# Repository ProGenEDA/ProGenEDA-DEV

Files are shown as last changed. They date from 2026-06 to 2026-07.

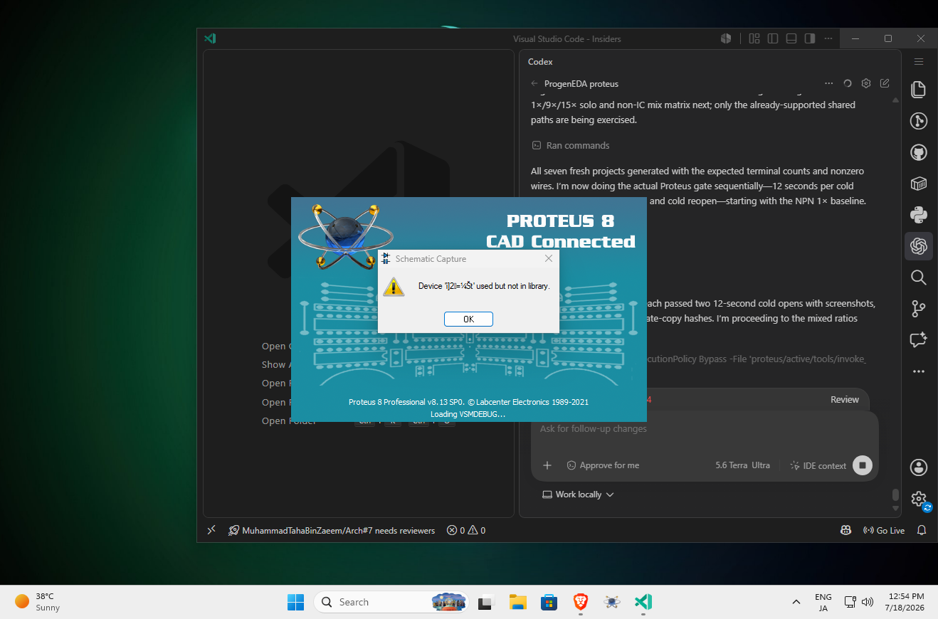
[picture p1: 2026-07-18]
proteus/experiments/runs/2026-07-18_npn_terminal_promotion_matrix/M02_NPN_NATIVE_ASYMMETRIC/screenshots/M02_NPN_NATIVE_ASYMMETRIC_GATE_cold_open_1.png

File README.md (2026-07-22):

# ProGenEDA

ProGenEDA is a development repository for deterministic, donor-aware EDA
generation. A backend receives one canonical circuit JSON document, resolves
only supported native records, produces an editable project, and retains
machine-readable validation evidence beside the result.

This repository contains independent backends for Proteus, KiCad, EasyEDA Pro,
and LTspice. They share the canonical circuit intent but do not depend on one
another at runtime.

## Backends

| Backend | Native output | Current entry point | Scope summary |
| --- | --- | --- | --- |
| Proteus | `.pdsprj` | [`proteus/active/`](proteus/active/) | Donor-backed placement, bounded terminal attachment, value editing, and local loader evidence. |
| KiCad | `.kicad_pro`, `.kicad_sch`, optional `.kicad_pcb` | [`kicad/`](kicad/) | Canonical JSON repair, source-backed schematic generation, combination routing, validation, and bounded two-layer PCB output. |
| EasyEDA Pro | `.eprj` | [`Easyeda/`](Easyeda/) | Native SQLite project generation using audited source records, compact schematic routing, and bounded PCB generation. |
| Altium | `.PrjPcb` + source-backed `.SchDoc`, packaged as ZIP | [`Altium/`](Altium/) | Full direct native schematic pipeline: repair, values, source selection, placement, arrangement, wiring/terminals, native emission, and saved-file validation. Direct PCB output is not qualified yet. |
| LTspice | `.asc` | [`ltspice/`](ltspice/) | Donor-native stock-symbol placement, physical-wire routing, and validated ASC emission. |

Each backend documents its supported catalogue, input restrictions, validation
contract, and release evidence in its own README. A backend must reject or
withhold unsupported work rather than substitute an approximate native record.

## Shared Generation Model

```text
Canonical circuit JSON
  -> normalize and validate input
  -> resolve supported components and pins
  -> place and arrange components
  -> route wires, terminals, or both according to backend policy
  -> edit approved values and references
  -> validate structure, pins, nets, geometry, and backend-specific rules
  -> emit native project plus internal audit artifacts
```

The canonical input remains the source of truth. Generation stages retain their
own reports and accepted or rejected layout/routing variants so a released
project can be traced back to the exact request and decisions that produced it.

## Getting Started

Run backend commands from the repository root. The portable executables are
the normal distribution form; direct source commands use the same pipeline.

### KiCad

```bash
unzip kicad/release/progen-kicad-portable-2026_07_17_kq26_clearance_v1.zip
./progen-kicad-portable/progen-kicad run INPUT.json \
  --output-root /tmp/progen-kicad-runs \
  --routing-mode combination
```

For PCB-only output from the same canonical input:

```bash
./progen-kicad-portable/progen-kicad run-pcb INPUT.json \
  --output-root /tmp/progen-kicad-pcb-runs \
  --routing-mode combination
```

Direct source entry point:

```bash
PYTHONPATH=. python -m kicad.pipeline.progen_kicad_executable run INPUT.json \
  --output-root /tmp/progen-kicad-runs \
  --routing-mode combination
```

See [`kicad/README.md`](kicad/README.md) for the supported input and
[`kicad/pcb/README.md`](kicad/pcb/README.md) for the physical-board boundary.

### EasyEDA Pro

```bash
Easyeda/dist/progen-easyeda run INPUT.json \
  --output-root /tmp/progen-easyeda-runs \
  --routing-mode combination \
  --events ndjson
```

Direct source entry point:

```bash
PYTHONPATH=. python -m Easyeda.executable run INPUT.json \
  --output-root /tmp/progen-easyeda-runs \
  --routing-mode combination \
  --events ndjson
```

See [`Easyeda/README.md`](Easyeda/README.md) and
[`Easyeda/SUPPORTED_COMPONENTS.md`](Easyeda/SUPPORTED_COMPONENTS.md).

### LTspice

```bash
PYTHONPATH=. python -m ltspice INPUT.json \
  --outdir /tmp/progen-ltspice-output \
  --label generated-circuit \
  --engine donor_native
```

The result is a native `.asc` file. The generator and deterministic validators
do not require LTspice to be installed; opening or simulating the output does.
See [`ltspice/README.md`](ltspice/README.md) for the donor-observed support
boundary and packaging instructions.

### Proteus

```powershell
.\proteus\active\release\ProgenProteus.exe generate `
  .\proteus\active\examples\progen_proteus_r_c_value_edit.json `
  --output .\out\r_c_terminalized.pdsprj
```

Direct source entry point:

```powershell
$env:PYTHONPATH = "proteus/active/src"
python -m proteusgen.proteus_cli generate `
  proteus/active/examples/progen_proteus_r_c_value_edit.json `
  --output out/r_c_terminalized.pdsprj
```

See [`proteus/active/README.md`](proteus/active/README.md) for the donor
policy, current terminal boundary, and native loader gate.

## Validation Principles

Every backend owns a deterministic validation path. Depending on the backend,
that includes component/reference checks, pin existence, expected-net
comparison, geometry and clearance checks, source-record provenance, native
file parsing, and optional application/CLI acceptance evidence.

Native application checks are additional evidence, not a substitute for the
backend's own structural validation. Conversely, static validation does not
promote a project that has not satisfied the backend's documented release
contract.

## Qualification Evidence

- KiCad: [`kicad/qualification/README.md`](kicad/qualification/README.md)
  documents the 400-circuit corpus and the bounded PCB results.
- EasyEDA Pro: [`Easyeda/qualification/README.md`](Easyeda/qualification/README.md)
  documents the 300-circuit full-pin corpus.
- LTspice: [`ltspice/docs/COMMON_CIRCUIT_CORPUS.md`](ltspice/docs/COMMON_CIRCUIT_CORPUS.md)
  describes the named native-circuit corpus.
- Proteus: [`proteus/active/examples/proteus_200_circuits/README.md`](proteus/active/examples/proteus_200_circuits/README.md)
  documents the executable-oriented corpus and evidence boundary.

## Repository Map

```text
proteus/    native Proteus backend, active package, donor evidence, experiments
kicad/      KiCad schematic and PCB generator, source pack, qualification, release
Easyeda/    independent EasyEDA Pro backend, audited donor bundle, qualification
Altium/     direct native Altium schematic generator, source pack, validators, research bridge
ltspice/    donor-native LTspice backend, catalogues, pipeline, packaging, tests
pspice/     PSpice/OrCAD research and early generator material
showcase/   curated generated projects for review
tests/      repository-level regression checks
```

Historical experiment folders are preserved as evidence. New generation runs
should create a new run directory and never overwrite prior outputs.

## Documentation Index

- [`kicad/FINALIZATION_STATUS.md`](kicad/FINALIZATION_STATUS.md) - KiCad
  status and release boundary.
- [`kicad/pipeline/MAIN_INPUT_JSON_CONTRACT.md`](kicad/pipeline/MAIN_INPUT_JSON_CONTRACT.md)
  - canonical KiCad input contract.
- [`Easyeda/INPUT_JSON.md`](Easyeda/INPUT_JSON.md) - EasyEDA input contract.
- [`Easyeda/ARCHITECTURE.md`](Easyeda/ARCHITECTURE.md) - EasyEDA stage design.
- [`Altium/README.md`](Altium/README.md) - Altium target status and commands.
- [`Altium/PIPELINE.md`](Altium/PIPELINE.md) - Altium stage contracts and immutable run artifacts.
- [`Altium/ARCHITECTURE.md`](Altium/ARCHITECTURE.md) - Altium stage contracts.
- [`Altium/INPUT_JSON.md`](Altium/INPUT_JSON.md) - Altium direct input contract.
- [`ltspice/ARCHITECTURE.md`](ltspice/ARCHITECTURE.md) - LTspice donor-native
  architecture and support evidence.
- [`proteus/active/docs/README.md`](proteus/active/docs/README.md) - Proteus
  operational documentation index.

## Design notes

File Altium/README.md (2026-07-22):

# ProGenEDA Altium Backend

`Altium/` is an independent, direct Altium schematic backend. Its production
path starts with canonical circuit JSON and writes a fresh native ASCII
`.SchDoc`, a `.PrjPcb` descriptor, and a ZIP containing those files. It does
not generate an EasyEDA project and does not invoke a converter during normal
generation.

```text
canonical JSON
  -> input fixer and value editor
  -> audited source selection and component placement
  -> four-candidate route-informed arrangement and coordinate-only beautifier
  -> wire planner and terminal placer
  -> routing validator and independent native wire maker
  -> direct .SchDoc writer and donor-backed .PrjPcb writer
  -> saved-file/package final validation
  -> ZIP project artifact plus private stage archive
```

## Direct Generation

Run from the repository root:

```bash
# Inspect the exact source-backed component catalogue.
PYTHONPATH=. python -m Altium.executable supported-components

# Repair, normalize, and source-validate a canonical circuit JSON file.
PYTHONPATH=. python -m Altium.executable validate-input INPUT.json

# Inspect every explicit pipeline stage and its ownership boundary.
PYTHONPATH=. python -m Altium.executable pipeline-contracts

# Directly generate an Altium project. This never creates an .eprj.
PYTHONPATH=. python -m Altium.executable generate INPUT.json \
  --output-root /tmp/progen-altium-runs --progress-json

# Re-check an emitted schematic and its project ZIP without Altium Designer.
PYTHONPATH=. python -m Altium.executable validate-schematic \
  RUN/project/Schematic/project.SchDoc \
  --expected RUN/internal/expected_physical_contract.json
PYTHONPATH=. python -m Altium.executable validate-package RUN/project.zip
```

Every generation creates a new run directory. It contains the user-facing
project folder and ZIP, plus `internal/` records for the normalized input,
source hashes, value edits, source selection, placement, all arrangement trials,
beautifier output, wire plan, terminal plan, routing validation, PCB decision,
expected physical contract, and saved-file validation report. A separate
private internal ZIP preserves the whole stage history.

The same code is also available as a Python API:

```python
from Altium.direct_generator import generate_direct_project

result = generate_direct_project("circuit.json", output_root="/tmp/progen-altium-runs")
assert result.validation.passed
print(result.project_file)
```

## Current Direct Schematic Scope

The initial catalogue is real-source backed, not hand-drawn. It clones complete
component records and derives pin locations, pin directions, source pin names,
wire records, and net-label records from the locked native seed. Current
families are:

- resistor, capacitor, LED, switch;
- two-pin header and 2x5 header;
- 74HC00, 74HC04, 74HC08, 74HC32, 74HC74; and
- NE555.

See [SUPPORTED_COMPONENTS.md](SUPPORTED_COMPONENTS.md) for the exact aliases,
native library references, and pin boundary. See [INPUT_JSON.md](INPUT_JSON.md)
for the required JSON contract.

The router has three explicit modes:

- `wire`: all requested nets must be physically routed; an unresolved net is a
  hard error.
- `terminal`: every non-`NC_*` net uses source-backed Altium net labels with a
  short physical pin stem.
- `combination`: route physically where clear; only whole unresolved nets fall
  back to source-backed labels. This is the default.

The current direct examples are intentionally small and auditable:

```bash
PYTHONPATH=. python -m Altium.executable generate Altium/examples/direct_rc_filter.json \
  --output-root /tmp/progen-altium-runs
PYTHONPATH=. python -m Altium.executable generate Altium/examples/direct_led_indicator.json \
  --output-root /tmp/progen-altium-runs
PYTHONPATH=. python -m Altium.executable generate Altium/examples/direct_74hc04_breakout.json \
  --output-root /tmp/progen-altium-runs
```

## Validation

The direct validator re-parses the saved `.SchDoc`; it does not accept the
generator's in-memory route plan as proof. It checks:

1. native ASCII header and record count;
2. expected references, values, source library identities, root coordinates,
   complete symbol bounds, and native pin names/directions/positions;
3. dynamic sheet dimensions containing every body, pin, route, and label;
4. component overlap and wire-to-component-body clearance;
5. globally unique wire/label record indexes and orthogonal segments;
6. exact wire-maker/terminal geometry with no duplicate native component or
   pin/property records;
7. physical wire graph connectivity for fully wired nets;
8. native label attachment and logical connectivity for terminalized nets;
9. expected-net separation so a route or label cannot silently short nets; and
10. donor-native `.PrjPcb` sections, document declarations, ZIP inventory, safe
   paths, and exact hash equality with the files that were validated.

`Altium/tests/` contains focused pytest regressions, including deliberate
mutations of values, library references, pin identity, sheet size, routing
indexes, and archive payloads. A repository-local `.venv` may be used when the
host Python does not already provide pytest.

With `--progress-json`, the executable emits one ordered event for every one
of the 22 retained stages, followed by a `complete` event at 100 percent.

## Encoder/Decoder Research Boundary

The installed EasyEDA Chameleon bundle advertises `altium` decoder and encoder
types. `probe-engine` and `research-bridge` retain that capability for format
research only. They are not called by `generate`.

An actual raw-ASCII `.SchDoc` round-trip through that bundle was lossy: the
re-encoded archive preserved wire records but dropped the direct component
records and did not emit a `.PrjPcb`. It is therefore explicitly not an
acceptance gate for this writer. The acceptance hierarchy is the independent
saved-file validator now, followed by an Altium Designer open/render test when
the desktop installation is complete.

## Current Boundary and Next Work

This is direct **schematic** generation. It does not yet emit a direct
`.PcbDoc`, Gerbers, or manufacturing files. The source seed includes component
footprint associations, but direct board construction needs separate
Altium-native board, pad, stackup, rule, and routing donor evidence before it
can be qualified.

Likewise, a static parser is not a desktop-open result. The Altium Designer
download in this environment is incomplete at the time of writing, so desktop
open/render/compile evidence remains a required next gate. Unsupported
families, unqualified PCB output, and unresolved strict-wire routes fail
clearly rather than being approximated.

See [PIPELINE.md](PIPELINE.md), [ARCHITECTURE.md](ARCHITECTURE.md),
[SUPPORTED_COMPONENTS.md](SUPPORTED_COMPONENTS.md), and
[source_pack/README.md](source_pack/README.md) for the implementation and
evidence details.

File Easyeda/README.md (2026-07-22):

# ProGenEDA EasyEDA Pro Backend

This independent backend compiles canonical circuit JSON into one native
EasyEDA Pro `.eprj` SQLite project. It does not import from `kicad/` at
runtime.

The backend is donor-native: symbols, devices, footprints, pads, power
terminals, and net-port payloads are resolved from audited EasyEDA source
records. The portable generator contains only the compact locked record bundle
needed by the supported catalogue. It does not package the EasyEDA desktop
application or its complete library.

## What It Produces

For a supported request, the pipeline emits:

- one editable native `<project-name>.eprj` project;
- a schematic using source-resolved components, wires, terminals, and net
  ports according to the chosen routing mode;
- a bounded two-layer PCB in the same project when all used devices have exact
  footprint/pad mappings and physical validation passes; and
- an internal ZIP containing normalized input, fixer report, placement,
  routing, donor provenance, PCB decisions and variants, and validation
  reports.

The primary user artifact is the `.eprj` project. Internal records are kept for
audit and regeneration rather than mixed into the user-facing project folder.

## Run The Portable Executable

```bash
Easyeda/dist/progen-easyeda run INPUT.json \
  --output-root /tmp/progen-easyeda-runs \
  --routing-mode combination \
  --events ndjson
```

The portable executable is the normal distribution artifact. It can generate
and run deterministic validation without an installed EasyEDA application.

## Run From Source

```bash
PYTHONPATH=. python -m Easyeda.executable run \
  Easyeda/examples/regulated_5v_supply.json \
  --output-root /tmp/progen-easyeda-runs \
  --routing-mode combination
```

An authorized source installation can be supplied with `--source-pack` as a
development-time override.

Useful deterministic commands:

```bash
# Report and repair common input problems without generating a project.
Easyeda/dist/progen-easyeda validate-input circuit.json
Easyeda/dist/progen-easyeda fix-input circuit.json --output fixed.json

# Discover fields exposed by the normal reference/value editor.
Easyeda/dist/progen-easyeda editable circuit.json

# Apply validated JSON edits and emit normalized JSON.
Easyeda/dist/progen-easyeda edit circuit.json edits.json --output edited.json

# Stream completed pipeline stages for a worker or website adapter.
Easyeda/dist/progen-easyeda run circuit.json --output-root runs --events ndjson
```

## Routing And PCB Contract

- The locked catalogue contains 59 logical entries backed by 57 physical donor
  families, plus native `GND` and `VCC` terminal families.
- A schematic request may contain at most 80 component instances.
- `wire`, `terminal`, and `combination` modes are supported; `combination` is
  the default.
- Combination mode uses explicit native terminals for power/ground, selected
  high-fanout nets, and failed wire routes. Strict wire mode fails rather than
  silently terminalizing a net.
- Distinct nets may cross at a point but may not share a positive-length wire
  span. The planner and native validator enforce this readability constraint.
- PCB output is bounded to 32 physical components. `GND` and `VCC` schematic
  terminals do not count as physical PCB components.
- A PCB failure never invalidates an otherwise valid schematic. The project is
  emitted without a board document and the PCB report records the reason.

## Validation And Acceptance

The native validator checks source-record hashes, components, pins, expected
nets, geometry, wire-span overlap, footprint/pad mapping, and board-level
connectivity. Input repair is deterministic: a guessed or completed net is
named `GUESS_*`, terminalized, and reported. A clean canonical input produces
zero guesses and zero repairs.

Static validation is necessary but not desktop acceptance. Release evidence
also opens a disposable copy of each selected project through the installed
EasyEDA Pro file association and confirms that the audited original was not
rewritten. Generated projects carry a native EasyEDA 3.x identity and omit
legacy history/cache rows that trigger conversion failures.

## Evidence And Documentation

- [Input JSON contract](INPUT_JSON.md)
- [Supported components](SUPPORTED_COMPONENTS.md)
- [Architecture](ARCHITECTURE.md)
- [300-circuit qualification](qualification/README.md)
- [Qualification results](qualification/RESULTS_2026_07_17.md)
- [Website handoff](release/newwebsite_easyeda_handoff_2026_07_17/README.md)

The release handoff contains the portable executable, named qualification
inputs, website integration material, installer guidance, and release
evidence. Historical experiments remain in `experiments/` and are not runtime
dependencies.

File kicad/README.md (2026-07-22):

# ProGenEDA KiCad Backend

This is the active source-backed KiCad backend. It compiles canonical circuit
JSON into an editable `.kicad_pro` project with a native `.kicad_sch` and, when
the physical contract is satisfied, a native two-layer `.kicad_pcb`.

The generator is independent from the Proteus binary backend. It resolves
symbols, pins, bodies, footprints, and pads from the bundled KiCad source pack
and retains the evidence needed to validate output without requiring KiCad at
generation time.

## Run The Portable Executable

```bash
unzip release/progen-kicad-portable-2026_07_17_kq26_clearance_v1.zip
./progen-kicad-portable/progen-kicad run INPUT.json \
  --output-root /tmp/progen-kicad-runs \
  --routing-mode combination
```

Create a PCB-only artifact from the same canonical input:

```bash
./progen-kicad-portable/progen-kicad run-pcb INPUT.json \
  --output-root /tmp/progen-kicad-pcb-runs \
  --routing-mode combination
```

Generate retained layout/routing variants:

```bash
./progen-kicad-portable/progen-kicad run-variations INPUT.json \
  --output-root /tmp/progen-kicad-variations \
  --routing-mode combination \
  --variations 3
```

## Run From Source

```bash
PYTHONPATH=. python -m kicad.pipeline.progen_kicad_executable run INPUT.json \
  --output-root /tmp/progen-kicad-runs \
  --routing-mode combination
```

The portable executable wraps this committed source entry point. Direct source
generation and deterministic validation do not require a local KiCad install.

## Generation Contract

```text
Canonical circuit JSON
  -> deterministic input fixer and validator
  -> source-backed component and pin resolution
  -> component placement, arrangement selection, and coordinate beautification
  -> wire planner, terminal placer, or combination policy
  -> native schematic writer and value editor
  -> expected-net, geometry, clearance, and final validation
  -> optional physical-board compiler, router, and validator
  -> native project plus internal audit bundle
```

`combination` is the production default. Local nets are physically wired;
power, high-fanout, and bounded-route fallback nets use explicit KiCad terminal
objects. Strict `wire` mode never hides a routing failure behind labels or
terminals.

The formal input contract is
[`pipeline/MAIN_INPUT_JSON_CONTRACT.md`](pipeline/MAIN_INPUT_JSON_CONTRACT.md).
The deterministic fixer accepts common shape and naming mistakes, reports each
repair, and marks invented connectivity as `GUESS_TERMINAL_*` so it is explicit
and terminalized rather than presented as a verified physical wire.

## Schematic Validation

The generated schematic is checked without the KiCad CLI through the bundled
source-backed parser and catalogue. Validation covers file structure,
components, references, values, pins, expected nets, actual wire/junction/pin
connectivity, component-body clearance, label/terminal placement, and output
artifacts.

When KiCad is installed, `kicad-cli` netlist export and ERC are supplemental
acceptance checks. They do not replace exact expected-net comparison, because
ERC cannot know whether a logical signal reached the intended pin.

## Bounded PCB Output

PCB generation consumes the same fixed canonical JSON and resolved schematic
pin contract; it does not accept a separate PCB input. A board is emitted only
when every used logical pin maps to a real source footprint pad and the bounded
two-layer placement/routing/physical validator succeeds.

The common-400 qualification accepted 311 boards and explicitly withheld 89
schematic projects whose footprint, complexity, or routing contract was not
satisfied. Withholding is intentional: a valid schematic is still delivered,
but an unaudited PCB is never claimed as usable.

See [`pcb/README.md`](pcb/README.md) for footprint provenance, pad mapping,
route variants, DRC evidence, and the exact physical acceptance rules.

## Qualification And Variants

The qualification corpus contains 400 ordinary canonical inputs across 40
electrical archetypes and 10 named profiles. It exercises the real fixer,
placer, arrangement logic, router, terminal policy, value editor, validators,
packager, and bounded PCB stage without guided coordinates.

- [Qualification corpus and runner](qualification/README.md)
- [Qualification results](qualification/RESULTS_2026_07_17.md)
- [Finalization status](FINALIZATION_STATUS.md)
- [Supported component catalogue](pipeline/SUPPORTED_COMPONENTS.md)

Each run keeps normalized input, generated stage JSON, accepted and rejected
variants, reports, and output manifests in a new run directory. Prior evidence
is immutable and must not be overwritten.

## Local KiCad Tools

The optional local KiCad 10.0.4 helper and CLI wrapper are documented in
[`tools/README.md`](tools/README.md). They are for opening projects, rendering
review copies, and running external KiCad acceptance checks; they are not a
runtime dependency of the generator.

## Repository Map

```text
pipeline/        canonical JSON, placement, routing, validation, packaging
pcb/             physical compiler, footprint placement, router, PCB parser
qualification/   locked corpus, runner, and release results
source_pack/     source records used by no-installation validation
release/         portable executable and website handoff artifacts
examples/        immutable generated evidence runs
experiment_records/ historical placement and routing research
```

Historical files remain available for audit, but current work should begin
with the executable, input contract, support catalogue, and qualification
records linked above.

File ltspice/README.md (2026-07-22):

# ProGenEDA LTspice Backend

This directory is being rebuilt to generate real LTspice ASC schematics: files
that use the installed LTspice stock symbols and open as though they had been
drawn in LTspice itself. The design authority is the donor corpus in
`/home/zaruka/Documents/Ltspice/Donor`, not a generic SPICE abstraction.

The user-facing input remains the shared canonical `progen-kicad-circuit-ir/v1`
circuit JSON used by KiCad. LTspice does not get a second user-authored input
format. The native backend resolves that JSON to the donor-backed catalogue,
places native symbols, edits only approved native attributes, routes every
electrical net with physical wires, then emits the ASC file.

## Current executable scope — 2026-07-16

The canonical repository folder is **`ltspice/`** (lowercase by design). It is
already present on `main`; a second `Ltspice/` case-variant directory would be
an error-prone duplicate on Linux and is intentionally not created.

The current donor-native executable accepts this deliberately bounded,
evidence-backed scope:

- Native stock families: ground, resistor, capacitor, inductor, voltage
  source, current source, and `Misc\\signal` source.
- Total logical-component limit: **43**, including logical grounds.
- Connectivity: direct physical `WIRE` records only. Named-terminal,
  custom-symbol, and project-local-model fallbacks are rejected by the active
  path.
- Guided JSON editing: references, passive values, catalogue-approved
  parameters, and bounded V/I source modes. Demo/admin advanced editing
  changes canonical JSON, never raw ASC, then follows deterministic validation
  and regeneration.
- Timing: stage events come from the executable; an opted-in client gets an
  overdue notice at 1× its animation budget and a no-download failure at 2×.
- Website handoff: the Linux x86_64/NixOS executable, integration sources,
  deployment notes, and 100 named canonical JSON circuits are packaged in
  `/home/zaruka/Documents/Ltspice/PROGENEDA_LTSPICE_WEBSITE_HANDOFF_2026_07_16.zip`.

The 100 named common circuits were generated through the ordinary generator,
and the website replay accepted **100/100** inputs. The Python native suite
has **106 passing tests** with one optional installed-oracle test skipped by
default. The separate installed LTspice desktop application remains necessary
to open or simulate `.asc` files; it is not bundled here. Catalogue evidence
states and the remaining per-family GUI promotion gaps below remain the final
authority for release claims.

## Important status boundary

The older code in `pipeline/` was a useful prototype, but it is **not** the
donor-native generation path. In particular, it can write progeneda_*.asy,
progeneda_v1_models.lib, project-local approximations, and named
FLAG/terminal fallbacks. Those are not hand-made LTspice replica files and
must not be presented as such or used as the basis for new native features.

Until a fixture is emitted by the donor-native writer, opened in the installed
LTspice GUI, screenshot-checked, and recorded in the catalogue, it is not a
release-ready native result. The default python -m ltspice command now selects
the donor-native engine. Use --engine legacy_prototype only for historical
regression investigation; it must not be used to claim donor-native output.

`donor_observed` is deliberately not the same thing as `supported`: it means
that the donor parser has evidence for the native record, stock symbol, and
pin geometry. A family becomes supported only after its generated count,
property, mixed-wire, GUI, and (where applicable) netlist checks have been
recorded. The present generator can emit bounded **candidate** ASC files for
the donor-observed families; the required per-family acceptance matrix is
tracked in [the support-gap register](docs/SUPPORT_GAPS.md).

## Non-negotiable output rules

- Use only donor-proven installed stock symbols such as `res`, `cap`, `ind`,
  `voltage`, `current`, and `Misc\\signal`; add another symbol only after it has
  donor and installed-library evidence.
- Every non-ground electrical connection is a direct physical WIRE path.
  No named-net labels, virtual anchors, synthetic terminals, or hidden
  connectivity substitutes are permitted.
- FLAG x y 0 is allowed only for a real ground anchor. It never replaces a
  normal wire or an arbitrary terminal label.
- A wire may intentionally join another wire on its own net, but it must not
  touch a component body or a pin belonging to another net. LTspice 26
  netlisting has verified that a horizontal and vertical WIRE may cross at
  the strict interior of both segments without becoming a junction. A T,
  endpoint touch, or collinear overlap across different nets remains a hard
  error. Native LTspice permits straight diagonal WIRE records too; the
  initial beautifier prefers orthogonal runs without rejecting donor-proven
  diagonals.
- Do not package custom .asy symbols or a generated model library merely to
  make a file render. Do not turn an unproven property into a made-up
  SpiceLine field.
- Native ASC coordinates use the observed 16-unit grid and may be negative.
  Native values requiring the micro symbol retain donor-compatible CP1252
  output rather than being silently changed into a custom attribute.

## The donor-first build order

1. **Learn placement one family at a time.** Parse the donors, record stock
   symbol syntax, exact pin offsets, body geometry, orientations, and observed
   count patterns. Generate and GUI-check count fixtures for 1, 2, 3, 5, 10,
   and 20 instances of each family.
2. **Learn combinations progressively.** Once two families pass on their
   own, generate physically wired mixes. Keep increasing supported families
   while holding the complete canonical circuit to a maximum of **43 logical
   components**. A logical `GND` counts toward that cap even though native ASC
   writes it as `FLAG x y 0`, not a `SYMBOL`; the test matrix naturally gives
   each family fewer instances as more families are included.
3. **Learn native property editing.** For each placed family, vary only
   donor-proven SYMATTR/WINDOW records and whitelisted SpiceLine keys, plus a
   separately labelled installed-help/executable source field where the
   catalogue records that stronger-but-not-donor evidence. Record syntax,
   accepted value grammar, effect, evidence, and GUI result in the catalogue.
   Unknown properties are rejected, not guessed.
4. **Route wires only.** Adapt the KiCad Python planner, geometry validator,
   live-routing-state, arrangement, and beautifier logic to LTspice stock pin
   anchors. Every canonical net must become one physically connected wire
   tree. A collision, unconnected pin, foreign-pin touch, or partial route is
   a hard failure.
5. **Beautify without changing topology.** Move/rotate components only to
   improve readability, spacing, and wire length; then revalidate the exact
   physical connectivity and all body clearances.
6. **Verify in the actual application.** Open the generated ASC through the
   installed LTspice desktop association, capture the LTspice schematic
   window, inspect the screenshot for native symbols/wires/errors, and run
   netlisting or batch analysis when the fixture has an analysis directive.

The 43-component ceiling is a development and verification limit, not a claim
that every arbitrary LTspice component is already supported.

## Run the active generator

From the repository root:

    PYTHONPATH=. python -m ltspice kicad/examples/rc_lowpass.json --outdir ltspice/examples --label native_rc

The default engine writes one stock-library ASC, an internal live-catalogue
snapshot, and a user ZIP containing only the ASC and open-in-LTspice note.
It rejects terminal/label routing modes, custom symbols, generated model
libraries, unregistered components, unproved properties, foreign-pin contact,
and incomplete physical nets.

This command performs deterministic generation and static physical-wire
validation. Opening the result in the LTspice desktop application and
capturing/assessing its screenshot is the separate acceptance workflow below;
it is not yet an automatic per-invocation release gate.

## Generation progress and timing policy

The native engine emits real started/completed/failed events for its eight
deterministic stages: canonicalize input, resolve donor catalogue, place stock
symbols, beautify layout, route physical wires, write ASC, validate ASC, and
package artifacts. A client may opt into the animation watchdog by providing
its own duration:

    PYTHONPATH=. python -m ltspice INPUT.json --animation-budget-seconds 20 --events ndjson

There is no inferred default duration. With an explicit budget, the watchdog
emits a `timing` event at **1×** with “Taking longer than expected—please hold
on.” The download stays hidden while the generator continues. At **2×**, it
emits the deterministic failure “Generation took longer than allowed time.
Please try a simpler circuit.”, records timing evidence, and suppresses or
retracts the user ZIP/output manifest. Artifact release is approved only after
the package stage completes within the hard deadline, so the UI must never show
an empty or premature download box.

Use the historical prototype only when deliberately investigating its old
artifacts:

    PYTHONPATH=. python -m ltspice INPUT.json --engine legacy_prototype

## Authoritative records

- [Donor-native architecture](ARCHITECTURE.md) defines evidence levels,
  pipeline boundaries, routing invariants, and GUI acceptance criteria.
- [Permanent native main catalogue](catalogues/ltspice_main_catalogue.json)
  is the machine-readable authority for every observed component, exact stock
  pin anchor, legal orientation, and editable native property.
- [Catalogue schema](catalogues/ltspice_main_catalogue.schema.json) and its
  [strict loader](catalogues/ltspice_main_catalogue_loader.py) prevent a
  generic fallback from inventing a symbol or property.
- [Support gaps and donor requests](docs/SUPPORT_GAPS.md) records what has
  been observed, what still needs generated/GUI proof, and which donor files
  would unblock each gap.
- [Independent source-property research](docs/SOURCE_PROPERTY_RESEARCH.md)
  records the bounded V/I source modes learned from the installed LTspice 26
  help and checked by LTspice itself.  They are explicitly distinguished from
  donor-proven fields.
- [The 100-circuit corpus](docs/COMMON_CIRCUIT_CORPUS.md) and its
  [ordinary-generator bundle workflow](docs/COMMON_CIRCUIT_BUNDLE.md) provide
  named, canonical R/C/L/source examples without a second input format or
  manually supplied LTspice coordinates.
- [The bounded top-10 GUI review](docs/COMMON_CIRCUIT_GUI_REVIEW.md) records
  the exact-window screenshots, the rail/ground repairs they drove, and the
  remaining dense-topology styling boundary.
- [Native GUI verification evidence](docs/NATIVE_GUI_VERIFICATION.md) records
  the local all-family mixed smoke test separately from full support promotion.
- [Historical donor coverage](docs/LTSPICE_DONOR_COVERAGE.md) and
  [old oracle record](docs/LTSPICE_26_ORACLE_VALIDATION.md) retain useful
  investigation evidence from the prototype. They do not upgrade a
  project-local-symbol or terminal-based result to donor-native status.

## Current native evidence baseline

The catalogue currently records donor observations for resistor, capacitor,
inductor, voltage source, current source, `Misc\\signal`, and ground. This means
their native records have evidence; it does **not** mean the new placer,
property editor, wire router, and GUI fixture matrix have all passed yet.

Observed donor maxima are 11 resistors, 6 capacitors, 6 inductors, 2 voltage
sources, 2 current sources, and 1 `Misc\\signal` in a single donor. The
generator must extend these carefully through deterministic fixtures rather
than treating the old project-local model catalogue as support evidence.

One all-observed-family mixed source/R/C/L/current/`Misc\\signal` GUI smoke
fixture has been opened and netlisted in LTspice 26.0.2. Its exact scope and
local evidence paths are in [NATIVE_GUI_VERIFICATION.md](docs/NATIVE_GUI_VERIFICATION.md);
it is deliberately not counted as the full per-family matrix.

To repeat the desktop evidence capture through the registered double-click
association rather than improvising a shell command:

    PYTHONPATH=. python -m ltspice.pipeline.native_gui_verifier GENERATED.asc \
      --screenshot /tmp/ltspice-check.png --evidence /tmp/ltspice-check.json

The verifier performs the static native boundary check, opens the ASC with
`xdg-open`, captures the active window, and writes a review checklist. It
does not auto-promote a component: the screenshot still needs visual review.

To reproduce the bounded placement progression itself:

    PYTHONPATH=. python -m ltspice.pipeline.donor_native_fixture_matrix /tmp/ltspice-native-matrix
    PYTHONPATH=. python -m ltspice /tmp/ltspice-native-matrix --outdir ltspice/examples --label progression

That writes and generates the six 1/2/3/5/10/20 family progressions; it is
an evidence generator, not a substitute for GUI review of each output.

To build the named 100-circuit user bundle through the same ordinary generator
(not a separate ASC writer), choose a new directory **outside** this
repository:

    PYTHONPATH=. python -m ltspice.pipeline.common_circuit_bundle \
      /tmp/ltspice-common-circuit-bundle \
      --archive /tmp/ltspice-common-circuit-bundle.zip

Each title-named folder contains the untouched canonical `circuit.json`, the
ordinary-generator `.asc`, and `accuracy_check.txt`. The package refuses
manual placement hints, produces all direct wires through the active router,
and records the native static-validation facts and ASC hash for every circuit.

## Working with the canonical JSON

The canonical JSON keeps project, components, nets, expected_netlist, routing,
and layout_intent. The shared canonicalizer and the active donor-native adapter
both verify that `expected_netlist` matches the explicit `nets` endpoint
partition; the adapter then uses those nets as physical routing authority and
forces wire-only mode. Generic `at` layout intent is not treated as an ASC
coordinate; native `ltspice_at` is the explicit coordinate override. A
component not present in the native main catalogue, a property absent from its
approved native property list, or a net that cannot be physically routed is
rejected with a deterministic diagnostic.

Normal editing exposes only catalogue-approved and adapter-implemented fields,
such as a native reference, value, donor-proven passive/source parameter,
donor-proven source display window, or an explicitly labelled
installed-help/executable-verified V/I source mode. The root
`normal_editor.adapter_implemented_properties` map is the exact normal-mode
allow-list; any future donor-observed record remains unavailable until it is
added there with deterministic validation. Advanced raw ASC or JSON editing
belongs to the demo/admin surface and must pass the same catalogue, pin-anchor,
physical-wire, geometry, ASC parse, and LTspice GUI checks before it can be
released.

## Evidence workflow for contributors

1. Add or identify a donor that was created/opened in LTspice.
2. Parse it without normalizing away its native record ordering, CP1252 text,
   negative coordinates, or diagonal wires.
3. Update the main catalogue only with facts the donor and installed stock ASY
   support.
4. Add placement/property/mixed-wire fixtures within the 43-part cap.
5. Open each generated ASC in LTspice, save a screenshot and structured
   assessment, then mark the catalogue evidence as GUI-verified.
6. If a fact cannot be proven, add it to docs/SUPPORT_GAPS.md instead of
   encoding an approximation.

This makes the catalogue, tests, generated ASC files, and screenshots agree on
what the backend can genuinely produce.

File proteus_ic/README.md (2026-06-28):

# Proteus IC Generation Workspace

> Current project status is summarized in
> [`../docs/current_status_2026_06_29.md`](../docs/current_status_2026_06_29.md).
> This file also preserves the chronological IC experiment record below.

This folder is the IC learning and donor evidence area. Production
combinational IC generation is now enabled through the locked main CLI route
after the user accepted the HC04/all-seven pack in Proteus 8.13.

The newer unified component placer can also place the 22 IC package families
listed in `registry/mega_component_support_20260618.json` as bare donor-native
packets. That placement path is distinct from the locked directional
combinational generator. Its current terminal experiment uses bidirectional
side anchors for all families but does not yet emit the short wires required to
claim electrical pin attachment.

Current rules:

- IC circuits do not use DC voltage, DC current, AC voltage, or AC current
  sources.
- IC supply is hidden unless a donor proves otherwise.
- IC pins use ordinary `$TERINPUT` and `$TEROUTPUT` terminal records.
- Non-IC endpoints in mixed IC circuits follow the main generator policy:
  passive endpoints use donor-derived `$TERBIDIR`, but passive `G0` must keep
  the previously accepted donor `$TERGROUND` method after the V2
  bidirectional-G0 experiment failed for T29.
- Power and ground terminals are used only as logic HIGH/LOW node ties or
  passive supply/reference nodes, not package supply pins.

First targets:

- `74HC08` as the primary quad two-input gate family.
- `74HC32` as the first cross-family pattern check.
- `74HC00`, `74HC02`, `74HC86`, and `74HC266` as the next quad two-input
  combinational families.
- `74HC04` as the first hex unary inverter family. It uses six subparts
  `U1:A` through `U1:F` backed by the observed `74INV.MDF` model.

The first donor-learning pack is created by:

```text
python tools/proteus_generation/2026-06-07/generate_ic_hc08_hc32_v1_temp.py
```

The current expression packs are created by:

```text
python tools/proteus_generation/2026-06-08/generate_ic_hc08_logic_v1_temp.py
python tools/proteus_generation/2026-06-08/generate_ic_hc32_logic_v1_temp.py
python tools/proteus_generation/2026-06-08/generate_ic_and_or_rcl_v1_temp.py
python tools/proteus_generation/2026-06-08/generate_ic_and_or_rcl_v2_manual_donor_temp.py
python tools/proteus_generation/2026-06-08/generate_ic_and_or_rcl_v3_directional_ic_temp.py
python tools/proteus_generation/2026-06-08/generate_ic_remaining_combinational_v1_temp.py
python tools/proteus_generation/2026-06-08/generate_ic_remaining_generated_logic_v1_temp.py
python tools/proteus_generation/2026-06-08/generate_ic_final_30_combinational_v1_temp.py
python tools/proteus_generation/2026-06-08/generate_ic_final_last2_layout_ground_v2_temp.py
python tools/proteus_generation/2026-06-08/generate_ic_final_t29_legacy_ground_v3_temp.py
python tools/proteus_generation/2026-06-08/generate_ic_hc04_all7_v1_temp.py
python tools/proteus_generation/2026-06-09/generate_ic_sequential_counters_v1_temp.py
python tools/proteus_generation/2026-06-09/generate_ic_sequential_counters_v2_temp.py
python tools/proteus_generation/2026-06-10/generate_mixed_ic_cross_donor_accepted_v1_temp.py
python tools/proteus_generation/2026-06-10/generate_mixed_ic_cross_donor_accepted_v2_layout_temp.py
python tools/proteus_generation/2026-06-10/generate_mixed_ic_focused_v3_temp.py
python tools/proteus_generation/2026-06-10/generate_mixed_ic_focused_v4_temp.py
python tools/proteus_generation/2026-06-10/generate_mixed_ic_focused_v5_donor_native_temp.py
python tools/proteus_generation/2026-06-10/generate_mixed_ic_focused_v6_no4060_temp.py
python tools/proteus_generation/2026-06-10/generate_ic_exact_rezip_all_families_temp.py
python tools/proteus_generation/2026-06-10/generate_ic_pairwise_34_v1_temp.py
python tools/proteus_generation/2026-06-10/generate_ic_pairwise_34_v2_temp.py
python tools/proteus_generation/2026-06-10/generate_ic_pairwise_error_focused_v1_temp.py
python tools/proteus_generation/2026-06-11/generate_ic_pairwise_noncomb_master_metadata_v1_temp.py
```

Status:

- `IC_HC08_HC32_V1_TEMP_2026_06_07` passed user Proteus testing.
- `IC_HC08_REAL_V1_TEMP_2026_06_07` passed user Proteus testing for the five
  production-style HC08 user circuits.
- `IC_HC08_LOGIC_V1_TEMP_2026_06_08` passed user Proteus testing for the
  15-input AND expression mapped across four `74HC08` packages.
- `IC_HC32_LOGIC_V1_TEMP_2026_06_08` passed user Proteus testing for the
  15-input OR expression mapped across four `74HC32` packages.
- `IC_AND_OR_RCL_V1_TEMP_2026_06_08` was static-clean but failed user Proteus
  testing with an ISIS.dll violation. Do not promote its mixed ordinary-IC /
  bidirectional-passive terminal method.
- `IC_AND_OR_RCL_V2_MANUAL_DONOR_TEMP_2026_06_08` is static-clean and pending
  user Proteus testing. It first repacks the supplied manual donor, then tests
  a generated 15-gate mixed circuit using the donor-style all-bidirectional
  visible terminal family. User testing showed this works, but it is diagnostic
  only because IC pins must not be bidirectional.
- `IC_AND_OR_RCL_V3_DIRECTIONAL_IC_TEMP_2026_06_08` passed user Proteus
  testing and is the accepted mixed
  IC/passive test: IC signal pins are `$TERINPUT` / `$TEROUTPUT`; passive
  endpoints remain `$TERBIDIR`; same-name terminal labels connect across those
  terminal families.
- `IC_REMAINING_COMBINATIONAL_V1_TEMP_2026_06_08` passed user Proteus testing.
  It covers `74HC00`, `74HC02`, `74HC86`, and `74HC266` with all-four,
  label-only, two-package, logic-constant, RCL-load, and combined all-family
  diagnostics.
- `IC_REMAINING_GENERATED_LOGIC_V1_TEMP_2026_06_08` is static-clean and pending
  user Proteus testing. It is the first generated-object logic pack after the
  remaining combinational donor acceptance: compact NAND, NOR, XOR, and
  74HC266 XNOR-candidate chains generated from accepted all-four donor slices.
- `IC_FINAL_30_COMBINATIONAL_V1_TEMP_2026_06_08` passed user Proteus testing.
  It covers the 30 final combinational circuits supplied by the user across
  `74HC08`, `74HC32`, `74HC00`, `74HC02`, `74HC86`, and `74HC266`, including
  mixed-gate logic and R/C/L integration cases.
- `IC_FINAL_LAST2_LAYOUT_GROUND_V2_TEMP_2026_06_08` partially failed user
  Proteus testing. T30 worked, but T29 failed after passive `G0` was converted
  to `$TERBIDIR`; do not promote bidirectional passive `G0`.
- `IC_FINAL_T29_LEGACY_GROUND_V3_TEMP_2026_06_08` passed user Proteus testing.
  It locks compact small-circuit placement only when passive `G0` stays on the
  previous donor `$TERGROUND` method.
- `IC_PAIRWISE_34_V1_TEMP_2026_06_10` is rejected as a promotion candidate
  after user testing. It exposed repeatable duplicate part reference failures,
  `7447`/`74HC47` no-model failures in pairings, and refreshed 4060 long-wire
  coordinate artifacts.
- `IC_PAIRWISE_34_V2_TEMP_2026_06_10` is rejected by user Proteus testing; do
  not continue from it. Pairs that opened still had the same simulation errors,
  cases that previously only had simulation errors started crashing, and
  refreshed 4060 coordinate-only pairs also crashed.
- `IC_PAIRWISE_ERROR_FOCUSED_V1_TEMP_2026_06_10` passed user Proteus testing
  for the focused `S01+S02` repair. It does not touch V1 working pairs. Its
  first case regenerates failed `S01+S02` through the accepted combinational
  gate-slice generator instead of whole-donor `U2` copy/paste.
- `IC_PAIRWISE_ERROR_FIXED_V2_TEMP_2026_06_10` expands the accepted `S01+S02`
  repair to the V1-reported rejected pairs that include at least one accepted
  combinational source. It emits 65 repaired cases and defers 44
  non-combinational-only or coordinate-only cases. User Proteus testing on
  2026-06-11 confirmed all 65 generated projects worked.
- `IC_PAIRWISE_COMBINATIONAL_METHOD_V1_TEMP_2026_06_11` applies that accepted
  method to all 210 unordered pairs that include at least one accepted
  combinational source. It also includes 21 non-combinational-only probe cases
  using collision-only CDB ID patching. Static validation is clean; Proteus
  testing is pending.
- `IC_PAIRWISE_NONCOMB_MASTER_METADATA_V1_TEMP_2026_06_11` is a focused retry
  for failed sequential/non-combinational pair probes. It uses selected
  component records from the Proteus-created `alot_of_ics` master donor while
  copying the complete master `ROOT.CDB` and device section unchanged. This is
  a metadata/opening diagnostic only because the master donor records are bare
  and do not include bider terminal regions. Static validation is clean;
  Proteus testing is pending.
- `IC_HC04_ALL7_V1_TEMP_2026_06_08` passed user Proteus testing. It imports
  `74HC04`, generates one NOT gate, all six inverter subparts, logic-constant
  NOT gates, a NOT/RCL load, and the final all-seven combinational family
  circuit.
- `IC_SEQUENTIAL_COUNTERS_V1_TEMP_2026_06_09` is static-clean and pending user
  Proteus testing. It is a separate sequential/counter-only experiment for
  `7490`/user-facing `74HC90`, `74HC160`, `74HC161`, and `74HC163`. Unlike the
  locked combinational route, every visible sequential counter pin uses
  donor-native `$TERBIDIR` terminals. Pin 14 is a real counter signal in this
  donor set, not hidden supply.
- `IC_SEQUENTIAL_COUNTERS_V2_TEMP_2026_06_09` is static-clean and pending user
  Proteus testing. It extends the same sequential-only method to `74HC192`,
  `74HC193`, `4017`, `4020`, and `74HC4024`, then adds three mixed-family
  cascade experiments. The `74HC192` donor has an ambiguous duplicate `PIN9`
  label, so V2 treats signal names as authoritative for that family until a
  corrected donor confirms the pin map.
- `IC_SEQUENTIAL_COUNTERS_V3_MIXED_RETRY_TEMP_2026_06_09` failed user testing;
  even the same-family unit-slice control failed. Do not use unit slicing for
  sequential-counter ICs.
- `IC_SEQUENTIAL_COUNTERS_V4_WHOLE_DONOR_RETRY_TEMP_2026_06_09` partially
  failed user testing. Mixed identity-mutation cases T01, T02, and T03 gave
  ISIS errors. Wait for a real manual mixed sequential donor before trying
  cross-family sequential projects again.
- `IC_SEQUENTIAL_BATCH3_SOLO_TEMP_2026_06_09` passed user Proteus testing for
  every generated solo/control project. It imports solo donors for `74HC4040`, `74HC4060`, `4518`,
  `74HC4520`, `74HC74`, `74HC76`, `74HC174`, `74HC273`, and `4027`. This pack
  contains only per-family exact repack, E001 transplant, label mutation, 2x/4x
  controls where supplied, and RLC donor transplants.
- `IC_SEQUENTIAL_BATCH4_SOLO_TEMP_2026_06_09` passed user Proteus testing for
  every generated solo/control project. It imports the final supplied donor pack for `74HC85`,
  `74HC283`, `74HC157`, `74HC47`, `74HC165`, and `74HC595`. The user-facing
  `74HC47` donor uses Proteus marker `7447`.
- `ANALOG_MISC_BATCH1_SOLO_TEMP_2026_06_09` passed user Proteus testing for
  every generated solo/control project. It imports whole-donor controls for `NE555`, `NPN`, `PNP`,
  `LM741`, and `ELEC-CAP`; the electrolytic capacitor donor uses Proteus marker
  `CAP-ELEC` and blank donor terminal labels.
- `MIXED_IC_ANALOG_BATCH1_TEMP_2026_06_09` passed user Proteus testing. It
  imports real mixed donors that combine sequential ICs, R/C/L, `NPN`, `PNP`,
  `LM741`, and `CAP-ELEC`. The pack only proves complete donor
  repack/transplant/topology-preserving label mutation; it does not re-enable
  failed unit slicing or mixed identity mutation.
- `MIXED_IC_ANALOG_SUBSET_V1_TEMP_2026_06_09` passed user Proteus testing. It
  removes only complete balanced object regions while preserving the full donor
  `ROOT.CDB` and device section. The analog/RCL prefix and the
  `74HC193`/`74HC192` pair are treated as indivisible balanced bundles.
- `MIXED_IC_CROSS_DONOR_V1_TEMP_2026_06_09` failed user Proteus testing: T01
  and T06 gave LXLCORE.dll errors, and T02-T05 crashed on open. Do not reuse its
  unpatched device-section concatenation method.
- `MIXED_IC_CROSS_DONOR_V2_METADATA_TEMP_2026_06_09` is static-clean and
  failed user Proteus testing with the same pattern as V1: T01/T06 gave
  LXLCORE.dll errors and T02-T05 crashed on open. Do not use whole donor
  device-section concatenation for cross-donor IC mixtures, even with patched
  section footers and sorted CDB rows.
- `MIXED_IC_CROSS_DONOR_V3_FILTERED_DEVICE_TEMP_2026_06_09` is static-clean
  but failed user Proteus testing with the same pattern as V1/V2. This showed
  that the previous fixes did not touch the real failing surface.
- `MIXED_IC_CROSS_DONOR_ISOLATION_V1_TEMP_2026_06_09` is static-clean except
  for one intentionally unsafe metadata case. User testing reported T00, T01,
  and T02 worked correctly, while T03 onward crashed before opening. This
  proves same-donor region extraction is safe, and that the first cross-donor
  working case requires full donor device sections.
- `MIXED_IC_CROSS_DONOR_ISOLATION_V2_FULL_DEVICE_CDB_TEMP_2026_06_09` is
  accepted as a boundary test. User testing reported T00, T03, T05, T06, T07,
  and T10 worked, while all old generated/stitched CDB cases crashed before
  open. The failed generated cases used invalid CDB row slicing, so do not
  treat that result as proof that CDB synthesis is impossible.
- `MIXED_IC_CROSS_DONOR_CDB_V1_CORRECT_ROWS_TEMP_2026_06_09` is accepted as a
  boundary test. User testing reported only T00 and T06 worked;
  all reduced generated-CDB cases crashed before opening. This shows the CDB
  parser/builder row boundaries are not sufficient if the full donor CDB
  skeleton/count is reduced.
- `MIXED_IC_CROSS_DONOR_CDB_V2_FULL_SKELETON_TEMP_2026_06_10` is accepted with
  one resolved follow-up: user testing reported every case worked except T05,
  which gave a DLL error without crashing.
- `MIXED_IC_CROSS_DONOR_CDB_V3_T05_ISOLATION_TEMP_2026_06_10` is accepted.
  User testing reported every T05 isolation case worked. The active CDB mixing
  policy is now full donor device sections plus a complete donor `ROOT.CDB`
  skeleton with parser-built row replacement inside that skeleton.
- `MIXED_IC_CROSS_DONOR_ACCEPTED_V1_TEMP_2026_06_10` is partially accepted:
  T01, T02, T04, T05, and T07 opened and simulated, but T03/T06 had
  simulation-time CDB/pin errors and T03/T08 exposed a visible `74HC4060`/`U9`
  no-model problem. Large mixed sequential/misc IC packs must not concatenate
  raw donor coordinates without a layout separation pass.
- `MIXED_IC_CROSS_DONOR_ACCEPTED_V2_LAYOUT_TEMP_2026_06_10` is rejected as a
  layout method. User testing showed every case had floating text artifacts
  because V2 moved terminal symbols and IC bodies without moving terminal-label
  coordinates and component text coordinates. T03 and T05 also failed
  simulation. Do not use V2 broad layout output as a generator baseline.
- `MIXED_IC_FOCUSED_V3_TEMP_2026_06_10` is rejected as a mixed sequential IC
  layout route. User testing showed T01/T02 did not work, while the remaining
  cases opened; T05/T06 failed simulation with `74HC4060` no-model errors. The
  broad coordinate scan can corrupt non-coordinate fields and must not be used.
- `MIXED_IC_FOCUSED_V4_TEMP_2026_06_10` is partially accepted but its
  `74HC4060` model patch is rejected. User testing reported T05/T06/T07 failed
  with `VALUE+VOLTAGE` netlist linker errors after the patch added
  `VOLTAGE=4.5V`. Do not add `VOLTAGE=4.5V` to `74HC4060` instance metadata.
  The non-4060 V4 cases worked/opened.
- `MIXED_IC_FOCUSED_V5_DONOR_NATIVE_TEMP_2026_06_10` is accepted only for its
  non-4060 paths. User testing reported T05 analog/basic RLC/BJT/LM741/CAP-ELEC
  and T06 NE555-to-RLC worked properly. T01-T03 failed with no model specified
  for exact donor-native `74HC4060` refs, and T04 failed with no model
  specified for `U7:A` and `U9`. Because the exact donor-native 4060 repack
  failed, do not include `74HC4060` in simulation-oriented packs for this
  Proteus install; keep it open/render-only until a model-backed donor is
  supplied.
- `MIXED_IC_FOCUSED_V6_NO4060_TEMP_2026_06_10` is static-clean and pending
  user Proteus testing. It intentionally excludes `74HC4060`, repeats the two
  accepted V5 routes as baselines, then tests one LM741-output-to-RLC-node edit
  and one second-NE555-Q-to-RLC edit.
- `IC_EXACT_REZIP_ALL_FAMILIES_TEMP_2026_06_10` is static-clean. It now
  contains 41 exact donor-content rezips across all currently supplied IC
  families plus refreshed 4060 and 4520 probes. It performs no
  label/topology/coordinate/CDB mutation. User testing reported old T018
  74HC4060 failed, refreshed T034 onward worked, and old T020 74HC4520 failed.
  The canonical 4060 donors were replaced with the refreshed user-supplied
  donors; the old 4060 files are kept only under
  `sequential_ics_4060_legacy_bad_20260610`. The refreshed 4520 exact rezips
  T038-T041 are pending user testing.
- `IC_PAIRWISE_34_V1_TEMP_2026_06_10` is static-clean and pending user Proteus
  testing. It creates 561 unordered pairwise IC-mixing diagnostics from 34
  IC-only source cases. The source set excludes old rejected T018/T020, excludes
  RLC-containing T037, and excludes refreshed 4520 T038-T041 until those exact
  rezips pass. It uses same-length package-ref remaps, a generic CDB splitter
  for subpart pin rows, full donor device sections, and a right-side coordinate
  translation. Treat it as diagnostic, not main generator support.
- `IC_PAIRWISE_ERROR_FIXED_V2_TEMP_2026_06_10` is the accepted pairwise repair
  path for V1-rejected pairs involving accepted combinational ICs. It is
  intentionally partial: it does not regenerate V1-passed pairs and does not
  attempt non-combinational-only failures.
- `IC_PAIRWISE_COMBINATIONAL_METHOD_V1_TEMP_2026_06_11` is the next temporary
  test pack. Use it to verify whether the accepted combinational-side method is
  safe for every pair containing `S01..S07`, and whether the non-combinational
  collision-only CDB-ID probe deserves further expansion.
- The production route is now:

```text
python -m proteusgen generate-ic-combinational circuit.json --outdir out --layout-strategy beautify
```

  The locked JSON route accepts `gates` plus optional R/C/L `passives`, supports
  repeated packages for 15-input AND/OR reduction trees, keeps IC pins
  directional, and keeps passive `G0` on the accepted donor `$TERGROUND`
  method.
- The accepted baseline covers exact donor repack, E001 transplant, label-only
  mutation, two-package HC08 control, power/ground logic constants, diagnostic
  RCL-load transplant, and HC32 all-four cross-family controls.
- Current next step: improve the IC layout/compaction heuristics as needed,
  then continue to the next IC family group.
- User DIP14 input normalization is documented in
  `docs/74hc08_user_input_rules.md` and machine-readable examples live in
  `docs/74hc08_user_input_examples.json`.

## Native IC/display route implementation (2026-06-11)

The first conservative production entry point for sequential/native ICs,
analog ICs, transistors, electrolytic capacitors, and 7-segment displays now
exists:

```text
python -m proteusgen generate-ic-native circuit.json --outdir out
```

Schema:

```text
schemas/ic_native_circuit_ir_v0_1.schema.json
```

Registry:

```text
proteus_ic/registry/native_components.json
```

Implemented behavior:

- exact donor rezip controls;
- complete single/two/four same-family donor insertion into E001;
- known manual pair donor insertion into E001;
- donor-native `$TERBIDIR` label mutation when a donor has terminal anchors;
- explicit connection requests are blocked when the selected donor has no
  terminal anchors;
- complete donor `ROOT.CDB` and device sections are preserved.

Current native registry coverage includes:

```text
7490/74HC90, 74HC160, 74HC161, 74HC163, 74HC192, 74HC193,
4017, 4020, 74HC4024, 74HC4040, refreshed 74HC4060,
4518, refreshed 74HC4520,
74HC74, 74HC76, 74HC174, 74HC273, 4027,
74HC85, 74HC283, 74HC157, 74HC47/7447, 74HC165, 74HC595,
NE555, LM741, NPN, PNP, CAP-ELEC,
7SEG_COM_ANODE / 7SEG-COM-AN-BLUE
```

Deferred/limited families remain listed in the registry: `74HC151`, `74HC153`,
`4051`, `74HC48`, `4008`, `4013`, `74HC175`, `4063`, and `4511`. These need
clean solo or pair donors before exact support is enabled.

Static tests:

```text
python -m pytest tests/test_ic_native.py -q
```

This passed locally on 2026-06-11. The route is still pending Proteus
open/simulation testing before promotion to main user-facing support.

First generated pack:

```text
experiments/IC_NATIVE_V1_TEMP_2026_06_11.zip
```

It contains 11 static-clean cases:

```text
T00 7447 + 7SEG exact control
T01 74HC160 single bider-label generation
T02 4017 single bider-label generation
T03 refreshed 74HC4060 single render control
T04 refreshed 74HC4520 single render control
T05 7SEG common-anode single bider generation
T06 NE555 single bider generation
T07 LM741 single bider generation
T08 manual 7490 + 4017 pair control
T09 analog misc mixed exact donor control
T10 CAP-ELEC single bider generation
```

Second generated validation pack:

```text
experiments/IC_NATIVE_VALIDATION_V2_TEMP_2026_06_12.zip
```

It is registry-driven and static-clean:

```text
119 exact donor controls
39 exact manual pair donor controls
30 generated single-native E001 transplants
39 generated manual pair E001 transplants
3 negative controls blocked as expected
```

One donor-evidence warning is preserved in the summary:

```text
P010_7490_74HC160_PAIR_NATIVE:
  Registry marker 74HC160 is absent from the selected pair donor object/CDB records.
```

That warning does not mean the project file is structurally dirty; it means the
manual pair donor should be visually checked before relying on that exact pair
as proof of 74HC160 coexistence.

User partial testing on 2026-06-12 reported that `P010` works. The same report
flagged 74HC4060/74HC4520-like pairs as possible `U2 model not specified`
failures, so those remain model-metadata follow-up items until the full per-case
Proteus pass is available.

Four-plus component probe:

```text
experiments/IC_NATIVE_QUAD_MIX_V1_TEMP_2026_06_12.zip
```

This pack has 18 static-clean cases:

```text
6 timing/counter/sync/flip-flop complete donor-native mix cases
2 analog/RLC/native mix cases
2 display-driver 7447 + 7SEG common-anode cases
8 4060/4520-adjacent pair-isolation cases
```

Each donor is emitted twice: exact rezip and complete donor packet inserted into
E001. The pack preserves donor labels and does not mutate terminals because the
large mixed donors mostly have no `$TERBIDIR` terminal anchors.

User testing on 2026-06-12 reported:

```text
Q000-Q009 worked and simulated.
Q010 onward did not work and is left aside for now.
```

Because the first accepted mixed cases still lacked bider terminals in several
large donors, the next temporary pack is terminal-bearing and connection-aware:

```text
experiments/IC_NATIVE_BIDER_PAIRS_V1_TEMP_2026_06_12.zip
```

It is static-clean and contains:

```text
241 generated missing native IC pairs
35 manual pair combinations rebuilt from single bider donors
4 four-component bider mix cases
```

This pack excludes `74HC4060` and `74HC4520` after the Q010-onward rejection.
Every generated pair uses complete single-donor packets with `$TERBIDIR` pin
anchors and at least one shared same-name bider net between the two components.
Generated terminal labels avoid `U` followed by digits so byte-level package-ref
checks do not misread terminal labels as component references.

User simulation testing then exposed a V1 CDB identity issue in:

```text
M000_TIMING_CHAIN_NE555_7490_4017_4020
```

Proteus reported duplicate part references such as `U2 [U1]`,
`U3 [U1]`, and duplicate `X000000...` rows. Byte inspection showed the visible
refs were already unique, but the hidden `ROOT.CDB` row IDs were not:

```text
pin primary IDs:   [1, 1, 1, 13]
pin secondary IDs: [1, 1, 1, 13]
property IDs:      [1, 1, 1, 13]
```

The replacement temporary pack is:

```text
experiments/IC_NATIVE_BIDER_PAIRS_V2_CDB_IDFIX_TEMP_2026_06_12.zip
```

It keeps the same 280-case scope as V1 but adds a strict binary CDB identity
repair pass. It only patches known little-endian row ID fields when duplicates
are detected. For the failing `M000` case, IDs now become:

```text
pin primary IDs:   [1, 2, 3, 4]
pin secondary IDs: [1, 2, 3, 4]
property IDs:      [1, 2, 3, 4]
```

Static generation result:

```text
280 generated cases
0 blocked cases
0 static validation issue cases
archive sha256 bddaf74e92747eccbc83d0f0974b9d16867d99ac44ae89191a1bc04c5bd73447
```

Focused local regression:

```text
python -m pytest tests/test_ic_native.py tests/test_ic_pairwise_error_focused.py tests/test_mixed_ic_analog_donors.py -q
34 passed
```

This pack is still pending user Proteus open/simulation testing. If Proteus
still reports `No power supply specified for net Q...`, that is a separate
digital power-rail policy issue, not the duplicate CDB ID bug.

User testing then reported that the entire V2 CDB-ID-fix pack crashed before
opening. That rejects the broad native bider-pair/mix route for now, even though
the files were static-clean. The active method is back to one IC at a time,
matching the earlier successful passive/component workflow.

First focused IC pack:

```text
experiments/IC_7490_FOCUSED_V1_TEMP_2026_06_12.zip
```

Scope:

```text
7490 / 74HC90 only
14 cases
0 blocked cases
0 static validation issue cases
archive sha256 8859be6776fe4be83d38f750b5c3321e42e1937f71ba4be2b72a5e6a846cadc2
```

This pack deliberately avoids all cross-donor synthesis. Test order:

```text
T00 exact single donor rezip
T01 single donor inserted into E001 with no label mutation
T02 single generated bider labels
T03 single explicit pin labels
T04 exact 2x donor rezip
T05 2x donor inserted into E001 with no label mutation
T06 2x generated bider labels
T07 2x Q0-to-CKA same-name bider chain
T08 exact 4x donor rezip
T09 4x donor inserted into E001 with no label mutation
T10 4x generated bider labels
T11 4x Q0-to-CKA same-name bider chain
T12 exact 4x + RLC donor rezip
T13 4x + RLC donor inserted into E001 with no label mutation
```

The result should tell us exactly which operation is safe before moving to the
next IC family.

User testing on 2026-06-12 reported all 14 focused 7490 cases worked. This
accepts the focused same-family path for `7490` / `74HC90`:

```text
exact same-family donors
E001 whole-donor transplant
$TERBIDIR label mutation
2x and 4x same-family donor chains
4x 7490 + RLC donor controls
```

The next pack uses that acceptance to test real counter circuits without broad
cross-donor synthesis:

```text
experiments/IC_7490_REAL_CIRCUITS_V1_TEMP_2026_06_12.zip
```

Scope:

```text
8 realistic 7490 circuits
base donor: SQU/4_7490withRLC.pdsprj
0 blocked cases
0 static validation issue cases
archive sha256 aab54c74e425da9450385f0ecdf7fd9a8eed74f501c36bd6e8579f4840626249
```

Cases:

```text
T01_MOD10_OUTPUT_RLC_FILTER
T02_DIVIDE_BY_100_CASCADE_WITH_RLC_LOAD
T03_FOUR_DECADE_RIPPLE_CHAIN
T04_RC_POWER_ON_RESET_BUS
T05_CLOCK_INPUT_CONDITIONER
T06_MOD6_COUNTER_WITH_FILTERED_RESET
T07_BCD_TAPS_WITH_SHARED_RESET_AND_LOAD
T08_DUAL_RATE_OUTPUT_MONITOR
```

IC beautifier policy in this pack:

```text
preserve complete Proteus donor coordinates
use compact ASCII net labels
prefer same-name labels for readable electrical connectivity
emit ic_layout_plan.json with bounds, max label length, and same-name net counts
avoid arbitrary standalone wires and cross-donor component placement
```

For example, the four-decade ripple chain has `max_label_length=4` and repeated
same-name nets such as `C1D`, `C2D`, `C3D`, `AOUT`, and `G0`, keeping the IC
view substantially cleaner than long generated pin names.

User testing on 2026-06-12 reported the 8-case pack worked, but the user
rejected it as an inadequate final acceptance test because it did not exercise
the 7490 with the full already-locked component set. Do not treat a one
resistor / one capacitor / one inductor adjacent load as sufficient new-IC
coverage.

The corrected stronger integration pack is:

```text
experiments/IC_7490_FULL_INTEGRATION_V1_TEMP_2026_06_12.zip
```

Scope:

```text
5 stronger 7490 integration circuits
four native 7490 counters per case
five accepted combinational gate slices per case
8 to 11 R/C/L passive components per case
all accepted combinational families covered across the pack:
74HC00, 74HC02, 74HC04, 74HC08, 74HC32, 74HC86, 74HC266
0 static validation issue cases
archive sha256 fd48eef80df1171c8fa836884043154f52d7799df23ac6d9bdceb39f764052ae
```

Cases:

```text
T01_7490_BCD_DECODE_RESET_FILTER_BANK
T02_7490_DIGITAL_WINDOW_WITH_XNOR_NOR_LOADS
T03_7490_MOD60_PULSE_STRETCHER
T04_7490_DEBOUNCED_CLOCK_AND_ALARM_DECODE
T05_7490_CASCADE_WITH_MULTI_FAMILY_STATUS_BUS
```

This pack uses native 4x7490 donor records plus fresh accepted combinational
gate slices and generated R/C/L records. It is a temporary experiment until the
user confirms Proteus open/render/simulation results.

User testing on 2026-06-12 rejected this stronger integration pack: all cases
crashed before opening. The failure is attributed to synthetic cross-donor
composition, not to the concept of testing 7490 with gates and passives. Do not
use `generate_ic_7490_full_integration_v1_temp.py` as the next base.

The replacement candidate uses the new user-created all-in-one donor corpus:

```text
proteus_ic/donors/manual_downloads_20260612/ICcombinationfinal
```

Inventory:

```text
143 .pdsprj donors
proteus_ic/donors/manual_downloads_20260612/ICcombinationfinal_inventory.json
```

Current 7490 golden-donor pack:

```text
experiments/IC_7490_GOLDEN_DONOR_V1_TEMP_2026_06_12.zip
```

Scope:

```text
5 mixed 7490 circuits
base donor: 7490/2_7490_withallcombunationaland21RLC.pdsprj
two native 7490 ICs
all six binary combinational families already present in the donor
donor 21RLC network already present in the donor
0 blocked cases
0 static validation issue cases
archive sha256 34f531a5e80af16b28520891590396f9c43525fced9252f22068382fcf76df0f
```

Cases:

```text
T01_7490_MOD6_DECODE_FULL_GATE_RLC
T02_DUAL_7490_BCD_COMPARE_RLC_LOADS
T03_RLC_CONDITIONED_CLOCK_AND_GATED_COUNTER
T04_WINDOWED_RESET_AND_PARALLEL_RLC_TAPS
T05_CASCADED_7490_LOGIC_STATE_DECODER
```

Generation rule:

```text
single Proteus-created all-in-one donor only
no IC/passive/CDB/device-section synthesis
no component deletion
mutate 7490 $TERBIDIR labels through the accepted native helper
mutate existing $TERINPUT/$TEROUTPUT labels in place, keeping two-character labels
preserve donor ROOT.CDB and device metadata
```

This is now the active 7490 integration candidate pending user Proteus testing.

User testing on 2026-06-12 reported the V1 golden-donor pack works, but the
user rejected it as too close to the donor because it only changed bider and
terminal labels.

The next structural candidate is:

```text
experiments/IC_7490_STRUCTURAL_V2_TEMP_2026_06_12.zip
```

Scope:

```text
10 structural 7490 mixed circuits
base donors:
  7490/2_7490_withallcombunationaland21RLC.pdsprj
  7490/6_7490_withallcombunationaland21RLC.pdsprj
0 blocked cases
0 static validation issue cases
archive sha256 2826512a04c43ab2e13393cd225044329b022345b702d6a09fa736b3f9386bb7
```

Cases:

```text
T01_SINGLE_7490_MOD6_AND_RLC_RESET
T02_SINGLE_7490_THREE_FAMILY_CLOCK_FILTER
T03_DUAL_7490_COMPARE_NO_NAND_NOR
T04_DUAL_7490_WINDOW_RESET_NO_XOR_XNOR
T05_DUAL_7490_AND_NAND_ONLY_RLC
T06_SIX_7490_LONG_RIPPLE_FULL_GATES
T07_SIX_7490_TRIMMED_LOGIC_BANK
T08_SIX_7490_TWO_BANK_DECODER
T09_TWO_7490_STATE_MACHINE_REDUCED_GATES
T10_SIX_7490_SPARSE_COUNTER_MIX
```

Generation rule:

```text
single Proteus-created all-in-one donor family only
no cross-donor CDB/device/object synthesis
remove only complete counter packages or complete four-gate family banks
compute removal spans before length-changing bider label rebuilds
patch remaining bider labels by post-removal order
preserve donor ROOT.CDB, device metadata, project members, and object terminator
```

This is pending user Proteus open/render/simulation testing. If it fails, debug
the first failing case before applying complete-packet removal to another IC.

## Component placer gate (2026-06-15)

The body-only component placer experiment from the 16x sequential/native mega
donor is rejected. User testing reported that all 140 generated projects failed,
so the next native IC phase must not generate more files from that method.

Use the planner/validator first:

```text
python -m proteusgen plan-component-placement request.json
```

The trusted donor manifest is:

```text
proteus_ic/registry/trusted_donor_manifest.json
```

Current policy:

```text
no cloning
no synthetic IC records
no synthetic terminal/wire generation
no body-only packet extraction
no copying full donor ROOT.CDB after deletion
```

The planner selects the closest removal-only donor using exact package counts.
Small requests should prefer IC-wise donors from `native_components.json`; large
requests may use the 2026-06-15 mega donor only when its verified true package
counts satisfy the request. The mega donor has 64 packages per listed target
family, not 16.

Before any future `.pdsprj` emission, the deletion plan must specify:

```text
kept package refs
deleted package refs
ROOT.CDB pin/property rows to keep/delete
device metadata pruning policy
duplicate-ref/model/orphan validators
beautifier move-linkage validation
```

Regression coverage:

```text
python -m pytest tests/test_component_placer.py -q
```

V2 generated pack:

```text
experiments/COMPONENT_PLACER_SEQ_16X_V2_PRUNED_CDB_TEMP_2026_06_15.zip
```

This pack contains the requested 140 no-terminal component-placer projects:
1/3/5/15/23 same-family packages for each target family, plus every unordered
three-package pair in both 2+1 directions. It keeps V1's body-only output
surface but fixes the rejected metadata rule by rebuilding `ROOT.CDB` from only
kept package pin/property rows. The 16x mega donor CDB property table is not
ordered by pin-table package order; parse it directly. Non-final property rows
overlap the next row by four bytes, so a pruned final row needs a four-byte zero
terminator.

User Proteus testing rejected V2: none of the cases worked. The follow-up V3
pack is:

```text
experiments/COMPONENT_PLACER_SEQ_16X_V3_FULL_PACKETS_TEMP_2026_06_15.zip
```

V3 preserves complete donor-native packet boundaries instead of stripping
terminal/wire records. For a native IC, the linked bider terminal block and wire
records are part of the valid component packet. The observed stream shape is
`00 + complete packet records + FF`; V2's body-only `00 00 FF...` shape is
rejected.

User Proteus testing also rejected V3. Complete packet boundaries are necessary
but are not enough when taken from the broad repeated mega donor. The current
7490-specific recovery pack is:

```text
experiments/IC_7490_REMOVAL_LADDER_V1_TEMP_2026_06_16.zip
```

Generator script:

```text
tools/proteus_generation/2026-06-16/generate_7490_removal_ladder_v1_temp.py
```

This pack uses only the 7490-specific mixed host donor:

```text
proteus_ic/donors/manual_downloads_20260612/ICcombinationfinal/7490/6_7490_withallcombunationaland21RLC.pdsprj
```

It includes exact donor controls and a deletion ladder:

```text
T00_7490_ONLY_6X
T01_7490_ONLY_5X
T02_7490_ONLY_4X
T03_7490_ONLY_3X
T04_7490_ONLY_2X
T05_7490_ONLY_1X
T06_7490_ONLY_0X
```

The method keeps the host donor DSN/device-section model, removes only complete
7490 packet spans, and rebuilds `ROOT.CDB` to the kept package refs. It does
not rename, move, clone, or synthesize IC bytes. Treat this as pending until
the ladder opens in Proteus.

User testing rejected the ladder: all exact `C` controls opened, while every
`T` deletion case crashed. The follow-up diagnostic pack is:

```text
experiments/IC_7490_DELETION_DIAGNOSTICS_V1_TEMP_2026_06_16.zip
```

It must be used before more 7490 deletion attempts. Test `D00-D02` first to
separate exact copy/repack/unchanged `build_dsn`, then continue through
`D03-D19` to isolate CDB pruning, object deletion, host-device mismatch, and
same-family tail deletion.

Diagnostic result: user reported `D03`, `D05`, `D08`, `D14`, `D16`, and `D18`
failed. These are the CDB-pruned/zero-CDB cases. The full-CDB variants were not
reported failed, so 7490 deletion must preserve the full donor `ROOT.CDB` for
now.

Current full-CDB follow-up pack:

```text
experiments/IC_7490_REMOVAL_LADDER_V2_FULL_CDB_TEMP_2026_06_16.zip
```

User testing confirmed that all V2 full-CDB 7490 ladder cases worked. For the
current native deletion/component-placer route, preserve full donor `ROOT.CDB`
and remove only complete `ROOT.DSN` packet spans.

The master-sheet follow-up pack is:

```text
experiments/COMPONENT_PLACER_SEQ_16X_V4_FULL_MASTER_CDB_TEMP_2026_06_16.zip
```

Generator:

```text
tools/proteus_generation/2026-06-16/generate_component_placer_seq_16x_v4_full_master_cdb_temp.py
```

This pack uses the 16x sequential IC master donor, keeps selected complete IC
packets in original byte order, and preserves full master `ROOT.CDB`. It contains
140 generated cases: 50 same-family count cases and 90 three-package pair cases.

User testing confirmed the V4 master pack opened, simulated, and worked, with
one exception: `74HC160` cases accidentally included intervening combinational
and RLC records. The cause was packet-end detection using the next sequential
package instead of the next object boundary.

Focused bare-placement follow-up:

```text
experiments/74HC160_BARE_MIXED_V1_TEMP_2026_06_16.zip
```

Generator:

```text
tools/proteus_generation/2026-06-16/generate_74hc160_bare_mixed_v1_temp.py
```

This pack emits generated cases with no terminal records and no wire records.
It keeps only component body records for `74HC160`, selected combinational IC
packages, and R/C/L passives while preserving full master `ROOT.CDB`.

User testing rejected that first bare pack because every generated sheet opened
empty. Do not use terminalized-master body records as no-terminal placement
records. Proteus-created no-terminal donors have a distinct object stream:

```text
00 00 + body records + FF
```

The current diagnostic pack is:

```text
experiments/BARE_VISIBILITY_DIAGNOSTIC_V1_TEMP_2026_06_16.zip
```

Generator:

```text
tools/proteus_generation/2026-06-16/generate_bare_visibility_diagnostic_v1_temp.py
```

Controls `D00-D08` compare exact no-terminal donors, rebuilt no-terminal donor
chunks, the rejected B00 output with one added prefix byte, and no-terminal
records inside the terminalized master container. Candidate cases `D09-D15` use
only Proteus-created no-terminal donor records and preserve full donor
`ROOT.CDB`. Test those before promoting any bare component-placer method.

Follow-up user feedback and V5 testing corrected the next rule: resistor records
are not required as an anchor. The failed no-resistor outputs were caused by
using a raw middle record as the last record in the object stream.

Accepted final-record diagnostic:

```text
experiments/BARE_VISIBILITY_FINAL_RECORD_V5_TEMP_2026_06_16.zip
```

Current mega-donor separation pack:

```text
experiments/MEGA_BARE_SEPARATION_V1_TEMP_2026_06_16.zip
```

Generator:

```text
tools/proteus_generation/2026-06-16/generate_mega_bare_separation_v1_temp.py
```

This pack uses the 20260616 all-supported-component semimega donors. It selects
complete no-terminal groups, preserves full donor `ROOT.CDB`, and if a selected
middle group becomes the final object, trims one trailing `00` before appending
the final `FF`. It includes no-resistor cases so that resistor removal is tested
directly instead of being treated as forbidden.

## Promoted Mega Donors

The current main mega donor copies are:

```text
proteus_ic/donors/main_mega_20260618
```

They are copied from the 20260616 manual corpus, not moved, so the raw evidence
folder remains intact. The removal-only component placer reads trusted counts
from:

```text
proteus_ic/registry/trusted_donor_manifest.json
```

Display-specific support notes are tracked separately because display rows are
not normal package records:

```text
proteus_ic/registry/mega_component_support_20260618.json
```

Confirmed current display/4027 rule: the V11 D20-bridged pack worked for all
tested cases. Keep the original 375-byte `D20` diode packet immediately before
mega display rows when generating accepted display or 4027+display output. Do
not remove D20 until the explicit D20-removal diagnostic passes.

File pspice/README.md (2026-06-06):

# OrCAD / PSpice Visual Project Generator

Reserved workspace for the OrCAD/PSpice visual project generation track.

This is separate from the Proteus generator work, but it follows the same product philosophy: a user types a circuit request on the website and receives native EDA project files that open as visual schematics, not just textual netlists.

## Correct product target

Target reference: EE-215 Electronic Devices and Circuits lab manual.

The generator should create native OrCAD Capture / PSpice project files that open with a visible schematic laid out as if it was manually built.

The primary deliverable is not a `.cir` or raw SPICE/PSpice netlist. Netlists may be emitted as secondary/debug artifacts, but they are not the product target.

## Generator direction

The intended pipeline is:

```text
natural-language prompt
  -> validated CircuitIR JSON
  -> OrCAD/PSpice visual schematic project backend
  -> native project files for download
```

The output should include an editable visual schematic project suitable for PSpice simulation setup. The user should be able to open the generated project and see placed components, wires/nets, sources, probes/markers where supported, values, references, and simulation-relevant setup.

## Naming rule

Use precise wording in docs and UI:

```text
OrCAD/PSpice visual project generator
AI OrCAD Capture schematic generator with PSpice support
Prompt to editable OrCAD/PSpice project
```

Avoid wording that implies the project is only a PSpice netlist generator.

## Platform finding

Current public product material positions OrCAD X as the OrCAD PCB design suite with integrated PSpice analysis. PSpice for TI is also described by TI as being based on the OrCAD Capture framework.

For this project, assume the working OrCAD/Capture environment is Windows-first unless a verified official Linux build is found in the installed Cadence download portal or official documentation.

Linux can still be used for:

- repository work
- Python analysis
- file comparison
- manifest generation
- documentation
- non-GUI validators

Do not assume that OrCAD Capture visual project creation can be run natively on Linux until verified on the exact installed version.

## Compliance guardrail

This is not legal advice, but the project should be conservative.

Route A is preferred for implementation and compliance because it uses the vendor tool itself, its supported automation/scripting/export behavior, or files saved by the tool. Route A should not bypass licensing, activation, cloud access, copy protection, or usage restrictions.

Route B is not automatically safer. Controlled mutation and native-file study may be useful for research, interoperability analysis, or validation, but it can become legally risky if it depends on reverse engineering prohibited by the applicable EULA, bypassing technical protections, redistributing proprietary files, or cloning protected internal formats beyond what is allowed by law and the license.

Before any public release based on Route B:

- read the actual OrCAD/PSpice EULA shown during installation
- read any academic/trial/commercial license restrictions
- avoid decompiling executables or bypassing protection systems
- do not redistribute vendor libraries, proprietary sample projects, or licensed assets unless permitted
- keep generated outputs based on the user's own licensed environment or clean project templates
- prefer official automation, documented interchange formats, or user-created clean-room templates
- get legal/mentor review before commercial deployment

Proteus and OrCAD/PSpice should both follow the same compliance rule: generate user projects without bypassing the vendor's protection mechanisms and without redistributing proprietary vendor assets.

## Why this exists

KiCad prompt-to-schematic generation is already an active public direction. This track is intentionally different: the goal is Proteus-style native visual project generation for the OrCAD/PSpice ecosystem.

Cadence positions OrCAD as a PCB design and analysis suite with schematic capture, PSpice simulation, PCB layout, and professional design workflows. PSpice is the simulator, while the visual schematic entry side is OrCAD Capture. Therefore this repo track must treat visual project generation as the first-class target.

## Compatibility with the Proteus generator

Reusable from the Proteus work:

- natural-language-to-CircuitIR concept
- circuit validation
- component map
- topology model
- layout model
- test-case discipline
- controlled-mutation experiments
- manifest/output verification philosophy

Not directly reusable from the Proteus work:

- Proteus ROOT.DSN / ROOT.CDB binary patching
- Proteus terminal donor objects
- Proteus-specific object ordering
- Proteus `.pdsprj` repacking logic

The correct abstraction is:

```text
CircuitIR core
  -> Proteus visual backend
  -> OrCAD/PSpice visual backend
  -> later KiCad visual backend
```

## Backend strategy

Two implementation routes are allowed, but they are not equal in release risk.

### Route A: OrCAD-authoritative generation

Use OrCAD/Capture-supported automation, scripting, import/export behavior, or other vendor-supported mechanisms where possible to place components, wire nets, set references/values, configure simulation assets, and save native project files.

This is the preferred first route because native files saved by OrCAD itself are more likely to open cleanly, look manually built, and stay closer to license-compliant usage.

### Route B: controlled-mutation native-file generation

Use the Proteus research method on OrCAD/PSpice project files only inside a controlled, licensed, non-public research lane unless legal review approves wider use:

1. Create small manual donor projects in a properly licensed OrCAD/PSpice environment.
2. Save controlled mutations.
3. Compare `.opj`, `.dsn`, library/model references, simulation-profile files, and related project artifacts.
4. Identify component placement records, wire/net records, references, values, model links, source configuration, probes/markers, page metadata, and project-level bindings.
5. Generate native files only after the record structure is validated by open/resave tests.
6. Do not bypass technical protections or redistribute vendor-owned data.

This route is more novel but must not be treated as automatically legally safer than Route A.

## Target output package

Each generated project package should eventually contain:

```text
<project_name>.opj
<project_name>.dsn
required local libraries or references, if needed
PSpice simulation profile/settings, if supported
README_OPEN_FIRST.txt
manifest.json
optional generated netlist/debug export
```

The manifest should include:

```text
input_prompt
input_json_sha256
backend_name
backend_version
OrCAD/PSpice version target
component count requested
component count emitted
net count
wire count
source/probe count
simulation setup included or omitted
libraries/models used
known limitations
validation status
open/resave test status when available
```

## First supported circuit class

Start with visual schematic generation for simple EE-215-style circuits:

- resistor
- capacitor
- inductor
- diode
- DC voltage source
- AC/sine voltage source
- pulse/square source
- ground node
- voltage markers/probes where supported
- current measurement mechanism where supported
- basic `.OP`, `.DC`, `.TRAN`, and `.AC` simulation setup as secondary project configuration

## EE-215 experiment target map

1. Basic lab equipment and signal concepts: sine, square, triangle sources; frequency, period, amplitude, RMS, DC offset, AC/DC coupling style outputs.
2. Diode characteristics: diode I-V curve using DC sweep; resistor voltage, diode voltage, diode current, threshold voltage, DC and AC resistance estimates.
3. Series and parallel diode circuits: DC bias networks, series diodes, parallel diode paths, diode logic, bridge diode networks, output voltage and branch current calculations.
4. Half-wave and full-wave rectification: sine source rectifiers, bridge rectifier, center-tapped rectifier, diode replacement tests, average DC level and waveform plots.
5. Clipping circuits: parallel and series clippers with square and sine inputs, biased clipping levels, output waveform plots.
6. Clamping circuits: diode-capacitor clamp networks, shifted waveform outputs, DC restoration behavior.
7. LED and Zener diode circuits: LED current/voltage, Zener regulation, load-line and regulation measurements.
8. BJT characteristics: input/output characteristic curves, base/collector currents, beta-related measurements.
9. Fixed and voltage-divider BJT bias: DC operating point, base/emitter/collector voltages and currents.
10. Emitter and collector feedback BJT bias: DC operating point and bias stability comparisons.
11. BJT bias design circuits: calculated design values and simulated Q-points.
12. Common-emitter amplifier: transient and AC small-signal gain, input/output waveforms, phase inversion.
13. Common-base and emitter-follower amplifiers: voltage gain, input/output waveforms, impedance-related observations.
14. Common-emitter amplifier design: target gain/bias constraints and simulation verification.
15. MOSFET characteristics: transfer/output curves and threshold behavior.
16. MOSFET DC biasing: Q-point and bias network verification.
17. MOSFET common-source amplifier: gain, waveform, and frequency-response style outputs.
18. Diode switching application: transient switching waveform generation and timing behavior.

## Phase 1 implementation priority

Phase 1 should support visual schematic project generation for:

- resistor
- capacitor
- inductor
- diode
- DC voltage source
- AC/sine voltage source
- pulse/square source
- ground node
- basic visible wiring/nets
- component references and values
- simulation markers/probes if supported in the chosen generation route

## Phase 2 implementation priority

Phase 2 should add visual schematic support for:

- Zener diode models
- LED diode models
- BJT models and bias/amplifier templates
- MOSFET models and bias/amplifier templates
- transformer approximations for rectifier labs
- richer simulation-profile generation

## Boundary

This folder is for OrCAD/PSpice visual project generation only.

Do not reduce this track to netlist-only output. Netlists are allowed as secondary artifacts, but the main user-facing deliverable is a native visual schematic project.

Proteus generator records remain outside this folder.

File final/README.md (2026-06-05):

# Final Locked Baseline

This folder is the locked baseline for the **general JSON-to-Proteus resistor + input/output terminal generator**.

The goal is not to generate only the 6R example. The goal is:

```text
Input:  any valid JSON circuit graph containing RESISTOR components and two-character node labels
Output: Proteus 8.13 .pdsprj generated from the blank E001 base
Method: V9 linked input-terminal/output-terminal/resistor/wire group method
Current component support: RESISTOR only
Current terminal support: generated input/output terminal objects per resistor endpoint
```

The corrected 6R circuit is only the locked reference test fixture proving the method.

## Empty E001 base rule

All generated projects must be built from the blank E001 base.

For the corrected 6R generated pack, this was verified from the generated artifact:

```text
CONTROL_E001_EMPTY_BASE.pdsprj is included in the output package.
generation_code_used.py sets E0 = CONTROL_E001_EMPTY_BASE.pdsprj.
PROJECT.XML is copied from E001.
SCRIPTS/PWRRAILS.DAT is copied from E001.
ROOT.CDB is generated.
ROOT.DSN is generated.
```

So the 6R result was already generated on empty E001.

## Files

```text
final/README.md
final/general_resistor_terminal_generator_spec.md
final/locked_v9_method.md
final/json_circuit_ir_spec.md
final/ai_json_authoring_guide.md
final/codex_generator_requirements.md
final/locked_handdrawn_6r_case.md
final/examples/handdrawn_6r_corrected.json
final/templates/generation_manifest_template.json
final/roadmap_components.md
```

## General circuit model

Any current-baseline circuit is represented as a graph:

```text
nodes = electrical nets / junctions
resistors = two-terminal edges between nodes
input terminal object = visual terminal created at resistor endpoint nodes[0]
output terminal object = visual terminal created at resistor endpoint nodes[1]
```

For every resistor component in JSON, the generator emits:

```text
input terminal for nodes[0]
output terminal for nodes[1]
resistor visual object
left wire object
right wire object
CDB resistor record
```

## Locked reference fixture

Corrected hand-drawn 6R topology:

```text
R1: N0 - N1
R2: N1 - N2
R3: N0 - N2
R4: N2 - N3
R5: N3 - N4
R6: N0 - N4
```

Generated file recorded as correct:

```text
HANDDRAWN_6R_CORRECTED_N0_N1_N2_N3_N4.pdsprj
```

Recorded hashes:

```text
project_sha256: 2f5eb8226c825736ca5ff15dd48177c3c5b9c52364f9eeea9f2bf9ba62018476
zip_sha256: e54b7c0be48798635a6942b08b4237096e96408b57de87c15682451ac9784f7a
```

## Mandatory recording rule

Every future generation must be recorded in this repository with:

```text
source request
source files and hashes when available
interpreted circuit graph
generator JSON input
script/generator version
manifest JSON
generated output hashes
static validation result
user feedback
known limitations
next action
```

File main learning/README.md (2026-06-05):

# Main Learning

This folder stores long-form human-readable learning documents for the Proteus generator project.

## Current learning PDFs generated locally

The following files were generated in the ChatGPT sandbox and should be copied into this folder manually if binary storage is required:

```text
resistor_E0_R1_R2_R3_R4_pattern_comparison.pdf
resistor_E0_R1_R2_R3_R4_full_byte_diff_no_green.pdf
resistor_E0_R1_R2_R3_R4_diff_no_green_artifacts.zip
resistor_E001_R1_R4_full_comparison.pdf
resistor_E001_R1_R4_diff_only_with_generated_attempt.pdf
resistor_diff_only_with_generated_attempt_artifacts.zip
```

## Why the PDFs are not stored directly here yet

The GitHub connector available in this chat is reliable for UTF-8 text files. Direct binary upload is not exposed through the simple contents API wrapper in this environment. Base64 text storage is possible, but large PDFs create very large text commits and are awkward to maintain.

For now, the PDF files are delivered as sandbox artifacts in the chat and this folder records the intended GitHub location and restore policy.

## Restore policy if base64 chunks are added later

If a file is stored as `.base64` or split into `part_001.b64`, `part_002.b64`, etc., restore it with:

```bash
cat part_*.b64 > file.pdf.base64
base64 -d file.pdf.base64 > file.pdf
```

PowerShell equivalent:

```powershell
$txt = (Get-Content part_*.b64 -Raw)
[IO.File]::WriteAllBytes("file.pdf", [Convert]::FromBase64String($txt))
```

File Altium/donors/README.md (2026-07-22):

# Altium Donors

The current compact schematic and project-descriptor seeds live in
[`../source_pack/donors/`](../source_pack/donors/) because they are runtime
catalogue evidence. This directory is reserved for future raw donor archives,
desktop-open evidence, and controlled source comparisons.

Future family or PCB donor work must capture the smallest native Altium project
that proves symbol, pin, value, footprint, pad, board, rule, or routing
behavior. Record source hashes and the exact desktop result. Do not store
generated output here; each generated candidate belongs in a unique experiment
run with its normalized input and validation report.

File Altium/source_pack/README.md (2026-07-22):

# Altium Source Pack

The direct schematic writer embeds two compact, audited native source seeds:

```text
donors/logic_trainer_ascii_seed.SchDoc
SHA-256 bfc862eff7dc73bcc787fde8d6fdfc37e283b6249a6e029ee946abf681c2dde8

donors/nodemcu_project_seed.PrjPcb
SHA-256 ab26512b221a97af8f2f39342ecf886d134b24b685a8cb1a196720e0cc9b9f96
```

It is a line-oriented `Protel for Windows - Schematic Capture Ascii File
Version 5.0` document captured from the authorized logic-trainer donor. The
catalogue reads it at generation time and refuses to run if its hash changes.

The project descriptor seed is an exact-section extraction from the real
MIT-licensed NodeMCU Altium project. Its provenance, source commit, original
hash, and retained license are recorded beside it. The writer changes only the
single `DocumentPath` field and preserves the donor-native `Design`,
`Preferences`, `Document1`, and `Configuration1` grammar.

The compact pack provides complete native record payloads for the locked
component families plus native examples of:

- sheet record `RECORD=31`;
- wire record `RECORD=27`; and
- net-label record `RECORD=25`.

It also provides source pin designators, native pin names, coordinates, and
escape directions derived from `PINCONGLOMERATE`. The generator copies the
actual source records and rebases their owner/index/coordinate data into a
fresh document. It does not draw a generic replacement symbol or manufacture a
record grammar from scratch.

Only records needed by the audited direct catalogue are used. Adding another
family requires source evidence, a hash update, catalogue parsing coverage,
and a focused direct-generation regression.

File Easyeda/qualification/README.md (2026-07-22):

# EasyEDA Qualification

## Current Qualification Delivery

The current implementation created this 300-circuit corpus to test the actual independent
EasyEDA pipeline, not guided special cases. It covers every locked donor family
and every source pin through named real-world application archetypes, then
drives the ordinary input fixer, native emitter, validator, PCB stage, and
portable executable exactly as a user request would. This is the concrete qualification
leap over earlier prototypes: broad, repeatable, full-pin, full-net, native-project evidence
instead of narrow file-creation experiments.

The locked corpus is:

`Easyeda/qualification/corpora/2026_07_17_full_pin_300_v1/`

It contains 300 canonical inputs: 30 electrically distinct named application
archetypes, each emitted in 10 deployment/value profiles. The profiles are
education, prototype, field, compact, diagnostic, industrial, instrument,
automation, development, and production validation.

## Coverage Contract

- All 59 logical catalogue entries are represented.
- All 57 physical donor families are used in at least one PCB.
- Every unique electrical source pin is explicitly assigned.
- Explicitly unused pins use distinct `NC_*` nets.
- Qualification inputs require zero fixer changes and zero `GUESS_*` nets.
- Every case stays within 80 schematic components and 32 physical PCB
  components.
- The executable result passes its independent structural, source-hash,
  geometry, full-pin, exact-netlist, and pad-level PCB connectivity checks.
- The 10 most complex distinct topologies are opened through the installed
  EasyEDA Pro file association from disposable copies and held for 20 seconds
  each for direct human inspection.

The corpus contains application structures informed by official ESP32 hardware
guidelines, TI CAN/RS485 reference-design material, and ST evaluation-board
documentation:

- https://docs.espressif.com/projects/esp-hardware-design-guidelines/en/latest/esp32/
- https://www.ti.com/tool/TIDA-00004
- https://www.st.com/en/evaluation-tools/stm32-eval-boards/documentation.html

These references guide ordinary power, reset, communications, and peripheral
structures. The corpus files are deterministic qualification fixtures, not
vendor reference schematics or substitutes for design review.

## Reproduce

Build the corpus:

```bash
python -m Easyeda.qualification_corpus \
  --output Easyeda/qualification/corpora/new_full_pin_300
```

Run all 300 through the portable executable:

```bash
python -m Easyeda.qualification_runner \
  Easyeda/qualification/corpora/2026_07_17_full_pin_300_v1 \
  --output-root /tmp/easyeda_qualification \
  --executable Easyeda/dist/progen-easyeda \
  --workers 4 \
  --timeout 180
```

Open one case per electrical topology in the installed application:

```bash
python -m Easyeda.native_acceptance_runner \
  /tmp/easyeda_qualification/<run>/qualification_report.json \
  --output-root /tmp/easyeda_native_acceptance \
  --variant 1 \
  --most-complex \
  --limit 10 \
  --wait-seconds 45 \
  --settle-seconds 20 \
  --retries 2
```

Every runner creates a new immutable output directory. Previous reports and
generated projects are never overwritten.

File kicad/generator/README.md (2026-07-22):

# KiCad Generator Workspace

This folder retains the persistent source-writing research and component
catalogue work that feeds the active KiCad backend.

## Current Active Generator Delivery

The current implementation took the early source-writing milestones recorded below and connected
them to the complete `kicad/pipeline/` generator: canonical JSON repair,
source-backed symbol/pin use, arrangement, routing, terminals, values,
validators, packaging, and optional PCB output. This is a substantial advance
over prior isolated writer experiments: the source writer is now
one proven stage in an executable pipeline with expected-net and geometry
acceptance rather than a stand-alone file emitter.

Run the active source generator from the repository root:

```bash
PYTHONPATH=. python -m kicad.pipeline.progen_kicad_executable run INPUT.json \
  --output-root /tmp/progen-kicad-runs --routing-mode combination
```

The final release/qualification details are in
[`../FINALIZATION_STATUS.md`](../FINALIZATION_STATUS.md). The V6/V7 notes below
are preserved because they document the donor/source discovery that the current implementation
expanded into the current backend.

## Historical Locked Milestone

V6 is the first source-driven KiCad generator milestone that the user opened successfully in KiCad:

```text
syntax opens
embedded symbols render
pin-endpoint autorouting connects wires correctly
```

The correct writer order is still:

```text
header -> uuid -> paper -> lib_symbols -> schematic items -> sheet_instances
```

## Historical V7 Component Catalog

V7 adds a broad component catalog in:

```text
kicad/generator/kicad_backend/component_catalog.py
```

The catalog currently contains 60 component kinds. It separates components into two tiers:

```text
verified_embedded
cataloged_needs_symbol_cache
```

### Verified embedded / portable now

These have verified embedded symbol-cache blocks from KiCad source fixtures and have already been used in working V5/V6 generated projects:

```text
GND
R
L
VDC
VSIN
```

### Cataloged but not yet fully portable

These have metadata now: KiCad lib id, aliases, pin list, approximate pin-local connection model, SPICE class where relevant, and default value.

```text
C, CP, C_POL, R_POT, FERRITE, FUSE, PTC, MOV, TVS,
D, DIODE, LED, ZENER, SCHOTTKY, BRIDGE,
VPULSE, VAC, IDC, ISIN, IPULSE,
NPN, PNP, NMOS, PMOS, JFET_N, JFET_P,
OPAMP, LM741, LM358, LM393, NE555, L7805, LM317,
74HC00, 74HC04, 74HC08, 74HC32, 74HC86, 74HC74,
74HC76, 74HC90, 74HC157, 74HC192, 4511, 4017,
CONN_2, CONN_3, CONN_4, CONN_6, CONN_8, TESTPOINT,
+5V, +3V3, VCC, GNDA
```

These must not be called fully verified until their symbol-cache blocks and pin endpoints are extracted from real KiCad donor files and tested.

## Run examples

```bash
python kicad/generator/kicad_visual_generator.py --example vdc_resistor_op --out out/vdc_resistor_op
python kicad/generator/kicad_visual_generator.py --example vsin_rl_tran --out out/vsin_rl_tran
```

Open the generated `OPEN_THIS_FIRST__...PROJECT_FILE.kicad_pro` file in KiCad.

## Output package

Each run writes:

```text
*.kicad_pro
*.kicad_sch
*.cir                 # debug-only cross-check netlist
manifest.json
static_checks.json
README_OPEN_FIRST.txt
```

The `.cir` file is not the product. The product is the editable visual KiCad project.

## Master plan

The all-component roadmap is tracked here:

```text
kicad/planning/COMPONENT_MASTER_PLAN.md
```

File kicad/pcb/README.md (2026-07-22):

# Integrated KiCad PCB Pipeline

Status date: 2026-07-18

This package is the bounded native KiCad PCB stage of the canonical ProGenEDA
pipeline. It consumes the same fixed main JSON and exact resolved schematic pin
geometry used by schematic generation. It does not accept a separate PCB input.

## Current PCB Delivery

The current implementation built this from a small proof target into the active bounded physical
stage: source-footprint provenance, symbol-pin-to-pad mapping, square-fill
placement, two-layer routing variants, no-installation parsing and validation,
artifact packaging, and external KiCad DRC evidence. The current delivery improvement over the
earlier prototype work is visible in the contract: the PCB uses the same canonical
JSON as the schematic, ships only after every physical check passes, and keeps
all accepted/rejected variations for audit instead of pretending that an
unrouted board is usable.

The current common-400 release qualification produced 311 accepted boards and
89 explicit withholds. The current implementation then used the discovered KQ26 multi-unit
pin/body-clearance case to strengthen the shared schematic settlement logic;
the ten repaired profiles all produced accepted boards, and the packaged KQ26
smoke board passed KiCad 10.0.4 DRC with zero violations and zero unconnected
items. The complete schematic/PCB release record is in
[`../qualification/RESULTS_2026_07_17.md`](../qualification/RESULTS_2026_07_17.md).

## Runtime Architecture

```text
canonical main JSON
-> validated KiCad schematic placement/pin contract
-> physical_design_compiler
-> footprint_placer
-> pcb_router (two copper layers, route variants/retries)
-> kicad_pcb_writer
-> independent kicad_pcb_parser
-> pcb_validator
-> output_packager
```

Modules:
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

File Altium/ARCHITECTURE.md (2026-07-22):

# Altium Architecture

## Product Path

The product path is direct and backend-independent:

```text
canonical JSON
  -> input fixer / AltiumCircuit IR / value editor
  -> source catalogue resolution / component selector
  -> placed-design contract
  -> route-informed arrangement trials / beautifier
  -> wire planner / terminal placer / routing validator
  -> source-backed wire maker / direct native ASCII SchDoc writer
  -> output packager / PCB decision
  -> saved-file graph, geometry, and ZIP package final validator
```
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

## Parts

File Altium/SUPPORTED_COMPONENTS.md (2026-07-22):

# Altium Supported Components

## Direct Schematic Catalogue

The following families are directly emitted today from complete native source
records in `source_pack/donors/logic_trainer_ascii_seed.SchDoc`. This is a
schematic-only catalogue; no direct `.PcbDoc` is emitted yet.

| Canonical family | Accepted aliases | Native source library reference |
| --- | --- | --- |
| Resistor | `resistor`, `res`, `r` | `MFR-25JT-52-10K` |
| Capacitor | `capacitor`, `cap`, `c` | `FN43N104J500EGG` |
| LED | `led` | `204-10SDRD/S530-A3-L` |
| Switch | `switch`, `pushbutton`, `button` | `Key_TH_3.5x6x4.3` |
| Two-pin header | `pinheader`, `header`, `connector`, `connector2`, `pinheader2` | `2.54-1*2P_` |
| 2x5 header | `header2x5` | `1.27_2x5_3.6THR` |
| Quad NAND | `74hc00`, `sn74hc00` | `SN74HC00N` |
| Hex inverter | `74hc04`, `sn74hc04` | `SN74HC04N` |
| Quad AND | `74hc08`, `sn74hc08` | `SN74HC08N` |
| Quad OR | `74hc32`, `sn74hc32` | `74HC32D,653` |
| Dual D flip-flop | `74hc74`, `sn74hc74` | `SN74HC74N` |
| 555 timer | `ne555`, `timer555` | `NE555DR` |

Run the following command for the exact source pin designators, native pin
names, physical locations, and directions:

```bash
PYTHONPATH=. python -m Altium.executable supported-components
```

## Pin and Value Rules

- Every physical source pin must appear once in the component's `pins` map.
  A deliberately unused pin must use an explicit `NC_*` net.
- A canonical name resolves only when it matches an audited source pin
  designator or native pin name. For example, the current LED accepts `A` and
  `C`, which resolve to native pins `1` and `2`.
- Values are edited by changing the cloned source `Value` and `Comment`
  properties. No family-specific substitution or footprint change is inferred
  from a value string.
- Component references must be unique and are copied into the source
  `Designator` property.

## Qualification Status

The source catalogue, direct writer, package writer, and deterministic
saved-file validator are implemented. The catalogue has **not** yet passed an
Altium Designer desktop open/render/compile gate because the local desktop
installation is still incomplete. That gate is required before calling any
family desktop-qualified.

No unsupported source family is approximated. The generator fails with the
known aliases when a request cannot resolve to one of the records above.

## PCB Boundary

Several cloned schematic records carry source footprint/model associations,
but that is not equivalent to direct PCB support. Until an audited native
`.PcbDoc` writer and pad/net/board validator exist, this backend produces no
board, Gerber, drill, BOM, or placement output.

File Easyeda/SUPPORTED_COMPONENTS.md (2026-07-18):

# Supported EasyEDA Components

## Codex 5.6 Locked Catalogue

Codex 5.6 built this catalogue from exact authorized EasyEDA source records,
then drove every physical family through the 300-circuit qualification corpus.
That is why these are real donor-native symbols/devices/footprints rather than
approximations. The 5.6 delivery made support expandable by audited catalogue
rows and donor evidence instead of scattered component-specific generator code.

All entries resolve to exact source devices at generation time. Values may be
changed per instance; the locked donor footprint remains the catalogue
footprint unless a later audited profile explicitly adds package selection.
There are 59 logical entries: 57 physical donor families and two schematic
terminal families.

## Basic

`R`, `R_POT`, `C`, `CAP_ELEC`, `L`, `DIODE`, `1N4007`, `1N4148`, `LED`,
`SPST_SWITCH`.

## Electrical Engineering Lab and Digital

`NPN`, `PNP`, `NMOS`, `LM7805`, `LM317`, `BRIDGE_RECTIFIER`, `TRANSFORMER`,
`FUSE`, `TERMINAL_BLOCK`, `PIN_HEADER`, `GND`, `VCC`, `LM358`, `NE555`,
`74HC00`, `74HC04`, `74HC08`, `74HC32`, `74HC74`, `74HC595`.

## Embedded

`ESP32_WROOM`, `ESP12F`, `ATMEGA328P`, `STM32F103C8T6`, `CP2102`, `CH340`,
`BME280`, `DS3231`, `W25Q64`, `SSD1306`.

## Communications

`MAX485`, `SN65HVD230`, `SM24CANB`.

## I2C Expansion

`ADS1115`, `AT24C256`, `PCA9685`, `PCF8574`.

## Power and USB

`AP2112K_3V3`, `FERRITE_BEAD`, `PTC_FUSE`, `USBLC6_2SC6`,
`USB_C_RECEPTACLE`.

## PCB Utility

`HEADER_1X2`, `HEADER_1X6`, `HEADER_2X3`, `HEADER_2X5_1P27`,
`MOUNTING_HOLE_NPTH`, `MOUNTING_HOLE_PTH`, `TEST_POINT`.

Common accepted aliases are defined in [catalogue.py](catalogue.py). The
executable command `progen-easyeda catalogue` returns the machine-readable
locked list.

PCB inclusion is decided per circuit, not merely per component name. Every
used pin must map to a source footprint pad and the complete physical board
must pass the bounded router and validator. The hardened PCB limit is 32
physical components; the schematic limit is 80 total input components.

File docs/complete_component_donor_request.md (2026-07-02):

# Complete component donor request

This is the complete donor plan for the component families currently named by
the Progen component placer and IC registries. It is not a claim to cover every
part in the full Proteus library, which contains vendor and device variants not
yet present in Progen's catalog.

Use Proteus 8.13 and create every donor manually in Proteus. Do not generate,
copy, or byte-edit a donor outside Proteus.

## Donor suite definitions

Use these suite codes in the inventories below.

### TP2: two-pin component suite

1. `<FAMILY>_D01_1X_BARE.pdsprj`: one bare component, default horizontal
   orientation.
2. `<FAMILY>_D02_1X_BIDIR_BOTH_PINS.pdsprj`: one component with one
   bidirectional terminal attached to each real pin through the shortest
   Proteus-created wire.
3. `<FAMILY>_D03_4X_BIDIR_BOTH_PINS.pdsprj`: four terminalized components,
   unique references and terminal labels, saved as one project.
4. `<FAMILY>_D04_15X_BIDIR_BOTH_PINS.pdsprj`: fifteen terminalized components,
   unique references and terminal labels, saved as one project.
5. `<FAMILY>_D05_4X_BIDIR_WITH_RCL_CONTROLS.pdsprj`: four terminalized target
   components plus one bare resistor, capacitor, and REALIND. This exposes
   mixed-family ordering without making R/C/L part of the target.

### MP4: multi-pin discrete/analog suite

1. `<FAMILY>_D01_1X_BARE.pdsprj`.
2. `<FAMILY>_D02_1X_ALL_PINS_BIDIR.pdsprj`: terminalize every visible
   electrical pin; do not invent hidden pins.
3. `<FAMILY>_D03_4X_ALL_PINS_BIDIR.pdsprj`.
4. `<FAMILY>_D04_4X_ALL_PINS_BIDIR_WITH_RCL_CONTROLS.pdsprj`.

For switches, potentiometers, transistors, regulators, op-amps, timers,
bridges, and transformers, every electrically usable pin must be represented.

### IC4: IC package suite

1. `<FAMILY>_D01_1PKG_BARE_ALL_UNITS.pdsprj`.
2. `<FAMILY>_D02_1PKG_ALL_VISIBLE_PINS_BIDIR.pdsprj`.
3. `<FAMILY>_D03_2PKG_ALL_VISIBLE_PINS_BIDIR.pdsprj`.
4. `<FAMILY>_D04_4PKG_ALL_VISIBLE_PINS_BIDIR.pdsprj`.
5. `<FAMILY>_D05_4PKG_BIDIR_WITH_RCL_CONTROLS.pdsprj`.

Place every unit belonging to the package, such as U1:A through U1:D. Attach
terminals to every visible logic, clock, reset, enable, carry, and power pin.
Keep Proteus-native references such as U1/U2; do not rename packages to A1 or
synthetic references.

### DSP4: display suite

1. One bare display.
2. One display with all segment/common pins terminalized.
3. Four displays with all pins terminalized.
4. Four displays plus the matching decoder IC, with all objects still
   electrically disconnected.

## Non-IC inventory

The first six families are already accepted. Do not recreate them unless a
fresh donor is specifically requested.

| Family | Suite | Current need |
|---|---:|---|
| RESISTOR | accepted | RESISTOR/v3 already passed |
| CAP | accepted | CAP/v2 already passed |
| CAP-ELEC | accepted | CAP-ELEC/v3 already passed |
| REALIND | accepted | REALIND/v2 already passed |
| VSOURCE | accepted | VSOURCE/v4 already passed |
| CSOURCE | accepted | CSOURCE/v4 already passed |
| DIODE | TP2 | required; highest priority |
| 1N4007 | TP2 | required |
| 1N4148 | TP2 | required |
| 1N4733A | TP2 | required |
| 1N6000B | TP2 | required |
| IRDIODE | TP2 | required |
| 40EPS08 | TP2 | required |
| BZX55C5V1 | TP2 | required |
| BZX79C5V1 | TP2 | required |
| BZY88C | TP2 | required |
| LED-RED | TP2 | required; highest priority |
| FUSE | TP2 | required; highest priority |
| VSINE | TP2 | required; highest priority because current evidence lacks general 1x/3x/15x final ordering |
| VPULSE | TP2 | required; highest priority |
| BRIDGE | MP4 | required |
| NPN | MP4 | required |
| PNP | MP4 | required |
| 2N3904 | MP4 | required |
| 2N4401 | MP4 | required |
| NMOSFET | MP4 | required |
| 2N7000 | MP4 | required |
| BS170 | MP4 | required |
| TRAN-2P2S | MP4 | required |
| LM317T | MP4 | required |
| LM741 | MP4 | required |
| OPAMP | MP4 | required |
| NE555 | MP4 | required |
| POT-HG | MP4 | required |
| SWITCH | MP4 | required |
| 7SEG-COM-AN-BLUE / 7SEGCOMA | DSP4 | required |
| 7SEG-COM-CAT-BLUE / 7SEGCOMK | DSP4 | required |

The immediate next two-pin batch is therefore:

`DIODE`, `1N4007`, `1N4148`, `1N4733A`, `1N6000B`, `IRDIODE`,
`40EPS08`, `BZX55C5V1`, `BZX79C5V1`, `BZY88C`, `LED-RED`, `FUSE`,
`VSINE`, and `VPULSE`.

## IC inventory

Every row uses the IC4 suite. Existing repository donors can be audited first,
but a row is not accepted by the shared terminal placer until its pin roles,
record order, suffix progression, multi-package boundary, open/render result,
and simulation result are separately recorded.

### Logic gates

| Family | Notes |
|---|---|
| 74HC00 | quad NAND |
| 74HC02 | quad NOR |
| 74HC04 | hex inverter |
| 74HC08 | quad AND |
| 74HC32 | quad OR |
| 74HC86 | quad XOR |
| 74HC266 | quad XNOR/open-collector family |

### Combinational, decoder, and arithmetic ICs

| Family | Notes |
|---|---|
| 74HC85 | comparator |
| 74HC283 | adder |
| 74HC151 | multiplexer |
| 74HC153 | exact clean family donor currently missing |
| 74HC157 | multiplexer |
| 4511 | seven-segment decoder/driver |
| 7447 / 74HC47 | observed Proteus marker is `7447` |
| 74HC48 | exact clean family donor currently missing |
| 4051 | exact clean family donor currently missing |
| 4008 | exact clean family donor currently missing; do not substitute 74HC283 |
| 4063 | exact clean family donor currently missing; do not substitute 74HC85 |

### Sequential, counter, and register ICs

| Family | Notes |
|---|---|
| 4027 | dual JK flip-flop |
| 4013 | exact clean family donor currently missing |
| 4017 | decade counter |
| 4020 | counter |
| 4518 | dual counter |
| 7490 | observed Proteus counter marker |
| 74HC74 | dual D flip-flop |
| 74HC76 | dual JK flip-flop |
| 74HC160 | counter |
| 74HC161 | counter |
| 74HC163 | counter |
| 74HC165 | parallel-in shift register |
| 74HC174 | register |
| 74HC175 | exact clean family donor currently missing; do not substitute 74HC174 |
| 74HC192 | counter |
| 74HC193 | counter |
| 74HC273 | register |
| 74HC4024 | counter |
| 74HC4040 | counter |
| 74HC4060 | use only the refreshed component family |
| 74HC4520 | counter |
| 74HC595 | serial-in shift register |

## Required construction rules

- Use a fresh project for each donor file.
- Keep the target component at its Proteus default value and orientation.
- Let Proteus allocate all object references and package units.
- Use bidirectional terminals for donor learning, including source and IC pins.
- Give every terminal a unique, short label.
- Use the shortest visible wire segment from terminal contact to the exact pin.
- Keep D01-D04 pure: no unrelated components, probes, generators, or rails.
- Add only the specified bare R/C/L controls in D05.
- Save, close, reopen, render, and run a minimal simulation/netlist check before
  delivering the project.
- Deliver original `.pdsprj` files, not screenshots, exported images, or
  extracted ROOT.DSN/ROOT.CDB files.

## Delivery order

1. Immediate TP2 batch: DIODE variants, LED-RED, FUSE, VSINE, VPULSE.
2. MP4 non-IC batch.
3. Existing IC-family audit and the missing exact-family IC donors.
4. Remaining IC4 suites.
5. DSP4 display suites.

This order unlocks the current shared terminal placer without mixing
unvalidated family behavior.

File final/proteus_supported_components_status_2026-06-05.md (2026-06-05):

# Proteus Generator Supported Components Status — 2026-06-05

## Status

User-reported major working milestone.

The generator can now generate runnable Proteus circuits using the following component families:

```text
Resistor
Capacitor
Inductor
Power terminal
Ground terminal
DC voltage source
DC current source
```

## Example prompt tested by user

```text
Make a circuit where a voltage supply v0 is connected to r1(10K). The resistor is connected to node A. On the right side of node A is an inductor of 10mH and on the downside is a capacitor of 10nF which is connected to the ground.
```

## Screenshot result observed

The user-provided screenshot shows a generated Proteus schematic containing:

```text
power terminal labelled V0
resistor R1 with value 10K
inductor L1 with value 10m
capacitor C1 with value 10n
ground terminal labelled G0
node labels such as V0, N1, and N2 used for connectivity
```

## Important interpretation

This is a strong milestone compared with the earlier state, where only resistor/power/ground behavior was locked and capacitor attempts had failed.

The current generator appears to rely on labelled terminals/nets for connectivity rather than drawing every continuous wire segment physically. This is acceptable for a generator backend if Proteus resolves same-name terminals/nets correctly and the generated circuit runs.

## Current honest capability statement

The safe statement is:

```text
The Proteus backend has reached a working primitive-component stage for R, C, L, power terminal, ground terminal, DC voltage source, and DC current source.
```

Avoid claiming unrestricted arbitrary circuit generation until the following are tested:

```text
multi-component mixed RLC networks
power + ground + source + RLC simulation behavior
DC current source polarity/orientation
component value mutation across multiple values
save-as/reopen stability
netlist/simulation correctness
larger topology scaling
```

## Recommended next validation matrix

```text
1. R only
2. C only
3. L only
4. R-C series
5. R-L series
6. R-L-C mixed network
7. DC voltage source + R + ground
8. DC current source + R + ground
9. DC voltage source + RLC + ground
10. same-name terminal connectivity check
11. save-as/reopen check for every case
12. simulation/netlist output check for every powered case
```

## Relation to previous locked methods

Previously locked stable baseline:

```text
Resistor V9 generator
Power terminal donor bridge / terminal method
Ground terminal short-wire endpoint
Power bridge + ground short-wire combined method
```

This status document records that the working surface has now expanded beyond that baseline to include:

```text
capacitor
inductor
DC voltage source
DC current source
```

## Next documentation task

Capture the exact generator method now being used for capacitor, inductor, DC voltage source, and DC current source, including:

```text
input JSON schema
component template source
ROOT.CDB handling
ROOT.DSN/object handling
value patching rules
orientation/coordinate rules
node/terminal naming rules
known limitations
validated example hashes
```

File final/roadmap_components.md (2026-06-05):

# Component Roadmap After Locked Resistor Baseline

This roadmap tracks component support after the locked resistor + endpoint-terminal baseline.

## Current locked support

```text
RESISTOR: two-terminal, CDB-backed, V9 linked terminal/resistor/wire group
POWER_TERMINAL: working with two locked methods
GROUND_TERMINAL: working with short-wire endpoint method only
PREFERRED_POWER_GROUND_COMBO: power donor bridge + ground short-wire endpoint
ACTIVE_NEXT_COMPONENT: capacitor V9 unique-index diagnostics
```

Resistor generation is locked for the current scope in the active generator repo. Use the spacing-adjusted V9 method as main; do not return to direct `$TERPOWER` resistor endpoints or standalone production visual wires.

## Power terminal status

Power terminal is working and locked with two methods:

```text
1. Short-wire endpoint method
   final/power_terminal_short_wire_method.md

2. Donor-derived output-bridge method
   final/power_terminal_output_bridge_method.md
```

The failed hand-built bridge method is recorded and must not be used:

```text
experiments/power_terminal_output_bridge_2026-05-29/test_result_vgdvc_failure.md
```

## Ground terminal status

Ground terminal is working and locked with one method:

```text
1. Short-wire endpoint method
   final/ground_terminal_short_wire_method.md
```

Ground bridge attempts are rejected for now.

Use this preferred combined method when both power and ground are needed:

```text
Power = exact donor-derived $TERPOWER + $TEROUTPUT bridge
Ground = $TERGROUND endpoint short-wired directly to resistor pin
```

Locked combined method:

```text
final/power_bridge_ground_shortwire_method.md
```

Rejected ground bridge experiment families:

```text
experiments/ground_terminal_bridge_2026-05-29/
experiments/ground_terminal_donor_bridge_2026-05-29/
experiments/ground_terminal_proper_donor_bridge_2026-05-29/
experiments/power_bridge_ground_input_bridge_improved_2026-05-29/
experiments/power_bridge_ground_input_bridge_corrected_2026-05-29/
experiments/power_bridge_ground_input_bridge_appended_2026-05-29/
```

Do not revisit ground bridge without a real manually-created Proteus ground-bridge donor.

## Remaining planned order

```text
1. capacitor
2. inductor
3. DC power source
4. AC power source
5. v1 actual generator release
```

## Completed Milestone: power terminal

Confirmed working methods:

```text
$TERPOWER(node) -> short wire -> resistor pin

donor-derived bridge cluster containing $TERPOWER and $TEROUTPUT(node), then same-name node connection to circuit
```

Requirements satisfied:

```text
identified marker: $TERPOWER
confirmed ROOT.DSN visual authority
confirmed no CDB record required in current observed method
confirmed connection behavior with resistor network by user testing
recorded artifacts and manifests
locked final method docs
```

Power terminal JSON extension target:

```json
{
  "ref": "P1",
  "type": "POWER_TERMINAL",
  "node": "N1",
  "label": "N1",
  "connection_style": "donor_output_bridge"
}
```

Alternative locked style:

```json
{
  "ref": "P1",
  "type": "POWER_TERMINAL",
  "node": "V0",
  "label": "V0",
  "connection_style": "short_wire_endpoint"
}
```

## Completed Milestone: ground terminal

Confirmed working method:

```text
$TERGROUND(G0) -> short wire -> resistor pin
```

Requirements satisfied:

```text
identified marker: $TERGROUND
confirmed ROOT.DSN visual authority
confirmed no CDB record required in current observed method
confirmed connection behavior with resistor network by user testing
recorded artifacts and manifests
locked final method doc
```

Ground terminal JSON extension target:

```json
{
  "ref": "G1",
  "type": "GROUND_TERMINAL",
  "node": "G0",
  "label": "G0",
  "connection_style": "short_wire_endpoint"
}
```

Ground bridge is not supported until a real donor exists.

## Next Milestone: capacitor

Current status:

```text
free multi-cap visual/CDB generation accepted
V7/V8 proved single terminal caps and free-first/terminal-last ordering
V9 tests unique hidden cap visual indexes for multi terminal-attached caps
do not promote to main yet
```

Required work:

```text
identify capacitor CDB component records
identify capacitor DSN visual object records
confirm value field handling
confirm linked terminal/wire grouping
test capacitor alone and resistor-capacitor network
update JSON spec
```

Current diagnostic gate:

```text
D:/Coding/protuesgen/experiments/capacitor_v9_unique_index_temp_2026_05_31
```

Possible JSON extension:

```json
{
  "ref": "C1",
  "type": "CAPACITOR",
  "value": "1u",
  "nodes": ["N1", "N2"]
}
```

Not locked yet.

## Milestone: inductor

Required work:

```text
identify inductor CDB records
identify inductor DSN visual records
confirm value field handling
confirm linked grouping
test resistor-inductor network
update JSON spec
```

Possible JSON extension later:

```json
{
  "ref": "L1",
  "type": "INDUCTOR",
  "value": "10m",
  "nodes": ["N1", "N2"]
}
```

Not locked yet.

## Milestone: DC power source

Required work:

```text
identify DC source primitive/model records
identify visual object record
confirm polarity handling
confirm value handling
confirm CDB simulation model behavior
create resistor + DC source + ground test
update JSON spec
```

Possible JSON extension later:

```json
{
  "ref": "V1",
  "type": "DC_VOLTAGE_SOURCE",
  "value": "5V",
  "nodes": ["N1", "G0"],
  "polarity": {"positive": "N1", "negative": "G0"}
}
```

Not locked yet.

## Milestone: AC power source

Required work:

```text
identify AC source primitive/model records
identify visual object record
confirm amplitude/frequency/phase fields
confirm CDB simulation model behavior
create AC source + resistor test
update JSON spec
```

Possible JSON extension later:

```json
{
  "ref": "V1",
  "type": "AC_VOLTAGE_SOURCE",
  "amplitude": "1V",
  "frequency": "1k",
  "phase": "0",
  "nodes": ["N1", "G0"],
  "polarity": {"positive": "N1", "negative": "G0"}
}
```

Not locked yet.

## v1 actual generator release criteria

v1 can be called only after the following are locked:

```text
JSON parser and validator
resistor generation
power terminal
ground terminal
capacitor
inductor
DC source
AC source
manifest generation
artifact recording workflow
static validation suite
at least one tested example for every supported component type
```

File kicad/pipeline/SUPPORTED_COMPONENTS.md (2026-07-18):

# Supported Component Baseline

## Codex 5.6 Catalogue Delivery

Codex 5.6 expanded the original practical baseline into the active
source-backed catalogue and connected it to the input fixer, placer, pin
resolver, validator, corpus, and release path. The resulting support boundary
is explicit and upgradeable: new families enter through audited catalogue and
source evidence, not a hidden one-off generator branch.

Date locked: 2026-07-01

This file records the current component-placer support baseline.

Current generated catalogue:

```text
kicad/pipeline/SUPPORTED_COMPONENTS_CATALOG.md
kicad/pipeline/SUPPORTED_WORDS_AND_ALIASES.md
```

As of 2026-07-10 the active placement catalog contains 163 normalized component
kinds. The original 100-component practical pack remains the locked beginner
baseline; the wider catalogue now includes Proteus-style aliases, common
simulation sources, logic ICs, communication parts, sensors, connectors,
passives, and documented substitutes. The supported-words document also lists
loose words and alias families accepted by the JSON fixer before canonical
generation.

## Source Of Truth

The supported component list is defined in:

- `kicad/pipeline/placement_catalog.py`
  - `PLACER_COMPONENT_SPECS`: normalized component kind, display name, reference prefix, rough body size, category.
  - `PLACER_KIND_LIB_IDS`: normalized component kind to real KiCad `Library:Symbol` id.
- `kicad/pipeline/SUPPORTED_COMPONENTS_CATALOG.md`
  - generated full list of current normalized kinds and KiCad symbol mappings.
- `kicad/examples/placer_run_2026_07_01_baseline_c11_spacing_fix_v2/inputs/*.json`
  - The current 20 practical partial CircuitIR-shaped circuits used as the 100-component acceptance pack.
- `kicad/examples/placer_run_2026_07_01_stress_limit_suite_v2/inputs/*.json`
  - The current stress/limit acceptance pack.
- `kicad/source_pack/kicad_symbol_subset_v10_0_4.json`
  - Bundled real KiCad 10.0.4 symbol blocks used when the local KiCad symbol library is unavailable.

## Current Acceptance Pack

The locked baseline is the 20-circuit practical pack:

1. Arduino LED Blink
2. 5V Power Supply
3. ESP32 WiFi Board
4. MOSFET Motor Driver
5. Relay Switching
6. I2C Sensor
7. SPI Flash
8. Crystal Oscillator
9. Op-Amp Amplifier
10. Buck Converter
11. Battery Charger
12. UART Interface
13. OLED Display
14. SD Card Interface
15. Audio Amplifier
16. CAN Bus
17. RS485 Communication
18. RTC Clock
19. Logic Interface
20. Sensor Input Board

Acceptance evidence:

- Current baseline run: `kicad/examples/placer_run_2026_07_01_baseline_c11_spacing_fix_v2`
- Current stress run: `kicad/examples/placer_run_2026_07_01_stress_limit_suite_v2`
- Unit tests: `python -m unittest kicad.tests.test_placer_pipeline -v`
- KiCad validation: `python -m kicad.automation.quality_check kicad/examples/placer_run_2026_07_01_baseline_c11_spacing_fix_v2 --kicad-cli kicad/.local/bin/kicad-cli`

Current result:

- 20 schematics checked.
- 20 passed.
- 0 failed.
- 0 `ProgenPlace` placeholder symbols.
- 0 embedded `(extends ...)` dependencies.
- Inputs use `id`/`kind`/`value`, `project`, and `nets` fields aligned with the full CircuitIR shape.
- C11 spacing issue is fixed in the current baseline run.
- Stress suite result: 22 schematics checked, 22 passed, 0 failed.

## Proteus-Style Alias Expansion

Added: 2026-07-02

The component placer now accepts this Proteus-style test set directly through
`kicad/pipeline/placement_catalog.py`:

`GROUND`, `VDC`, `VSOURCE`, `CSOURCE`, `VSIN`, `VPULSE`, `RES`, `POT-HG`,
`CAP`, `CAP-ELEC`, `REALIND`, `DIODE`, `1N4007`, `1N4148`, `1N60`, `BZX55C5`,
`BZX79C5`, `LED`, `NPN`, `PNP`, `NMOS`, `2N7000`, `BS170`, `OPAMP`, `LM741`,
`NE555`, `CD4007`, `LM317`, `TRANSFORMER`, `BRIDGE RECTIFIER`, `FUSE`,
`SWITCH`, `TERMINAL`, `7SEGCOMA`, `7SEGCOMK`, `4027`, `4511`, `7447`, `7490`,
`74HC00`, `74HC02`, `74HC04`, `74HC08`, `74HC32`, `74HC74`, `74HC76`,
`74HC85`, `74HC86`, `74HC151`, `74HC157`, `74HC160`, `74HC174`, `74HC192`,
`74HC266`, and `74HC283`.

All aliases map to real flattened KiCad symbols embedded into generated
schematics. These entries are intentionally still placement support, not final
SPICE-model support.

Closest-substitute notes:

| Requested kind | KiCad symbol used | Reason |
| --- | --- | --- |
| `1N60` | `Device:D` | KiCad 10.0.4 bundle does not ship an exact `1N60` symbol. |
| `BZX55C5` | `Device:D_Zener` | Exact BZX55C5 symbol was not present in the bundled library. |
| `BZX79C5` | `Device:D_Zener` | Exact BZX79C5 symbol was not present in the bundled library. |
| `OPAMP` | `Amplifier_Operational:LM741` | Generic Proteus op-amp request uses the common LM741 test symbol. |
| `CD4007` | `Transistor_FET:Q_Dual_NMOS_PMOS_G1S2G2D2S1D1` | KiCad 10.0.4 has no exact CD4007 CMOS array symbol. |
| `4511` | `4xxx_IEEE:4511` | The non-IEEE `4xxx` folder does not include 4511 here. |
| `7447` | `74xx_IEEE:7447` | Available in the IEEE TTL library. |
| `7490` | `74xx_IEEE:7490` | Available in the IEEE TTL library. |
| `74HC08` | `74xx:74LS08` | Exact HC symbol was absent; LS equivalent keeps pin-compatible layout. |
| `74HC32` | `74xx:74LS32` | Exact HC symbol was absent; LS equivalent keeps pin-compatible layout. |
| `74HC76` | `74xx:74LS76` | Exact HC symbol was absent; LS equivalent keeps pin-compatible layout. |
| `74HC151` | `74xx:74LS151` | Exact HC symbol was absent; LS equivalent keeps pin-compatible layout. |
| `74HC157` | `74xx:74LS157` | Exact HC symbol was absent; LS equivalent keeps pin-compatible layout. |
| `74HC160` | `74xx:74LS160` | Exact HC symbol was absent; LS equivalent keeps pin-compatible layout. |
| `74HC174` | `74xx:74LS174` | Exact HC symbol was absent; LS equivalent keeps pin-compatible layout. |
| `74HC266` | `4xxx:4077` | Exact HC symbol was absent; CMOS quad XNOR avoids repeated-power-pin ERC issues in placement smoke projects. |
| `74HC283` | `74xx:74LS283` | Exact HC symbol was absent; LS equivalent keeps pin-compatible layout. |

Regression tests:

- `test_proteus_style_component_kinds_resolve_to_real_kicad_symbols`
- `test_proteus_style_component_kind_pack_writes_openable_project`

## Variations

The current placer supports component kinds, not final values.

Value variations such as `220 ohm`, `10k`, `4.7k`, `100nF`, `22pF`, and similar resistor/capacitor/inductor values should reuse the same KiCad symbol kind and be handled by the later Value Editor stage.

Examples:

- Different resistor values use `Device:R`.
- Different ceramic capacitor values use `Device:C`.
- Different polarized capacitor values use `Device:C_Polarized`.
- Different pull-up resistors use the same resistor symbol with different displayed value metadata later.

## Adding A New Component

Use this checklist for future support increases:

1. Add a `PlacementSpec` entry in `PLACER_COMPONENT_SPECS`.
2. Add a real KiCad `Library:Symbol` mapping in `PLACER_KIND_LIB_IDS`.
3. Verify the KiCad symbol exists in `kicad/.local/AppDir/share/kicad/symbols` or another trusted KiCad source.
4. Rebuild the bundled source subset:

   ```bash
   python -m kicad.automation.build_kicad_symbol_subset
   ```

5. Add the component to an example pack or a focused test circuit.
6. Regenerate projects:

   ```bash
   mkdir -p kicad/examples/placer_run_<date>_<label>/inputs
   python -m kicad.automation.generate_practical_placer_examples --suite baseline --outdir kicad/examples/placer_run_<date>_<label>/inputs
   python -m kicad.pipeline.kicad_component_placer kicad/examples/placer_run_<date>_<label>/inputs --run-dir kicad/examples/placer_run_<date>_<label> --run-label <label>
   ```

7. Run tests and KiCad validation.
8. Archive the result under `kicad/experiment_records/runs/<new_run_name>/` with a README.

## Important Implementation Rule

Generated schematics must embed self-contained real KiCad symbols.

Do not reintroduce:

- `ProgenPlace:*` placeholder symbols.
- Box-only generated component drawings.
- Embedded symbol definitions that depend on `(extends ...)` being resolved at display time.

Derived KiCad symbols must be flattened by `kicad/pipeline/kicad_symbol_library.py`.

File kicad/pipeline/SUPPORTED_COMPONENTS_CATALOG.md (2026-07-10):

# Supported KiCad Component Catalogue

Generated: 2026-07-10

This file is generated from `kicad/pipeline/placement_catalog.py`. It lists the normalized component kinds that the current placer can resolve without asking the main JSON for extra symbol details.

Total supported normalized kinds: 163

| # | Kind | Display Name | Category | Reference Prefix | KiCad Symbol |
| ---: | --- | --- | --- | --- | --- |
| 1 | `1N4007` | 1N4007 Diode | diode | `D` | `Diode:1N4007` |
| 2 | `1N4148` | 1N4148 Diode | diode | `D` | `Diode:1N4148` |
| 3 | `1N60` | 1N60 Diode | diode | `D` | `Device:D` |
| 4 | `2N7000` | 2N7000 NMOS | mosfet | `Q` | `Transistor_FET:2N7000` |
| 5 | `4027` | 4027 Dual JK Flip-Flop | logic_ic | `U` | `4xxx:4027` |
| 6 | `4511` | 4511 BCD to 7-Segment Latch/Decoder | logic_ic | `U` | `4xxx_IEEE:4511` |
| 7 | `7447` | 7447 BCD to 7-Segment Decoder | logic_ic | `U` | `74xx_IEEE:7447` |
| 8 | `7490` | 7490 Decade Counter | logic_ic | `U` | `74xx_IEEE:7490` |
| 9 | `74HC00` | 74HC00 Quad NAND Gate | logic_ic | `U` | `74xx:74HC00` |
| 10 | `74HC02` | 74HC02 Quad NOR Gate | logic_ic | `U` | `74xx:74HC02` |
| 11 | `74HC04` | 74HC04 Hex Inverter | logic_ic | `U` | `74xx:74HC04` |
| 12 | `74HC08` | 74HC08 Quad AND Gate | logic_ic | `U` | `74xx:74LS08` |
| 13 | `74HC151` | 74HC151 8-Input Multiplexer | logic_ic | `U` | `74xx:74LS151` |
| 14 | `74HC157` | 74HC157 Quad 2-Input Multiplexer | logic_ic | `U` | `74xx:74LS157` |
| 15 | `74HC160` | 74HC160 Counter | logic_ic | `U` | `74xx:74LS160` |
| 16 | `74HC174` | 74HC174 Hex D Flip-Flop | logic_ic | `U` | `74xx:74LS174` |
| 17 | `74HC192` | 74HC192 Up/Down Counter | logic_ic | `U` | `74xx:74HC192` |
| 18 | `74HC266` | 74HC266 Quad XNOR Gate | logic_ic | `U` | `4xxx:4077` |
| 19 | `74HC283` | 74HC283 4-Bit Adder | logic_ic | `U` | `74xx:74LS283` |
| 20 | `74HC32` | 74HC32 Quad OR Gate | logic_ic | `U` | `74xx:74LS32` |
| 21 | `74HC595_SHIFT_REGISTER` | 74HC595 Shift Register | logic_ic | `U` | `74xx:74HC595` |
| 22 | `74HC74` | 74HC74 Dual D Flip-Flop | logic_ic | `U` | `74xx:74HC74` |
| 23 | `74HC76` | 74HC76 Dual JK Flip-Flop | logic_ic | `U` | `74xx:74LS76` |
| 24 | `74HC85` | 74HC85 4-Bit Comparator | logic_ic | `U` | `74xx:74HC85` |
| 25 | `74HC86` | 74HC86 Quad XOR Gate | logic_ic | `U` | `74xx:74HC86` |
| 26 | `7SEGCOMA` | 7-Segment Common Anode | display | `DS` | `Display_Character:KCSA02-107` |
| 27 | `7SEGCOMK` | 7-Segment Common Cathode | display | `DS` | `Display_Character:KCSC02-107` |
| 28 | `ACS712` | ACS712 Current Sensor | sensor | `U` | `Sensor_Current:ACS712xLCTR-20A` |
| 29 | `ARDUINO_NANO` | Arduino Nano | microcontroller_module | `A` | `MCU_Module:Arduino_Nano_v3.x` |
| 30 | `AUDIO_INPUT_JACK` | Audio Input Jack | connector | `J` | `Connector_Audio:AudioJack3` |
| 31 | `AUDIO_JACK` | Audio Jack | connector | `J` | `Connector_Audio:AudioJack3` |
| 32 | `BC547` | BC547 NPN Transistor | bjt | `Q` | `Transistor_BJT:BC547` |
| 33 | `BME280` | BME280 Sensor | sensor | `U` | `Sensor:BME280` |
| 34 | `BOOT_PUSH_BUTTON` | BOOT Push Button | switch | `SW` | `Switch:SW_Push` |
| 35 | `BRIDGE_RECTIFIER` | Bridge Rectifier | diode_bridge | `BR` | `Device:D_Bridge_+-AA` |
| 36 | `BS170` | BS170 NMOS | mosfet | `Q` | `Transistor_FET:BS170` |
| 37 | `BZX55C5` | BZX55C5 Zener Diode | zener_diode | `D` | `Device:D_Zener` |
| 38 | `BZX79C5` | BZX79C5 Zener Diode | zener_diode | `D` | `Device:D_Zener` |
| 39 | `CAN_TERMINAL` | CAN Terminal | terminal | `J` | `Connector:Screw_Terminal_01x03` |
| 40 | `CAP` | Capacitor | capacitor | `C` | `Device:C` |
| 41 | `CAPACITOR` | Capacitor | capacitor | `C` | `Device:C` |
| 42 | `CAP_ELEC` | Electrolytic Capacitor | capacitor | `C` | `Device:C_Polarized` |
| 43 | `CARD_DETECT_SWITCH` | Card Detect Switch | switch | `SW` | `Switch:SW_SPST` |
| 44 | `CD4007` | CD4007 CMOS Array | logic_ic | `U` | `Transistor_FET:Q_Dual_NMOS_PMOS_G1S2G2D2S1D1` |
| 45 | `CH340` | CH340 USB-UART | interface_ic | `U` | `Interface_USB:CH340G` |
| 46 | `CHARGING_LED` | Charging LED | indicator | `D` | `Device:LED` |
| 47 | `CHIP_SELECT_JUMPER` | Chip Select Jumper | jumper | `JP` | `Jumper:Jumper_2_Open` |
| 48 | `COIN_CELL_HOLDER` | Coin Cell Holder | battery_holder | `BT` | `Device:Battery_Cell` |
| 49 | `CP2102` | CP2102 USB-UART IC | interface_ic | `U` | `Interface_USB:CP2102N-Axx-xQFN28` |
| 50 | `CP_100UF` | 100uF Electrolytic Capacitor | capacitor | `C` | `Device:C_Polarized` |
| 51 | `CR2032_BATTERY` | CR2032 Battery | battery | `BT` | `Device:Battery_Cell` |
| 52 | `CRYSTAL_16MHZ` | 16MHz Crystal | crystal | `Y` | `Device:Crystal` |
| 53 | `CRYSTAL_OSCILLATOR_CAN` | Crystal Oscillator | crystal | `Y` | `Device:Crystal` |
| 54 | `CSOURCE` | Current Source | source | `I` | `Simulation_SPICE:IDC` |
| 55 | `C_100NF_CERAMIC` | 100nF Ceramic Capacitor | capacitor | `C` | `Device:C` |
| 56 | `C_100NF_FLASH` | 100nF Capacitor | capacitor | `C` | `Device:C` |
| 57 | `C_22PF_X1` | 22pF Capacitor x1 | capacitor | `C` | `Device:C` |
| 58 | `C_22PF_X2` | 22pF Capacitor x2 | capacitor | `C` | `Device:C` |
| 59 | `DC_BARREL_JACK` | DC Barrel Jack | connector | `J` | `Connector:Barrel_Jack` |
| 60 | `DC_MOTOR` | DC Motor | motor | `M` | `Motor:Motor_DC` |
| 61 | `DECOUPLING_CAPACITOR` | Decoupling Capacitor | capacitor | `C` | `Device:C` |
| 62 | `DECOUPLING_CAPACITOR_SD` | Decoupling Capacitor | capacitor | `C` | `Device:C` |
| 63 | `DIODE` | Diode | diode | `D` | `Device:D` |
| 64 | `DIP_SWITCH` | DIP Switch | switch | `SW` | `Switch:SW_DIP_x08` |
| 65 | `DS3231` | DS3231 RTC | rtc_ic | `U` | `Timer_RTC:DS3231M` |
| 66 | `D_1N4007` | 1N4007 Diode | diode | `D` | `Diode:1N4007` |
| 67 | `EN_PUSH_BUTTON` | EN Push Button | switch | `SW` | `Switch:SW_Push` |
| 68 | `ESP32_WROOM` | ESP32-WROOM Module | wireless_module | `U` | `RF_Module:ESP32-WROOM-32` |
| 69 | `FEEDBACK_RESISTOR` | Feedback Resistor | resistor | `R` | `Device:R` |
| 70 | `FLYBACK_DIODE` | Flyback Diode | diode | `D` | `Device:D` |
| 71 | `FUSE` | Fuse | protection | `F` | `Device:Fuse` |
| 72 | `GND_SYMBOL` | Ground Symbol | power_symbol | `#PWR` | `power:GND` |
| 73 | `GROUND` | Ground | power_symbol | `#PWR` | `power:GND` |
| 74 | `HEADER_CONNECTOR` | Header Connector | header | `J` | `Connector_Generic:Conn_01x04` |
| 75 | `I2C_HEADER` | I2C Header | header | `J` | `Connector_Generic:Conn_01x04` |
| 76 | `INPUT_CAPACITOR` | Input Capacitor | capacitor | `C` | `Device:C` |
| 77 | `INPUT_CAPACITOR_BUCK` | Input Capacitor | capacitor | `C` | `Device:C_Polarized` |
| 78 | `IRLZ44N` | IRLZ44N MOSFET | mosfet | `Q` | `Transistor_FET:IRLZ44N` |
| 79 | `JST_CONNECTOR` | JST Connector | connector | `J` | `Connector_Generic:Conn_01x04` |
| 80 | `LED` | LED | indicator | `D` | `Device:LED` |
| 81 | `LED_ARRAY` | LED Array | indicator | `D` | `Connector_Generic:Conn_02x08_Odd_Even` |
| 82 | `LED_INDICATOR` | LED | indicator | `D` | `Device:LED` |
| 83 | `LEVEL_SHIFTER` | Level Shifter | interface_ic | `U` | `Logic_LevelTranslator:TXS0108EPW` |
| 84 | `LI_ION_BATTERY_CONNECTOR` | Li-Ion Battery Connector | connector | `J` | `Connector_Generic:Conn_01x02` |
| 85 | `LM2596` | LM2596 | buck_converter | `U` | `Regulator_Switching:LM2596S-ADJ` |
| 86 | `LM317` | LM317 Adjustable Regulator | regulator | `U` | `Regulator_Linear:LM317_TO-220` |
| 87 | `LM358` | LM358 Op-Amp | opamp | `U` | `Amplifier_Operational:LM358` |
| 88 | `LM393_COMPARATOR` | LM393 Comparator | comparator | `U` | `Comparator:LM393` |
| 89 | `LM741` | LM741 Op-Amp | opamp | `U` | `Amplifier_Operational:LM741` |
| 90 | `LM7805` | LM7805 Voltage Regulator | regulator | `U` | `Regulator_Linear:LM7805_TO220` |
| 91 | `MAX485` | MAX485 Transceiver | interface_ic | `U` | `Interface_UART:MAX485E` |
| 92 | `MCP2515` | MCP2515 CAN Controller | interface_ic | `U` | `Interface_CAN_LIN:MCP2515-xSO` |
| 93 | `MICRO_SD_SOCKET` | Micro SD Socket | connector | `J` | `Connector:Micro_SD_Card_Det1` |
| 94 | `MICRO_USB_CONNECTOR` | Micro USB Connector | connector | `J` | `Connector:USB_B_Micro` |
| 95 | `MOSFET` | MOSFET | mosfet | `Q` | `Transistor_FET:IRLZ44N` |
| 96 | `MOUNTING_HOLE` | Mounting Hole | mechanical | `H` | `Mechanical:MountingHole` |
| 97 | `NE555` | NE555 Timer | timer_ic | `U` | `Timer:NE555P` |
| 98 | `NMOS` | NMOS Transistor | mosfet | `Q` | `Transistor_FET:Q_NMOS_DGS` |
| 99 | `NPN` | NPN Transistor | bjt | `Q` | `Transistor_BJT:Q_NPN_BCE` |
| 100 | `OPAMP` | Op-Amp | opamp | `U` | `Amplifier_Operational:LM741` |
| 101 | `OUTPUT_CAPACITOR_BUCK` | Output Capacitor | capacitor | `C` | `Device:C_Polarized` |
| 102 | `OUTPUT_FILTER_CAPACITOR` | Output Filter Capacitor | capacitor | `C` | `Device:C` |
| 103 | `PAM8403` | PAM8403 Amplifier | audio_ic | `U` | `Amplifier_Audio:PAM8403D` |
| 104 | `PIN_HEADER` | Pin Header | header | `J` | `Connector_Generic:Conn_01x08` |
| 105 | `PNP` | PNP Transistor | bjt | `Q` | `Transistor_BJT:Q_PNP_BCE` |
| 106 | `POLYFUSE` | Polyfuse Resettable Fuse | protection | `F` | `Device:Polyfuse` |
| 107 | `POTENTIOMETER` | Potentiometer | potentiometer | `RV` | `Device:R_Potentiometer` |
| 108 | `POT_HG` | Potentiometer | potentiometer | `RV` | `Device:R_Potentiometer` |
| 109 | `POWER_INDUCTOR` | Power Inductor | inductor | `L` | `Device:L` |
| 110 | `POWER_LED` | Power LED | indicator | `D` | `Device:LED` |
| 111 | `PROGRAMMING_HEADER` | Programming Header | header | `J` | `Connector_Generic:Conn_01x14` |
| 112 | `PROTECTION_IC` | Protection IC | protection_ic | `U` | `Battery_Management:DW01A` |
| 113 | `PULLUP_RESISTOR_OLED` | Pull-up Resistor | resistor | `R` | `Device:R` |
| 114 | `PUSH_BUTTON` | Push Button | switch | `SW` | `Switch:SW_Push` |
| 115 | `PWM_HEADER` | PWM Header | header | `J` | `Connector_Generic:Conn_01x04` |
| 116 | `PWR_3V3` | +3V3 Power Symbol | power_symbol | `#PWR` | `power:+3V3` |
| 117 | `PWR_5V` | +5V Power Symbol | power_symbol | `#PWR` | `power:+5V` |
| 118 | `REALIND` | Inductor | inductor | `L` | `Device:L` |
| 119 | `RELAY` | Relay | relay | `K` | `Relay:Relay_SPDT` |
| 120 | `RELAY_5V` | 5V Relay | relay | `K` | `Relay:Relay_SPDT` |
| 121 | `RELAY_FLYBACK_DIODE` | Relay Flyback Diode | diode | `D` | `Device:D` |
| 122 | `RELAY_INDICATOR_LED` | Indicator LED | indicator | `D` | `Device:LED` |
| 123 | `RES` | Resistor | resistor | `R` | `Device:R` |
| 124 | `RESET_CAPACITOR` | Reset Capacitor | capacitor | `C` | `Device:C` |
| 125 | `RESISTOR` | Resistor | resistor | `R` | `Device:R` |
| 126 | `RESISTOR_NETWORK` | Resistor Network | resistor | `RN` | `Connector_Generic:Conn_02x08_Odd_Even` |
| 127 | `RS485_TERMINAL` | RS485 Terminal | terminal | `J` | `Connector:Screw_Terminal_01x03` |
| 128 | `RX_HEADER` | RX Header | header | `J` | `Connector_Generic:Conn_01x01` |
| 129 | `R_10K_PULLUP` | 10k Pull-up Resistor | resistor | `R` | `Device:R` |
| 130 | `R_120_CAN` | 120 ohm Termination Resistor | resistor | `R` | `Device:R` |
| 131 | `R_120_RS485` | 120 ohm Termination Resistor | resistor | `R` | `Device:R` |
| 132 | `R_220` | 220 ohm Resistor | resistor | `R` | `Device:R` |
| 133 | `R_4K7_PULLUP` | 4.7k Pull-up Resistor | resistor | `R` | `Device:R` |
| 134 | `SCHOTTKY_DIODE_BUCK` | Schottky Diode | diode | `D` | `Device:D_Schottky` |
| 135 | `SCL_PULLUP` | SCL Pull-up | resistor | `R` | `Device:R` |
| 136 | `SCREW_TERMINAL_2` | Screw Terminal 2-pin | terminal | `J` | `Connector:Screw_Terminal_01x02` |
| 137 | `SDA_PULLUP` | SDA Pull-up | resistor | `R` | `Device:R` |
| 138 | `SPEAKER` | Speaker | speaker | `LS` | `Device:Speaker` |
| 139 | `SPI_HEADER_FLASH` | SPI Header | header | `J` | `Connector_Generic:Conn_01x08` |
| 140 | `SPI_HEADER_SD` | SPI Header | header | `J` | `Connector_Generic:Conn_02x03_Odd_Even` |
| 141 | `SSD1306_OLED` | SSD1306 OLED | display | `DS` | `Display_Graphic:OLED-128O064D` |
| 142 | `SWITCH` | Switch | switch | `SW` | `Switch:SW_SPST` |
| 143 | `TERMINAL` | Terminal | terminal | `J` | `Connector_Generic:Conn_01x02` |
| 144 | `TERMINAL_BLOCK` | Terminal Block | terminal | `J` | `Connector:Screw_Terminal_01x02` |
| 145 | `TERMINAL_BLOCK_4` | Terminal Block 4-pin | terminal | `J` | `Connector:Screw_Terminal_01x04` |
| 146 | `TEST_POINT` | Test Point | testpoint | `TP` | `Connector:TestPoint` |
| 147 | `TJA1050` | TJA1050 CAN Transceiver | interface_ic | `U` | `Interface_CAN_LIN:SN65HVD1050D` |
| 148 | `TP4056` | TP4056 Charger IC | charger_ic | `U` | `Battery_Management:TP4056-42-ESOP8` |
| 149 | `TRANSFORMER` | Transformer | transformer | `T` | `Device:Transformer_1P_1S` |
| 150 | `TRIMMER_POTENTIOMETER` | Trimmer Potentiometer | potentiometer | `RV` | `Device:R_Potentiometer_Trim` |
| 151 | `TVS_DIODE_RS485` | TVS Protection Diode | protection | `D` | `Device:D_TVS` |
| 152 | `TX_HEADER` | TX Header | header | `J` | `Connector_Generic:Conn_01x01` |
| 153 | `UART_HEADER` | UART Header | header | `J` | `Connector_Generic:Conn_01x05` |
| 154 | `USB_CONNECTOR` | USB Connector | connector | `J` | `Connector:USB_B_Micro` |
| 155 | `USB_CONNECTOR_UART` | USB Connector | connector | `J` | `Connector:USB_B_Micro` |
| 156 | `USB_C_CONNECTOR` | USB Type-C Connector | connector | `J` | `Connector:USB_C_Receptacle_USB2.0_16P` |
| 157 | `VCC_SYMBOL` | VCC Power Symbol | power_symbol | `#PWR` | `power:VCC` |
| 158 | `VDC` | DC Voltage Source | source | `V` | `Simulation_SPICE:VDC` |
| 159 | `VOLUME_POTENTIOMETER` | Volume Potentiometer | potentiometer | `RV` | `Device:R_Potentiometer` |
| 160 | `VPULSE` | Pulse Voltage Source | source | `V` | `Simulation_SPICE:VPULSE` |
| 161 | `VSIN` | Sine Voltage Source | source | `V` | `Simulation_SPICE:VSIN` |
| 162 | `VSOURCE` | Voltage Source | source | `V` | `Simulation_SPICE:VDC` |
| 163 | `W25Q64` | W25Q64 Flash IC | memory_ic | `U` | `Memory_Flash:W25Q32JVSS` |

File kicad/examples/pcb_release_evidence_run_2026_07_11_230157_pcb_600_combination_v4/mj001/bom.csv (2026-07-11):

Refs | Value | Footprint | Qty | DNP
B1_D1 | LED |  | 1
B1_D2 | LED |  | 1
B1_D3 | LED |  | 1
B1_J1 | Power/IO Header 1x6 |  | 1
B1_J2 | Extra IO Header 1x6 |  | 1
B1_R1 | 220 ohm |  | 1
B1_R2 | 220 ohm |  | 1
B1_R3 | 220 ohm |  | 1
B1_R4 | 10k pulldown |  | 1
B1_R5 | 10k pulldown |  | 1
B1_SW1 | Push Button |  | 1
B1_SW2 | Push Button |  | 1
B1_U1 | Arduino Nano | Module:Arduino_Nano | 1
B2_C1 | Input capacitor |  | 1
B2_C2 | Input capacitor |  | 1
B2_C3 | Input capacitor |  | 1
B2_C4 | Input capacitor |  | 1
B2_C5 | Output/filter capacitor |  | 1
B2_C6 | Output/filter capacitor |  | 1
B2_C7 | Output/filter capacitor |  | 1
B2_C8 | Output/filter capacitor |  | 1
B2_D1 | Status LED |  | 1
B2_D2 | Status LED |  | 1
B2_J1 | Stereo input jack |  | 1
B2_J2 | Aux/test audio jack |  | 1
B2_R1 | Audio resistor |  | 1
B2_R2 | Audio resistor |  | 1
B2_R3 | Audio resistor |  | 1
B2_R4 | Audio resistor |  | 1
B2_R5 | Audio resistor |  | 1
B2_R6 | Audio resistor |  | 1
B2_R7 | Audio resistor |  | 1
B2_R8 | Audio resistor |  | 1
B2_RV1 | Potentiometer |  | 1
B2_RV2 | Potentiometer |  | 1
B2_RV3 | Potentiometer |  | 1
B2_SPK1 | Left speaker |  | 1
B2_SPK2 | Right speaker |  | 1
B2_U1A? | LM358 channel A |  | 1
B2_U1A? | LM358 channel A |  | 1
B2_U1A? | LM358 channel A |  | 1
B2_U1B? | LM358 channel B |  | 1
B2_U1B? | LM358 channel B |  | 1
B2_U1B? | LM358 channel B |  | 1
B2_U3 | PAM8403 | Package_SO:SOIC-16_3.9x9.9mm_P1.27mm | 1

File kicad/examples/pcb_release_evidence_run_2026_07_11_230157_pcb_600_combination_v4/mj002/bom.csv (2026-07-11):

Refs | Value | Footprint | Qty | DNP
B1_C1 | 100uF |  | 1
B1_C2 | 100nF |  | 1
B1_C3 | 100uF |  | 1
B1_C4 | 100nF |  | 1
B1_C5 | 100nF |  | 1
B1_D1 | 1N4007 | Diode_THT:D_DO-41_SOD81_P10.16mm_Horizontal | 1
B1_D2 | Power LED |  | 1
B1_F1 | Fuse |  | 1
B1_J1 | DC Barrel Jack |  | 1
B1_J2 | 5V Output |  | 1
B1_R1 | 1k |  | 1
B1_U1 | LM7805 | Package_TO_SOT_THT:TO-220-3_Vertical | 1
B2_C1 | 100nF |  | 1
B2_C2 | 100nF |  | 1
B2_C3 | 100nF |  | 1
B2_C4 | 100nF |  | 1
B2_D1 | LED |  | 1
B2_D2 | LED |  | 1
B2_D3 | LED |  | 1
B2_D4 | LED |  | 1
B2_D5 | LED |  | 1
B2_D6 | LED |  | 1
B2_D7 | LED |  | 1
B2_D8 | LED |  | 1
B2_DARR1 | LED array |  | 1
B2_DARR2 | LED array |  | 1
B2_J1 | Programming/control header |  | 1
B2_J2 | SPI header |  | 1
B2_R1 | Pullup resistor |  | 1
B2_R2 | Pullup resistor |  | 1
B2_R3 | Pullup resistor |  | 1
B2_R4 | Pullup resistor |  | 1
B2_R5 | Pullup resistor |  | 1
B2_R6 | Pullup resistor |  | 1
B2_R7 | Pullup resistor |  | 1
B2_R8 | Pullup resistor |  | 1
B2_RN1 | Resistor network |  | 1
B2_RN2 | Resistor network |  | 1
B2_RN3 | Resistor network |  | 1
B2_SW1 | DIP switch |  | 1
B2_SW2 | DIP switch |  | 1
B2_U1 | 74HC595 |  | 1
B2_U2 | 74HC595 |  | 1
B2_U3 | 74HC595 |  | 1

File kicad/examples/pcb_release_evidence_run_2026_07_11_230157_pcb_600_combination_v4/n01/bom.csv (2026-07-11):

Refs | Value | Footprint | Qty | DNP
C001_BME280 | BME280 Sensor | Package_LGA:Bosch_LGA-8_2.5x2.5mm_P0.65mm_ClockwisePinNumbering | 1
C001_BOOT_PUSH_BUTTON? | BOOT Push Button |  | 1
C001_CARD_DETECT_SWITCH? | Card Detect Switch |  | 1
C001_COIN_CELL_HOLDER? | Coin Cell Holder |  | 1
C001_CP2102 | CP2102 USB-UART IC | Package_DFN_QFN:QFN-28-1EP_5x5mm_P0.5mm_EP3.35x3.35mm | 1
C001_C_100NF_FLASH? | 100nF Capacitor |  | 1
C001_DECOUPLING_CAPACITOR_ESP? | 100nF |  | 1
C001_DECOUPLING_CAPACITOR_MAIN? | 100nF |  | 1
C001_DECOUPLING_CAPACITOR_SD? | Decoupling Capacitor |  | 1
C001_DS3231 | DS3231 RTC | Package_SO:SOIC-16W_7.5x10.3mm_P1.27mm | 1
C001_EN_PUSH_BUTTON? | EN Push Button |  | 1
C001_ESP32_WROOM? | ESP32-WROOM Module | RF_Module:ESP32-WROOM-32 | 1
C001_HEADER_CONNECTOR? | Programming Header |  | 1
C001_I2C_HEADER? | I2C Header |  | 1
C001_LED_INDICATOR? | LED |  | 1
C001_MICRO_SD_SOCKET? | Micro SD Socket |  | 1
C001_POWER_LED? | Power LED |  | 1
C001_PULLUP_RESISTOR_OLED? | Pull-up Resistor |  | 1
C001_PWR_3V3 | DC Voltage Source |  | 1
C001_RESET_CAPACITOR? | 100nF |  | 1
C001_RES_USB_CC1 | Resistor |  | 1
C001_RES_USB_CC2 | Resistor |  | 1
C001_R_10K_PULLUP_BOOT? | 10k |  | 1
C001_R_10K_PULLUP_EN? | 10k |  | 1
C001_R_10K_PULLUP_FLASH_HOLD? | 10k |  | 1
C001_R_10K_PULLUP_FLASH_WP? | 10k |  | 1
C001_R_10K_PULLUP_RTC? | 10k |  | 1
C001_R_10K_PULLUP_SD_CD? | 10k |  | 1
C001_R_220_PWR? | 220 ohm |  | 1
C001_R_220_STATUS? | 220 ohm |  | 1
C001_SCL_PULLUP? | SCL Pull-up |  | 1
C001_SDA_PULLUP? | SDA Pull-up |  | 1
C001_SSD1306_OLED? | SSD1306 OLED | Display:OLED-128O064D | 1
C001_TEST_POINT_DTR? | Test Point |  | 1
C001_TEST_POINT_GPIO34 | Test Point |  | 1
C001_TEST_POINT_GPIO35 | Test Point |  | 1
C001_TEST_POINT_GPIO36 | Test Point |  | 1
C001_TEST_POINT_GPIO39 | Test Point |  | 1
C001_TEST_POINT_RTS? | Test Point |  | 1
C001_USB_C_CONNECTOR? | USB Type-C Connector |  | 1
C001_W25Q64 | W25Q64 Flash IC | Package_SO:SOIC-8_5.3x5.3mm_P1.27mm | 1

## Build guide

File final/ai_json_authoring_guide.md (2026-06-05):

# AI JSON Authoring Guide

This file is for any AI that receives a circuit request or circuit drawing and must produce valid JSON for the Proteus generator.

The AI's job is not to generate `.pdsprj` files directly. The AI's job is to produce correct circuit JSON that follows:

```text
final/json_circuit_ir_spec.md
```

## Core principle

Convert the circuit into a graph.

```text
nodes = electrical junctions
components = edges between two nodes
```

Do not confuse visual branches with electrical nodes. A continuous wire with no component between its points is one node.

## Step-by-step interpretation process

### Step 1: Identify all continuous wires

Every continuous connected wire region with no component in between is one node.

Example:

```text
A left vertical bus that touches top, middle, and bottom horizontal wires is one node.
```

For the locked 6R example, that left bus is:

```text
N0
```

### Step 2: Identify each component

Each resistor is an edge between two nodes.

For each resistor, ask:

```text
What node is on side 1?
What node is on side 2?
```

Physical direction does not matter for resistors, but the JSON still uses a two-node ordered list for stable generation.

### Step 3: Assign short node labels

Use two-character labels only.

Recommended labels:

```text
V0, G0
N0, N1, N2, N3, N4
A1, A2, B1, B2, C1, C2
M0, Z0
```

For current power/ground endpoint generation:

```text
Use V0 with kind=power for power endpoints.
Use G0 with kind=ground for ground endpoints.
Put V0 on component.nodes[0] when it should connect to the shared power node; the generator keeps the resistor endpoint as $TERINPUT and emits one donor-derived $TERPOWER -> $TEROUTPUT(V0) bridge.
Put G0 on component.nodes[1] when it should become $TERGROUND.
```

Do not use long labels such as:

```text
GND, VCC, OUT, IN1, NODE1
```

until variable-length terminal labels are validated.

### Step 4: Assign resistor references

Use two-character refs.

For the first nine resistors:

```text
R1, R2, R3, R4, R5, R6, R7, R8, R9
```

For resistor ten onward in the fixed-width baseline:

```text
RA, RB, RC, RD, RE, RF, RG, RH, RI, RJ, RK, RL
```

Do not use `R10` in the current locked baseline.

### Step 5: Produce the JSON

The JSON must include:

```text
schema_version
generator_target
project
nodes
components
layout
metadata
```

## Corrected 6R example reasoning

Source drawing has:

```text
left vertical bus
one top horizontal resistor
one upper right vertical resistor
one middle horizontal resistor
one lower right vertical resistor
one second lower right vertical resistor
one bottom horizontal resistor
```

Correct nodes:

```text
N0 = left common bus
N1 = top-right junction after top resistor and before upper vertical resistor
N2 = middle-right junction after upper vertical resistor and after middle resistor
N3 = lower-middle right junction between lower vertical resistors
N4 = bottom-right junction after lower vertical stack and after bottom resistor
```

Correct components:

```text
R1: N0 - N1
R2: N1 - N2
R3: N0 - N2
R4: N2 - N3
R5: N3 - N4
R6: N0 - N4
```

Do not collapse N1, N2, N3, and N4 into one right-side node. They are separated by resistors.

## Common mistakes

### Mistake: Treating the entire right side as one node

Wrong:

```text
R1-R2 top path, R3 middle path, R4-R5-R6 bottom path all ending at M0
```

Why wrong:

```text
The right side is not one continuous wire. It contains resistors between junctions, so each segment between resistors is a different node.
```

### Mistake: Preserving visual shape instead of topology

The JSON must prioritize electrical topology first. Use `visual.orientation_hint` only after the endpoint nodes are correct.

Correct:

```text
R2 connects N1 to N2
```

Even if R2 appears vertical in the drawing.

For a locked vertical symbol, add:

```json
"visual": {"orientation_hint": "vertical"}
```

If the physical drawing needs a visible bus, rail, bridge link, or delta closure after the component nodes are correct, remember that production currently skips standalone `layout.visual_wires` until a VGDVC-safe donor is validated. Do not use visual wires to invent electrical connectivity that is not already represented by shared node ids.

### Mistake: Using long labels

Wrong:

```json
{"id": "GROUND"}
```

Correct for current baseline:

```json
{"id": "G0", "kind": "ground"}
```

Correct power endpoint:

```json
{"id": "V0", "kind": "power"}
```

### Mistake: Missing node declarations

Every node used by a component must appear in the `nodes` array.

## Required final AI answer format

When asked to convert a circuit into generator JSON, the AI should respond with:

```text
1. short topology explanation
2. node list
3. component list
4. final JSON
5. warnings/assumptions
```

The final JSON must be valid JSON only, with no comments inside it.

## Quality checklist for the AI

Before giving JSON, verify:

```text
all nodes are declared
all node labels are two characters
all resistor refs are two characters
all components have exactly two nodes
no hidden junction was collapsed through a resistor
topology matches the circuit, not merely the drawing shape
layout positions exist for every resistor
optional layout.visual_wires are only future drawing hints and will be skipped by production for now
V0 power endpoint, if used, is on nodes[0]
G0 ground endpoint, if used, is on nodes[1]
```

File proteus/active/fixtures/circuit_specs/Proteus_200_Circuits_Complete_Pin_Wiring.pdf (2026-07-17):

Proteus wiring specification - all placed component pins accounted for | Page 1

# Proteus Wiring Specifications

# 200 canonical circuits with complete component-to-pin connectivity

- This document is an implementation specification, not a theory guide.
- Each circuit uses generic Proteus primitives matching the earlier component-count workbook.
- For every placed component, every electrical pin is assigned to exactly one named net.
- To wire a circuit, place the listed components and join every pin appearing on the same net.
- Ground terminals, probes, oscilloscopes, meters, graph instruments, connectors and net labels are not counted as components.
- OPAMP is treated as one generic five-pin op-amp section: IN+, IN-, OUT, V+ and V-.
- LM317T physical pins are ADJ(1), OUT(2) and IN(3). POT-HG pins are 1, W and 3.
- A POT-HG used as a rheostat intentionally ties its wiper to one end; both pins are still explicitly accounted for.
- Source + and - pins are fully listed. Negative-rail VDC sources are oriented with + at GND and - at V-.

### Pin conventions

Proteus part | Pins used in this document
RES | 1, 2
CAP | 1, 2
CAP-ELEC | +, -
INDUCTOR | 1, 2
POT-HG | 1, W, 3
DIODE | A, K
ZENER | A, K
LED | A, K
NMOSFET | G, D, S
OPAMP | IN+, IN-, OUT, V+, V-
LM317T | ADJ(1), OUT(2), IN(3)
VDC | +, -
VSINE | +, -
VPULSE | +, -
IDC | +, -

Proteus wiring specification - all placed component pins accounted for | Page 2

# Circuit index

1. DC Series Resistor Circuit | 2. DC Parallel Resistor Circuit
3. Mixed Series-Parallel Resistor Network | 4. Resistor Voltage Divider
5. Loaded Voltage Divider | 6. Potentiometer Voltage Divider
7. Potentiometer Rheostat Circuit | 8. Wheatstone Bridge
9. Resistive Attenuator | 10. Resistor Current-Limiter Circuit
11. RC Charging Circuit | 12. RC Discharging Circuit
13. RC Delay-On Circuit | 14. RC Delay-Off Circuit
15. First-Order RC Low-Pass Filter | 16. First-Order RC High-Pass Filter
17. Two-Stage Passive RC Low-Pass Filter | 18. Two-Stage Passive RC High-Pass Filter
19. Passive RC Band-Pass Filter | 20. Twin-T RC Notch Filter
21. Bridged-T RC Notch Filter | 22. RC Phase-Shift Network
23. Passive RC Integrator | 24. Passive RC Differentiator
25. Capacitive Voltage Divider | 26. Capacitor Reservoir Filter
27. Supply Bypass Capacitor Circuit | 28. Power-Supply Decoupling Network
29. Electrolytic Smoothing Filter | 30. Capacitor Bleeder-Discharge Circuit
31. RL Charging Circuit | 32. RL Discharging Circuit
33. First-Order RL Low-Pass Filter | 34. First-Order RL High-Pass Filter
35. Series RLC Circuit | 36. Parallel RLC Circuit
37. Series RLC Resonant Circuit | 38. Parallel RLC Resonant Circuit
39. Series RLC Band-Pass Filter | 40. Parallel RLC Band-Stop Filter
41. LC Series Resonant Circuit | 42. LC Parallel Tank Circuit
43. L-Section LC Low-Pass Filter | 44. L-Section LC High-Pass Filter
45. Pi-Section LC Low-Pass Filter | 46. T-Section LC Low-Pass Filter
47. CLC Pi Power-Supply Filter | 48. CRC Pi Power-Supply Filter
49. RLC Damping Network | 50. Damped LC Step-Response Circuit
51. Half-Wave Rectifier | 52. Full-Wave Bridge Rectifier
53. Half-Wave Rectifier with Capacitor Filter | 54. Bridge Rectifier with Capacitor Filter
55. Bridge Rectifier with CRC Filter | 56. Bridge Rectifier with CLC Filter
57. Positive Series Diode Clipper | 58. Negative Series Diode Clipper
59. Positive Shunt Diode Clipper | 60. Negative Shunt Diode Clipper
61. Symmetrical Diode Clipper | 62. Biased Positive Diode Clipper
63. Biased Negative Diode Clipper | 64. Positive Diode Clamper
65. Negative Diode Clamper | 66. Biased Diode Clamper
67. Diode Peak Detector | 68. Diode Envelope Detector
69. Diode Charge-Pump Circuit | 70. Half-Wave Voltage Doubler
71. Full-Wave Voltage Doubler | 72. Diode Voltage Tripler
73. Four-Stage Cockcroft-Walton Multiplier | 74. Diode OR Gate
75. Diode AND Gate | 76. Diode Polarity-Selector Circuit
77. Bridge Polarity-Correction Circuit | 78. Series-Diode Reverse-Polarity Protection
79. Freewheel Diode Clamp | 80. NMOS Inductive-Load Switch with Flyback Diode
81. Diode-RC Snubber for an Inductive Load | 82. Zener Shunt Voltage Regulator
83. Zener Voltage-Reference Circuit | 84. Zener Overvoltage Clamp
85. Back-to-Back Zener AC Limiter | 86. Zener Level-Shifter Circuit
87. Resistor-Limited LED Indicator | 88. Anti-Parallel LED Polarity Indicator
89. Series LED String | 90. Parallel LED Branches with Ballast Resistors
91. NMOS Low-Side Switch | 92. Logic-Level NMOS LED Switch
93. NMOS Inductive-Load Driver | 94. NMOS Reverse-Polarity Protector
95. Back-to-Back NMOS Load Disconnect | 96. NMOS Source Follower
97. NMOS Common-Source Amplifier | 98. Source-Degenerated NMOS Amplifier
99. RC-Coupled NMOS Common-Source Amplifier | 100. NMOS Amplifier with Bypassed Source Resistor
101. NMOS Voltage-Controlled Resistor | 102. NMOS Constant-Current Sink
103. NMOS Constant-Current LED Sink | 104. Two-NMOS Current Mirror
105. NMOS Cascode Current Mirror | 106. NMOS Amplifier with Active NMOS Load
107. NMOS Cascode Amplifier | 108. Two-Stage NMOS Amplifier
109. Resistor-Load NMOS Inverter | 110. Diode-Connected-Load NMOS Inverter
111. NMOS NAND Gate | 112. NMOS NOR Gate
113. NMOS Open-Drain Output | 114. NMOS Bidirectional Analog Switch
115. NMOS Level-Shifter Circuit | 116. RC-Delayed NMOS Switch
117. NMOS Soft-Start Load Switch | 118. NMOS LED Fade Circuit
119. NMOS PWM LED Dimmer | 120. NMOS Pulse Driver
121. NMOS Inductor Pulse Driver | 122. NMOS Capacitor-Discharge Switch
123. NMOS Gate Pull-Down Discharge Circuit | 124. NMOS Gate-Charge Test Circuit
125. NMOS Transfer-Characteristic Test Circuit | 126. NMOS Output-Characteristic Test Circuit
127. NMOS Threshold-Voltage Test Circuit | 128. NMOS On-Resistance Test Circuit
129. NMOS Body-Diode Test Circuit | 130. NMOS Switching-Loss Test Circuit
131. Op-Amp Voltage Follower | 132. Op-Amp Non-Inverting Amplifier
133. Op-Amp Inverting Amplifier | 134. Potentiometer-Controlled Inverting Amplifier
135. Potentiometer-Controlled Non-Inverting Amplifier | 136. Op-Amp Summing Amplifier
137. Op-Amp Averaging Amplifier | 138. Op-Amp Difference Amplifier

Proteus wiring specification - all placed component pins accounted for | Page 3
139. Three-Op-Amp Instrumentation Amplifier | 140. Differential-to-Single-Ended Amplifier
141. AC-Coupled Inverting Amplifier | 142. AC-Coupled Non-Inverting Amplifier
143. Op-Amp Transimpedance Amplifier | 144. Op-Amp Voltage-to-Current Converter
145. Howland Current Pump | 146. Op-Amp Precision Current Source
147. Op-Amp Precision Current Sink | 148. Op-Amp Comparator
149. Op-Amp Zero-Crossing Detector | 150. Op-Amp Level Detector
151. Dual-Op-Amp Window Comparator | 152. Inverting Schmitt Trigger
153. Non-Inverting Schmitt Trigger | 154. Precision Half-Wave Rectifier
155. Precision Full-Wave Rectifier | 156. Op-Amp Absolute-Value Circuit
157. Op-Amp Peak Detector | 158. Op-Amp Active Clamp
159. Op-Amp Diode Limiter | 160. Ideal Op-Amp Integrator
161. Practical Op-Amp Integrator | 162. Ideal Op-Amp Differentiator
163. Practical Op-Amp Differentiator | 164. First-Order Active Low-Pass Filter
165. First-Order Active High-Pass Filter | 166. Sallen-Key Low-Pass Filter
167. Sallen-Key High-Pass Filter | 168. Multiple-Feedback Low-Pass Filter
169. Multiple-Feedback High-Pass Filter | 170. Active Band-Pass Filter
171. Active Notch Filter | 172. Active All-Pass Filter
173. State-Variable Filter | 174. Wien-Bridge Oscillator
175. Op-Amp Phase-Shift Oscillator | 176. Op-Amp Relaxation Oscillator
177. Op-Amp Square-Wave Generator | 178. Op-Amp Triangle-Wave Generator
179. Op-Amp Sawtooth-Wave Generator | 180. Op-Amp LED Level Indicator
181. LM317 Adjustable Voltage Regulator | 182. LM317 Fixed 5 V Regulator
183. LM317 Fixed 12 V Regulator | 184. LM317 Constant-Current Source
185. LM317 Constant-Current LED Driver | 186. LM317 Trickle Battery Charger
187. LM317 Current-Limited Battery Charger | 188. LM317 Ripple-Rejection-Enhanced Regulator
189. LM317 Slow-Start Voltage Regulator | 190. LM317 Reverse-Discharge-Protected Regulator
191. Op-Amp-Controlled NMOS Electronic Load | 192. Op-Amp-Controlled NMOS Linear Regulator
193. Zener-Referenced Op-Amp NMOS Regulator | 194. Zener Comparator NMOS Overvoltage Cutoff
195. Op-Amp NMOS Undervoltage Lockout | 196. Op-Amp NMOS Electronic Fuse
197. Open-Loop NMOS Buck Converter | 198. Open-Loop NMOS Boost Converter
199. Open-Loop NMOS Inverting Buck-Boost Converter | 200. Open-Loop NMOS SEPIC Converter

Proteus wiring specification - all placed component pins accounted for | Page 4

# Circuit 1: DC Series Resistor Circuit

Proteus rule: pins shown on the same named net are connected together. GND is a Proteus ground terminal and is not included in the component count.

### Resistor: 2 | Voltage source: 1 | Total: 3

Ref | Proteus part | Value / setting | Every pin -> net
V1 | VDC | 12 V | +=VIN; -=GND
R1 | RES | 1 kOhm | 1=VIN; 2=N1
R2 | RES | 2.2 kOhm | 1=N1; 2=GND

### Net connection list

Net | Pins to join electrically
GND | V1.-, R2.2
VIN | V1.+, R1.1
N1 | R1.2, R2.1

PIN AUDIT: PASS - 6 of 6 placed component pins assigned to nets; 0 unassigned pins.

Proteus wiring specification - all placed component pins accounted for | Page 5

# Circuit 2: DC Parallel Resistor Circuit

### Resistor: 3 | Voltage source: 1 | Total: 4

Ref | Proteus part | Value / setting | Every pin -> net
V1 | VDC | 12 V | +=VIN; -=GND
R1 | RES | 1 kOhm | 1=VIN; 2=GND
R2 | RES | 2.2 kOhm | 1=VIN; 2=GND
R3 | RES | 4.7 kOhm | 1=VIN; 2=GND

### Net connection list

Net | Pins to join electrically
GND | V1.-, R1.2, R2.2, R3.2
VIN | V1.+, R1.1, R2.1, R3.1

PIN AUDIT: PASS - 8 of 8 placed component pins assigned to nets; 0 unassigned pins.

Proteus wiring specification - all placed component pins accounted for | Page 6

# Circuit 3: Mixed Series-Parallel Resistor Network

### Resistor: 4 | Voltage source: 1 | Total: 5

Ref | Proteus part | Value / setting | Every pin -> net
V1 | VDC | 12 V | +=VIN; -=GND
R1 | RES | 1 kOhm | 1=VIN; 2=N1
R2 | RES | 2.2 kOhm | 1=N1; 2=N2
R3 | RES | 3.3 kOhm | 1=N1; 2=N2
R4 | RES | 1 kOhm | 1=N2; 2=GND

### Net connection list

Net | Pins to join electrically
GND | V1.-, R4.2
VIN | V1.+, R1.1
N1 | R1.2, R2.1, R3.1
N2 | R2.2, R3.2, R4.1

PIN AUDIT: PASS - 10 of 10 placed component pins assigned to nets; 0 unassigned pins.

Proteus wiring specification - all placed component pins accounted for | Page 7

# Circuit 4: Resistor Voltage Divider

### Resistor: 2 | Voltage source: 1 | Total: 3

Ref | Proteus part | Value / setting | Every pin -> net
V1 | VDC | 12 V | +=VIN; -=GND
R1 | RES | 10 kOhm | 1=VIN; 2=VOUT
R2 | RES | 10 kOhm | 1=VOUT; 2=GND

### Net connection list

Net | Pins to join electrically
GND | V1.-, R2.2
VIN | V1.+, R1.1
VOUT | R1.2, R2.1

PIN AUDIT: PASS - 6 of 6 placed component pins assigned to nets; 0 unassigned pins.

Proteus wiring specification - all placed component pins accounted for | Page 8

# Circuit 5: Loaded Voltage Divider

### Resistor: 3 | Voltage source: 1 | Total: 4

Ref | Proteus part | Value / setting | Every pin -> net
V1 | VDC | 12 V | +=VIN; -=GND
R1 | RES | 10 kOhm | 1=VIN; 2=VOUT
R2 | RES | 10 kOhm | 1=VOUT; 2=GND
RL | RES | 10 kOhm | 1=VOUT; 2=GND

### Net connection list

Net | Pins to join electrically
GND | V1.-, R2.2, RL.2
VIN | V1.+, R1.1
VOUT | R1.2, R2.1, RL.1

PIN AUDIT: PASS - 8 of 8 placed component pins assigned to nets; 0 unassigned pins.

Proteus wiring specification - all placed component pins accounted for | Page 9

# Circuit 6: Potentiometer Voltage Divider

### POT-HG: 1 | Voltage source: 1 | Total: 2

Ref | Proteus part | Value / setting | Every pin -> net
V1 | VDC | 12 V | +=VIN; -=GND
RV1 | POT-HG | 10 kOhm | 1=VIN; W=VOUT; 3=GND

### Net connection list

Net | Pins to join electrically
GND | V1.-, RV1.3
VIN | V1.+, RV1.1
VOUT | RV1.W

PIN AUDIT: PASS - 5 of 5 placed component pins assigned to nets; 0 unassigned pins.

Proteus wiring specification - all placed component pins accounted for | Page 10

# Circuit 7: Potentiometer Rheostat Circuit

### Resistor: 1 | POT-HG: 1 | Voltage source: 1 | Total: 3

Ref | Proteus part | Value / setting | Every pin -> net
V1 | VDC | 12 V | +=VIN; -=GND
RV1 | POT-HG | 10 kOhm | 1=VIN; W=N1; 3=N1
RL | RES | 1 kOhm | 1=N1; 2=GND

### Net connection list

Net | Pins to join electrically
GND | V1.-, RL.2
VIN | V1.+, RV1.1
N1 | RV1.W, RV1.3, RL.1

PIN AUDIT: PASS - 7 of 7 placed component pins assigned to nets; 0 unassigned pins.

Proteus wiring specification - all placed component pins accounted for | Page 11

# Circuit 8: Wheatstone Bridge

### Resistor: 4 | Voltage source: 1 | Total: 5

Ref | Proteus part | Value / setting | Every pin -> net
V1 | VDC | 10 V | +=VIN; -=GND
R1 | RES | 1 kOhm | 1=VIN; 2=NL
R2 | RES | 1 kOhm | 1=NL; 2=GND
R3 | RES | 1 kOhm | 1=VIN; 2=NR
R4 | RES | 1.2 kOhm | 1=NR; 2=GND

### Net connection list

Net | Pins to join electrically
GND | V1.-, R2.2, R4.2
VIN | V1.+, R1.1, R3.1
NL | R1.2, R2.1
NR | R3.2, R4.1

PIN AUDIT: PASS - 10 of 10 placed component pins assigned to nets; 0 unassigned pins.

Proteus wiring specification - all placed component pins accounted for | Page 12

# Circuit 9: Resistive Attenuator

### Resistor: 2 | Voltage source: 1 | Total: 3

Ref | Proteus part | Value / setting | Every pin -> net
V1 | VSINE | 10 Vpk, 1 kHz | +=VIN; -=GND
R1 | RES | 9 kOhm | 1=VIN; 2=VOUT
R2 | RES | 1 kOhm | 1=VOUT; 2=GND

### Net connection list

Net | Pins to join electrically
GND | V1.-, R2.2
VIN | V1.+, R1.1
VOUT | R1.2, R2.1

PIN AUDIT: PASS - 6 of 6 placed component pins assigned to nets; 0 unassigned pins.

Proteus wiring specification - all placed component pins accounted for | Page 13

# Circuit 10: Resistor Current-Limiter Circuit

### Resistor: 2 | Voltage source: 1 | Total: 3

Ref | Proteus part | Value / setting | Every pin -> net
V1 | VDC | 12 V | +=VIN; -=GND
R1 | RES | 1 kOhm | 1=VIN; 2=VOUT
RL | RES | 100 Ohm | 1=VOUT; 2=GND

### Net connection list

Net | Pins to join electrically
GND | V1.-, RL.2
VIN | V1.+, R1.1
VOUT | R1.2, RL.1

PIN AUDIT: PASS - 6 of 6 placed component pins assigned to nets; 0 unassigned pins.

Proteus wiring specification - all placed component pins accounted for | Page 14

# Circuit 11: RC Charging Circuit

### Resistor: 1 | Capacitor: 1 | Voltage source: 1 | Total: 3

Ref | Proteus part | Value / setting | Every pin -> net
V1 | VPULSE | 0-10 V, 1 s period | +=VIN; -=GND
R1 | RES | 10 kOhm | 1=VIN; 2=VOUT
C1 | CAP | 100 uF | 1=VOUT; 2=GND

### Net connection list

Net | Pins to join electrically
GND | V1.-, C1.2
VIN | V1.+, R1.1
VOUT | R1.2, C1.1

PIN AUDIT: PASS - 6 of 6 placed component pins assigned to nets; 0 unassigned pins.

Proteus wiring specification - all placed component pins accounted for | Page 15

# Circuit 12: RC Discharging Circuit

### Resistor: 1 | Capacitor: 1 | Voltage source: 1 | Total: 3

Ref | Proteus part | Value / setting | Every pin -> net
V1 | VPULSE | 10-0 V, 1 s period | +=VIN; -=GND
R1 | RES | 10 kOhm | 1=VIN; 2=VOUT
C1 | CAP | 100 uF | 1=VOUT; 2=GND

### Net connection list

Net | Pins to join electrically
GND | V1.-, C1.2
VIN | V1.+, R1.1
VOUT | R1.2, C1.1

PIN AUDIT: PASS - 6 of 6 placed component pins assigned to nets; 0 unassigned pins.

Proteus wiring specification - all placed component pins accounted for | Page 16

# Circuit 13: RC Delay-On Circuit

### Resistor: 2 | Capacitor: 1 | LED: 1 | NMOSFET: 1 | Voltage source: 1 | Total: 6

Ref | Proteus part | Value / setting | Every pin -> net
V1 | VDC | 12 V | +=VDD; -=GND
R1 | RES | 100 kOhm | 1=VDD; 2=GATE
C1 | CAP | 10 uF | 1=GATE; 2=GND
Q1 | NMOSFET | Generic NMOS | G=GATE; D=DRAIN; S=GND
R2 | RES | 1 kOhm | 1=VDD; 2=LED_A
LED1 | LED | RED | A=LED_A; K=DRAIN

### Net connection list

Net | Pins to join electrically
GND | V1.-, C1.2, Q1.S
VDD | V1.+, R1.1, R2.1
DRAIN | Q1.D, LED1.K
GATE | R1.2, C1.1, Q1.G
LED_A | R2.2, LED1.A

PIN AUDIT: PASS - 13 of 13 placed component pins assigned to nets; 0 unassigned pins.

Proteus wiring specification - all placed component pins accounted for | Page 17

# Circuit 14: RC Delay-Off Circuit

Resistor: 2 | Capacitor: 1 | Diode: 1 | LED: 1 | NMOSFET: 1 | Voltage source: 1 | Total: 7
Ref | Proteus part | Value / setting | Every pin -> net
V1 | VPULSE | 0-12 V, slow on/off | +=VDD; -=GND
R1 | RES | 100 kOhm | 1=VDD; 2=GATE
C1 | CAP | 10 uF | 1=GATE; 2=GND
D1 | DIODE | 1N4148 | A=VDD; K=GATE
Q1 | NMOSFET | Generic NMOS | G=GATE; D=DRAIN; S=GND
R2 | RES | 1 kOhm | 1=VDD; 2=LED_A
LED1 | LED | RED | A=LED_A; K=DRAIN

### Net connection list

Net | Pins to join electrically
GND | V1.-, C1.2, Q1.S
VDD | V1.+, R1.1, D1.A, R2.1
DRAIN | Q1.D, LED1.K
GATE | R1.2, C1.1, D1.K, Q1.G
LED_A | R2.2, LED1.A

PIN AUDIT: PASS - 15 of 15 placed component pins assigned to nets; 0 unassigned pins.

Proteus wiring specification - all placed component pins accounted for | Page 18

# Circuit 15: First-Order RC Low-Pass Filter

### Resistor: 1 | Capacitor: 1 | Voltage source: 1 | Total: 3

Ref | Proteus part | Value / setting | Every pin -> net
V1 | VSINE | 1 Vpk, 1 kHz | +=VIN; -=GND
R1 | RES | 1.59 kOhm | 1=VIN; 2=VOUT
C1 | CAP | 100 nF | 1=VOUT; 2=GND

### Net connection list

Net | Pins to join electrically
GND | V1.-, C1.2
VIN | V1.+, R1.1
VOUT | R1.2, C1.1

PIN AUDIT: PASS - 6 of 6 placed component pins assigned to nets; 0 unassigned pins.

Proteus wiring specification - all placed component pins accounted for | Page 19

# Circuit 16: First-Order RC High-Pass Filter

### Resistor: 1 | Capacitor: 1 | Voltage source: 1 | Total: 3

Ref | Proteus part | Value / setting | Every pin -> net
V1 | VSINE | 1 Vpk, 1 kHz | +=VIN; -=GND
C1 | CAP | 100 nF | 1=VIN; 2=VOUT
R1 | RES | 1.59 kOhm | 1=VOUT; 2=GND

### Net connection list

Net | Pins to join electrically
GND | V1.-, R1.2
VIN | V1.+, C1.1
VOUT | C1.2, R1.1

PIN AUDIT: PASS - 6 of 6 placed component pins assigned to nets; 0 unassigned pins.

Proteus wiring specification - all placed component pins accounted for | Page 20

# Circuit 17: Two-Stage Passive RC Low-Pass Filter

### Resistor: 2 | Capacitor: 2 | Voltage source: 1 | Total: 5

Ref | Proteus part | Value / setting | Every pin -> net
V1 | VSINE | 1 Vpk, 1 kHz | +=VIN; -=GND
R1 | RES | 1 kOhm | 1=VIN; 2=N1
C1 | CAP | 100 nF | 1=N1; 2=GND
R2 | RES | 1 kOhm | 1=N1; 2=VOUT
C2 | CAP | 100 nF | 1=VOUT; 2=GND

### Net connection list

Net | Pins to join electrically
GND | V1.-, C1.2, C2.2
VIN | V1.+, R1.1
N1 | R1.2, C1.1, R2.1
VOUT | R2.2, C2.1

PIN AUDIT: PASS - 10 of 10 placed component pins assigned to nets; 0 unassigned pins.

Proteus wiring specification - all placed component pins accounted for | Page 21

# Circuit 18: Two-Stage Passive RC High-Pass Filter

### Resistor: 2 | Capacitor: 2 | Voltage source: 1 | Total: 5

Ref | Proteus part | Value / setting | Every pin -> net
V1 | VSINE | 1 Vpk, 1 kHz | +=VIN; -=GND
C1 | CAP | 100 nF | 1=VIN; 2=N1
R1 | RES | 1 kOhm | 1=N1; 2=GND
C2 | CAP | 100 nF | 1=N1; 2=VOUT
R2 | RES | 1 kOhm | 1=VOUT; 2=GND

### Net connection list

Net | Pins to join electrically
GND | V1.-, R1.2, R2.2
VIN | V1.+, C1.1
N1 | C1.2, R1.1, C2.1
VOUT | C2.2, R2.1

PIN AUDIT: PASS - 10 of 10 placed component pins assigned to nets; 0 unassigned pins.

Proteus wiring specification - all placed component pins accounted for | Page 22

# Circuit 19: Passive RC Band-Pass Filter

### Resistor: 2 | Capacitor: 2 | Voltage source: 1 | Total: 5

Ref | Proteus part | Value / setting | Every pin -> net
V1 | VSINE | 1 Vpk, 1 kHz | +=VIN; -=GND
C1 | CAP | 100 nF | 1=VIN; 2=N1
R1 | RES | 10 kOhm | 1=N1; 2=GND
R2 | RES | 1 kOhm | 1=N1; 2=VOUT
C2 | CAP | 10 nF | 1=VOUT; 2=GND

### Net connection list

Net | Pins to join electrically
GND | V1.-, R1.2, C2.2
VIN | V1.+, C1.1
N1 | C1.2, R1.1, R2.1
VOUT | R2.2, C2.1

PIN AUDIT: PASS - 10 of 10 placed component pins assigned to nets; 0 unassigned pins.

Proteus wiring specification - all placed component pins accounted for | Page 23

# Circuit 20: Twin-T RC Notch Filter

### Resistor: 3 | Capacitor: 3 | Voltage source: 1 | Total: 7

Ref | Proteus part | Value / setting | Every pin -> net
V1 | VSINE | 1 Vpk, 1 kHz | +=VIN; -=GND
R1 | RES | 10 kOhm | 1=VIN; 2=NRA
R2 | RES | 10 kOhm | 1=NRA; 2=VOUT
C3 | CAP | 20 nF | 1=NRA; 2=GND
C1 | CAP | 10 nF | 1=VIN; 2=NCA
C2 | CAP | 10 nF | 1=NCA; 2=VOUT
R3 | RES | 5 kOhm | 1=NCA; 2=GND

### Net connection list

Net | Pins to join electrically
GND | V1.-, C3.2, R3.2
VIN | V1.+, R1.1, C1.1
NCA | C1.2, C2.1, R3.1
NRA | R1.2, R2.1, C3.1
VOUT | R2.2, C2.2

PIN AUDIT: PASS - 14 of 14 placed component pins assigned to nets; 0 unassigned pins.

Proteus wiring specification - all placed component pins accounted for | Page 24

# Circuit 21: Bridged-T RC Notch Filter

### Resistor: 4 | Capacitor: 2 | Voltage source: 1 | Total: 7

Ref | Proteus part | Value / setting | Every pin -> net
V1 | VSINE | 1 Vpk, 1 kHz | +=VIN; -=GND
R1 | RES | 10 kOhm | 1=VIN; 2=N1
R2 | RES | 10 kOhm | 1=N1; 2=VOUT
R3 | RES | 20 kOhm | 1=VIN; 2=VOUT
R4 | RES | 5 kOhm | 1=N1; 2=GND
C1 | CAP | 10 nF | 1=VIN; 2=N1
C2 | CAP | 10 nF | 1=N1; 2=VOUT

### Net connection list

Net | Pins to join electrically
GND | V1.-, R4.2
VIN | V1.+, R1.1, R3.1, C1.1
N1 | R1.2, R2.1, R4.1, C1.2, C2.1
VOUT | R2.2, R3.2, C2.2

PIN AUDIT: PASS - 14 of 14 placed component pins assigned to nets; 0 unassigned pins.

Proteus wiring specification - all placed component pins accounted for | Page 25

# Circuit 22: RC Phase-Shift Network

### Resistor: 3 | Capacitor: 3 | Voltage source: 1 | Total: 7

Ref | Proteus part | Value / setting | Every pin -> net
V1 | VSINE | 1 Vpk, 1 kHz | +=VIN; -=GND
C1 | CAP | 10 nF | 1=VIN; 2=N1
R1 | RES | 10 kOhm | 1=N1; 2=GND
C2 | CAP | 10 nF | 1=N1; 2=N2
R2 | RES | 10 kOhm | 1=N2; 2=GND
C3 | CAP | 10 nF | 1=N2; 2=VOUT
R3 | RES | 10 kOhm | 1=VOUT; 2=GND

### Net connection list

Net | Pins to join electrically
GND | V1.-, R1.2, R2.2, R3.2
VIN | V1.+, C1.1
N1 | C1.2, R1.1, C2.1
N2 | C2.2, R2.1, C3.1
VOUT | C3.2, R3.1

PIN AUDIT: PASS - 14 of 14 placed component pins assigned to nets; 0 unassigned pins.

Proteus wiring specification - all placed component pins accounted for | Page 26

# Circuit 23: Passive RC Integrator

### Resistor: 1 | Capacitor: 1 | Voltage source: 1 | Total: 3

Ref | Proteus part | Value / setting | Every pin -> net
V1 | VPULSE | 0-5 V, 10 kHz | +=VIN; -=GND
R1 | RES | 10 kOhm | 1=VIN; 2=VOUT
C1 | CAP | 10 nF | 1=VOUT; 2=GND

### Net connection list

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

PIN AUDIT: PASS - 6 of 6 placed component pins assigned to nets; 0 unassigned pins.

Proteus wiring specification - all placed component pins accounted for | Page 27

# Circuit 24: Passive RC Differentiator

### Resistor: 1 | Capacitor: 1 | Voltage source: 1 | Total: 3

Ref | Proteus part | Value / setting | Every pin -> net
V1 | VPULSE | 0-5 V, 1 kHz | +=VIN; -=GND
C1 | CAP | 10 nF | 1=VIN; 2=VOUT
R1 | RES | 1 kOhm | 1=VOUT; 2=GND

### Net connection list

Net | Pins to join electrically
GND | V1.-, R1.2
VIN | V1.+, C1.1
VOUT | C1.2, R1.1

PIN AUDIT: PASS - 6 of 6 placed component pins assigned to nets; 0 unassigned pins.

Proteus wiring specification - all placed component pins accounted for | Page 28

# Circuit 25: Capacitive Voltage Divider

### Capacitor: 2 | Voltage source: 1 | Total: 3

Ref | Proteus part | Value / setting | Every pin -> net
V1 | VSINE | 10 Vpk, 1 kHz | +=VIN; -=GND
C1 | CAP | 100 nF | 1=VIN; 2=VOUT
C2 | CAP | 100 nF | 1=VOUT; 2=GND

### Net connection list

Net | Pins to join electrically
GND | V1.-, C2.2
VIN | V1.+, C1.1
VOUT | C1.2, C2.1

PIN AUDIT: PASS - 6 of 6 placed component pins assigned to nets; 0 unassigned pins.

Proteus wiring specification - all placed component pins accounted for | Page 29

# Circuit 26: Capacitor Reservoir Filter

### Resistor: 1 | Electrolytic capacitor: 1 | Diode: 1 | Voltage source: 1 | Total: 4

Ref | Proteus part | Value / setting | Every pin -> net
V1 | VSINE | 12 Vrms, 50 Hz | +=AC; -=GND
D1 | DIODE | 1N4007 | A=AC; K=VOUT
C1 | CAP-ELEC | 1000 uF | +=VOUT; -=GND
RL | RES | 1 kOhm | 1=VOUT; 2=GND

### Net connection list

Net | Pins to join electrically
GND | V1.-, C1.-, RL.2
AC | V1.+, D1.A
VOUT | D1.K, C1.+, RL.1

PIN AUDIT: PASS - 8 of 8 placed component pins assigned to nets; 0 unassigned pins.

Proteus wiring specification - all placed component pins accounted for | Page 30

# Circuit 27: Supply Bypass Capacitor Circuit

### Resistor: 1 | Capacitor: 1 | Voltage source: 1 | Total: 3

Ref | Proteus part | Value / setting | Every pin -> net
V1 | VDC | 5 V | +=VDD; -=GND
RL | RES | 1 kOhm | 1=VDD; 2=GND
C1 | CAP | 100 nF | 1=VDD; 2=GND

### Net connection list

Net | Pins to join electrically
GND | V1.-, RL.2, C1.2
VDD | V1.+, RL.1, C1.1

PIN AUDIT: PASS - 6 of 6 placed component pins assigned to nets; 0 unassigned pins.

Proteus wiring specification - all placed component pins accounted for | Page 31

# Circuit 28: Power-Supply Decoupling Network

### Resistor: 2 | Capacitor: 1 | Electrolytic capacitor: 1 | Voltage source: 1 | Total: 5

Ref | Proteus part | Value / setting | Every pin -> net
V1 | VDC | 12 V | +=VIN; -=GND
RISO | RES | 10 Ohm | 1=VIN; 2=VDD
RL | RES | 1 kOhm | 1=VDD; 2=GND
C1 | CAP | 100 nF | 1=VDD; 2=GND
C2 | CAP-ELEC | 100 uF | +=VDD; -=GND

### Net connection list

Net | Pins to join electrically
GND | V1.-, RL.2, C1.2, C2.-
VDD | RISO.2, RL.1, C1.1, C2.+
VIN | V1.+, RISO.1

PIN AUDIT: PASS - 10 of 10 placed component pins assigned to nets; 0 unassigned pins.

Proteus wiring specification - all placed component pins accounted for | Page 32

# Circuit 29: Electrolytic Smoothing Filter

### Resistor: 1 | Electrolytic capacitor: 1 | Diode: 4 | Voltage source: 1 | Total: 7

Ref | Proteus part | Value / setting | Every pin -> net
V1 | VSINE | 12 Vrms, 50 Hz | +=AC1; -=AC2
D1 | DIODE | 1N4007 | A=AC1; K=VOUT
D2 | DIODE | 1N4007 | A=AC2; K=VOUT
D3 | DIODE | 1N4007 | A=GND; K=AC1
D4 | DIODE | 1N4007 | A=GND; K=AC2
C1 | CAP-ELEC | 1000 uF | +=VOUT; -=GND
RL | RES | 1 kOhm | 1=VOUT; 2=GND

### Net connection list

Net | Pins to join electrically
GND | D3.A, D4.A, C1.-, RL.2
AC1 | V1.+, D1.A, D3.K
AC2 | V1.-, D2.A, D4.K
VOUT | D1.K, D2.K, C1.+, RL.1

PIN AUDIT: PASS - 14 of 14 placed component pins assigned to nets; 0 unassigned pins.

Proteus wiring specification - all placed component pins accounted for | Page 33

# Circuit 30: Capacitor Bleeder-Discharge Circuit

### Resistor: 1 | Electrolytic capacitor: 1 | Voltage source: 1 | Total: 3

Ref | Proteus part | Value / setting | Every pin -> net
V1 | VDC | 12 V | +=VOUT; -=GND
C1 | CAP-ELEC | 1000 uF | +=VOUT; -=GND
RB | RES | 100 kOhm | 1=VOUT; 2=GND

### Net connection list

Net | Pins to join electrically
GND | V1.-, C1.-, RB.2
VOUT | V1.+, C1.+, RB.1

PIN AUDIT: PASS - 6 of 6 placed component pins assigned to nets; 0 unassigned pins.

Proteus wiring specification - all placed component pins accounted for | Page 34

# Circuit 31: RL Charging Circuit

### Resistor: 1 | Inductor: 1 | Voltage source: 1 | Total: 3

Ref | Proteus part | Value / setting | Every pin -> net
V1 | VPULSE | 0-10 V, 1 kHz | +=VIN; -=GND
R1 | RES | 100 Ohm | 1=VIN; 2=VOUT
L1 | INDUCTOR | 10 mH | 1=VOUT; 2=GND

### Net connection list

Net | Pins to join electrically
GND | V1.-, L1.2
VIN | V1.+, R1.1
VOUT | R1.2, L1.1

PIN AUDIT: PASS - 6 of 6 placed component pins assigned to nets; 0 unassigned pins.

Proteus wiring specification - all placed component pins accounted for | Page 35

# Circuit 32: RL Discharging Circuit

### Resistor: 1 | Inductor: 1 | Voltage source: 1 | Total: 3

Ref | Proteus part | Value / setting | Every pin -> net
V1 | VPULSE | 10-0 V, 1 kHz | +=VIN; -=GND
R1 | RES | 100 Ohm | 1=VIN; 2=VOUT
L1 | INDUCTOR | 10 mH | 1=VOUT; 2=GND

### Net connection list

Net | Pins to join electrically
GND | V1.-, L1.2
VIN | V1.+, R1.1
VOUT | R1.2, L1.1

PIN AUDIT: PASS - 6 of 6 placed component pins assigned to nets; 0 unassigned pins.

Proteus wiring specification - all placed component pins accounted for | Page 36

# Circuit 33: First-Order RL Low-Pass Filter

### Resistor: 1 | Inductor: 1 | Voltage source: 1 | Total: 3

Ref | Proteus part | Value / setting | Every pin -> net
V1 | VSINE | 1 Vpk, 1 kHz | +=VIN; -=GND
L1 | INDUCTOR | 10 mH | 1=VIN; 2=VOUT
R1 | RES | 100 Ohm | 1=VOUT; 2=GND

### Net connection list

Net | Pins to join electrically
GND | V1.-, R1.2
VIN | V1.+, L1.1
VOUT | L1.2, R1.1

PIN AUDIT: PASS - 6 of 6 placed component pins assigned to nets; 0 unassigned pins.

Proteus wiring specification - all placed component pins accounted for | Page 37

# Circuit 34: First-Order RL High-Pass Filter

### Resistor: 1 | Inductor: 1 | Voltage source: 1 | Total: 3

Ref | Proteus part | Value / setting | Every pin -> net
V1 | VSINE | 1 Vpk, 1 kHz | +=VIN; -=GND
R1 | RES | 100 Ohm | 1=VIN; 2=VOUT
L1 | INDUCTOR | 10 mH | 1=VOUT; 2=GND

### Net connection list

Net | Pins to join electrically
GND | V1.-, L1.2
VIN | V1.+, R1.1
VOUT | R1.2, L1.1

PIN AUDIT: PASS - 6 of 6 placed component pins assigned to nets; 0 unassigned pins.

Proteus wiring specification - all placed component pins accounted for | Page 38

# Circuit 35: Series RLC Circuit

### Resistor: 1 | Capacitor: 1 | Inductor: 1 | Voltage source: 1 | Total: 4

Ref | Proteus part | Value / setting | Every pin -> net
V1 | VSINE | 1 Vpk, 1 kHz | +=VIN; -=GND
R1 | RES | 100 Ohm | 1=VIN; 2=N1
L1 | INDUCTOR | 10 mH | 1=N1; 2=N2
C1 | CAP | 2.2 uF | 1=N2; 2=GND

### Net connection list

Net | Pins to join electrically
GND | V1.-, C1.2
VIN | V1.+, R1.1
N1 | R1.2, L1.1
N2 | L1.2, C1.1

PIN AUDIT: PASS - 8 of 8 placed component pins assigned to nets; 0 unassigned pins.

Proteus wiring specification - all placed component pins accounted for | Page 39

# Circuit 36: Parallel RLC Circuit

### Resistor: 1 | Capacitor: 1 | Inductor: 1 | Voltage source: 1 | Total: 4

Ref | Proteus part | Value / setting | Every pin -> net
V1 | VSINE | 1 Vpk, 1 kHz | +=VIN; -=GND
R1 | RES | 1 kOhm | 1=VIN; 2=GND
L1 | INDUCTOR | 10 mH | 1=VIN; 2=GND
C1 | CAP | 2.2 uF | 1=VIN; 2=GND

### Net connection list

Net | Pins to join electrically
GND | V1.-, R1.2, L1.2, C1.2
VIN | V1.+, R1.1, L1.1, C1.1

PIN AUDIT: PASS - 8 of 8 placed component pins assigned to nets; 0 unassigned pins.

Proteus wiring specification - all placed component pins accounted for | Page 40

# Circuit 37: Series RLC Resonant Circuit

### Resistor: 1 | Capacitor: 1 | Inductor: 1 | Voltage source: 1 | Total: 4

Ref | Proteus part | Value / setting | Every pin -> net
V1 | VSINE | 1 Vpk, sweep | +=VIN; -=GND
R1 | RES | 100 Ohm | 1=VIN; 2=VOUT
L1 | INDUCTOR | 10 mH | 1=VOUT; 2=N2
C1 | CAP | 2.53 uF | 1=N2; 2=GND

### Net connection list

Net | Pins to join electrically
GND | V1.-, C1.2
VIN | V1.+, R1.1
N2 | L1.2, C1.1
VOUT | R1.2, L1.1

PIN AUDIT: PASS - 8 of 8 placed component pins assigned to nets; 0 unassigned pins.

Proteus wiring specification - all placed component pins accounted for | Page 41

# Circuit 38: Parallel RLC Resonant Circuit

### Resistor: 1 | Capacitor: 1 | Inductor: 1 | Voltage source: 1 | Total: 4

Ref | Proteus part | Value / setting | Every pin -> net
V1 | VSINE | 1 Vpk, sweep | +=VIN; -=GND
R1 | RES | 1 kOhm | 1=VIN; 2=GND
L1 | INDUCTOR | 10 mH | 1=VIN; 2=GND
C1 | CAP | 2.53 uF | 1=VIN; 2=GND

### Net connection list

Net | Pins to join electrically
GND | V1.-, R1.2, L1.2, C1.2
VIN | V1.+, R1.1, L1.1, C1.1

PIN AUDIT: PASS - 8 of 8 placed component pins assigned to nets; 0 unassigned pins.

Proteus wiring specification - all placed component pins accounted for | Page 42

# Circuit 39: Series RLC Band-Pass Filter

### Resistor: 1 | Capacitor: 1 | Inductor: 1 | Voltage source: 1 | Total: 4

Ref | Proteus part | Value / setting | Every pin -> net
V1 | VSINE | 1 Vpk, sweep | +=VIN; -=GND
L1 | INDUCTOR | 10 mH | 1=VIN; 2=N1
C1 | CAP | 2.53 uF | 1=N1; 2=VOUT
R1 | RES | 100 Ohm | 1=VOUT; 2=GND

### Net connection list

Net | Pins to join electrically
GND | V1.-, R1.2
VIN | V1.+, L1.1
N1 | L1.2, C1.1
VOUT | C1.2, R1.1

PIN AUDIT: PASS - 8 of 8 placed component pins assigned to nets; 0 unassigned pins.

Proteus wiring specification - all placed component pins accounted for | Page 43

# Circuit 40: Parallel RLC Band-Stop Filter

### Resistor: 2 | Capacitor: 1 | Inductor: 1 | Voltage source: 1 | Total: 5

Ref | Proteus part | Value / setting | Every pin -> net
V1 | VSINE | 1 Vpk, sweep | +=VIN; -=GND
R1 | RES | 100 Ohm | 1=VIN; 2=VOUT
L1 | INDUCTOR | 10 mH | 1=VOUT; 2=N1
C1 | CAP | 2.53 uF | 1=VOUT; 2=N1
RL | RES | 1 kOhm | 1=N1; 2=GND

### Net connection list

Net | Pins to join electrically
GND | V1.-, RL.2
VIN | V1.+, R1.1
N1 | L1.2, C1.2, RL.1
VOUT | R1.2, L1.1, C1.1

PIN AUDIT: PASS - 10 of 10 placed component pins assigned to nets; 0 unassigned pins.

Proteus wiring specification - all placed component pins accounted for | Page 44

# Circuit 41: LC Series Resonant Circuit

### Resistor: 1 | Capacitor: 1 | Inductor: 1 | Voltage source: 1 | Total: 4

Ref | Proteus part | Value / setting | Every pin -> net
V1 | VSINE | 1 Vpk, sweep | +=VIN; -=GND
R1 | RES | 10 Ohm | 1=VIN; 2=N1
L1 | INDUCTOR | 10 mH | 1=N1; 2=N2
C1 | CAP | 2.53 uF | 1=N2; 2=GND

### Net connection list

Net | Pins to join electrically
GND | V1.-, C1.2
VIN | V1.+, R1.1
N1 | R1.2, L1.1
N2 | L1.2, C1.1

PIN AUDIT: PASS - 8 of 8 placed component pins assigned to nets; 0 unassigned pins.

Proteus wiring specification - all placed component pins accounted for | Page 45

# Circuit 42: LC Parallel Tank Circuit

### Capacitor: 1 | Inductor: 1 | Current source: 1 | Total: 3

Ref | Proteus part | Value / setting | Every pin -> net
I1 | IDC | 1 mA AC | +=TANK; -=GND
L1 | INDUCTOR | 10 mH | 1=TANK; 2=GND
C1 | CAP | 2.53 uF | 1=TANK; 2=GND

### Net connection list

Net | Pins to join electrically
GND | I1.-, L1.2, C1.2
TANK | I1.+, L1.1, C1.1

PIN AUDIT: PASS - 6 of 6 placed component pins assigned to nets; 0 unassigned pins.

Proteus wiring specification - all placed component pins accounted for | Page 46

# Circuit 43: L-Section LC Low-Pass Filter

### Resistor: 1 | Capacitor: 1 | Inductor: 1 | Voltage source: 1 | Total: 4

Ref | Proteus part | Value / setting | Every pin -> net
V1 | VSINE | 1 Vpk, sweep | +=VIN; -=GND
L1 | INDUCTOR | 10 mH | 1=VIN; 2=VOUT
C1 | CAP | 1 uF | 1=VOUT; 2=GND
RL | RES | 1 kOhm | 1=VOUT; 2=GND

### Net connection list

Net | Pins to join electrically
GND | V1.-, C1.2, RL.2
VIN | V1.+, L1.1
VOUT | L1.2, C1.1, RL.1

PIN AUDIT: PASS - 8 of 8 placed component pins assigned to nets; 0 unassigned pins.

Proteus wiring specification - all placed component pins accounted for | Page 47

# Circuit 44: L-Section LC High-Pass Filter

### Resistor: 1 | Capacitor: 1 | Inductor: 1 | Voltage source: 1 | Total: 4

Ref | Proteus part | Value / setting | Every pin -> net
V1 | VSINE | 1 Vpk, sweep | +=VIN; -=GND
C1 | CAP | 1 uF | 1=VIN; 2=VOUT
L1 | INDUCTOR | 10 mH | 1=VOUT; 2=GND
RL | RES | 1 kOhm | 1=VOUT; 2=GND

### Net connection list

Net | Pins to join electrically
GND | V1.-, L1.2, RL.2
VIN | V1.+, C1.1
VOUT | C1.2, L1.1, RL.1

PIN AUDIT: PASS - 8 of 8 placed component pins assigned to nets; 0 unassigned pins.

Proteus wiring specification - all placed component pins accounted for | Page 48

# Circuit 45: Pi-Section LC Low-Pass Filter

### Resistor: 1 | Capacitor: 2 | Inductor: 1 | Voltage source: 1 | Total: 5

Ref | Proteus part | Value / setting | Every pin -> net
V1 | VSINE | 1 Vpk, sweep | +=VIN; -=GND
C1 | CAP | 1 uF | 1=VIN; 2=GND
L1 | INDUCTOR | 10 mH | 1=VIN; 2=VOUT
C2 | CAP | 1 uF | 1=VOUT; 2=GND
RL | RES | 1 kOhm | 1=VOUT; 2=GND

### Net connection list

Net | Pins to join electrically
GND | V1.-, C1.2, C2.2, RL.2
VIN | V1.+, C1.1, L1.1
VOUT | L1.2, C2.1, RL.1

PIN AUDIT: PASS - 10 of 10 placed component pins assigned to nets; 0 unassigned pins.

Proteus wiring specification - all placed component pins accounted for | Page 49

# Circuit 46: T-Section LC Low-Pass Filter

### Resistor: 1 | Capacitor: 1 | Inductor: 2 | Voltage source: 1 | Total: 5

Ref | Proteus part | Value / setting | Every pin -> net
V1 | VSINE | 1 Vpk, sweep | +=VIN; -=GND
L1 | INDUCTOR | 5 mH | 1=VIN; 2=N1
C1 | CAP | 2 uF | 1=N1; 2=GND
L2 | INDUCTOR | 5 mH | 1=N1; 2=VOUT
RL | RES | 1 kOhm | 1=VOUT; 2=GND

### Net connection list

Net | Pins to join electrically
GND | V1.-, C1.2, RL.2
VIN | V1.+, L1.1
N1 | L1.2, C1.1, L2.1
VOUT | L2.2, RL.1

PIN AUDIT: PASS - 10 of 10 placed component pins assigned to nets; 0 unassigned pins.

Proteus wiring specification - all placed component pins accounted for | Page 50

# Circuit 47: CLC Pi Power-Supply Filter

Resistor: 1 | Electrolytic capacitor: 2 | Inductor: 1 | Diode: 4 | Voltage source: 1 | Total: 9
Ref | Proteus part | Value / setting | Every pin -> net
V1 | VSINE | 12 Vrms, 50 Hz | +=AC1; -=AC2
D1 | DIODE | 1N4007 | A=AC1; K=RAW
D2 | DIODE | 1N4007 | A=AC2; K=RAW
D3 | DIODE | 1N4007 | A=GND; K=AC1
D4 | DIODE | 1N4007 | A=GND; K=AC2
C1 | CAP-ELEC | 1000 uF | +=RAW; -=GND
L1 | INDUCTOR | 100 mH | 1=RAW; 2=VOUT
C2 | CAP-ELEC | 470 uF | +=VOUT; -=GND
RL | RES | 1 kOhm | 1=VOUT; 2=GND

### Net connection list

Net | Pins to join electrically
GND | D3.A, D4.A, C1.-, C2.-, RL.2
AC1 | V1.+, D1.A, D3.K
AC2 | V1.-, D2.A, D4.K
RAW | D1.K, D2.K, C1.+, L1.1
VOUT | L1.2, C2.+, RL.1

PIN AUDIT: PASS - 18 of 18 placed component pins assigned to nets; 0 unassigned pins.

Proteus wiring specification - all placed component pins accounted for | Page 51

# Circuit 48: CRC Pi Power-Supply Filter

### Resistor: 2 | Electrolytic capacitor: 2 | Diode: 4 | Voltage source: 1 | Total: 9

Ref | Proteus part | Value / setting | Every pin -> net
V1 | VSINE | 12 Vrms, 50 Hz | +=AC1; -=AC2
D1 | DIODE | 1N4007 | A=AC1; K=RAW
D2 | DIODE | 1N4007 | A=AC2; K=RAW
D3 | DIODE | 1N4007 | A=GND; K=AC1
D4 | DIODE | 1N4007 | A=GND; K=AC2
C1 | CAP-ELEC | 1000 uF | +=RAW; -=GND
R1 | RES | 100 Ohm | 1=RAW; 2=VOUT
C2 | CAP-ELEC | 470 uF | +=VOUT; -=GND
RL | RES | 1 kOhm | 1=VOUT; 2=GND

### Net connection list

Net | Pins to join electrically
GND | D3.A, D4.A, C1.-, C2.-, RL.2
AC1 | V1.+, D1.A, D3.K
AC2 | V1.-, D2.A, D4.K
RAW | D1.K, D2.K, C1.+, R1.1
VOUT | R1.2, C2.+, RL.1

PIN AUDIT: PASS - 18 of 18 placed component pins assigned to nets; 0 unassigned pins.

Proteus wiring specification - all placed component pins accounted for | Page 52

# Circuit 49: RLC Damping Network

### Resistor: 1 | Capacitor: 1 | Inductor: 1 | Voltage source: 1 | Total: 4

Ref | Proteus part | Value / setting | Every pin -> net
V1 | VPULSE | 0-10 V step | +=VIN; -=GND
R1 | RES | 47 Ohm | 1=VIN; 2=N1
L1 | INDUCTOR | 10 mH | 1=N1; 2=VOUT
C1 | CAP | 1 uF | 1=VOUT; 2=GND

### Net connection list

Net | Pins to join electrically
GND | V1.-, C1.2
VIN | V1.+, R1.1
N1 | R1.2, L1.1
VOUT | L1.2, C1.1

PIN AUDIT: PASS - 8 of 8 placed component pins assigned to nets; 0 unassigned pins.

Proteus wiring specification - all placed component pins accounted for | Page 53

# Circuit 50: Damped LC Step-Response Circuit

### Resistor: 1 | Capacitor: 1 | Inductor: 1 | Voltage source: 1 | Total: 4

Ref | Proteus part | Value / setting | Every pin -> net
V1 | VPULSE | 0-10 V step | +=VIN; -=GND
R1 | RES | 22 Ohm | 1=VIN; 2=N1
L1 | INDUCTOR | 10 mH | 1=N1; 2=VOUT
C1 | CAP | 1 uF | 1=VOUT; 2=GND

### Net connection list

Net | Pins to join electrically
GND | V1.-, C1.2
VIN | V1.+, R1.1
N1 | R1.2, L1.1
VOUT | L1.2, C1.1

PIN AUDIT: PASS - 8 of 8 placed component pins assigned to nets; 0 unassigned pins.

Proteus wiring specification - all placed component pins accounted for | Page 54

# Circuit 51: Half-Wave Rectifier

### Resistor: 1 | Diode: 1 | Voltage source: 1 | Total: 3

Ref | Proteus part | Value / setting | Every pin -> net
V1 | VSINE | 12 Vrms, 50 Hz | +=AC; -=GND
D1 | DIODE | 1N4007 | A=AC; K=VOUT
RL | RES | 1 kOhm | 1=VOUT; 2=GND

### Net connection list

Net | Pins to join electrically
GND | V1.-, RL.2
AC | V1.+, D1.A
VOUT | D1.K, RL.1

PIN AUDIT: PASS - 6 of 6 placed component pins assigned to nets; 0 unassigned pins.

Proteus wiring specification - all placed component pins accounted for | Page 55

# Circuit 52: Full-Wave Bridge Rectifier

### Resistor: 1 | Diode: 4 | Voltage source: 1 | Total: 6

Ref | Proteus part | Value / setting | Every pin -> net
V1 | VSINE | 12 Vrms, 50 Hz | +=AC1; -=AC2
D1 | DIODE | 1N4007 | A=AC1; K=VOUT
D2 | DIODE | 1N4007 | A=AC2; K=VOUT
D3 | DIODE | 1N4007 | A=GND; K=AC1
D4 | DIODE | 1N4007 | A=GND; K=AC2
RL | RES | 1 kOhm | 1=VOUT; 2=GND

### Net connection list

Net | Pins to join electrically
GND | D3.A, D4.A, RL.2
AC1 | V1.+, D1.A, D3.K
AC2 | V1.-, D2.A, D4.K
VOUT | D1.K, D2.K, RL.1

PIN AUDIT: PASS - 12 of 12 placed component pins assigned to nets; 0 unassigned pins.

Proteus wiring specification - all placed component pins accounted for | Page 56

# Circuit 53: Half-Wave Rectifier with Capacitor Filter

### Resistor: 1 | Electrolytic capacitor: 1 | Diode: 1 | Voltage source: 1 | Total: 4

Ref | Proteus part | Value / setting | Every pin -> net
V1 | VSINE | 12 Vrms, 50 Hz | +=AC; -=GND
D1 | DIODE | 1N4007 | A=AC; K=VOUT
C1 | CAP-ELEC | 1000 uF | +=VOUT; -=GND
RL | RES | 1 kOhm | 1=VOUT; 2=GND

### Net connection list

Net | Pins to join electrically
GND | V1.-, C1.-, RL.2
AC | V1.+, D1.A
VOUT | D1.K, C1.+, RL.1

PIN AUDIT: PASS - 8 of 8 placed component pins assigned to nets; 0 unassigned pins.

Proteus wiring specification - all placed component pins accounted for | Page 57

# Circuit 54: Bridge Rectifier with Capacitor Filter

### Resistor: 1 | Electrolytic capacitor: 1 | Diode: 4 | Voltage source: 1 | Total: 7

Ref | Proteus part | Value / setting | Every pin -> net
V1 | VSINE | 12 Vrms, 50 Hz | +=AC1; -=AC2
D1 | DIODE | 1N4007 | A=AC1; K=VOUT
D2 | DIODE | 1N4007 | A=AC2; K=VOUT
D3 | DIODE | 1N4007 | A=GND; K=AC1
D4 | DIODE | 1N4007 | A=GND; K=AC2
C1 | CAP-ELEC | 1000 uF | +=VOUT; -=GND
RL | RES | 1 kOhm | 1=VOUT; 2=GND

### Net connection list

Net | Pins to join electrically
GND | D3.A, D4.A, C1.-, RL.2
AC1 | V1.+, D1.A, D3.K
AC2 | V1.-, D2.A, D4.K
VOUT | D1.K, D2.K, C1.+, RL.1

PIN AUDIT: PASS - 14 of 14 placed component pins assigned to nets; 0 unassigned pins.

Proteus wiring specification - all placed component pins accounted for | Page 58

# Circuit 55: Bridge Rectifier with CRC Filter

### Resistor: 2 | Electrolytic capacitor: 2 | Diode: 4 | Voltage source: 1 | Total: 9

Ref | Proteus part | Value / setting | Every pin -> net
V1 | VSINE | 12 Vrms, 50 Hz | +=AC1; -=AC2
D1 | DIODE | 1N4007 | A=AC1; K=RAW
D2 | DIODE | 1N4007 | A=AC2; K=RAW
D3 | DIODE | 1N4007 | A=GND; K=AC1
D4 | DIODE | 1N4007 | A=GND; K=AC2
C1 | CAP-ELEC | 1000 uF | +=RAW; -=GND
R1 | RES | 100 Ohm | 1=RAW; 2=VOUT
C2 | CAP-ELEC | 470 uF | +=VOUT; -=GND
RL | RES | 1 kOhm | 1=VOUT; 2=GND

### Net connection list

Net | Pins to join electrically
GND | D3.A, D4.A, C1.-, C2.-, RL.2
AC1 | V1.+, D1.A, D3.K
AC2 | V1.-, D2.A, D4.K
RAW | D1.K, D2.K, C1.+, R1.1
VOUT | R1.2, C2.+, RL.1

PIN AUDIT: PASS - 18 of 18 placed component pins assigned to nets; 0 unassigned pins.

Proteus wiring specification - all placed component pins accounted for | Page 59

# Circuit 56: Bridge Rectifier with CLC Filter

Resistor: 1 | Electrolytic capacitor: 2 | Inductor: 1 | Diode: 4 | Voltage source: 1 | Total: 9
Ref | Proteus part | Value / setting | Every pin -> net
V1 | VSINE | 12 Vrms, 50 Hz | +=AC1; -=AC2
D1 | DIODE | 1N4007 | A=AC1; K=RAW
D2 | DIODE | 1N4007 | A=AC2; K=RAW
D3 | DIODE | 1N4007 | A=GND; K=AC1
D4 | DIODE | 1N4007 | A=GND; K=AC2
C1 | CAP-ELEC | 1000 uF | +=RAW; -=GND
L1 | INDUCTOR | 100 mH | 1=RAW; 2=VOUT
C2 | CAP-ELEC | 470 uF | +=VOUT; -=GND
RL | RES | 1 kOhm | 1=VOUT; 2=GND

### Net connection list

Net | Pins to join electrically
GND | D3.A, D4.A, C1.-, C2.-, RL.2
AC1 | V1.+, D1.A, D3.K
AC2 | V1.-, D2.A, D4.K
RAW | D1.K, D2.K, C1.+, L1.1
VOUT | L1.2, C2.+, RL.1

PIN AUDIT: PASS - 18 of 18 placed component pins assigned to nets; 0 unassigned pins.

Proteus wiring specification - all placed component pins accounted for | Page 60

# Circuit 57: Positive Series Diode Clipper

### Resistor: 1 | Diode: 1 | Voltage source: 1 | Total: 3

Ref | Proteus part | Value / setting | Every pin -> net
V1 | VSINE | 10 Vpk, 1 kHz | +=VIN; -=GND
D1 | DIODE | 1N4148 | A=VOUT; K=VIN
RL | RES | 1 kOhm | 1=VOUT; 2=GND

### Net connection list

Net | Pins to join electrically
GND | V1.-, RL.2
VIN | V1.+, D1.K
VOUT | D1.A, RL.1

PIN AUDIT: PASS - 6 of 6 placed component pins assigned to nets; 0 unassigned pins.

Proteus wiring specification - all placed component pins accounted for | Page 61

# Circuit 58: Negative Series Diode Clipper

### Resistor: 1 | Diode: 1 | Voltage source: 1 | Total: 3

Ref | Proteus part | Value / setting | Every pin -> net
V1 | VSINE | 10 Vpk, 1 kHz | +=VIN; -=GND
D1 | DIODE | 1N4148 | A=VIN; K=VOUT
RL | RES | 1 kOhm | 1=VOUT; 2=GND

### Net connection list

Net | Pins to join electrically
GND | V1.-, RL.2
VIN | V1.+, D1.A
VOUT | D1.K, RL.1

PIN AUDIT: PASS - 6 of 6 placed component pins assigned to nets; 0 unassigned pins.

Proteus wiring specification - all placed component pins accounted for | Page 62

# Circuit 59: Positive Shunt Diode Clipper

### Resistor: 1 | Diode: 1 | Voltage source: 1 | Total: 3

Ref | Proteus part | Value / setting | Every pin -> net
V1 | VSINE | 10 Vpk, 1 kHz | +=VIN; -=GND
R1 | RES | 1 kOhm | 1=VIN; 2=VOUT
D1 | DIODE | 1N4148 | A=VOUT; K=GND

### Net connection list

Net | Pins to join electrically
GND | V1.-, D1.K
VIN | V1.+, R1.1
VOUT | R1.2, D1.A

PIN AUDIT: PASS - 6 of 6 placed component pins assigned to nets; 0 unassigned pins.

Proteus wiring specification - all placed component pins accounted for | Page 63

# Circuit 60: Negative Shunt Diode Clipper

### Resistor: 1 | Diode: 1 | Voltage source: 1 | Total: 3

Ref | Proteus part | Value / setting | Every pin -> net
V1 | VSINE | 10 Vpk, 1 kHz | +=VIN; -=GND
R1 | RES | 1 kOhm | 1=VIN; 2=VOUT
D1 | DIODE | 1N4148 | A=GND; K=VOUT

### Net connection list

Net | Pins to join electrically
GND | V1.-, D1.A
VIN | V1.+, R1.1
VOUT | R1.2, D1.K

PIN AUDIT: PASS - 6 of 6 placed component pins assigned to nets; 0 unassigned pins.

Proteus wiring specification - all placed component pins accounted for | Page 64

# Circuit 61: Symmetrical Diode Clipper

### Resistor: 1 | Diode: 2 | Voltage source: 1 | Total: 4

Ref | Proteus part | Value / setting | Every pin -> net
V1 | VSINE | 10 Vpk, 1 kHz | +=VIN; -=GND
R1 | RES | 1 kOhm | 1=VIN; 2=VOUT
D1 | DIODE | 1N4148 | A=VOUT; K=GND
D2 | DIODE | 1N4148 | A=GND; K=VOUT

### Net connection list

Net | Pins to join electrically
GND | V1.-, D1.K, D2.A
VIN | V1.+, R1.1
VOUT | R1.2, D1.A, D2.K

PIN AUDIT: PASS - 8 of 8 placed component pins assigned to nets; 0 unassigned pins.

Proteus wiring specification - all placed component pins accounted for | Page 65

# Circuit 62: Biased Positive Diode Clipper

### Resistor: 1 | Diode: 1 | Voltage source: 2 | Total: 4

Ref | Proteus part | Value / setting | Every pin -> net
V1 | VSINE | 10 Vpk, 1 kHz | +=VIN; -=GND
VBIAS | VDC | 3 V | +=BIAS; -=GND
R1 | RES | 1 kOhm | 1=VIN; 2=VOUT
D1 | DIODE | 1N4148 | A=VOUT; K=BIAS

### Net connection list

Net | Pins to join electrically
GND | V1.-, VBIAS.-
VIN | V1.+, R1.1
BIAS | VBIAS.+, D1.K
VOUT | R1.2, D1.A

PIN AUDIT: PASS - 8 of 8 placed component pins assigned to nets; 0 unassigned pins.

Proteus wiring specification - all placed component pins accounted for | Page 66

# Circuit 63: Biased Negative Diode Clipper

### Resistor: 1 | Diode: 1 | Voltage source: 2 | Total: 4

Ref | Proteus part | Value / setting | Every pin -> net
V1 | VSINE | 10 Vpk, 1 kHz | +=VIN; -=GND
VBIAS | VDC | 3 V | +=GND; -=BIAS
R1 | RES | 1 kOhm | 1=VIN; 2=VOUT
D1 | DIODE | 1N4148 | A=BIAS; K=VOUT

### Net connection list

Net | Pins to join electrically
GND | V1.-, VBIAS.+
VIN | V1.+, R1.1
BIAS | VBIAS.-, D1.A
VOUT | R1.2, D1.K

PIN AUDIT: PASS - 8 of 8 placed component pins assigned to nets; 0 unassigned pins.

Proteus wiring specification - all placed component pins accounted for | Page 67

# Circuit 64: Positive Diode Clamper

### Resistor: 1 | Capacitor: 1 | Diode: 1 | Voltage source: 1 | Total: 4

Ref | Proteus part | Value / setting | Every pin -> net
V1 | VSINE | 10 Vpk, 1 kHz | +=VIN; -=GND
C1 | CAP | 1 uF | 1=VIN; 2=VOUT
D1 | DIODE | 1N4148 | A=GND; K=VOUT
R1 | RES | 100 kOhm | 1=VOUT; 2=GND

### Net connection list

Net | Pins to join electrically
GND | V1.-, D1.A, R1.2
VIN | V1.+, C1.1
VOUT | C1.2, D1.K, R1.1

PIN AUDIT: PASS - 8 of 8 placed component pins assigned to nets; 0 unassigned pins.

Proteus wiring specification - all placed component pins accounted for | Page 68

# Circuit 65: Negative Diode Clamper

### Resistor: 1 | Capacitor: 1 | Diode: 1 | Voltage source: 1 | Total: 4

Ref | Proteus part | Value / setting | Every pin -> net
V1 | VSINE | 10 Vpk, 1 kHz | +=VIN; -=GND
C1 | CAP | 1 uF | 1=VIN; 2=VOUT
D1 | DIODE | 1N4148 | A=VOUT; K=GND
R1 | RES | 100 kOhm | 1=VOUT; 2=GND

### Net connection list

Net | Pins to join electrically
GND | V1.-, D1.K, R1.2
VIN | V1.+, C1.1
VOUT | C1.2, D1.A, R1.1

PIN AUDIT: PASS - 8 of 8 placed component pins assigned to nets; 0 unassigned pins.

Proteus wiring specification - all placed component pins accounted for | Page 69

# Circuit 66: Biased Diode Clamper

### Resistor: 1 | Capacitor: 1 | Diode: 1 | Voltage source: 2 | Total: 5

Ref | Proteus part | Value / setting | Every pin -> net
V1 | VSINE | 10 Vpk, 1 kHz | +=VIN; -=GND
VBIAS | VDC | 2 V | +=BIAS; -=GND
C1 | CAP | 1 uF | 1=VIN; 2=VOUT
D1 | DIODE | 1N4148 | A=BIAS; K=VOUT
R1 | RES | 100 kOhm | 1=VOUT; 2=GND

### Net connection list

Net | Pins to join electrically
GND | V1.-, VBIAS.-, R1.2
VIN | V1.+, C1.1
BIAS | VBIAS.+, D1.A
VOUT | C1.2, D1.K, R1.1

PIN AUDIT: PASS - 10 of 10 placed component pins assigned to nets; 0 unassigned pins.

Proteus wiring specification - all placed component pins accounted for | Page 70

# Circuit 67: Diode Peak Detector

### Resistor: 1 | Capacitor: 1 | Diode: 1 | Voltage source: 1 | Total: 4

Ref | Proteus part | Value / setting | Every pin -> net
V1 | VSINE | 10 Vpk, 1 kHz | +=VIN; -=GND
D1 | DIODE | 1N4148 | A=VIN; K=VOUT
C1 | CAP | 1 uF | 1=VOUT; 2=GND
RL | RES | 100 kOhm | 1=VOUT; 2=GND

### Net connection list

Net | Pins to join electrically
GND | V1.-, C1.2, RL.2
VIN | V1.+, D1.A
VOUT | D1.K, C1.1, RL.1

PIN AUDIT: PASS - 8 of 8 placed component pins assigned to nets; 0 unassigned pins.

Proteus wiring specification - all placed component pins accounted for | Page 71

# Circuit 68: Diode Envelope Detector

### Resistor: 1 | Capacitor: 1 | Diode: 1 | Voltage source: 1 | Total: 4

Ref | Proteus part | Value / setting | Every pin -> net
V1 | VSINE | AM signal | +=VIN; -=GND
D1 | DIODE | 1N4148 | A=VIN; K=VOUT
C1 | CAP | 10 nF | 1=VOUT; 2=GND
R1 | RES | 100 kOhm | 1=VOUT; 2=GND

### Net connection list

Net | Pins to join electrically
GND | V1.-, C1.2, R1.2
VIN | V1.+, D1.A
VOUT | D1.K, C1.1, R1.1

PIN AUDIT: PASS - 8 of 8 placed component pins assigned to nets; 0 unassigned pins.

Proteus wiring specification - all placed component pins accounted for | Page 72

# Circuit 69: Diode Charge-Pump Circuit

### Resistor: 1 | Capacitor: 2 | Diode: 2 | Voltage source: 1 | Total: 6

Ref | Proteus part | Value / setting | Every pin -> net
V1 | VPULSE | 0-5 V, 10 kHz | +=CLK; -=GND
C1 | CAP | 1 uF | 1=CLK; 2=N1
D1 | DIODE | 1N4148 | A=GND; K=N1
D2 | DIODE | 1N4148 | A=N1; K=VOUT
C2 | CAP | 10 uF | 1=VOUT; 2=GND
RL | RES | 100 kOhm | 1=VOUT; 2=GND

### Net connection list

Net | Pins to join electrically
GND | V1.-, D1.A, C2.2, RL.2
CLK | V1.+, C1.1
N1 | C1.2, D1.K, D2.A
VOUT | D2.K, C2.1, RL.1

PIN AUDIT: PASS - 12 of 12 placed component pins assigned to nets; 0 unassigned pins.

Proteus wiring specification - all placed component pins accounted for | Page 73

# Circuit 70: Half-Wave Voltage Doubler

### Resistor: 1 | Capacitor: 2 | Diode: 2 | Voltage source: 1 | Total: 6

Ref | Proteus part | Value / setting | Every pin -> net
V1 | VSINE | 10 Vpk, 1 kHz | +=AC; -=GND
C1 | CAP | 10 uF | 1=AC; 2=N1
D1 | DIODE | 1N4148 | A=GND; K=N1
D2 | DIODE | 1N4148 | A=N1; K=VOUT
C2 | CAP | 10 uF | 1=VOUT; 2=GND
RL | RES | 100 kOhm | 1=VOUT; 2=GND

### Net connection list

Net | Pins to join electrically
GND | V1.-, D1.A, C2.2, RL.2
AC | V1.+, C1.1
N1 | C1.2, D1.K, D2.A
VOUT | D2.K, C2.1, RL.1

PIN AUDIT: PASS - 12 of 12 placed component pins assigned to nets; 0 unassigned pins.

Proteus wiring specification - all placed component pins accounted for | Page 74

# Circuit 71: Full-Wave Voltage Doubler

### Resistor: 1 | Electrolytic capacitor: 2 | Diode: 2 | Voltage source: 1 | Total: 6

Ref | Proteus part | Value / setting | Every pin -> net
V1 | VSINE | 10 Vpk, 1 kHz | +=AC; -=GND
D1 | DIODE | 1N4148 | A=AC; K=VP
D2 | DIODE | 1N4148 | A=GND; K=VN
C1 | CAP-ELEC | 10 uF | +=VP; -=GND
C2 | CAP-ELEC | 10 uF | +=GND; -=VN
RL | RES | 100 kOhm | 1=VP; 2=VN

### Net connection list

Net | Pins to join electrically
GND | V1.-, D2.A, C1.-, C2.+
AC | V1.+, D1.A
VN | D2.K, C2.-, RL.2
VP | D1.K, C1.+, RL.1

PIN AUDIT: PASS - 12 of 12 placed component pins assigned to nets; 0 unassigned pins.

Proteus wiring specification - all placed component pins accounted for | Page 75

# Circuit 72: Diode Voltage Tripler

### Resistor: 1 | Capacitor: 3 | Diode: 3 | Voltage source: 1 | Total: 8

Ref | Proteus part | Value / setting | Every pin -> net
V1 | VSINE | 10 Vpk, 1 kHz | +=AC; -=GND
C1 | CAP | 10 uF | 1=AC; 2=N1
D1 | DIODE | 1N4148 | A=GND; K=N1
D2 | DIODE | 1N4148 | A=N1; K=N2
C2 | CAP | 10 uF | 1=N2; 2=GND
C3 | CAP | 10 uF | 1=N2; 2=VOUT
D3 | DIODE | 1N4148 | A=AC; K=VOUT
RL | RES | 100 kOhm | 1=VOUT; 2=GND

### Net connection list

Net | Pins to join electrically
GND | V1.-, D1.A, C2.2, RL.2
AC | V1.+, C1.1, D3.A
N1 | C1.2, D1.K, D2.A
N2 | D2.K, C2.1, C3.1
VOUT | C3.2, D3.K, RL.1

PIN AUDIT: PASS - 16 of 16 placed component pins assigned to nets; 0 unassigned pins.

Proteus wiring specification - all placed component pins accounted for | Page 76

# Circuit 73: Four-Stage Cockcroft-Walton Multiplier

### Resistor: 1 | Capacitor: 8 | Diode: 8 | Voltage source: 1 | Total: 18

Ref | Proteus part | Value / setting | Every pin -> net
V1 | VSINE | 10 Vpk, 1 kHz | +=AC; -=GND
C1 | CAP | 1 uF | 1=AC; 2=N1
D1 | DIODE | 1N4007 | A=GND; K=N1
D2 | DIODE | 1N4007 | A=N1; K=N2
C2 | CAP | 1 uF | 1=N2; 2=GND
C3 | CAP | 1 uF | 1=N1; 2=N3
D3 | DIODE | 1N4007 | A=N2; K=N3
D4 | DIODE | 1N4007 | A=N3; K=N4
C4 | CAP | 1 uF | 1=N4; 2=N2
C5 | CAP | 1 uF | 1=N3; 2=N5
D5 | DIODE | 1N4007 | A=N4; K=N5
D6 | DIODE | 1N4007 | A=N5; K=N6
C6 | CAP | 1 uF | 1=N6; 2=N4
C7 | CAP | 1 uF | 1=N5; 2=N7
D7 | DIODE | 1N4007 | A=N6; K=N7
D8 | DIODE | 1N4007 | A=N7; K=VOUT
C8 | CAP | 1 uF | 1=VOUT; 2=N6
RL | RES | 10 MOhm | 1=VOUT; 2=GND

### Net connection list

Net | Pins to join electrically
GND | V1.-, D1.A, C2.2, RL.2
AC | V1.+, C1.1
N1 | C1.2, D1.K, D2.A, C3.1
N2 | D2.K, C2.1, D3.A, C4.2
N3 | C3.2, D3.K, D4.A, C5.1
N4 | D4.K, C4.1, D5.A, C6.2
N5 | C5.2, D5.K, D6.A, C7.1
N6 | D6.K, C6.1, D7.A, C8.2
N7 | C7.2, D7.K, D8.A
VOUT | D8.K, C8.1, RL.1

PIN AUDIT: PASS - 36 of 36 placed component pins assigned to nets; 0 unassigned pins.

Proteus wiring specification - all placed component pins accounted for | Page 77

# Circuit 74: Diode OR Gate

### Resistor: 1 | Diode: 2 | Voltage source: 2 | Total: 5

Ref | Proteus part | Value / setting | Every pin -> net
VA | VDC | 5 V | +=A; -=GND
VB | VDC | 0 V | +=B; -=GND
D1 | DIODE | 1N4148 | A=A; K=Y
D2 | DIODE | 1N4148 | A=B; K=Y
R1 | RES | 10 kOhm | 1=Y; 2=GND

### Net connection list

Net | Pins to join electrically
GND | VA.-, VB.-, R1.2
A | VA.+, D1.A
B | VB.+, D2.A
Y | D1.K, D2.K, R1.1

PIN AUDIT: PASS - 10 of 10 placed component pins assigned to nets; 0 unassigned pins.

Proteus wiring specification - all placed component pins accounted for | Page 78

# Circuit 75: Diode AND Gate

### Resistor: 1 | Diode: 2 | Voltage source: 3 | Total: 6

Ref | Proteus part | Value / setting | Every pin -> net
VA | VDC | 5 V | +=A; -=GND
VB | VDC | 5 V | +=B; -=GND
VCC | VDC | 5 V | +=VDD; -=GND
R1 | RES | 10 kOhm | 1=VDD; 2=Y
D1 | DIODE | 1N4148 | A=Y; K=A
D2 | DIODE | 1N4148 | A=Y; K=B

### Net connection list

Net | Pins to join electrically
GND | VA.-, VB.-, VCC.-
VDD | VCC.+, R1.1
A | VA.+, D1.K
B | VB.+, D2.K
Y | R1.2, D1.A, D2.A

PIN AUDIT: PASS - 12 of 12 placed component pins assigned to nets; 0 unassigned pins.

Proteus wiring specification - all placed component pins accounted for | Page 79

# Circuit 76: Diode Polarity-Selector Circuit

### Resistor: 1 | Diode: 2 | Voltage source: 2 | Total: 5

Ref | Proteus part | Value / setting | Every pin -> net
V1 | VDC | 12 V | +=IN1; -=GND
V2 | VDC | 9 V | +=IN2; -=GND
D1 | DIODE | 1N4007 | A=IN1; K=VOUT
D2 | DIODE | 1N4007 | A=IN2; K=VOUT
RL | RES | 1 kOhm | 1=VOUT; 2=GND

### Net connection list

Net | Pins to join electrically
GND | V1.-, V2.-, RL.2
IN1 | V1.+, D1.A
IN2 | V2.+, D2.A
VOUT | D1.K, D2.K, RL.1

PIN AUDIT: PASS - 10 of 10 placed component pins assigned to nets; 0 unassigned pins.

Proteus wiring specification - all placed component pins accounted for | Page 80

# Circuit 77: Bridge Polarity-Correction Circuit

### Resistor: 1 | Diode: 4 | Voltage source: 1 | Total: 6

Ref | Proteus part | Value / setting | Every pin -> net
V1 | VDC | 12 V reversible | +=IN1; -=IN2
D1 | DIODE | 1N4007 | A=IN1; K=VOUT
D2 | DIODE | 1N4007 | A=IN2; K=VOUT
D3 | DIODE | 1N4007 | A=GND; K=IN1
D4 | DIODE | 1N4007 | A=GND; K=IN2
RL | RES | 1 kOhm | 1=VOUT; 2=GND

### Net connection list

Net | Pins to join electrically
GND | D3.A, D4.A, RL.2
IN1 | V1.+, D1.A, D3.K
IN2 | V1.-, D2.A, D4.K
VOUT | D1.K, D2.K, RL.1

PIN AUDIT: PASS - 12 of 12 placed component pins assigned to nets; 0 unassigned pins.

Proteus wiring specification - all placed component pins accounted for | Page 81

# Circuit 78: Series-Diode Reverse-Polarity Protection

### Resistor: 1 | Diode: 1 | Voltage source: 1 | Total: 3

Ref | Proteus part | Value / setting | Every pin -> net
V1 | VDC | 12 V | +=VIN; -=GND
D1 | DIODE | 1N4007 | A=VIN; K=VOUT
RL | RES | 1 kOhm | 1=VOUT; 2=GND

### Net connection list

Net | Pins to join electrically
GND | V1.-, RL.2
VIN | V1.+, D1.A
VOUT | D1.K, RL.1

PIN AUDIT: PASS - 6 of 6 placed component pins assigned to nets; 0 unassigned pins.

Proteus wiring specification - all placed component pins accounted for | Page 82

# Circuit 79: Freewheel Diode Clamp

### Resistor: 1 | Inductor: 1 | Diode: 1 | NMOSFET: 1 | Voltage source: 2 | Total: 6

Ref | Proteus part | Value / setting | Every pin -> net
V1 | VDC | 12 V | +=VDD; -=GND
VG | VPULSE | 0-5 V | +=GATE; -=GND
RCOIL | RES | 100 Ohm | 1=VDD; 2=N1
L1 | INDUCTOR | 100 mH | 1=N1; 2=DRAIN
D1 | DIODE | 1N4007 | A=DRAIN; K=VDD
Q1 | NMOSFET | Generic NMOS | G=GATE; D=DRAIN; S=GND

### Net connection list

Net | Pins to join electrically
GND | V1.-, VG.-, Q1.S
VDD | V1.+, RCOIL.1, D1.K
DRAIN | L1.2, D1.A, Q1.D
GATE | VG.+, Q1.G
N1 | RCOIL.2, L1.1

PIN AUDIT: PASS - 13 of 13 placed component pins assigned to nets; 0 unassigned pins.

Proteus wiring specification - all placed component pins accounted for | Page 83

# Circuit 80: NMOS Inductive-Load Switch with Flyback Diode

### Resistor: 1 | Inductor: 1 | Diode: 1 | NMOSFET: 1 | Voltage source: 2 | Total: 6

Ref | Proteus part | Value / setting | Every pin -> net
V1 | VDC | 12 V | +=VDD; -=GND
VG | VPULSE | 0-5 V | +=GDRV; -=GND
RG | RES | 100 Ohm | 1=GDRV; 2=GATE
L1 | INDUCTOR | 100 mH | 1=VDD; 2=DRAIN
D1 | DIODE | 1N4007 | A=DRAIN; K=VDD
Q1 | NMOSFET | Generic NMOS | G=GATE; D=DRAIN; S=GND

### Net connection list

Net | Pins to join electrically
GND | V1.-, VG.-, Q1.S
VDD | V1.+, L1.1, D1.K
DRAIN | L1.2, D1.A, Q1.D
GATE | RG.2, Q1.G
GDRV | VG.+, RG.1

PIN AUDIT: PASS - 13 of 13 placed component pins assigned to nets; 0 unassigned pins.

Proteus wiring specification - all placed component pins accounted for | Page 84

# Circuit 81: Diode-RC Snubber for an Inductive Load

Resistor: 2 | Capacitor: 1 | Inductor: 1 | Diode: 1 | NMOSFET: 1 | Voltage source: 2 | Total: 8
Ref | Proteus part | Value / setting | Every pin -> net
V1 | VDC | 12 V | +=VDD; -=GND
VG | VPULSE | 0-5 V | +=GDRV; -=GND
RG | RES | 100 Ohm | 1=GDRV; 2=GATE
L1 | INDUCTOR | 100 mH | 1=VDD; 2=DRAIN
D1 | DIODE | 1N4148 | A=DRAIN; K=SNUB
RS | RES | 100 Ohm | 1=SNUB; 2=CSN
CS | CAP | 100 nF | 1=CSN; 2=VDD
Q1 | NMOSFET | Generic NMOS | G=GATE; D=DRAIN; S=GND

### Net connection list

Net | Pins to join electrically
GND | V1.-, VG.-, Q1.S
VDD | V1.+, L1.1, CS.2
CSN | RS.2, CS.1
DRAIN | L1.2, D1.A, Q1.D
GATE | RG.2, Q1.G
GDRV | VG.+, RG.1
SNUB | D1.K, RS.1

PIN AUDIT: PASS - 17 of 17 placed component pins assigned to nets; 0 unassigned pins.

Proteus wiring specification - all placed component pins accounted for | Page 85

# Circuit 82: Zener Shunt Voltage Regulator

### Resistor: 2 | Zener: 1 | Voltage source: 1 | Total: 4

Ref | Proteus part | Value / setting | Every pin -> net
V1 | VDC | 12 V | +=VIN; -=GND
R1 | RES | 330 Ohm | 1=VIN; 2=VOUT
DZ1 | ZENER | 5.1 V | A=GND; K=VOUT
RL | RES | 1 kOhm | 1=VOUT; 2=GND

### Net connection list

Net | Pins to join electrically
GND | V1.-, DZ1.A, RL.2
VIN | V1.+, R1.1
VOUT | R1.2, DZ1.K, RL.1

PIN AUDIT: PASS - 8 of 8 placed component pins assigned to nets; 0 unassigned pins.

Proteus wiring specification - all placed component pins accounted for | Page 86

# Circuit 83: Zener Voltage-Reference Circuit

### Resistor: 1 | Zener: 1 | Voltage source: 1 | Total: 3

Ref | Proteus part | Value / setting | Every pin -> net
V1 | VDC | 12 V | +=VIN; -=GND
R1 | RES | 680 Ohm | 1=VIN; 2=VREF
DZ1 | ZENER | 5.1 V | A=GND; K=VREF

### Net connection list

Net | Pins to join electrically
GND | V1.-, DZ1.A
VIN | V1.+, R1.1
VREF | R1.2, DZ1.K

PIN AUDIT: PASS - 6 of 6 placed component pins assigned to nets; 0 unassigned pins.

Proteus wiring specification - all placed component pins accounted for | Page 87

# Circuit 84: Zener Overvoltage Clamp

### Resistor: 2 | Zener: 1 | Voltage source: 1 | Total: 4

Ref | Proteus part | Value / setting | Every pin -> net
V1 | VDC | 0-12 V sweep | +=VIN; -=GND
R1 | RES | 330 Ohm | 1=VIN; 2=VOUT
DZ1 | ZENER | 5.1 V | A=GND; K=VOUT
RL | RES | 1 kOhm | 1=VOUT; 2=GND

### Net connection list

Net | Pins to join electrically
GND | V1.-, DZ1.A, RL.2
VIN | V1.+, R1.1
VOUT | R1.2, DZ1.K, RL.1

PIN AUDIT: PASS - 8 of 8 placed component pins assigned to nets; 0 unassigned pins.

Proteus wiring specification - all placed component pins accounted for | Page 88

# Circuit 85: Back-to-Back Zener AC Limiter

### Resistor: 1 | Zener: 2 | Voltage source: 1 | Total: 4

Ref | Proteus part | Value / setting | Every pin -> net
V1 | VSINE | 20 Vpk, 1 kHz | +=VIN; -=GND
R1 | RES | 1 kOhm | 1=VIN; 2=VOUT
DZ1 | ZENER | 5.1 V | A=MID; K=VOUT
DZ2 | ZENER | 5.1 V | A=MID; K=GND

### Net connection list

Net | Pins to join electrically
GND | V1.-, DZ2.K
VIN | V1.+, R1.1
MID | DZ1.A, DZ2.A
VOUT | R1.2, DZ1.K

PIN AUDIT: PASS - 8 of 8 placed component pins assigned to nets; 0 unassigned pins.

Proteus wiring specification - all placed component pins accounted for | Page 89

# Circuit 86: Zener Level-Shifter Circuit

### Resistor: 2 | Zener: 1 | Voltage source: 1 | Total: 4

Ref | Proteus part | Value / setting | Every pin -> net
V1 | VDC | 12 V | +=VIN; -=GND
R1 | RES | 1 kOhm | 1=VIN; 2=N1
DZ1 | ZENER | 5.1 V | A=VOUT; K=N1
RL | RES | 10 kOhm | 1=VOUT; 2=GND

### Net connection list

Net | Pins to join electrically
GND | V1.-, RL.2
VIN | V1.+, R1.1
N1 | R1.2, DZ1.K
VOUT | DZ1.A, RL.1

PIN AUDIT: PASS - 8 of 8 placed component pins assigned to nets; 0 unassigned pins.

Proteus wiring specification - all placed component pins accounted for | Page 90

# Circuit 87: Resistor-Limited LED Indicator

### Resistor: 1 | LED: 1 | Voltage source: 1 | Total: 3

Ref | Proteus part | Value / setting | Every pin -> net
V1 | VDC | 5 V | +=VDD; -=GND
R1 | RES | 330 Ohm | 1=VDD; 2=LED_A
LED1 | LED | RED | A=LED_A; K=GND

### Net connection list

Net | Pins to join electrically
GND | V1.-, LED1.K
VDD | V1.+, R1.1
LED_A | R1.2, LED1.A

PIN AUDIT: PASS - 6 of 6 placed component pins assigned to nets; 0 unassigned pins.

Proteus wiring specification - all placed component pins accounted for | Page 91

# Circuit 88: Anti-Parallel LED Polarity Indicator

### Resistor: 1 | LED: 2 | Voltage source: 1 | Total: 4

Ref | Proteus part | Value / setting | Every pin -> net
V1 | VSINE | 5 Vpk, 1 Hz | +=VIN; -=GND
R1 | RES | 330 Ohm | 1=VIN; 2=N1
LED1 | LED | RED | A=N1; K=GND
LED2 | LED | GREEN | A=GND; K=N1

### Net connection list

Net | Pins to join electrically
GND | V1.-, LED1.K, LED2.A
VIN | V1.+, R1.1
N1 | R1.2, LED1.A, LED2.K

PIN AUDIT: PASS - 8 of 8 placed component pins assigned to nets; 0 unassigned pins.

Proteus wiring specification - all placed component pins accounted for | Page 92

# Circuit 89: Series LED String

### Resistor: 1 | LED: 3 | Voltage source: 1 | Total: 5

Ref | Proteus part | Value / setting | Every pin -> net
V1 | VDC | 12 V | +=VDD; -=GND
R1 | RES | 330 Ohm | 1=VDD; 2=N1
LED1 | LED | RED | A=N1; K=N2
LED2 | LED | GREEN | A=N2; K=N3
LED3 | LED | BLUE | A=N3; K=GND

### Net connection list

Net | Pins to join electrically
GND | V1.-, LED3.K
VDD | V1.+, R1.1
N1 | R1.2, LED1.A
N2 | LED1.K, LED2.A
N3 | LED2.K, LED3.A

PIN AUDIT: PASS - 10 of 10 placed component pins assigned to nets; 0 unassigned pins.

Proteus wiring specification - all placed component pins accounted for | Page 93

# Circuit 90: Parallel LED Branches with Ballast Resistors

### Resistor: 3 | LED: 3 | Voltage source: 1 | Total: 7

Ref | Proteus part | Value / setting | Every pin -> net
V1 | VDC | 5 V | +=VDD; -=GND
R1 | RES | 330 Ohm | 1=VDD; 2=A1
LED1 | LED | RED | A=A1; K=GND
R2 | RES | 330 Ohm | 1=VDD; 2=A2
LED2 | LED | GREEN | A=A2; K=GND
R3 | RES | 330 Ohm | 1=VDD; 2=A3
LED3 | LED | BLUE | A=A3; K=GND

### Net connection list

Net | Pins to join electrically
GND | V1.-, LED1.K, LED2.K, LED3.K
VDD | V1.+, R1.1, R2.1, R3.1
A1 | R1.2, LED1.A
A2 | R2.2, LED2.A
A3 | R3.2, LED3.A

PIN AUDIT: PASS - 14 of 14 placed component pins assigned to nets; 0 unassigned pins.

Proteus wiring specification - all placed component pins accounted for | Page 94

# Circuit 91: NMOS Low-Side Switch

### Resistor: 2 | NMOSFET: 1 | Voltage source: 2 | Total: 5

Ref | Proteus part | Value / setting | Every pin -> net
VDD1 | VDC | 12 V | +=VDD; -=GND
VG | VPULSE | 0-5 V | +=GATE; -=GND
RL | RES | 1 kOhm | 1=VDD; 2=DRAIN
RPD | RES | 100 kOhm | 1=GATE; 2=GND
Q1 | NMOSFET | Generic NMOS | G=GATE; D=DRAIN; S=GND

### Net connection list

Net | Pins to join electrically
GND | VDD1.-, VG.-, RPD.2, Q1.S
VDD | VDD1.+, RL.1
DRAIN | RL.2, Q1.D
GATE | VG.+, RPD.1, Q1.G

PIN AUDIT: PASS - 11 of 11 placed component pins assigned to nets; 0 unassigned pins.

Proteus wiring specification - all placed component pins accounted for | Page 95

# Circuit 92: Logic-Level NMOS LED Switch

### Resistor: 2 | LED: 1 | NMOSFET: 1 | Voltage source: 2 | Total: 6

Ref | Proteus part | Value / setting | Every pin -> net
VDD1 | VDC | 5 V | +=VDD; -=GND
VG | VPULSE | 0-5 V | +=GATE; -=GND
RLED | RES | 330 Ohm | 1=VDD; 2=LED_A
LED1 | LED | RED | A=LED_A; K=DRAIN
RPD | RES | 100 kOhm | 1=GATE; 2=GND
Q1 | NMOSFET | Generic NMOS | G=GATE; D=DRAIN; S=GND

### Net connection list

Net | Pins to join electrically
GND | VDD1.-, VG.-, RPD.2, Q1.S
VDD | VDD1.+, RLED.1
DRAIN | LED1.K, Q1.D
GATE | VG.+, RPD.1, Q1.G
LED_A | RLED.2, LED1.A

PIN AUDIT: PASS - 13 of 13 placed component pins assigned to nets; 0 unassigned pins.

Proteus wiring specification - all placed component pins accounted for | Page 96

# Circuit 93: NMOS Inductive-Load Driver

### Resistor: 3 | Inductor: 1 | Diode: 1 | NMOSFET: 1 | Voltage source: 2 | Total: 8

Ref | Proteus part | Value / setting | Every pin -> net
VDD1 | VDC | 12 V | +=VDD; -=GND
VG | VPULSE | 0-5 V | +=GDRV; -=GND
RG | RES | 100 Ohm | 1=GDRV; 2=GATE
RPD | RES | 100 kOhm | 1=GATE; 2=GND
RCOIL | RES | 100 Ohm | 1=VDD; 2=NCOIL
L1 | INDUCTOR | 100 mH | 1=NCOIL; 2=DRAIN
D1 | DIODE | 1N4007 | A=DRAIN; K=VDD
Q1 | NMOSFET | Generic NMOS | G=GATE; D=DRAIN; S=GND

### Net connection list

Net | Pins to join electrically
GND | VDD1.-, VG.-, RPD.2, Q1.S
VDD | VDD1.+, RCOIL.1, D1.K
DRAIN | L1.2, D1.A, Q1.D
GATE | RG.2, RPD.1, Q1.G
GDRV | VG.+, RG.1
NCOIL | RCOIL.2, L1.1

PIN AUDIT: PASS - 17 of 17 placed component pins assigned to nets; 0 unassigned pins.

Proteus wiring specification - all placed component pins accounted for | Page 97

# Circuit 94: NMOS Reverse-Polarity Protector

### Resistor: 2 | NMOSFET: 1 | Voltage source: 1 | Total: 4

Ref | Proteus part | Value / setting | Every pin -> net
V1 | VDC | 12 V | +=VIN; -=GND
Q1 | NMOSFET | Generic NMOS | G=VIN; D=PGND; S=GND
RG | RES | 100 kOhm | 1=VIN; 2=GND
RL | RES | 1 kOhm | 1=VIN; 2=PGND

### Net connection list

Net | Pins to join electrically
GND | V1.-, Q1.S, RG.2
VIN | V1.+, Q1.G, RG.1, RL.1
PGND | Q1.D, RL.2

PIN AUDIT: PASS - 9 of 9 placed component pins assigned to nets; 0 unassigned pins.

Proteus wiring specification - all placed component pins accounted for | Page 98

# Circuit 95: Back-to-Back NMOS Load Disconnect

### Resistor: 2 | NMOSFET: 2 | Voltage source: 2 | Total: 6

Ref | Proteus part | Value / setting | Every pin -> net
VDD1 | VDC | 12 V | +=VIN; -=GND
VCTRL | VDC | 10 V | +=GATE; -=GND
Q1 | NMOSFET | Generic NMOS | G=GATE; D=VIN; S=MID
Q2 | NMOSFET | Generic NMOS | G=GATE; D=VOUT; S=MID
RPD | RES | 100 kOhm | 1=GATE; 2=GND
RL | RES | 1 kOhm | 1=VOUT; 2=GND

### Net connection list

Net | Pins to join electrically
GND | VDD1.-, VCTRL.-, RPD.2, RL.2
VIN | VDD1.+, Q1.D
GATE | VCTRL.+, Q1.G, Q2.G, RPD.1
MID | Q1.S, Q2.S
VOUT | Q2.D, RL.1

PIN AUDIT: PASS - 14 of 14 placed component pins assigned to nets; 0 unassigned pins.

Proteus wiring specification - all placed component pins accounted for | Page 99

# Circuit 96: NMOS Source Follower

### Resistor: 1 | NMOSFET: 1 | Voltage source: 2 | Total: 4

Ref | Proteus part | Value / setting | Every pin -> net
VDD1 | VDC | 12 V | +=VDD; -=GND
VIN1 | VSINE | 5 V offset, 1 Vpk, 1 kHz | +=GATE; -=GND
Q1 | NMOSFET | Generic NMOS | G=GATE; D=VDD; S=VOUT
RL | RES | 1 kOhm | 1=VOUT; 2=GND

### Net connection list

Net | Pins to join electrically
GND | VDD1.-, VIN1.-, RL.2
VDD | VDD1.+, Q1.D
GATE | VIN1.+, Q1.G
VOUT | Q1.S, RL.1

PIN AUDIT: PASS - 9 of 9 placed component pins assigned to nets; 0 unassigned pins.

Proteus wiring specification - all placed component pins accounted for | Page 100

# Circuit 97: NMOS Common-Source Amplifier

### Resistor: 4 | NMOSFET: 1 | Voltage source: 2 | Total: 7

Ref | Proteus part | Value / setting | Every pin -> net
VDD1 | VDC | 12 V | +=VDD; -=GND
VIN1 | VSINE | 50 mVpk, 1 kHz | +=GATE; -=GND
R1 | RES | 1 MOhm | 1=VDD; 2=GATE
R2 | RES | 220 kOhm | 1=GATE; 2=GND
RD | RES | 4.7 kOhm | 1=VDD; 2=VOUT
RS | RES | 1 kOhm | 1=SOURCE; 2=GND
Q1 | NMOSFET | Generic NMOS | G=GATE; D=VOUT; S=SOURCE

### Net connection list

Net | Pins to join electrically
GND | VDD1.-, VIN1.-, R2.2, RS.2
VDD | VDD1.+, R1.1, RD.1
GATE | VIN1.+, R1.2, R2.1, Q1.G
SOURCE | RS.1, Q1.S
VOUT | RD.2, Q1.D

PIN AUDIT: PASS - 15 of 15 placed component pins assigned to nets; 0 unassigned pins.

Proteus wiring specification - all placed component pins accounted for | Page 101

# Circuit 98: Source-Degenerated NMOS Amplifier

### Resistor: 4 | NMOSFET: 1 | Voltage source: 2 | Total: 7

Ref | Proteus part | Value / setting | Every pin -> net
VDD1 | VDC | 12 V | +=VDD; -=GND
VIN1 | VSINE | 50 mVpk, 1 kHz | +=GATE; -=GND
R1 | RES | 1 MOhm | 1=VDD; 2=GATE
R2 | RES | 220 kOhm | 1=GATE; 2=GND
RD | RES | 4.7 kOhm | 1=VDD; 2=VOUT
RS | RES | 2.2 kOhm | 1=SOURCE; 2=GND
Q1 | NMOSFET | Generic NMOS | G=GATE; D=VOUT; S=SOURCE

### Net connection list

Net | Pins to join electrically
GND | VDD1.-, VIN1.-, R2.2, RS.2
VDD | VDD1.+, R1.1, RD.1
GATE | VIN1.+, R1.2, R2.1, Q1.G
SOURCE | RS.1, Q1.S
VOUT | RD.2, Q1.D

PIN AUDIT: PASS - 15 of 15 placed component pins assigned to nets; 0 unassigned pins.

Proteus wiring specification - all placed component pins accounted for | Page 102

# Circuit 99: RC-Coupled NMOS Common-Source Amplifier

### Resistor: 5 | Capacitor: 2 | NMOSFET: 1 | Voltage source: 2 | Total: 10

Ref | Proteus part | Value / setting | Every pin -> net
VDD1 | VDC | 12 V | +=VDD; -=GND
VIN1 | VSINE | 50 mVpk, 1 kHz | +=VSIG; -=GND
CIN | CAP | 1 uF | 1=VSIG; 2=GATE
R1 | RES | 1 MOhm | 1=VDD; 2=GATE
R2 | RES | 220 kOhm | 1=GATE; 2=GND
RD | RES | 4.7 kOhm | 1=VDD; 2=DRAIN
RS | RES | 1 kOhm | 1=SOURCE; 2=GND
Q1 | NMOSFET | Generic NMOS | G=GATE; D=DRAIN; S=SOURCE
COUT | CAP | 1 uF | 1=DRAIN; 2=VOUT
RL | RES | 10 kOhm | 1=VOUT; 2=GND

### Net connection list

Net | Pins to join electrically
GND | VDD1.-, VIN1.-, R2.2, RS.2, RL.2
VDD | VDD1.+, R1.1, RD.1
DRAIN | RD.2, Q1.D, COUT.1
GATE | CIN.2, R1.2, R2.1, Q1.G
SOURCE | RS.1, Q1.S
VSIG | VIN1.+, CIN.1
VOUT | COUT.2, RL.1

PIN AUDIT: PASS - 21 of 21 placed component pins assigned to nets; 0 unassigned pins.

Proteus wiring specification - all placed component pins accounted for | Page 103

# Circuit 100: NMOS Amplifier with Bypassed Source Resistor

### Resistor: 5 | Capacitor: 3 | NMOSFET: 1 | Voltage source: 2 | Total: 11

Ref | Proteus part | Value / setting | Every pin -> net
VDD1 | VDC | 12 V | +=VDD; -=GND
VIN1 | VSINE | 50 mVpk, 1 kHz | +=VSIG; -=GND
CIN | CAP | 1 uF | 1=VSIG; 2=GATE
R1 | RES | 1 MOhm | 1=VDD; 2=GATE
R2 | RES | 220 kOhm | 1=GATE; 2=GND
RD | RES | 4.7 kOhm | 1=VDD; 2=DRAIN
RS | RES | 1 kOhm | 1=SOURCE; 2=GND
CS | CAP | 100 uF | 1=SOURCE; 2=GND
Q1 | NMOSFET | Generic NMOS | G=GATE; D=DRAIN; S=SOURCE
COUT | CAP | 1 uF | 1=DRAIN; 2=VOUT
RL | RES | 10 kOhm | 1=VOUT; 2=GND

### Net connection list

Net | Pins to join electrically
GND | VDD1.-, VIN1.-, R2.2, RS.2, CS.2, RL.2
VDD | VDD1.+, R1.1, RD.1
DRAIN | RD.2, Q1.D, COUT.1
GATE | CIN.2, R1.2, R2.1, Q1.G
SOURCE | RS.1, CS.1, Q1.S
VSIG | VIN1.+, CIN.1
VOUT | COUT.2, RL.1

PIN AUDIT: PASS - 23 of 23 placed component pins assigned to nets; 0 unassigned pins.

Proteus wiring specification - all placed component pins accounted for | Page 104

# Circuit 101: NMOS Voltage-Controlled Resistor

### Resistor: 1 | NMOSFET: 1 | Voltage source: 2 | Total: 4

Ref | Proteus part | Value / setting | Every pin -> net
VSIG | VSINE | 1 Vpk, 1 kHz | +=VIN; -=GND
VCTRL | VDC | 0-5 V sweep | +=GATE; -=GND
R1 | RES | 1 kOhm | 1=VIN; 2=DRAIN
Q1 | NMOSFET | Generic NMOS | G=GATE; D=DRAIN; S=GND

### Net connection list

Net | Pins to join electrically
GND | VSIG.-, VCTRL.-, Q1.S
VIN | VSIG.+, R1.1
DRAIN | R1.2, Q1.D
GATE | VCTRL.+, Q1.G

PIN AUDIT: PASS - 9 of 9 placed component pins assigned to nets; 0 unassigned pins.

Proteus wiring specification - all placed component pins accounted for | Page 105

# Circuit 102: NMOS Constant-Current Sink

### Resistor: 2 | NMOSFET: 1 | Voltage source: 2 | Total: 5

Ref | Proteus part | Value / setting | Every pin -> net
VDD1 | VDC | 12 V | +=VDD; -=GND
VREF | VDC | 2.5 V | +=GATE; -=GND
RL | RES | 100 Ohm | 1=VDD; 2=DRAIN
Q1 | NMOSFET | Generic NMOS | G=GATE; D=DRAIN; S=SOURCE
RS | RES | 10 Ohm | 1=SOURCE; 2=GND

### Net connection list

Net | Pins to join electrically
GND | VDD1.-, VREF.-, RS.2
VDD | VDD1.+, RL.1
DRAIN | RL.2, Q1.D
GATE | VREF.+, Q1.G
SOURCE | Q1.S, RS.1

PIN AUDIT: PASS - 11 of 11 placed component pins assigned to nets; 0 unassigned pins.

Proteus wiring specification - all placed component pins accounted for | Page 106

# Circuit 103: NMOS Constant-Current LED Sink

### Resistor: 1 | LED: 1 | NMOSFET: 1 | Voltage source: 2 | Total: 5

Ref | Proteus part | Value / setting | Every pin -> net
VDD1 | VDC | 12 V | +=VDD; -=GND
VREF | VDC | 2.5 V | +=GATE; -=GND
LED1 | LED | RED | A=VDD; K=DRAIN
Q1 | NMOSFET | Generic NMOS | G=GATE; D=DRAIN; S=SOURCE
RS | RES | 10 Ohm | 1=SOURCE; 2=GND

### Net connection list

Net | Pins to join electrically
GND | VDD1.-, VREF.-, RS.2
VDD | VDD1.+, LED1.A
DRAIN | LED1.K, Q1.D
GATE | VREF.+, Q1.G
SOURCE | Q1.S, RS.1

PIN AUDIT: PASS - 11 of 11 placed component pins assigned to nets; 0 unassigned pins.

Proteus wiring specification - all placed component pins accounted for | Page 107

# Circuit 104: Two-NMOS Current Mirror

### Resistor: 2 | NMOSFET: 2 | Voltage source: 1 | Total: 5

Ref | Proteus part | Value / setting | Every pin -> net
VDD1 | VDC | 12 V | +=VDD; -=GND
RREF | RES | 1 kOhm | 1=VDD; 2=REF
Q1 | NMOSFET | Generic NMOS | G=REF; D=REF; S=GND
Q2 | NMOSFET | Generic NMOS | G=REF; D=OUT; S=GND
RL | RES | 1 kOhm | 1=VDD; 2=OUT

### Net connection list

Net | Pins to join electrically
GND | VDD1.-, Q1.S, Q2.S
VDD | VDD1.+, RREF.1, RL.1
OUT | Q2.D, RL.2
REF | RREF.2, Q1.G, Q1.D, Q2.G

PIN AUDIT: PASS - 12 of 12 placed component pins assigned to nets; 0 unassigned pins.

Proteus wiring specification - all placed component pins accounted for | Page 108

# Circuit 105: NMOS Cascode Current Mirror

### Resistor: 2 | NMOSFET: 4 | Voltage source: 1 | Total: 7

Ref | Proteus part | Value / setting | Every pin -> net
VDD1 | VDC | 12 V | +=VDD; -=GND
RREF | RES | 1 kOhm | 1=VDD; 2=B2
Q1 | NMOSFET | Generic NMOS | G=B1; D=B1; S=GND
Q2 | NMOSFET | Generic NMOS | G=B2; D=B2; S=B1
Q3 | NMOSFET | Generic NMOS | G=B1; D=NX; S=GND
Q4 | NMOSFET | Generic NMOS | G=B2; D=OUT; S=NX
RL | RES | 1 kOhm | 1=VDD; 2=OUT

### Net connection list

Net | Pins to join electrically
GND | VDD1.-, Q1.S, Q3.S
VDD | VDD1.+, RREF.1, RL.1
B1 | Q1.G, Q1.D, Q2.S, Q3.G
B2 | RREF.2, Q2.G, Q2.D, Q4.G
NX | Q3.D, Q4.S
OUT | Q4.D, RL.2

PIN AUDIT: PASS - 18 of 18 placed component pins assigned to nets; 0 unassigned pins.

Proteus wiring specification - all placed component pins accounted for | Page 109

# Circuit 106: NMOS Amplifier with Active NMOS Load

### Resistor: 3 | NMOSFET: 2 | Voltage source: 2 | Total: 7

Ref | Proteus part | Value / setting | Every pin -> net
VDD1 | VDC | 12 V | +=VDD; -=GND
VIN1 | VSINE | 50 mVpk, 1 kHz | +=GATE; -=GND
R1 | RES | 1 MOhm | 1=VDD; 2=GATE
R2 | RES | 220 kOhm | 1=GATE; 2=GND
QLOAD | NMOSFET | Generic NMOS | G=VDD; D=VDD; S=VOUT
Q1 | NMOSFET | Generic NMOS | G=GATE; D=VOUT; S=SOURCE
RS | RES | 1 kOhm | 1=SOURCE; 2=GND

### Net connection list

Net | Pins to join electrically
GND | VDD1.-, VIN1.-, R2.2, RS.2
VDD | VDD1.+, R1.1, QLOAD.G, QLOAD.D
GATE | VIN1.+, R1.2, R2.1, Q1.G
SOURCE | Q1.S, RS.1
VOUT | QLOAD.S, Q1.D

PIN AUDIT: PASS - 16 of 16 placed component pins assigned to nets; 0 unassigned pins.

Proteus wiring specification - all placed component pins accounted for | Page 110

# Circuit 107: NMOS Cascode Amplifier

### Resistor: 6 | NMOSFET: 2 | Voltage source: 2 | Total: 10

Ref | Proteus part | Value / setting | Every pin -> net
VDD1 | VDC | 15 V | +=VDD; -=GND
VIN1 | VSINE | 50 mVpk, 1 kHz | +=GIN; -=GND
R1 | RES | 1 MOhm | 1=VDD; 2=GIN
R2 | RES | 220 kOhm | 1=GIN; 2=GND
R3 | RES | 470 kOhm | 1=VDD; 2=GCAS
R4 | RES | 220 kOhm | 1=GCAS; 2=GND
RD | RES | 4.7 kOhm | 1=VDD; 2=VOUT
RS | RES | 1 kOhm | 1=SOURCE; 2=GND
Q1 | NMOSFET | Generic NMOS | G=GIN; D=N1; S=SOURCE
Q2 | NMOSFET | Generic NMOS | G=GCAS; D=VOUT; S=N1

### Net connection list

Net | Pins to join electrically
GND | VDD1.-, VIN1.-, R2.2, R4.2, RS.2
VDD | VDD1.+, R1.1, R3.1, RD.1
GCAS | R3.2, R4.1, Q2.G
GIN | VIN1.+, R1.2, R2.1, Q1.G
N1 | Q1.D, Q2.S
SOURCE | RS.1, Q1.S
VOUT | RD.2, Q2.D

PIN AUDIT: PASS - 22 of 22 placed component pins assigned to nets; 0 unassigned pins.

Proteus wiring specification - all placed component pins accounted for | Page 111

# Circuit 108: Two-Stage NMOS Amplifier

### Resistor: 9 | Capacitor: 3 | NMOSFET: 2 | Voltage source: 2 | Total: 16

Ref | Proteus part | Value / setting | Every pin -> net
VDD1 | VDC | 15 V | +=VDD; -=GND
VIN1 | VSINE | 20 mVpk, 1 kHz | +=VSIG; -=GND
CIN | CAP | 1 uF | 1=VSIG; 2=G1
R1 | RES | 1 MOhm | 1=VDD; 2=G1
R2 | RES | 220 kOhm | 1=G1; 2=GND
RD1 | RES | 4.7 kOhm | 1=VDD; 2=D1
RS1 | RES | 1 kOhm | 1=S1; 2=GND
Q1 | NMOSFET | Generic NMOS | G=G1; D=D1; S=S1
CC | CAP | 1 uF | 1=D1; 2=G2
R3 | RES | 1 MOhm | 1=VDD; 2=G2
R4 | RES | 220 kOhm | 1=G2; 2=GND
RD2 | RES | 4.7 kOhm | 1=VDD; 2=D2
RS2 | RES | 1 kOhm | 1=S2; 2=GND
Q2 | NMOSFET | Generic NMOS | G=G2; D=D2; S=S2
COUT | CAP | 1 uF | 1=D2; 2=VOUT
RL | RES | 10 kOhm | 1=VOUT; 2=GND

### Net connection list

Net | Pins to join electrically
GND | VDD1.-, VIN1.-, R2.2, RS1.2, R4.2, RS2.2, RL.2
VDD | VDD1.+, R1.1, RD1.1, R3.1, RD2.1
D1 | RD1.2, Q1.D, CC.1
D2 | RD2.2, Q2.D, COUT.1
G1 | CIN.2, R1.2, R2.1, Q1.G
G2 | CC.2, R3.2, R4.1, Q2.G
S1 | RS1.1, Q1.S
S2 | RS2.1, Q2.S
VSIG | VIN1.+, CIN.1
VOUT | COUT.2, RL.1

PIN AUDIT: PASS - 34 of 34 placed component pins assigned to nets; 0 unassigned pins.

Proteus wiring specification - all placed component pins accounted for | Page 112

# Circuit 109: Resistor-Load NMOS Inverter

### Resistor: 1 | NMOSFET: 1 | Voltage source: 2 | Total: 4

Ref | Proteus part | Value / setting | Every pin -> net
VDD1 | VDC | 5 V | +=VDD; -=GND
VIN1 | VPULSE | 0-5 V | +=GATE; -=GND
R1 | RES | 10 kOhm | 1=VDD; 2=VOUT
Q1 | NMOSFET | Generic NMOS | G=GATE; D=VOUT; S=GND

### Net connection list

Net | Pins to join electrically
GND | VDD1.-, VIN1.-, Q1.S
VDD | VDD1.+, R1.1
GATE | VIN1.+, Q1.G
VOUT | R1.2, Q1.D

PIN AUDIT: PASS - 9 of 9 placed component pins assigned to nets; 0 unassigned pins.

Proteus wiring specification - all placed component pins accounted for | Page 113

# Circuit 110: Diode-Connected-Load NMOS Inverter

### NMOSFET: 2 | Voltage source: 2 | Total: 4

Ref | Proteus part | Value / setting | Every pin -> net
VDD1 | VDC | 5 V | +=VDD; -=GND
VIN1 | VPULSE | 0-5 V | +=GATE; -=GND
QLOAD | NMOSFET | Generic NMOS | G=VDD; D=VDD; S=VOUT
Q1 | NMOSFET | Generic NMOS | G=GATE; D=VOUT; S=GND

### Net connection list

Net | Pins to join electrically
GND | VDD1.-, VIN1.-, Q1.S
VDD | VDD1.+, QLOAD.G, QLOAD.D
GATE | VIN1.+, Q1.G
VOUT | QLOAD.S, Q1.D

PIN AUDIT: PASS - 10 of 10 placed component pins assigned to nets; 0 unassigned pins.

Proteus wiring specification - all placed component pins accounted for | Page 114

# Circuit 111: NMOS NAND Gate

### Resistor: 1 | NMOSFET: 2 | Voltage source: 3 | Total: 6

Ref | Proteus part | Value / setting | Every pin -> net
VDD1 | VDC | 5 V | +=VDD; -=GND
VA | VPULSE | 0-5 V | +=A; -=GND
VB | VPULSE | 0-5 V | +=B; -=GND
R1 | RES | 10 kOhm | 1=VDD; 2=Y
Q1 | NMOSFET | Generic NMOS | G=A; D=Y; S=N1
Q2 | NMOSFET | Generic NMOS | G=B; D=N1; S=GND

### Net connection list

Net | Pins to join electrically
GND | VDD1.-, VA.-, VB.-, Q2.S
VDD | VDD1.+, R1.1
A | VA.+, Q1.G
B | VB.+, Q2.G
N1 | Q1.S, Q2.D
Y | R1.2, Q1.D

PIN AUDIT: PASS - 14 of 14 placed component pins assigned to nets; 0 unassigned pins.

Proteus wiring specification - all placed component pins accounted for | Page 115

# Circuit 112: NMOS NOR Gate

### Resistor: 1 | NMOSFET: 2 | Voltage source: 3 | Total: 6

Ref | Proteus part | Value / setting | Every pin -> net
VDD1 | VDC | 5 V | +=VDD; -=GND
VA | VPULSE | 0-5 V | +=A; -=GND
VB | VPULSE | 0-5 V | +=B; -=GND
R1 | RES | 10 kOhm | 1=VDD; 2=Y
Q1 | NMOSFET | Generic NMOS | G=A; D=Y; S=GND
Q2 | NMOSFET | Generic NMOS | G=B; D=Y; S=GND

### Net connection list

Net | Pins to join electrically
GND | VDD1.-, VA.-, VB.-, Q1.S, Q2.S
VDD | VDD1.+, R1.1
A | VA.+, Q1.G
B | VB.+, Q2.G
Y | R1.2, Q1.D, Q2.D

PIN AUDIT: PASS - 14 of 14 placed component pins assigned to nets; 0 unassigned pins.

Proteus wiring specification - all placed component pins accounted for | Page 116

# Circuit 113: NMOS Open-Drain Output

### Resistor: 2 | NMOSFET: 1 | Voltage source: 2 | Total: 5

Ref | Proteus part | Value / setting | Every pin -> net
VDD1 | VDC | 5 V | +=VDD; -=GND
VIN1 | VPULSE | 0-5 V | +=GATE; -=GND
RPU | RES | 10 kOhm | 1=VDD; 2=VOUT
RPD | RES | 100 kOhm | 1=GATE; 2=GND
Q1 | NMOSFET | Generic NMOS | G=GATE; D=VOUT; S=GND

### Net connection list

Net | Pins to join electrically
GND | VDD1.-, VIN1.-, RPD.2, Q1.S
VDD | VDD1.+, RPU.1
GATE | VIN1.+, RPD.1, Q1.G
VOUT | RPU.2, Q1.D

PIN AUDIT: PASS - 11 of 11 placed component pins assigned to nets; 0 unassigned pins.

Proteus wiring specification - all placed component pins accounted for | Page 117

# Circuit 114: NMOS Bidirectional Analog Switch

### Resistor: 2 | NMOSFET: 2 | Voltage source: 2 | Total: 6

Ref | Proteus part | Value / setting | Every pin -> net
VSIG | VSINE | 1 Vpk, 1 kHz | +=VIN; -=GND
VCTRL | VDC | 10 V | +=GATE; -=GND
Q1 | NMOSFET | Generic NMOS | G=GATE; D=VIN; S=MID
Q2 | NMOSFET | Generic NMOS | G=GATE; D=VOUT; S=MID
RPD | RES | 100 kOhm | 1=GATE; 2=GND
RL | RES | 10 kOhm | 1=VOUT; 2=GND

### Net connection list

Net | Pins to join electrically
GND | VSIG.-, VCTRL.-, RPD.2, RL.2
VIN | VSIG.+, Q1.D
GATE | VCTRL.+, Q1.G, Q2.G, RPD.1
MID | Q1.S, Q2.S
VOUT | Q2.D, RL.1

PIN AUDIT: PASS - 14 of 14 placed component pins assigned to nets; 0 unassigned pins.

Proteus wiring specification - all placed component pins accounted for | Page 118

# Circuit 115: NMOS Level-Shifter Circuit

### Resistor: 2 | NMOSFET: 1 | Voltage source: 3 | Total: 6

Ref | Proteus part | Value / setting | Every pin -> net
VLOW | VDC | 3.3 V | +=VDDL; -=GND
VHIGH | VDC | 12 V | +=VDDH; -=GND
VIN1 | VPULSE | 0-3.3 V | +=IN; -=GND
R1 | RES | 10 kOhm | 1=VDDL; 2=IN
R2 | RES | 10 kOhm | 1=VDDH; 2=OUT
Q1 | NMOSFET | Generic NMOS | G=IN; D=OUT; S=GND

### Net connection list

Net | Pins to join electrically
GND | VLOW.-, VHIGH.-, VIN1.-, Q1.S
IN | VIN1.+, R1.2, Q1.G
OUT | R2.2, Q1.D
VDDH | VHIGH.+, R2.1
VDDL | VLOW.+, R1.1

PIN AUDIT: PASS - 13 of 13 placed component pins assigned to nets; 0 unassigned pins.

Proteus wiring specification - all placed component pins accounted for | Page 119

# Circuit 116: RC-Delayed NMOS Switch

### Resistor: 2 | Capacitor: 1 | NMOSFET: 1 | Voltage source: 2 | Total: 6

Ref | Proteus part | Value / setting | Every pin -> net
VDD1 | VDC | 12 V | +=VDD; -=GND
VIN1 | VPULSE | 0-5 V | +=VIN; -=GND
R1 | RES | 100 kOhm | 1=VIN; 2=GATE
C1 | CAP | 10 uF | 1=GATE; 2=GND
RL | RES | 1 kOhm | 1=VDD; 2=DRAIN
Q1 | NMOSFET | Generic NMOS | G=GATE; D=DRAIN; S=GND

### Net connection list

Net | Pins to join electrically
GND | VDD1.-, VIN1.-, C1.2, Q1.S
VDD | VDD1.+, RL.1
VIN | VIN1.+, R1.1
DRAIN | RL.2, Q1.D
GATE | R1.2, C1.1, Q1.G

PIN AUDIT: PASS - 13 of 13 placed component pins assigned to nets; 0 unassigned pins.

Proteus wiring specification - all placed component pins accounted for | Page 120

# Circuit 117: NMOS Soft-Start Load Switch

### Resistor: 2 | Capacitor: 1 | NMOSFET: 1 | Voltage source: 2 | Total: 6

Ref | Proteus part | Value / setting | Every pin -> net
VDD1 | VDC | 12 V | +=VDD; -=GND
VCTRL | VDC | 5 V | +=CTRL; -=GND
R1 | RES | 100 kOhm | 1=CTRL; 2=GATE
C1 | CAP | 10 uF | 1=GATE; 2=GND
RL | RES | 1 kOhm | 1=VDD; 2=DRAIN
Q1 | NMOSFET | Generic NMOS | G=GATE; D=DRAIN; S=GND

### Net connection list

Net | Pins to join electrically
GND | VDD1.-, VCTRL.-, C1.2, Q1.S
VDD | VDD1.+, RL.1
CTRL | VCTRL.+, R1.1
DRAIN | RL.2, Q1.D
GATE | R1.2, C1.1, Q1.G

PIN AUDIT: PASS - 13 of 13 placed component pins assigned to nets; 0 unassigned pins.

Proteus wiring specification - all placed component pins accounted for | Page 121

# Circuit 118: NMOS LED Fade Circuit

### Resistor: 2 | Capacitor: 1 | LED: 1 | NMOSFET: 1 | Voltage source: 2 | Total: 7

Ref | Proteus part | Value / setting | Every pin -> net
VDD1 | VDC | 5 V | +=VDD; -=GND
VIN1 | VPULSE | 0-5 V, slow | +=CTRL; -=GND
R1 | RES | 100 kOhm | 1=CTRL; 2=GATE
C1 | CAP | 10 uF | 1=GATE; 2=GND
RLED | RES | 330 Ohm | 1=VDD; 2=LED_A
LED1 | LED | RED | A=LED_A; K=DRAIN
Q1 | NMOSFET | Generic NMOS | G=GATE; D=DRAIN; S=GND

### Net connection list

Net | Pins to join electrically
GND | VDD1.-, VIN1.-, C1.2, Q1.S
VDD | VDD1.+, RLED.1
CTRL | VIN1.+, R1.1
DRAIN | LED1.K, Q1.D
GATE | R1.2, C1.1, Q1.G
LED_A | RLED.2, LED1.A

PIN AUDIT: PASS - 15 of 15 placed component pins assigned to nets; 0 unassigned pins.

Proteus wiring specification - all placed component pins accounted for | Page 122

# Circuit 119: NMOS PWM LED Dimmer

### Resistor: 3 | LED: 1 | NMOSFET: 1 | Voltage source: 2 | Total: 7

Ref | Proteus part | Value / setting | Every pin -> net
VDD1 | VDC | 5 V | +=VDD; -=GND
VPWM | VPULSE | 0-5 V PWM | +=PWM; -=GND
RG | RES | 100 Ohm | 1=PWM; 2=GATE
RPD | RES | 100 kOhm | 1=GATE; 2=GND
RLED | RES | 330 Ohm | 1=VDD; 2=LED_A
LED1 | LED | RED | A=LED_A; K=DRAIN
Q1 | NMOSFET | Generic NMOS | G=GATE; D=DRAIN; S=GND

### Net connection list

Net | Pins to join electrically
GND | VDD1.-, VPWM.-, RPD.2, Q1.S
VDD | VDD1.+, RLED.1
DRAIN | LED1.K, Q1.D
GATE | RG.2, RPD.1, Q1.G
LED_A | RLED.2, LED1.A
PWM | VPWM.+, RG.1

PIN AUDIT: PASS - 15 of 15 placed component pins assigned to nets; 0 unassigned pins.

Proteus wiring specification - all placed component pins accounted for | Page 123

# Circuit 120: NMOS Pulse Driver

### Resistor: 3 | NMOSFET: 1 | Voltage source: 2 | Total: 6

Ref | Proteus part | Value / setting | Every pin -> net
VDD1 | VDC | 12 V | +=VDD; -=GND
VIN1 | VPULSE | 0-5 V pulse | +=DRV; -=GND
RG | RES | 100 Ohm | 1=DRV; 2=GATE
RPD | RES | 100 kOhm | 1=GATE; 2=GND
RL | RES | 100 Ohm | 1=VDD; 2=DRAIN
Q1 | NMOSFET | Generic NMOS | G=GATE; D=DRAIN; S=GND

### Net connection list

Net | Pins to join electrically
GND | VDD1.-, VIN1.-, RPD.2, Q1.S
VDD | VDD1.+, RL.1
DRAIN | RL.2, Q1.D
DRV | VIN1.+, RG.1
GATE | RG.2, RPD.1, Q1.G

PIN AUDIT: PASS - 13 of 13 placed component pins assigned to nets; 0 unassigned pins.

Proteus wiring specification - all placed component pins accounted for | Page 124

# Circuit 121: NMOS Inductor Pulse Driver

### Resistor: 3 | Inductor: 1 | Diode: 1 | NMOSFET: 1 | Voltage source: 2 | Total: 8

Ref | Proteus part | Value / setting | Every pin -> net
VDD1 | VDC | 12 V | +=VDD; -=GND
VIN1 | VPULSE | 0-5 V pulse | +=DRV; -=GND
RG | RES | 100 Ohm | 1=DRV; 2=GATE
RPD | RES | 100 kOhm | 1=GATE; 2=GND
RCOIL | RES | 100 Ohm | 1=VDD; 2=N1
L1 | INDUCTOR | 100 mH | 1=N1; 2=DRAIN
D1 | DIODE | 1N4007 | A=DRAIN; K=VDD
Q1 | NMOSFET | Generic NMOS | G=GATE; D=DRAIN; S=GND

### Net connection list

Net | Pins to join electrically
GND | VDD1.-, VIN1.-, RPD.2, Q1.S
VDD | VDD1.+, RCOIL.1, D1.K
DRAIN | L1.2, D1.A, Q1.D
DRV | VIN1.+, RG.1
GATE | RG.2, RPD.1, Q1.G
N1 | RCOIL.2, L1.1

PIN AUDIT: PASS - 17 of 17 placed component pins assigned to nets; 0 unassigned pins.

Proteus wiring specification - all placed component pins accounted for | Page 125

# Circuit 122: NMOS Capacitor-Discharge Switch

### Resistor: 2 | Capacitor: 1 | NMOSFET: 1 | Voltage source: 2 | Total: 6

Ref | Proteus part | Value / setting | Every pin -> net
VCHG | VDC | 12 V | +=VDD; -=GND
VG | VPULSE | 0-5 V | +=GATE; -=GND
RCHG | RES | 1 kOhm | 1=VDD; 2=VCAP
C1 | CAP | 100 uF | 1=VCAP; 2=GND
RDIS | RES | 10 Ohm | 1=VCAP; 2=DRAIN
Q1 | NMOSFET | Generic NMOS | G=GATE; D=DRAIN; S=GND

### Net connection list

Net | Pins to join electrically
GND | VCHG.-, VG.-, C1.2, Q1.S
VDD | VCHG.+, RCHG.1
DRAIN | RDIS.2, Q1.D
GATE | VG.+, Q1.G
VCAP | RCHG.2, C1.1, RDIS.1

PIN AUDIT: PASS - 13 of 13 placed component pins assigned to nets; 0 unassigned pins.

Proteus wiring specification - all placed component pins accounted for | Page 126

# Circuit 123: NMOS Gate Pull-Down Discharge Circuit

### Resistor: 3 | NMOSFET: 1 | Voltage source: 2 | Total: 6

Ref | Proteus part | Value / setting | Every pin -> net
VDD1 | VDC | 12 V | +=VDD; -=GND
VIN1 | VPULSE | 0-5 V | +=DRV; -=GND
RG | RES | 100 Ohm | 1=DRV; 2=GATE
RPD | RES | 100 kOhm | 1=GATE; 2=GND
RD | RES | 1 kOhm | 1=VDD; 2=DRAIN
Q1 | NMOSFET | Generic NMOS | G=GATE; D=DRAIN; S=GND

### Net connection list

Net | Pins to join electrically
GND | VDD1.-, VIN1.-, RPD.2, Q1.S
VDD | VDD1.+, RD.1
DRAIN | RD.2, Q1.D
DRV | VIN1.+, RG.1
GATE | RG.2, RPD.1, Q1.G

PIN AUDIT: PASS - 13 of 13 placed component pins assigned to nets; 0 unassigned pins.

Proteus wiring specification - all placed component pins accounted for | Page 127

# Circuit 124: NMOS Gate-Charge Test Circuit

### Resistor: 2 | NMOSFET: 1 | Voltage source: 2 | Total: 5

Ref | Proteus part | Value / setting | Every pin -> net
VDD1 | VDC | 12 V | +=VDD; -=GND
VIN1 | VPULSE | 0-10 V fast pulse | +=DRV; -=GND
RG | RES | 10 Ohm | 1=DRV; 2=GATE
RD | RES | 10 Ohm | 1=VDD; 2=DRAIN
Q1 | NMOSFET | Generic NMOS | G=GATE; D=DRAIN; S=GND

### Net connection list

Net | Pins to join electrically
GND | VDD1.-, VIN1.-, Q1.S
VDD | VDD1.+, RD.1
DRAIN | RD.2, Q1.D
DRV | VIN1.+, RG.1
GATE | RG.2, Q1.G

PIN AUDIT: PASS - 11 of 11 placed component pins assigned to nets; 0 unassigned pins.

Proteus wiring specification - all placed component pins accounted for | Page 128

# Circuit 125: NMOS Transfer-Characteristic Test Circuit

### Resistor: 1 | NMOSFET: 1 | Voltage source: 2 | Total: 4

Ref | Proteus part | Value / setting | Every pin -> net
VDD1 | VDC | 10 V | +=VDD; -=GND
VGS | VDC | 0-5 V sweep | +=GATE; -=GND
RD | RES | 100 Ohm | 1=VDD; 2=DRAIN
Q1 | NMOSFET | Generic NMOS | G=GATE; D=DRAIN; S=GND

### Net connection list

Net | Pins to join electrically
GND | VDD1.-, VGS.-, Q1.S
VDD | VDD1.+, RD.1
DRAIN | RD.2, Q1.D
GATE | VGS.+, Q1.G

PIN AUDIT: PASS - 9 of 9 placed component pins assigned to nets; 0 unassigned pins.

Proteus wiring specification - all placed component pins accounted for | Page 129

# Circuit 126: NMOS Output-Characteristic Test Circuit

### NMOSFET: 1 | Voltage source: 2 | Total: 3

Ref | Proteus part | Value / setting | Every pin -> net
VDS | VDC | 0-10 V sweep | +=DRAIN; -=GND
VGS | VDC | 2-5 V stepped | +=GATE; -=GND
Q1 | NMOSFET | Generic NMOS | G=GATE; D=DRAIN; S=GND

### Net connection list

Net | Pins to join electrically
GND | VDS.-, VGS.-, Q1.S
DRAIN | VDS.+, Q1.D
GATE | VGS.+, Q1.G

PIN AUDIT: PASS - 7 of 7 placed component pins assigned to nets; 0 unassigned pins.

Proteus wiring specification - all placed component pins accounted for | Page 130

# Circuit 127: NMOS Threshold-Voltage Test Circuit

### Resistor: 1 | NMOSFET: 1 | Voltage source: 2 | Total: 4

Ref | Proteus part | Value / setting | Every pin -> net
VDD1 | VDC | 5 V | +=VDD; -=GND
VGS | VDC | 0-5 V sweep | +=GATE; -=GND
RD | RES | 100 kOhm | 1=VDD; 2=DRAIN
Q1 | NMOSFET | Generic NMOS | G=GATE; D=DRAIN; S=GND

### Net connection list

Net | Pins to join electrically
GND | VDD1.-, VGS.-, Q1.S
VDD | VDD1.+, RD.1
DRAIN | RD.2, Q1.D
GATE | VGS.+, Q1.G

PIN AUDIT: PASS - 9 of 9 placed component pins assigned to nets; 0 unassigned pins.
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

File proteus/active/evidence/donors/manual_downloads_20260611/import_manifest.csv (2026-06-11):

action | source | destination | sha256 | duplicate_example | bytes
deleted_duplicate_in_experiments | C:\Users\tahab\Downloads\1DCV.pdsprj |  | 20D4338D6B966D9648184604E935E3CC45DE34A44E04F3FBD0BC685507892ABD | D:\Coding\protuesgen\experiments\bidirectional_v2_orientation_dcv_temp_2026_06_07\donors\1DCV.pdsprj | 10989
deleted_duplicate_in_experiments | C:\Users\tahab\Downloads\2DCV.pdsprj |  | 68B1D69129D4326A0A560464740A629FC14CB47636F93C928C00E20120DB8A33 | D:\Coding\protuesgen\experiments\bidirectional_v2_orientation_dcv_temp_2026_06_07\donors\2DCV.pdsprj | 11125
deleted_duplicate_in_experiments | C:\Users\tahab\Downloads\45454New Project.pdsprj |  | 33A80724C2478394382199658E55B1BF5C623E1B6483F99AA7056190699879F2 | D:\Coding\protuesgen\experiments\dc_mixed_sources_v7_all3_records_temp_2026_06_04\DCMS_V7_T00_ALL3_DONOR_COPY.pdsprj | 11307
deleted_duplicate_in_experiments | C:\Users\tahab\Downloads\4xRCL_V13_T07_05_BASIC_VOLTAGE_DIVIDER.pdsprj |  | 340B5972D35CE8B63C1AAD6048C8FE33A2EA969AE2AD272ACC316CE12F8459F5 | D:\Coding\protuesgen\experiments\source_passive_v8_compact_fixed_suffix_temp_2026_06_05\donors\rcl_4x_t07_unit_donor.pdsprj | 12893
moved_to_manual_import | C:\Users\tahab\Downloads\ALLL_ICS_ALL4_RLC.pdsprj | D:\Coding\protuesgen\proteus_ic\donors\manual_downloads_20260611\ALLL_ICS_ALL4_RLC.pdsprj | 840138E789589AFD092356D587965083795849F64E80BA72C7172491E7A1096A |  | 16486
moved_to_manual_import | C:\Users\tahab\Downloads\CAp2withterm.pdsprj | D:\Coding\protuesgen\proteus_ic\donors\manual_downloads_20260611\CAp2withterm.pdsprj | 2B0661808857E844D6B676C16EACF37B5BC47F0A6F589C183A66EE2675B3EAA5 |  | 11200
moved_to_manual_import | C:\Users\tahab\Downloads\cap3.pdsprj | D:\Coding\protuesgen\proteus_ic\donors\manual_downloads_20260611\cap3.pdsprj | BF113DCCF780D67BD09CE4BE51DD26544EF25CE4EDC85322DA6B0E75292D79C8 |  | 11099
moved_to_manual_import | C:\Users\tahab\Downloads\circuit_output.pdsprj | D:\Coding\protuesgen\proteus_ic\donors\manual_downloads_20260611\circuit_output.pdsprj | 6BAFB7741BBB0E7178188D475CBA9C2A772313C50D47C446A97895F66F37D7BA |  | 12538
deleted_duplicate_in_experiments | C:\Users\tahab\Downloads\DCMS_V4_T00B_SOURCE_ONLY_STRICT_ACCEPTED_CURRENT_IDENTITY.pdsprj |  | 63B62DE21992383D20AEECC8B8106FF3DF3A9456BF4E51E7F4D19533E71BE975 | D:\Coding\protuesgen\experiments\dc_mixed_sources_v4_vrefs_clean_devices_temp_2026_06_04\DC_MIXED_SOURCES_V4_VREFS_CLEAN_DEVICES_TEST_BATCH\DCMS_V4_T00B_SOURCE_ONLY_STRICT_ACCEPTED_CURRENT_IDENTITY\DCMS_V4_T00B_SOURCE_ONLY_STRICT_ACCEPTED_CURRENT_IDENTITY.pdsprj | 11868
moved_to_manual_import | C:\Users\tahab\Downloads\ddddddddzzzzzzzzzz.pdsprj | D:\Coding\protuesgen\proteus_ic\donors\manual_downloads_20260611\ddddddddzzzzzzzzzz.pdsprj | 3515B8FA994408E16421B036FC4F1192CB664E6D838859F7F5A3281E1E8971AF |  | 13950
moved_to_manual_import | C:\Users\tahab\Downloads\HANDDRAWN_6R_CORRECTED_N0_N1_N2_N3_N4 (1).pdsprj | D:\Coding\protuesgen\proteus_ic\donors\manual_downloads_20260611\HANDDRAWN_6R_CORRECTED_N0_N1_N2_N3_N4 (1).pdsprj | 2F5EB8226C825736CA5FF15DD48177C3C5B9C52364F9EEEA9F2BF9BA62018476 |  | 11673
moved_to_manual_import | C:\Users\tahab\Downloads\HANDDRAWN_6R_CORRECTED_N0_N1_N2_N3_N4.pdsprj | D:\Coding\protuesgen\proteus_ic\donors\manual_downloads_20260611\HANDDRAWN_6R_CORRECTED_N0_N1_N2_N3_N4.pdsprj | 2F5EB8226C825736CA5FF15DD48177C3C5B9C52364F9EEEA9F2BF9BA62018476 |  | 11673
moved_to_manual_import | C:\Users\tahab\Downloads\HANDDRAWN_6R_EQUIV_N0_M0_BRANCHES.pdsprj | D:\Coding\protuesgen\proteus_ic\donors\manual_downloads_20260611\HANDDRAWN_6R_EQUIV_N0_M0_BRANCHES.pdsprj | 40E53CC462CFBC0B0965E375584E3BA1605D6CFF91217B085B303D88A4FE4601 |  | 11652
moved_to_manual_import | C:\Users\tahab\Downloads\inductor_01_single_free.pdsprj | D:\Coding\protuesgen\proteus_ic\donors\manual_downloads_20260611\inductor_01_single_free.pdsprj | ED5A8AD925AC5C6CF2EEA8D7AA9D9C8822AF275D656A9218FFDC06865D292BCD |  | 11029
moved_to_manual_import | C:\Users\tahab\Downloads\inductor_02_two_terminal.pdsprj | D:\Coding\protuesgen\proteus_ic\donors\manual_downloads_20260611\inductor_02_two_terminal.pdsprj | 72D93BDC8B822BF8D2F589BECA5AAC2A7B619293424B013F55E2DC9C0B91A3BA |  | 11144
moved_to_manual_import | C:\Users\tahab\Downloads\inductor_03_three_terminal.pdsprj | D:\Coding\protuesgen\proteus_ic\donors\manual_downloads_20260611\inductor_03_three_terminal.pdsprj | B3CFD94EA559813E4E60801AEDE25F3E4914689A269D7A8C4185F4B970FC2E95 |  | 11380
moved_to_manual_import | C:\Users\tahab\Downloads\inductor_04_power_ground.pdsprj | D:\Coding\protuesgen\proteus_ic\donors\manual_downloads_20260611\inductor_04_power_ground.pdsprj | 9057820904765CE1886A2EF35C6754E9E57424F0BF598C4757E73E003B181EBD |  | 11216
moved_to_manual_import | C:\Users\tahab\Downloads\New Project.pdsprj | D:\Coding\protuesgen\proteus_ic\donors\manual_downloads_20260611\New Project.pdsprj | D06B97BEC98B2A6990A3E9E948AFA0A848ACC56815C4C5EE458D4E2F4C979D55 |  | 11029
moved_to_manual_import | C:\Users\tahab\Downloads\New ProjectSDsd.pdsprj | D:\Coding\protuesgen\proteus_ic\donors\manual_downloads_20260611\New ProjectSDsd.pdsprj | EB8B9F956D7B5B4314364AE1EF365F991A51C704AF54033921CA4F23FF3DB40C |  | 11006
moved_to_manual_import | C:\Users\tahab\Downloads\New Projectxxxxxxxxxxxxx.pdsprj | D:\Coding\protuesgen\proteus_ic\donors\manual_downloads_20260611\New Projectxxxxxxxxxxxxx.pdsprj | 0B39507BFCA36BA1D35B543AC044939FB824C4730375A2C927C2947FA8354607 |  | 11717
moved_to_manual_import | C:\Users\tahab\Downloads\progen_output (1).pdsprj | D:\Coding\protuesgen\proteus_ic\donors\manual_downloads_20260611\progen_output (1).pdsprj | B63C459CE14008547A0C4FA53F9D12C1BF89869F4090F6162E16E964866E9C52 |  | 12164
moved_to_manual_import | C:\Users\tahab\Downloads\progen_output (2).pdsprj | D:\Coding\protuesgen\proteus_ic\donors\manual_downloads_20260611\progen_output (2).pdsprj | 323ED55F02B79FA42D923F50026687A03AA4AE5597139536E3A40271E34154CA |  | 14931
moved_to_manual_import | C:\Users\tahab\Downloads\progen_output.pdsprj | D:\Coding\protuesgen\proteus_ic\donors\manual_downloads_20260611\progen_output.pdsprj | 96459827FBACF30F9EF619C3FF37FCFC8F0A6E68816B1806FDC850B99830EAB8 |  | 57
deleted_duplicate_in_experiments | C:\Users\tahab\Downloads\RCL_V19_T01_CORRECT_21_withVsourcenCsource.pdsprj |  | B25E04C905CCDA879C3BC03E62A3D40246F710408E2221D5C9C8FD335E529AFF | D:\Coding\protuesgen\experiments\dc_mixed_sources_v10_final_unit_temp_2026_06_05\DCMS_V10_T00_DONOR_COPY.pdsprj | 14144
moved_to_manual_import | C:\Users\tahab\Downloads\rl_terminal_disconnected.pdsprj | D:\Coding\protuesgen\proteus_ic\donors\manual_downloads_20260611\rl_terminal_disconnected.pdsprj | 293F00AC5504F0F53FC514682A9CB8136DABDA8C03343850B5A54C5B6A614F36 |  | 11441
moved_to_manual_import | C:\Users\tahab\Downloads\rl_terminal_series.pdsprj | D:\Coding\protuesgen\proteus_ic\donors\manual_downloads_20260611\rl_terminal_series.pdsprj | 80FE75CA0BF60CB40F99344BB979B6A616ED77D1DA1BACBC30F260FD47C833F8 |  | 11425
moved_to_manual_import | C:\Users\tahab\Downloads\rlc.pdsprj | D:\Coding\protuesgen\proteus_ic\donors\manual_downloads_20260611\rlc.pdsprj | C858B7999399D6181225B53187F7E463E34E3387287E2F4FCEEDF9699F47D270 |  | 11565
deleted_duplicate_in_experiments | C:\Users\tahab\Downloads\SRCP_V3_DCV2_T03_R_ONLY_D0_WITH_1G_REF.pdsprj |  | B78180A47F93F4C96B9546007A72048733B249EDB3FE952E9E856C9860F03291 | D:\Coding\protuesgen\experiments\source_passive_v5_fixed_v3_order_temp_2026_06_05\donors\user_fixed_v3_t03_d0_1g_ref.pdsprj | 12159
deleted_duplicate_in_experiments | C:\Users\tahab\Downloads\testing.pdsprj |  | D85D3AECB555EF355D81F1A1855D588D6D14FF6B43D73A6B5245BBD503C4A5A4 | D:\Coding\protuesgen\experiments\dc_current_v12_manual_testing_study_temp_2026_06_03\DCI_V12_TEST_BATCH\DCI_V12_T00_ORIGINAL_MANUAL_TESTING_COPY\DCI_V12_T00_ORIGINAL_MANUAL_TESTING_COPY.pdsprj | 12419
deleted_duplicate_in_experiments | C:\Users\tahab\Downloads\AI for Proteus Simulation_files\New folder\POWER_T01_6R_V0_ATTEMPT\CONTROL_E001_EMPTY_BASE.pdsprj |  | 74532BCB33FCC293DA833D13EB30E5FA1FEC7865EBB3793EED51602EC719781F | D:\Coding\protuesgen\experiments\source_passive_v8_compact_fixed_suffix_temp_2026_06_05\donors\e001_empty_base.pdsprj | 10550
moved_to_manual_import | C:\Users\tahab\Downloads\AI for Proteus Simulation_files\New folder\POWER_T01_6R_V0_ATTEMPT\POWER_T01_6R_V0_ATTEMPT.pdsprj | D:\Coding\protuesgen\proteus_ic\donors\manual_downloads_20260611\AI for Proteus Simulation_files\New folder\POWER_T01_6R_V0_ATTEMPT\POWER_T01_6R_V0_ATTEMPT.pdsprj | FB8AB4C7BB8E1FDF6FEBE26ACD656D76FD9FC14B4B0C42F64C9A9C91FAD37793 |  | 11694
deleted_duplicate_in_experiments | C:\Users\tahab\Downloads\AI for Proteus Simulation_files\New folder\POWER_T02_R21_V0_ATTEMPT\CONTROL_E001_EMPTY_BASE.pdsprj |  | 74532BCB33FCC293DA833D13EB30E5FA1FEC7865EBB3793EED51602EC719781F | D:\Coding\protuesgen\experiments\source_passive_v8_compact_fixed_suffix_temp_2026_06_05\donors\e001_empty_base.pdsprj | 10550
moved_to_manual_import | C:\Users\tahab\Downloads\AI for Proteus Simulation_files\New folder\POWER_T02_R21_V0_ATTEMPT\POWER_T02_R21_V0_ATTEMPT.pdsprj | D:\Coding\protuesgen\proteus_ic\donors\manual_downloads_20260611\AI for Proteus Simulation_files\New folder\POWER_T02_R21_V0_ATTEMPT\POWER_T02_R21_V0_ATTEMPT.pdsprj | 04370EBBB706B0107E8438AB21CD4FFD643C90BE5D21E424970BA5603F8B16F3 |  | 13026
deleted_duplicate_in_experiments | C:\Users\tahab\Downloads\AI for Proteus Simulation_files\New folder (2)\POWER_T03_6R_V0_ENDPOINT_ATTEMPT\CONTROL_E001_EMPTY_BASE.pdsprj |  | 74532BCB33FCC293DA833D13EB30E5FA1FEC7865EBB3793EED51602EC719781F | D:\Coding\protuesgen\experiments\source_passive_v8_compact_fixed_suffix_temp_2026_06_05\donors\e001_empty_base.pdsprj | 10550
moved_to_manual_import | C:\Users\tahab\Downloads\AI for Proteus Simulation_files\New folder (2)\POWER_T03_6R_V0_ENDPOINT_ATTEMPT\POWER_T03_6R_V0_ENDPOINT_ATTEMPT.pdsprj | D:\Coding\protuesgen\proteus_ic\donors\manual_downloads_20260611\AI for Proteus Simulation_files\New folder (2)\POWER_T03_6R_V0_ENDPOINT_ATTEMPT\POWER_T03_6R_V0_ENDPOINT_ATTEMPT.pdsprj | C395CE27238229C5413C05D4C87187EFB33D4BD2AD8700F03E330FA819498228 |  | 11677
deleted_duplicate_in_experiments | C:\Users\tahab\Downloads\AI for Proteus Simulation_files\New folder (2)\POWER_T04_R21_V0_ENDPOINT_ATTEMPT\CONTROL_E001_EMPTY_BASE.pdsprj |  | 74532BCB33FCC293DA833D13EB30E5FA1FEC7865EBB3793EED51602EC719781F | D:\Coding\protuesgen\experiments\source_passive_v8_compact_fixed_suffix_temp_2026_06_05\donors\e001_empty_base.pdsprj | 10550
moved_to_manual_import | C:\Users\tahab\Downloads\AI for Proteus Simulation_files\New folder (2)\POWER_T04_R21_V0_ENDPOINT_ATTEMPT\POWER_T04_R21_V0_ENDPOINT_ATTEMPT.pdsprj | D:\Coding\protuesgen\proteus_ic\donors\manual_downloads_20260611\AI for Proteus Simulation_files\New folder (2)\POWER_T04_R21_V0_ENDPOINT_ATTEMPT\POWER_T04_R21_V0_ENDPOINT_ATTEMPT.pdsprj | 56127839EFF00D6923D8885B5683634D3B5B7FDF1AA08AF4C3CF0105A756C988 |  | 13011
deleted_duplicate_in_experiments | C:\Users\tahab\Downloads\AI for Proteus Simulation_files\New folder (2)\POWER_T05_6R_V0_OUTPUT_LABEL_ATTEMPT\CONTROL_E001_EMPTY_BASE.pdsprj |  | 74532BCB33FCC293DA833D13EB30E5FA1FEC7865EBB3793EED51602EC719781F | D:\Coding\protuesgen\experiments\source_passive_v8_compact_fixed_suffix_temp_2026_06_05\donors\e001_empty_base.pdsprj | 10550
moved_to_manual_import | C:\Users\tahab\Downloads\AI for Proteus Simulation_files\New folder (2)\POWER_T05_6R_V0_OUTPUT_LABEL_ATTEMPT\POWER_T05_6R_V0_OUTPUT_LABEL_ATTEMPT.pdsprj | D:\Coding\protuesgen\proteus_ic\donors\manual_downloads_20260611\AI for Proteus Simulation_files\New folder (2)\POWER_T05_6R_V0_OUTPUT_LABEL_ATTEMPT\POWER_T05_6R_V0_OUTPUT_LABEL_ATTEMPT.pdsprj | 827F8E054C95840D2320446CF324DBC2FF401CFC35516D9B468C54DF184252D5 |  | 11693
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

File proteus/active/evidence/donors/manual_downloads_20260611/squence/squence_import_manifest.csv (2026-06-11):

action | source | destination | sha256 | bytes
moved_from_squence | C:\Users\tahab\Downloads\squence\2_7segcomanodewithbider.pdsprj | D:\Coding\protuesgen\proteus_ic\donors\manual_downloads_20260611\squence\2_7segcomanodewithbider.pdsprj | 58CAE9E77FBD76C0ECF59815D5B99C08EEA5BB080A88040732FFF677435D6127 | 11886
moved_from_squence | C:\Users\tahab\Downloads\squence\27segcomanode.pdsprj | D:\Coding\protuesgen\proteus_ic\donors\manual_downloads_20260611\squence\27segcomanode.pdsprj | E843E12A7A94D8BEDF110D13FDAB28D2EECC576C36BFC0496F1D9C49C88C5FA0 | 11452
moved_from_squence | C:\Users\tahab\Downloads\squence\4_74HC192withRLC.pdsprj.M_TAHABINZAEEM.tahab.workspace | D:\Coding\protuesgen\proteus_ic\donors\manual_downloads_20260611\squence\4_74HC192withRLC.pdsprj.M_TAHABINZAEEM.tahab.workspace | B4A3A7935B2B1474B94FCD8FE4E58697F116D10E8E5C90398E97566A738245E5 | 1378
moved_from_squence | C:\Users\tahab\Downloads\squence\4_7segcomanodewithbider.pdsprj | D:\Coding\protuesgen\proteus_ic\donors\manual_downloads_20260611\squence\4_7segcomanodewithbider.pdsprj | 0774A4FA3B93AC0DB0C2FFB9B218DE80C3A01B4BA8B83E11946DB1D07FCB0A2B | 12352
moved_from_squence | C:\Users\tahab\Downloads\squence\4_7segcomanodewithbiderand1_7447.pdsprj | D:\Coding\protuesgen\proteus_ic\donors\manual_downloads_20260611\squence\4_7segcomanodewithbiderand1_7447.pdsprj | 5BBB6BCFCEA5418128E8FA1ABDE61BA7FD1BB69163A24CC6FAB1E28854888641 | 12912
moved_from_squence | C:\Users\tahab\Downloads\squence\4_7segcomanodewithbiderand4_7447.pdsprj | D:\Coding\protuesgen\proteus_ic\donors\manual_downloads_20260611\squence\4_7segcomanodewithbiderand4_7447.pdsprj | F8FF767024C610E302849EC63F9591359A2962D9FE272F7FFF9BC9785BE157B7 | 13088
moved_from_squence | C:\Users\tahab\Downloads\squence\4017.pdsprj.M_TAHABINZAEEM.tahab.workspace | D:\Coding\protuesgen\proteus_ic\donors\manual_downloads_20260611\squence\4017.pdsprj.M_TAHABINZAEEM.tahab.workspace | 829B705F32E4C24C5CB9D08F331FB9B0A1F752DEF1596F20A6D820212031EFD9 | 1390
moved_from_squence | C:\Users\tahab\Downloads\squence\4020.pdsprj.M_TAHABINZAEEM.tahab.workspace | D:\Coding\protuesgen\proteus_ic\donors\manual_downloads_20260611\squence\4020.pdsprj.M_TAHABINZAEEM.tahab.workspace | 1108304C905A29C40766E5C09AC6D51F8688D418EF510B2FA4C21C0EFEF77C6D | 1390
moved_from_squence | C:\Users\tahab\Downloads\squence\74HC4024.pdsprj.M_TAHABINZAEEM.tahab.workspace | D:\Coding\protuesgen\proteus_ic\donors\manual_downloads_20260611\squence\74HC4024.pdsprj.M_TAHABINZAEEM.tahab.workspace | 578BA5B8EEB9779FB4C2D6306EEA1996F86235F210BCB73568B425AFF12F1520 | 1390
moved_from_squence | C:\Users\tahab\Downloads\squence\7segcomanode.pdsprj | D:\Coding\protuesgen\proteus_ic\donors\manual_downloads_20260611\squence\7segcomanode.pdsprj | A67F9E49288201A6A52C78E6C8BAC97E5FB6832A6585320BC0836E5A09165C3B | 11373
moved_from_squence | C:\Users\tahab\Downloads\squence\7segcomanodewithbider.pdsprj | D:\Coding\protuesgen\proteus_ic\donors\manual_downloads_20260611\squence\7segcomanodewithbider.pdsprj | E58F1A20CC34D689D966B2EE8DBF0AFD922506BA3B0C85335055F7C44680FB8F | 11658
moved_from_squence | C:\Users\tahab\Downloads\squence\acombination of ics.pdsprj | D:\Coding\protuesgen\proteus_ic\donors\manual_downloads_20260611\squence\acombination of ics.pdsprj | 62251F5C5E7DF1BDC1D73D9E1F3EE1782F6DC443240B913A8F5CB74888C80EF9 | 25503
moved_from_squence | C:\Users\tahab\Downloads\squence\acombination of ics.pdsprj.M_TAHABINZAEEM.tahab.workspace | D:\Coding\protuesgen\proteus_ic\donors\manual_downloads_20260611\squence\acombination of ics.pdsprj.M_TAHABINZAEEM.tahab.workspace | B15018089D08622654BAB3FEB8E3103428577B0DAC242AAC1EE566E6C949D083 | 1410
moved_from_squence | C:\Users\tahab\Downloads\squence\MIX_ANALOG_LM741_NE555_NPN_PNP_ELECCAP_RCL.pdsprj | D:\Coding\protuesgen\proteus_ic\donors\manual_downloads_20260611\squence\MIX_ANALOG_LM741_NE555_NPN_PNP_ELECCAP_RCL.pdsprj | F753A38E213717B308E11794389F20FE472BB9BE34CB913CA90F2B78C9199BCC | 13711
moved_from_squence | C:\Users\tahab\Downloads\squence\MIX_ANALOG_LM741_NE555_NPN_PNP_ELECCAP_RCL.pdsprj.M_TAHABINZAEEM.tahab.workspace | D:\Coding\protuesgen\proteus_ic\donors\manual_downloads_20260611\squence\MIX_ANALOG_LM741_NE555_NPN_PNP_ELECCAP_RCL.pdsprj.M_TAHABINZAEEM.tahab.workspace | 0A48AAA9822E39A22A189FDD7CD8F55102C6781A394ED0199DA74EB7553840A9 | 1402
moved_from_squence | C:\Users\tahab\Downloads\squence\MIX_FLIPFLOP_REGISTERS_74HC74_74HC76_4027_74HC174_74HC273.pdsprj | D:\Coding\protuesgen\proteus_ic\donors\manual_downloads_20260611\squence\MIX_FLIPFLOP_REGISTERS_74HC74_74HC76_4027_74HC174_74HC273.pdsprj | 49941E56DF70B0FB26434A550AAC53DFF50D7F8BC2E23A19418621DF05F02016 | 12516
moved_from_squence | C:\Users\tahab\Downloads\squence\MIX_SYNC_COUNTERS_160_161_163_192_193.pdsprj | D:\Coding\protuesgen\proteus_ic\donors\manual_downloads_20260611\squence\MIX_SYNC_COUNTERS_160_161_163_192_193.pdsprj | 425D51C8FCEE6652FAA4466BF8774E78D3726C0C646677CEBE396656CEBF56EE | 11995
moved_from_squence | C:\Users\tahab\Downloads\squence\MIX_TIMING_NE555_7490_4017_4020.pdsprj | D:\Coding\protuesgen\proteus_ic\donors\manual_downloads_20260611\squence\MIX_TIMING_NE555_7490_4017_4020.pdsprj | 831449BC44C6DC9C2782008D67BF89E746FA881E072330DABFAFEDBC7A767CFC | 12188
moved_from_squence | C:\Users\tahab\Downloads\squence\PAIR_4017_4020.pdsprj | D:\Coding\protuesgen\proteus_ic\donors\manual_downloads_20260611\squence\PAIR_4017_4020.pdsprj | D9B7AADCB72235665F32B48E8B8BDF65A0FD0F156B48FB0C89F149D703D1499B | 11521
moved_from_squence | C:\Users\tahab\Downloads\squence\PAIR_4017_74HC4024.pdsprj | D:\Coding\protuesgen\proteus_ic\donors\manual_downloads_20260611\squence\PAIR_4017_74HC4024.pdsprj | F50E8B6BC1A2285983B8C21A53AF8E94A00931211C6C21197D1C7658D9296B71 | 11559
moved_from_squence | C:\Users\tahab\Downloads\squence\PAIR_4020_74HC4024.pdsprj | D:\Coding\protuesgen\proteus_ic\donors\manual_downloads_20260611\squence\PAIR_4020_74HC4024.pdsprj | 8E08EB0F4FFB86B413ED44AF6A37FA18D2AF3E10E8BDBE4153D6735E6F94AC1B | 11475
moved_from_squence | C:\Users\tahab\Downloads\squence\PAIR_4518_74HC4520.pdsprj | D:\Coding\protuesgen\proteus_ic\donors\manual_downloads_20260611\squence\PAIR_4518_74HC4520.pdsprj | 0977C6AA46639D2CE212632AF9A2EA481A28A98EDBACEF61B0D440767E5316AC | 11413
moved_from_squence | C:\Users\tahab\Downloads\squence\PAIR_7490_4017.pdsprj | D:\Coding\protuesgen\proteus_ic\donors\manual_downloads_20260611\squence\PAIR_7490_4017.pdsprj | 60DF9B1F3C41EEBE1124BF17E823F29FFD85BD5614D1A81052DF034B5D02ADBB | 11606
moved_from_squence | C:\Users\tahab\Downloads\squence\PAIR_7490_4020.pdsprj | D:\Coding\protuesgen\proteus_ic\donors\manual_downloads_20260611\squence\PAIR_7490_4020.pdsprj | A83CA2C6582E95CFD071FE516D6A6EF6911B3B071644AE3C5743E6C9AD615185 | 11591
moved_from_squence | C:\Users\tahab\Downloads\squence\PAIR_7490_4518.pdsprj | D:\Coding\protuesgen\proteus_ic\donors\manual_downloads_20260611\squence\PAIR_7490_4518.pdsprj | E14B5D470AD2062A1E53C9429144B1846ECA729A65171C953AAD3094A206B7CF | 11667
moved_from_squence | C:\Users\tahab\Downloads\squence\PAIR_7490_74HC160.pdsprj | D:\Coding\protuesgen\proteus_ic\donors\manual_downloads_20260611\squence\PAIR_7490_74HC160.pdsprj | 77D7FDC8AE34CBD9CD45D2FC306B76DE6FAFA47C6963895104C91F4DEAAFF8BF | 11454
moved_from_squence | C:\Users\tahab\Downloads\squence\PAIR_7490_74HC161.pdsprj | D:\Coding\protuesgen\proteus_ic\donors\manual_downloads_20260611\squence\PAIR_7490_74HC161.pdsprj | B0D1E60251A3089D4663860AF75771AF3AB02B50BB93B8CCFB7451F058069614 | 11555
moved_from_squence | C:\Users\tahab\Downloads\squence\PAIR_7490_74HC163.pdsprj | D:\Coding\protuesgen\proteus_ic\donors\manual_downloads_20260611\squence\PAIR_7490_74HC163.pdsprj | 1FF1A293C4F085A91EE95E6ED45A829B1BE8B1D19E83D7120EF575C1C84586F5 | 11557
moved_from_squence | C:\Users\tahab\Downloads\squence\PAIR_7490_74HC192.pdsprj | D:\Coding\protuesgen\proteus_ic\donors\manual_downloads_20260611\squence\PAIR_7490_74HC192.pdsprj | 6DD876DFEE1CD9FC2CA3D065A54787DC2EC1328849BC1394C5C14E5D6141B9B9 | 11570
moved_from_squence | C:\Users\tahab\Downloads\squence\PAIR_7490_74HC193.pdsprj | D:\Coding\protuesgen\proteus_ic\donors\manual_downloads_20260611\squence\PAIR_7490_74HC193.pdsprj | E0853F14BA3B1304F1AF9226660F55926746E5800049289765304649BD22EB6A | 11578
moved_from_squence | C:\Users\tahab\Downloads\squence\PAIR_7490_74HC4024.pdsprj | D:\Coding\protuesgen\proteus_ic\donors\manual_downloads_20260611\squence\PAIR_7490_74HC4024.pdsprj | E10730112DD1A19C18A925D86A230EE7F401ABCB4646EA26325FC328B178383B | 11588
moved_from_squence | C:\Users\tahab\Downloads\squence\PAIR_7490_74HC4040.pdsprj | D:\Coding\protuesgen\proteus_ic\donors\manual_downloads_20260611\squence\PAIR_7490_74HC4040.pdsprj | 30C0A84CA89576C21F0760A286CB2444AA7E1D682A038FC20BA87C9536C900F2 | 11623
moved_from_squence | C:\Users\tahab\Downloads\squence\PAIR_7490_74HC4060.pdsprj | D:\Coding\protuesgen\proteus_ic\donors\manual_downloads_20260611\squence\PAIR_7490_74HC4060.pdsprj | 73D95B2670BED40BA30A656E4EB3667F8257A39DA579BD8B39D31601E720670E | 11646
moved_from_squence | C:\Users\tahab\Downloads\squence\PAIR_7490_74HC4520.pdsprj | D:\Coding\protuesgen\proteus_ic\donors\manual_downloads_20260611\squence\PAIR_7490_74HC4520.pdsprj | 502F028196D7C59E86D5C219E22E0C02FBF90E9F5142A95F904B32C22397763C | 11637
moved_from_squence | C:\Users\tahab\Downloads\squence\PAIR_74HC157_74HC151.pdsprj | D:\Coding\protuesgen\proteus_ic\donors\manual_downloads_20260611\squence\PAIR_74HC157_74HC151.pdsprj | C5E6879B48BAE9C1E8A08ED2877BFA92E47E49472BD41F2D5D6038A76ED661BF | 11483
moved_from_squence | C:\Users\tahab\Downloads\squence\PAIR_74HC160_74HC161.pdsprj | D:\Coding\protuesgen\proteus_ic\donors\manual_downloads_20260611\squence\PAIR_74HC160_74HC161.pdsprj | 49C65E590FA0793920AD41D6DF3396957BA33860A9B94C667FF6BB31F7E8694C | 11461
moved_from_squence | C:\Users\tahab\Downloads\squence\PAIR_74HC160_74HC163.pdsprj | D:\Coding\protuesgen\proteus_ic\donors\manual_downloads_20260611\squence\PAIR_74HC160_74HC163.pdsprj | 95080A57FB220CE81951F66A4DECCF3EF8035680F01FF875C890D8E047531154 | 11461
moved_from_squence | C:\Users\tahab\Downloads\squence\PAIR_74HC160_74HC192.pdsprj | D:\Coding\protuesgen\proteus_ic\donors\manual_downloads_20260611\squence\PAIR_74HC160_74HC192.pdsprj | 176580F0C94E2EDD32412C1A9CE66A4D948E2F82091DB9C3D4F6FC9F9115AE4C | 11507
moved_from_squence | C:\Users\tahab\Downloads\squence\PAIR_74HC160_74HC193.pdsprj | D:\Coding\protuesgen\proteus_ic\donors\manual_downloads_20260611\squence\PAIR_74HC160_74HC193.pdsprj | F60CE2EB2FCE5325E2688120B53F96B26C2E4B9F16D6BD56B3466AF2FDED1F23 | 11537
moved_from_squence | C:\Users\tahab\Downloads\squence\PAIR_74HC161_74HC163.pdsprj | D:\Coding\protuesgen\proteus_ic\donors\manual_downloads_20260611\squence\PAIR_74HC161_74HC163.pdsprj | FB902BDCDD4ACF429848379F29E6E6DEB8DC8DE1E8CEB2C65DE098F71C21F308 | 11416
moved_from_squence | C:\Users\tahab\Downloads\squence\PAIR_74HC161_74HC192.pdsprj | D:\Coding\protuesgen\proteus_ic\donors\manual_downloads_20260611\squence\PAIR_74HC161_74HC192.pdsprj | 8A3257FD653D0561329E20E4AF50ABCE5D6DA88FFEB74947EC2ECB6375447329 | 11553
moved_from_squence | C:\Users\tahab\Downloads\squence\PAIR_74HC161_74HC193.pdsprj | D:\Coding\protuesgen\proteus_ic\donors\manual_downloads_20260611\squence\PAIR_74HC161_74HC193.pdsprj | 90321BFA036A3205D1745AC4D3218438F224DFF16C5538D7439380CE567437AD | 11541
moved_from_squence | C:\Users\tahab\Downloads\squence\PAIR_74HC165_74HC595.pdsprj | D:\Coding\protuesgen\proteus_ic\donors\manual_downloads_20260611\squence\PAIR_74HC165_74HC595.pdsprj | E0DD85A30E64BA12F81E1CA9CF4452216B089D0629F0A5558FFF5BA4A6408930 | 11720
moved_from_squence | C:\Users\tahab\Downloads\squence\PAIR_74HC174_74HC273.pdsprj | D:\Coding\protuesgen\proteus_ic\donors\manual_downloads_20260611\squence\PAIR_74HC174_74HC273.pdsprj | 5F313BD576C7C1041E7A1D3C20ACE25C392B43FE39EA19A888003AB86A6F4148 | 11594
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

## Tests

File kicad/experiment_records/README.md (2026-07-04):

# KiCad Experiments Log

Date started: 2026-07-01

This folder is the record book for generator experiments. Active examples stay in
`kicad/examples/` so tests and scripts have stable paths. Experiment folders keep
snapshots, reports, and notes about what was tested, what happened, what came
before, and what should happen next.

## Runs

| Run | Status | What it records |
| --- | --- | --- |
| `runs/kicad_cli_smoke` | Passed | Early KiCad CLI load/ERC smoke test for a simple generated VDC/resistor project. |
| `runs/placer_smoke` | Passed | Placement-only smoke output with `placement.json` and `placement_trace.json`. |
| `runs/practical_placer_pack` | Passed | 20 practical component-only inputs, placement traces only. |
| `runs/practical_placer_projects_placeholder_boxes_2026_07_01` | Historical failed direction | Old 20-project run that used `ProgenPlace:*` placeholder symbols. KiCad loaded it, but the symbols were boxes/names, not real components. |
| `runs/practical_placer_projects_real_symbols_flattened_2026_07_01` | Passed | 20 generated projects using real embedded KiCad symbols, flattened derived symbols, and multi-unit expansion. |
| `runs/practical_placer_projects_circuitir_inputs_real_symbols_2026_07_01` | Passed, superseded | Same fixed real-symbol projects regenerated from partial CircuitIR-shaped v0.2 inputs with `project`, `components`, `nets`, and component `id`/`kind`/`value`. Superseded by the immutable v2 examples runs. |
| `runs/beautifier_wire_planner_t01_t10_2026_07_02` | Passed with expected wire limit | Wire planner smoke passed on a connected VDC/resistor/LED circuit. Arrangement and beautifier passed on T01-T10 stress circuits with zero post-beautifier overlaps. Wire routing on T01-T10 was correctly skipped because those inputs contain no pin/net connection endpoints. |
| `runs/final_json_t01_t10_connected_v1_interrupted_2026_07_02` | Interrupted, recorded | First connected final-JSON run. T01-T09 reports were written; T10 routing exposed unbounded A* search. |
| `runs/final_json_t01_t10_connected_v2_interrupted_2026_07_02` | Interrupted, recorded | Second connected final-JSON run. A* expansion cap existed, but batch reporting still attempted too many routes before `max_wired_routes` existed. |
| `../examples/placer_run_2026_07_01_baseline_c11_spacing_fix_v2` | Current baseline examples | Fresh immutable 20-circuit baseline with C11 spacing fixed. KiCad quality: 20 checked, 20 passed, 0 failed. |
| `../examples/placer_run_2026_07_01_stress_limit_suite_v2` | Current stress examples | Fresh immutable stress/limit suite requested by user. KiCad quality: 22 checked, 22 passed, 0 failed. |
| `../examples/final_json_run_2026_07_02_132530_t01_t10_connected_v3` | Current connected JSON examples | Final JSON validation, placement conversion, arrangement, and beautifier passed 10/10. Wire planner produced bounded reports with recorded fallback/crossing warnings. |
| `../examples/final_json_project_run_2026_07_02_133420_t01_t10_connected_projects_v1` | Current final-JSON placement projects | 10 KiCad placement projects generated from final JSON. Static quality: 10 checked, 10 passed, 0 failed. Kept as the pre-wire-maker project record. |
| `../examples/final_json_wired_project_run_2026_07_02_134715_t01_t10_connected_wired_v1` | Superseded wired projects | First KiCad wire-maker run. It generated real wire/label objects but exposed unresolved pin-alias coverage and checker discovery gaps. |
| `../examples/final_json_wired_project_run_2026_07_02_134931_t01_t10_connected_wired_v2` | Superseded wired projects | Second KiCad wire-maker run. Static quality passed after checker discovery was updated, but T10 still had avoidable Arduino/CH340 alias misses. |
| `../examples/final_json_wired_project_run_2026_07_02_135207_t01_t10_connected_wired_v3` | Superseded wired projects | Third KiCad wire-maker run. It fixed avoidable T10 pin aliases but was superseded because the schematic sheet note still said placement-only. |
| `../examples/final_json_wired_project_run_2026_07_02_135608_t01_t10_connected_wired_v4` | Current wired projects | 10 KiCad wired projects generated from final JSON. Static quality: 10 checked, 10 passed, 0 failed. 3357 wire objects, 530 labels, 18 unresolved symbol-model pins, and 5 deferred T10 route-cap nets. |
| `../examples/final_json_wired_project_run_2026_07_02_164836_t01_t10_connected_wired_v5_geometry_rules` | Current strict failure evidence | First run with hard wire-geometry validation. Static quality and KiCad netlist export passed 10/10, but ERC quality passed 1/10 and geometry validation passed 0/10. The current router is not accepted. |
| `runs/router_lane_dense_t10_2026_07_03` | Current router stress evidence | Planner-only T10 strict-wire stress probe after lane routing and dense scoring. 190 components, 554 resolved pins, 0 body overlaps, 11.8 s planner time, 89 complete wire nets, 16 partial-wire nets, 48 unroutable nets, 0 labels, and 1257 different-net crossings. Not accepted as final strict-wire output. |
| `runs/component_motion_first_crossing_allowed_t10_2026_07_03` | Current routing policy evidence | Planner-only T10 probe after making component movement happen before route search in `plan_wiring()` and allowing wire-wire crossings. 190 components, 554 resolved pins, 0 body overlaps, 7.87 s planner time, 89 complete wire nets, 16 partial-wire nets, 48 unroutable nets, and 0 labels. Not accepted because incomplete nets remain. |
| `runs/routeability_variant_selector_t10_2026_07_03` | Current routeability selector evidence | Planner-only T10 probe after adding parallel routeability-scored arrangement variants. Selected `compact_flow` from 5 variants with 4 workers. Result: 152 complete wire nets, 1 partial-wire net, 0 unroutable nets, 0 labels, 26.13 s planner time. Not accepted because one partial net remains. |
| `runs/exact_pin_retry_t10_2026_07_03` | Superseded exact-pin evidence | Full exact KiCad pin/body verifier reached 0 unresolved pins, 0 labels, 0 unroutable nets, and 0 geometry violations, but still had 6 partial exact nets. Superseded by strict-wire motion repair. |
| `runs/strict_wire_motion_repair_t10_2026_07_03` | Rechecked, not final accepted | Fresh exact KiCad T10 project generated in `../examples/final_json_wired_project_run_2026_07_03_213416_t10_exact_strict_wire_repair_v1`. Older internal validators passed with 190 components, 554 resolved routing pins, 1503 wire objects, 0 labels, 0 partial/unrouted nets, and 0 geometry violations. The 2026-07-04 hosted expected-net validator now finds 3 merged expected-net groups and 1 power/GND short, so T10 is not accepted until cross-net merge repair lands. |
| `runs/local_netlist_merge_repair_t10_2026_07_04` | Current local netlist evidence | Added hosted KiCad schematic expected-net comparison, physical pin conflict checks, rotation-aware beautifier support, strict invalid-route rejection, and several T10 repair attempts through v7. v7 has clean geometry and no power/GND short, but the validator reports 17 physical pin conflicts in the T10 final JSON, 102 failed expected nets after invalid routes are refused, and 17 merged expected-net groups. T10 is blocked on final JSON pin allocation plus upstream router work. |

## Current Baseline

The current supported placer baseline is:

- 20 practical circuits.
- 100 requested component kinds.
- Real KiCad symbol embedding from `kicad/source_pack/kicad_symbol_subset_v10_0_4.json`.
- Partial CircuitIR-shaped placer inputs using `progen-kicad-placer-ir/v0.2`.
- No `ProgenPlace:*` placeholders.
- No embedded `(extends ...)` inheritance in generated schematics.
- KiCad CLI quality check: 20 schematics checked, 20 passed, 0 failed.
- Current stress evidence: 22 schematics checked, 22 passed, 0 failed.
- Current connected JSON evidence: 10 final JSON circuits checked, 10 passed;
  T10 has 190 components, 153 nets, and 554 endpoints.
- Current final-JSON project evidence: 10 KiCad placement schematics checked, 10
  passed, 0 failed; total 430 components and 442 symbol instances.
- Current wired project evidence: 10 KiCad wired schematics checked, 10 passed,
  0 failed; total 430 components, 442 symbol instances, 3357 wire objects, and
  530 labels.
- Current known wired limits: v4 static validation passed but skipped ERC before
  the bundled CLI was wired into the checker; T07 has two artificial
  `LM358.BIAS` unresolved endpoints; T08 needs a better LED array/DIP-common
  symbol model; T10 has five deferred nets from the bounded route cap.
- Historical strict geometry evidence: the bundled KiCad CLI can export
  netlists for all 10 v5 schematics, but that run used the older
  no-crossing/no-component-body-touch rule set and failed ERC quality for 9 of
  10 schematics.
- Current router stress evidence: dense lane routing can finish the 190
  component T10 planner probe in bounded time with all 554 routing pins
  resolved and no component body overlaps, but it still leaves partial and
  unroutable nets. The next accepted-output blocker is movement-first
  routeability planning against the strict geometry/connectivity validators.
- Current strict-wire routing evidence: exact KiCad T10 reaches all 153 expected
  nets with 401 routed branches, 1503 emitted wire objects, 0 labels, 0
  unresolved pins, 0 partial/unrouted nets, and 0 geometry violations, but the
  new local expected-net validator finds accidental cross-net merges. The next
  accepted-output blocker is router/validator repair for endpoint-to-segment
  cross-net joins before ERC cleanup can be treated as the remaining issue.
- Current local expected-net evidence: the hosted validator now resolves KiCad
  symbol pins and finds 17 physical pin conflicts in T10. A final JSON that
  assigns one real component pin to multiple unrelated nets must fail before
  routing; otherwise KiCad will correctly merge those nets at the symbol pin.

## Rules For New Experiments

1. Keep a stable active output in `kicad/examples/` when scripts/tests need it.
2. Copy or move each important experiment snapshot into `kicad/experiment_records/runs/<run_name>/`.
3. Add a `README.md` in the run folder with:
   - what was tested
   - previous state
   - outcome
   - known limits
   - next step
4. Keep machine-readable evidence when available: manifests, placement traces, ERC reports, quality reports.
5. Do not overwrite old experiment folders. Add a new dated folder when behavior meaningfully changes.

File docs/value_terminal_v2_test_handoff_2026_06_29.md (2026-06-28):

# Value and Terminal V2 Test Handoff

## Why V2 Exists

Proteus feedback showed that V1 CAP-ELEC mutation failed and V1 bidirectional
terminals were not attached. V2 narrows the value syntax and expands terminal
coverage without pretending that visual proximity is wiring.

## Value Pack

Archive:

`experiments/VALUE_CHANGER_PROBE_V2_SAFE_VALUES_TEMP_2026_06_26.zip`

Check:

1. Every project opens.
2. Every project displays 15 components.
3. Values visibly vary across the row.
4. `V03_CAP_ELEC_15X_VALUES` opens without bad-object or DLL errors and shows
   values such as `1uF`, `2uF`, and `3uF`.

The source cases use explicit unit-bearing values (`1V`..`9V`, `1A`..`9A`).
VSINE and VPULSE mutation remain blocked.

## Terminal Pack

Archive:

`experiments/TERMINAL_PLACER_BIDIR_PROBE_V2_ALL_FAMILIES_TEMP_2026_06_26.zip`

Cases:

- T01: passives and discrete devices.
- T02: all 22 currently supported IC families plus both displays.
- T03: sources, controls, and new-component families.

Check:

1. Each project opens without a DLL/bad-object error.
2. Left-side bidirectional triangles face into the component from the left.
3. Right-side bidirectional triangles face into the component from the right.
4. Report which families have terminals directly touching real pins.
5. Report which families show gaps, wrong Y anchors, or need short wires.

Expected limitation: V2 emits no `WIRE` records. It is a pin-anchor diagnostic,
not the final attached-terminal implementation.

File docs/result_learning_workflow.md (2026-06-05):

# Result Learning Workflow

This file explains how future Codex sessions should learn from user-tested Proteus project batches.

## Main idea

Every user-tested file should produce a durable record. Read the user's TXT observations first, then compare the project files.

## Batch checklist

For each returned test folder, record:

```text
- test name
- control file name
- generated file name
- resaved file name, if present
- did it open
- did it show the intended circuit
- did save-as work
- visible differences
- notes from screenshot or user text
```

## Classification labels

Use one label per test:

```text
PASS
PASS_WITH_CHANGES
OPENED_BUT_NOT_CORRECT
CONTROL_BAD_TOO
GENERATED_BAD
INCONCLUSIVE
```

## Compare these project parts

For every `.pdsprj`, extract and summarize:

```text
PROJECT.XML
ROOT.DSN
ROOT.CDB
SCRIPTS/PWRRAILS.DAT
```

Record file size and SHA256 for each part.

## Current meaning of project parts

Working model:

```text
PROJECT.XML = metadata
ROOT.DSN = visible schematic and layout
ROOT.CDB = component metadata
PWRRAILS.DAT = copied from template for now
```

## Important search markers

Search text strings in ROOT.DSN and ROOT.CDB:

```text
RESISTOR
74HC08
LOGICSTATE
LOGICPROBE
BUTTON
SWITCH
VCC
GND
WIRE
TERMINAL
```

## Knowledge files to update

After analysis, update:

```text
knowledge/test_results.jsonl
knowledge/rules.json
knowledge/authority_model.json
knowledge/component_db.json
knowledge/source_use_policy.json
knowledge/open_questions.json
```

## What Codex should tell the user

After each batch, Codex should report:

```text
1. which tests passed
2. which tests failed
3. what source files are safe
4. what source files should be avoided
5. what rule changed
6. what repo files were updated
7. the next smallest useful experiment
```

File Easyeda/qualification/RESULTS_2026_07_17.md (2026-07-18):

# EasyEDA Qualification Results - 2026-07-17

## Codex 5.6 Result

This result is the strongest evidence of the Codex 5.6 EasyEDA delivery. 5.6
single-handedly built the donor-native generator, portable executable, input
fixer, compact routing rules, PCB path, native validators, and release/opening
automation that this untouched 300-circuit corpus exercises. It then used
installed EasyEDA Pro to open the hardest projects and used the visual findings
to eliminate confusing collinear wire stacks and whole-sheet routing loops.

The 300/300 result is therefore not a superficial export count. It represents
the immense 5.6 improvement over the earlier 5.5 exploratory phase: exact
source records, complete source-pin accounting, expected-net comparison,
bounded physical connectivity, immutable evidence, portable replay, and
native-application acceptance all working together.

## Shipping Confirmation

The final rebuilt portable, including truthful NDJSON progress events and the
grid-aware compactness validator, was rerun over the complete untouched corpus.

- 300/300 pipeline passes.
- 300/300 exact expected-versus-native netlist passes.
- 300/300 complete source-pin coverage passes.
- 300/300 bounded PCB-ready projects.
- Zero input-fixer changes, guessed nets, validation errors, or PCB withholding.
- Average generation time: 4.6313 seconds.
- Maximum generation time: 28.3512 seconds.
- Total wall time with eight workers: 175.6825 seconds.

Immutable local report:

`/home/zaruka/Documents/easyeda_shipping_runs/2026_07_17_152456_997186_qualification/qualification_report.json`

Independent release audit:

- 300 unique filenames equal 300 canonical project names.
- 300 unique descriptive project titles.
- 30 named circuit archetypes by 10 deployment profiles.
- 4,670 component instances and 11,440 exact nets.
- All 57 physical donor families plus both native terminal families covered.
- Every circuit passes the deterministic fixer with zero changes.

The extracted website handoff was applied to a clean checkout of website commit
`a236ecdb509fbdba7322d4f62360e9f4435b9225`. Its production TypeScript/Vite/SSR
build and packaged EasyEDA integration test both passed.

## Portable Pipeline

Corpus:

`Easyeda/qualification/corpora/2026_07_17_full_pin_300_v1/`

Result:

- 300 inputs executed by `Easyeda/dist/progen-easyeda`.
- 300 schematic pipeline passes.
- 300 exact expected-versus-actual netlist passes.
- 300 complete unique donor-pin coverage passes.
- 300 PCB-ready projects.
- Zero input-fixer changes.
- Zero `GUESS_*` nets.
- All 57 physical donor families represented.
- Average generation time: 4.7253 seconds.
- Maximum generation time: 59.4342 seconds.
- Independent SQLite quick-check: 300/300.

Immutable local report:

`/home/zaruka/Documents/easyeda_qualification_runs/2026_07_17_004916_428982_qualification/qualification_report.json`

## Native Inspection

The 10 most complex variant-1 projects were selected by descending net count,
then component count. Each was opened from a disposable copy through the
registered EasyEDA Pro file association and remained available for direct
inspection for 20 seconds after native conversion.

Result:

- 10/10 opened.
- Nine opened on the first attempt.
- The STM32 RS485 controller opened on the second bounded attempt.
- No automated screenshots were taken.
- The audited original `.eprj` files remained unchanged.
- No GPU fatal error or core dump occurred with the software-rendering
  launcher.

The inspected set ranged from the 110-net multi-MCU communications bridge to
the 53-net STM32 RS485 controller.

Immutable local report:

`/home/zaruka/Documents/easyeda_native_acceptance_runs/2026_07_17_010838_967579_native_acceptance/native_acceptance_report.json`

## Test Suite

- `27 passed` in `Easyeda/tests` after the release-audit, progress-streaming,
  wire-readability, and compactness
  hardening.
- The locked all-supported-families project passed independently in 24.95
  seconds.
- Python compile checks passed.
- `git diff --check` passed.

Native inspection complements the deterministic validators; it does not
replace electrical design review or manufacturing sign-off.

## Wire Readability Qualification

The schematic router, terminal placer, and independent validator now enforce a
hard no-collinear-overlap rule for different nets. Point crossings remain
legal. The most complex 10 untouched inputs were regenerated through the
portable executable after the final single-endpoint terminal change.

Result:

- 10/10 portable generations passed.
- 10/10 exact expected-versus-actual netlists passed.
- 10/10 complete source-pin coverage checks passed.
- Zero deterministic geometry errors.
- Average generation time: 15.8201 seconds.
- Maximum generation time: 37.9868 seconds for the 110-net dual-MCU project.

Immutable local report:

`/home/zaruka/Documents/easyeda_readability_runs/2026_07_17_022118_920227_qualification/qualification_report.json`

The final 110-net `.eprj` was opened in EasyEDA Pro, its Schematic document was
loaded, and the pin-routing region was visually inspected at 140% zoom.
Distinct pin escapes and trunks remained separately traceable; crossings were
visible, but unrelated nets did not share collinear spans. Inspection images:

- `/tmp/easyeda_q11_canvas2.png`
- `/tmp/easyeda_q11_zoom_toolbar.png`
- `/tmp/easyeda_q11_pin_zoom.png`

## Compact Routing Qualification

The readability fix was extended with a hard compactness contract after visual
inspection showed that globally increasing lane numbers could create
sheet-length perimeter loops. The final planner uses per-branch local lanes,
bounded detours, exact terminal keepouts, a second pass for newly discovered
combination-mode terminal fallbacks, and compact terminal banks. The native
validator independently rejects emitted wires outside the bounded component
envelope.

On the 110-net dual-MCU project, the component envelope was
`160..1766 x 160..1934`. The old route envelope reached approximately
`-15000..17500`; the accepted route envelope is `80..1810 x 86..1992`, only
44-80 units beyond the actual design.

Final portable result:

- 10/10 complex generations passed.
- 10/10 exact expected-versus-actual netlists passed.
- Zero validation or compactness errors.
- Average generation time: 8.0148 seconds.
- Maximum generation time: 20.1648 seconds.
- 10/10 retained validated PCB output.

Immutable local report:

`/home/zaruka/Documents/easyeda_compactness_runs/2026_07_17_130707_810819_qualification/qualification_report.json`

The exact compact 110-net `.eprj` was opened in EasyEDA Pro, remained stable,
and retained its pre-open SHA-256. Its full schematic was visually accepted as
compact and traceable. Inspection image:

- `/tmp/easyeda_compact_q11_open.png`

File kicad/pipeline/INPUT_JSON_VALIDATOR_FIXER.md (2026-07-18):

# Input JSON Validator/Fixer

## Codex 5.6 Deterministic Repair

Codex 5.6 built this general repair layer so ordinary imperfect JSON can become
a safe canonical circuit request without relying on an AI guess at generation
time. The 5.6 improvement is substantial: every repair is recorded, every
invented connectivity decision is visibly terminalized as `GUESS_TERMINAL_*`,
and the same repaired contract reaches placement, routing, validation, PCB, and
the portable executable.

Canonical module:

```text
kicad/pipeline/input_json_validator_fixer.py
```

This stage is backend-neutral where possible and deterministic. It is not
special-cased to the 500-circuit stress file. Its job is to accept loose main
JSON, repair safe structural problems, and emit canonical CircuitIR main JSON.

The 500-circuit stress file is only a test corpus. The fixer itself is a
general rules engine backed by:

- the supported component catalogue and aliases,
- KiCad source-backed symbol pin names/numbers where available,
- explicit electronics rail rules for GND/AGND/DGND/VSS/COM, 3V3/VDDIO,
  5V/VCC/VBUS, VIN/VBAT/VRAW, and VOUT,
- component-family pin-role rules for common MCUs, sensors, logic ICs,
  interfaces, power devices, sources, connectors, and passives,
- endpoint and pin-normalization rules that keep electrically different pins
  distinct, including case-sensitive source-symbol pins such as 7447 `A`
  versus `a`.

The generated reference for accepted loose words, aliases, canonical placement
kinds, and pin-role words is:

```text
kicad/pipeline/SUPPORTED_WORDS_AND_ALIASES.md
```

## Repair Rules

- Normalize project/circuit metadata.
- Normalize component `id`/`ref`/`kind`/`type`/`value`/`role`/`block`.
- Infer unsupported or missing component kinds from catalogue aliases,
  component reference names, and observed pins.
- Add missing component records when nets reference a known `REF.PIN`.
- Normalize `nets`, `expected_netlist`, and component `pins` into one net map.
- Convert dict-style endpoints into `REF.PIN` form.
- Merge duplicate endpoint/net ownership through the same compiler repair path
  used by the final JSON builder.
- Drop singleton nets instead of pretending they are valid multi-endpoint
  connectivity.
- Build `components[].pins`, `expected_netlist`, `stage_contracts`,
  `generation_notes`, and `validation`.

## Guess-Terminal Rule

If the fixer invents or renames a net, the net must be visibly marked as a
guess and terminalized:

```text
GUESS_TERMINAL_*
```

The fixer also uses the component catalogue pin model plus common electronics
rules to infer missing power/ground rail endpoints. These inferred rails are
only kept when at least two endpoints exist, and they are always listed under:

```json
{
  "routing": {
    "terminal_policy": {
      "terminal_nets": ["GUESS_TERMINAL_GND"],
      "guessed_terminal_nets": ["GUESS_TERMINAL_GND"]
    }
  }
}
```

That means the router and wire maker must treat them as terminal/local-label
nets in combination or terminal mode. The generator must not silently draw
guessed nets as confidently planned user wires.

If a guessed rail exists, ordinary rail-like names such as `GND`,
`NET_BOARD_GND`, `VCC`, `NET_USB_5V`, or `NET_SENSOR_3V3` are merged into the
matching `GUESS_TERMINAL_*` net. This prevents a repaired circuit from carrying
two separate names for the same inferred rail and makes the guess visible to
the downstream metadata and terminal policy.

The fixer also checks alias-equivalent physical pins. If an inferred
`GUESS_TERMINAL_*` endpoint and an explicit net both claim the same physical pin
through aliases such as `S` and `SOURCE`, the guessed endpoint is dropped and
the explicit net wins. Multiple explicit nets on the same physical pin are
reported rather than guessed away.

## Variation Metadata

`generation_variation` is preserved when present. This lets the executable
variation runner validate/fix cloned JSON without losing the selected profile,
seed, source circuit id, or `disable_adaptive_cap` marker. The field changes
layout behavior only; it does not change component identity or expected nets.

## CLI

Fix one JSON file:

```bash
PYTHONPATH=. python -m kicad.pipeline.input_json_validator_fixer fix-json input.json --output fixed.json --report report.json
```

Compile arrow-node text:

```bash
PYTHONPATH=. python -m kicad.pipeline.input_json_validator_fixer compile-node-spec 500_complex_circuit_netlists.txt --output-dir fixed_json --report report.json
```

The arrow-node compiler is allowed to infer components from names and pins, but
the validator/fixer itself remains general and should be used for arbitrary
main JSON before generation.

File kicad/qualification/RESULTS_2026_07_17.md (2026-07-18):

# KiCad 400-Circuit Qualification Results

## Codex 5.6 Result

This is the clearest KiCad delivery record for Codex 5.6. 5.6 did not merely
generate a large folder of files: it created the named common-circuit corpus,
ran the untouched portable pipeline, located the one genuine shared geometry
defect, repaired the source-pin/foreign-body clearance rule in the common wire
maker and final validator, then retested only the affected profiles without
overwriting the original 390-pass evidence. The final portable smoke was also
checked by KiCad 10.0.4 netlist export and PCB DRC.

That disciplined 390-plus-10 evidence chain is the enormous 5.6 improvement
over an earlier 5.5-style experiment loop: durable corpus inputs, immutable
runs, source-level repair, exact electrical comparison, external application
checks, and a release rebuilt from the repaired shared code.

## Scope

The practical corpus is 40 canonical electrical archetypes times ten named
deployment/layout profiles: 400 deterministic canonical main JSON inputs. It
is deliberately not presented as 400 unrelated circuit theories. The v2 corpus
contains 17,890 component instances, 13,490 expected nets, 116 supported
component kinds, and no circuit larger than 89 placed components.

Corpus:

```text
kicad/qualification/corpora/2026_07_17_common_400_v2/
```

## Immutable Batch Evidence

The untouched portable-executable batch is preserved at:

```text
kicad/examples/progen_kicad_executable_run_2026_07_17_184041_common_400_portable_qualification_v2/
```

Results from that run:

- 400 of 400 canonical inputs passed the deterministic input fixer.
- 400 of 400 generated projects had valid static files, values, references,
  pin resolution, expected-net comparison, wire geometry, strict-wire
  contracts, and no partial or unrouted nets.
- KiCad 10.0.4 exported and XML-parsed all 400 generated schematics.
- All user/internal archive hashes and ZIP integrity checks passed.
- 311 supported native PCBs were accepted; 89 boards were correctly withheld
  by bounded PCB support/routing policy and are not claimed as PCB passes.

The only schematic failure was a single terminal-label layout collision in the
ten `KQ26` profiles. It was not an electrical or parser failure.

## Narrow Corrective Supplement

The root cause was a source pin tip from the `74HC86` multi-unit power section
entering a nearby pin-header body even though the two component bodies did not
overlap. The placement settlement stage now enforces 2.54 mm source-pin to
foreign-body clearance and nudges the smaller movable component first.

The ten affected profiles were regenerated without restarting the 400-case
batch:

```text
kicad/examples/progen_kicad_executable_run_2026_07_17_214207_common400_kq26_pin_clearance_retest_v1/
```

All ten passed every executable stage:

- 10/10 final validation, label-layout, expected-net, and wire-geometry pass.
- 10/10 have zero foreign pin/body conflicts, unresolved pins, partial nets,
  unrouted nets, or PCB unrouted nets.
- 10/10 native PCB outputs were accepted.
- KiCad 10.0.4 exported and XML-parsed every retest schematic.
- All 20 user/internal ZIP artifacts passed integrity checks.

The source-built portable release candidate independently regenerated `KQ26V01`
with the same clean final validation and KiCad 10 netlist export:

```text
kicad/examples/progen_kicad_executable_run_2026_07_17_214428_common400_kq26_portable_rc_smoke_v1/
```

Therefore the qualification evidence is the immutable 390-pass base plus the
fully retested ten-profile corrective supplement. No historical project or
batch result was overwritten.

## Superseded Record

`2026_07_17_common_400_v1` is retained only as an aborted performance record.
Its synthetic 190-component T10 stress archetype was not a practical common
circuit and spent roughly five minutes in bounded PCB routing before a correct
`pcb_routing_limit` withholding decision. It was replaced in v2 by the
practical Arduino/CAN/RS485 motion-controller archetype before v2 testing.

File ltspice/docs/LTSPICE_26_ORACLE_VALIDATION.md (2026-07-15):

# Local LTspice 26 Oracle Validation

> **Legacy prototype scope.** This is a historical validation record from
> before the donor-native rebuild. Its project-local `progeneda_*` symbols,
> generated model libraries, terminal-style fixtures, and behavioural-model
> results must not be cited as stock-symbol/direct-wire donor-native support.
> Current native authority is [ARCHITECTURE.md](../ARCHITECTURE.md), the
> [main catalogue](../catalogues/ltspice_main_catalogue.json), and
> [SUPPORT_GAPS.md](SUPPORT_GAPS.md).

Date: 2026-07-14 (Asia/Karachi)

The user-authorized local install is LTspice 26.0.2.1 under the isolated Wine
prefix:

```text
~/.local/share/progeneda-ltspice-wine
C:\Program Files\ADI\LTspice\LTspice.exe
```

The prefix is intentionally user-local and is not committed. The executable,
its symbol library, and its models are proprietary and are not copied into this
repository.

## Verified command contract

The backend invokes the oracle with the prefix explicitly bound and generated
paths exposed as Wine `Z:\...` paths:

```text
env WINEPREFIX=~/.local/share/progeneda-ltspice-wine WINEDEBUG=-all \
  nix shell --impure nixpkgs#wineWow64Packages.stable -c wine \
  'C:\Program Files\ADI\LTspice\LTspice.exe' -netlist Z:\...\project.asc
```

For an allowed analysis card it additionally invokes `-b`. Netlisting and
batch execution are both required for an oracle `passed` result. The simulator
log is rejected for syntax/fatal errors, unknown parameters, and ignored model
parameters. The exported netlist is additionally compared against the planned
native endpoint partition; auto-named direct-wire nodes such as `N001` are
checked by connectivity, not guessed label spelling.

## Evidence exercised

- A generated VDC–R–GND `.op` project netlisted and batch-simulated.
- A generated canonical NPN + NMOS fixture netlisted as project-local three
  terminal `X` subcircuits and batch-simulated. The wrappers explicitly tie a
  BJT substrate to emitter and a monolithic MOS bulk to source.
- A generated generic `I` current-source–R–GND `.op` project passed after the
  adapter began restoring LTspice-supported aliases that the shared KiCad fixer
  does not recognize.
- Seven generated fixtures were exercised through `-netlist` and `-b`:
  common-emitter NPN `.op`, generic-current-source `.op`, diode IV `.dc`,
  terminal-style diode IV `.dc`, NMOS pulse `.tran`, RC low-pass `.ac`, and a
  voltage-controlled-switch `.tran`. All ultimately passed after two real
  cross-stage repairs: V(net) traces force a stable native FLAG label, and
  project-local wrapper identities use LTspice's `X§REF` spelling.
- Native VCVS (`E`) and VCCS (`G`) output was also accepted by LTspice 26 in
  an `.op` fixture using all four native terminals.
- A generated RC transient project was opened interactively in LTspice 26
  under an isolated reflinked Wine prefix and Xvfb. The rendered schematic was
  visually inspected after the automatic placement fix: readable R0 labels,
  source–resistor–capacitor L layout, and real ground-pin anchors.

No generated waveform data or executable output is committed: unit tests use
temporary directories, while this document records the repeatable command
contract and results.

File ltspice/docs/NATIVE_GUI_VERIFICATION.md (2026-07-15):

# Donor-native LTspice GUI verification evidence

This record separates real desktop evidence from the deterministic generator
tests. A successful static run is not automatically a family-support promotion;
each fixture is recorded here with its scope and limits.

## 2026-07-15 — all observed-family mixed smoke test

| Evidence | Local path / result |
| --- | --- |
| Canonical source JSON | `ltspice/examples/native_observed_family_mix.json` |
| Generated donor-native ASC | `ltspice/examples/progen_ltspice_donor_native_run_2026_07_15_021118_observed_family_mix_gui_checked/generation/native_observed_family_mix/project/native_observed_family_mix.asc` |
| LTspice GUI screenshot | `/tmp/progeneda-gui-audit/native-observed-family-mix-verifier2.png` |
| Structured desktop-capture evidence | `/tmp/progeneda-gui-audit/native-observed-family-mix-verifier2.json` |
| Netlist produced by LTspice 26.0.2 | adjacent `native_observed_family_mix.net` |
| Static native validator | 8 stock `SYMBOL` records, 1 ground `FLAG 0`, 40 direct `WIRE` records; no custom symbol or terminal fallback |

The source has nine logical components: voltage source `V1`, current source
`I1`, stock `Misc\\signal` source `V2`, inductor `L1`, capacitor `C1`, three
resistors, and one logical ground. The emitted ASC uses only the installed
stock symbol names `voltage`, `current`, `Misc\\signal`, `ind`, `cap`, and
`res`; its ordinary connectivity is direct `WIRE` records, with a physical
ground `FLAG 0` on the return wire.

The LTspice 26.0.2 exported netlist contains all six observed electrical
families with the intended native attributes: `V1`, `R1`, `I1`, `R2`, `V2 AC
2`, `L1` with `Ipk/Rser/Rpar/Cpar`, `C1`, and `R3`. It completed without a
load/modal error. Visual inspection of the screenshot shows stock source,
resistor, inductor, capacitor, and current-source glyphs; direct blue wires;
the shared ground rail; readable values; and no custom-symbol placeholder,
named-terminal marker, or error dialog.

### Scope limit

This is an **all-family mixed smoke test**, not proof that every family has
completed the required 1/2/3/5/10/20 placement and property progression or the
complete progressive mix matrix. Catalogue statuses therefore remain
`donor_observed` until that evidence is generated, GUI-checked, and recorded.
The timestamped run directory and `/tmp` screenshot/evidence are local paths
and are intentionally ignored as generated/machine-local artifacts; this MD
preserves their provenance without pretending they are a portable fixture.

## 2026-07-15 — bounded 1/2/3/5/10/20 placement progression

`pipeline/donor_native_fixture_matrix.py` produced 36 canonical shared-JSON
cases: six donor-observed electrical families times the required counts 1, 2,
3, 5, 10, and 20. The native executable accepted all 36 and emitted 36
stock-only ASC files with direct physical wiring under the 43-logical-
component cap:

```text
/tmp/progeneda-native-progression3/output/
  progen_ltspice_donor_native_run_2026_07_15_021855_donor_progression_grid/
```

LTspice 26.0.2 successfully exported `.net` files for all six 20-count
fixtures (`resistor`, `capacitor`, `inductor`, `voltage source`, `current
source`, and `Misc\\signal`). The compacted 20-`Misc\\signal` placement also
opened cleanly in the GUI and was screenshot-assessed at:

```text
/tmp/progeneda-gui-audit/native-signal-source-20-grid.png
```

The screenshot shows the twenty stock AC source/load blocks tiled in a compact
grid with direct wires and a physical ground rail, with no load/modal error.
The corresponding netlist contains twenty `Vn ... AC 1` cards and twenty
resistor loads, proving those visible symbols are electrically native rather
than render-only placeholders.

### Scope limit

This records **static ASC generation for every count**, actual LTspice
netlisting at every 20-count family boundary, and one additional count-20 GUI
review. It does not yet individually screenshot-review all 36 files, prove
every editable property at every count, or complete the progressive
mixed-family combination matrix. Component statuses correctly remain
`donor_observed`.

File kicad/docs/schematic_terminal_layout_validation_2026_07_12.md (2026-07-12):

# Schematic Terminal Layout Validation - 2026-07-12

## Purpose

This record covers the KiCad terminal-label readability repair. The target was
to ensure that generated terminal/node names do not overlap component bodies,
reference/value text, other terminal labels, or a physically coincident pin.

## Implemented Rules

- Terminal labels extend away from the actual source-backed pin side, including
  vertical alignment for top and bottom pins.
- Terminal stubs use multiple outward escape offsets and parallel label lanes
  before accepting a fallback location.
- Every multi-unit symbol uses a shared 25.4 mm vertical pitch in the emitter,
  pin resolver, body model, and visible-text model.
- The placer uses all source-backed symbol body bounds and all physical pin tips
  as its layout envelope. The wire geometry validator still uses only symbol
  bodies, so an electrical wire may leave a pin but cannot pass through a body.
- Dense/deep graph layouts switch to the arrangement decider's deterministic
  square-fill algorithm. The project writer emits a KiCad `User` sheet sized
  to the actual generated content when A3 would clip it.
- Placement settlement now rejects both body overlaps and coincident pin tips.
  It deterministically nudges the smaller component by 10.16 mm when a
  source-backed pin contact would merge otherwise unrelated nets.
- The final validator blocks output for terminal-label visual overlaps and
  source-pin-coordinate overlaps, in addition to the existing netlist/body/
  geometry checks.

## Evidence

The final immutable terminal-only visual regression is:

`kicad/examples/schematic_terminal_visual_run_2026_07_12_071500_final_complex20_v19/`

It generated these 20 complex canonical inputs:

`MJ003`, `MJ004`, `MJ008`, `MJ009`, `MJ010`, `MJ016`, `MJ019`, `MJ020`,
`MJ024`, `MJ025`, `MJ026`, `MJ030`, `MJ032`, `MJ035`, `N07`, `N107`,
`N127`, `N147`, `N167`, and `N187`.

Its `run_manifest.json` reports:

- 20/20 static and final validation passes.
- Zero component-body overlaps.
- Zero source-pin-coordinate overlaps.
- Zero terminal-label visual overlaps.
- Zero wire-geometry violations.
- Zero local-netlist failed or merged nets.

KiCad 10.0.4 exported and rendered the final `N187` project. The inspected
PNG was generated from the real KiCad SVG export at
`/tmp/progen-schematic-v19-renders/n187.png` during validation. It showed the
content-sized sheet, square-like placement, and separate terminal labels.

## Earlier Attempts

The fresh immutable experiment directories
`schematic_terminal_visual_run_2026_07_12_041200_label_clearance_v1` through
`schematic_terminal_visual_run_2026_07_12_071000_pin_envelope_v18` are retained
under `kicad/examples/`. They record the progression from initial text-body
collisions, through side-aware labels, multi-unit spacing, label lanes,
square-fill layout, pin-contact detection, and finally full source-pin layout
envelopes. They are diagnostic records only; v19 is the accepted result.

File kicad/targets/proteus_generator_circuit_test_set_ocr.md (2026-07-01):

# Proteus Generator Circuit Test Set - KiCad Target Text

Source PDF uploaded by user: `daaaaaaaaaaaaaaaaaaaaaaadad.pdf`. The file is image-only, so this is a manually cleaned/OCR-derived target index. The original rendered PDF pages show C01-C55, each with functional components, generator input, and expected check.
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

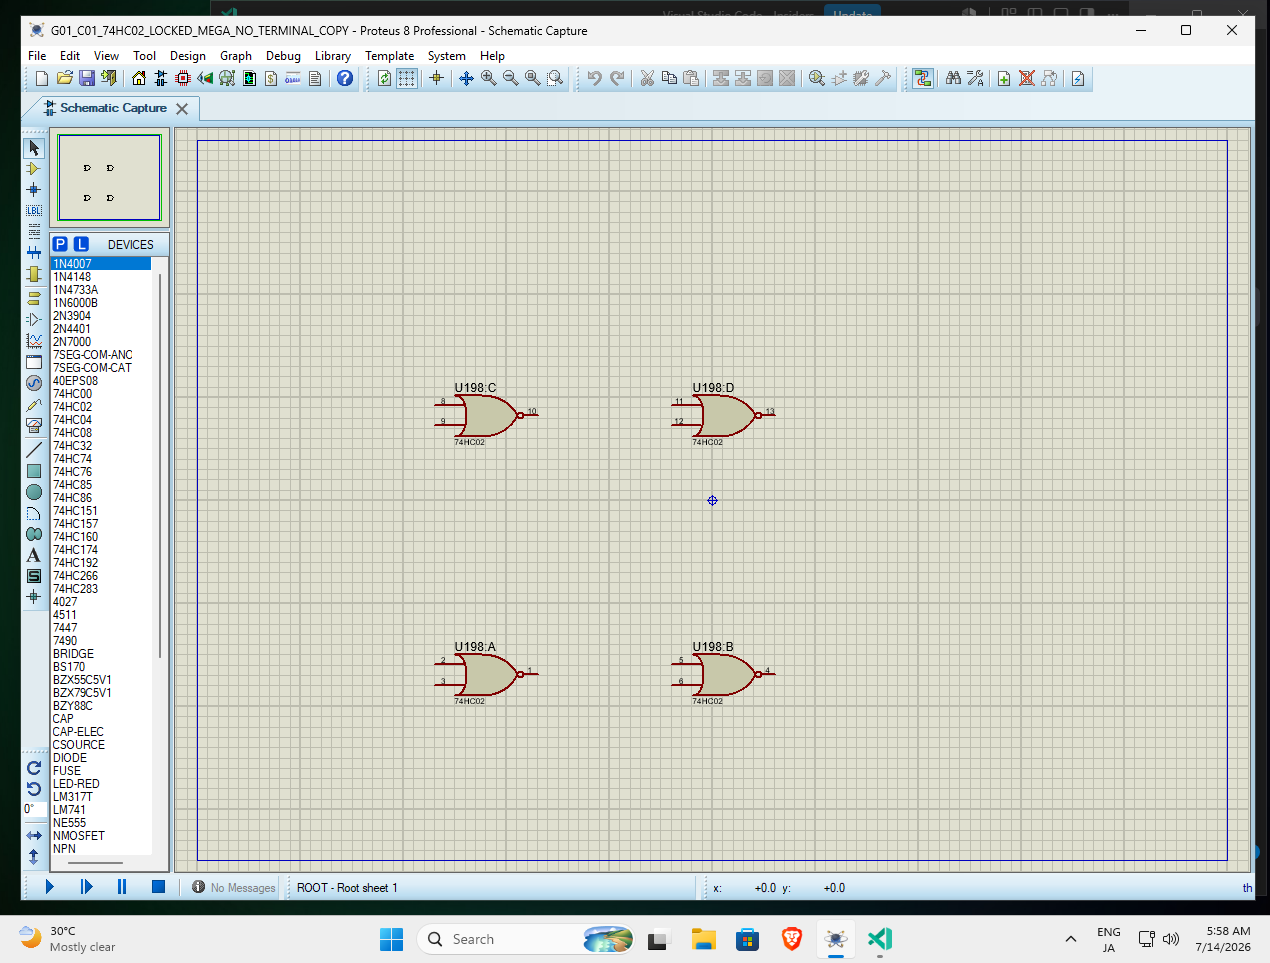
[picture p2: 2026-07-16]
proteus/experiments/runs/dil14_quad_2input_logic_74hc02_terminal_v2_temp_2026_07_14/02_local_proteus_gate/G01_C01_74HC02_LOCKED_MEGA_NO_TERMINAL.png

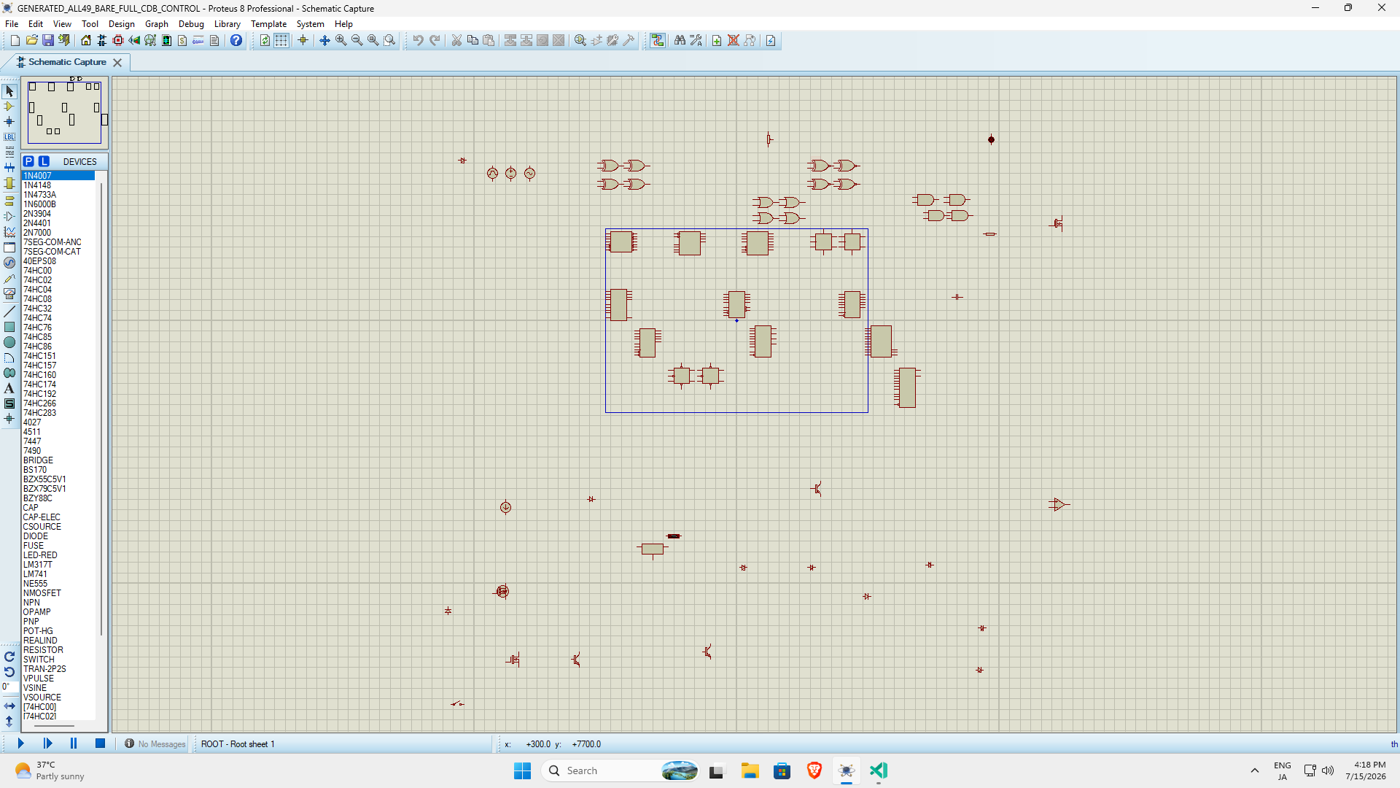
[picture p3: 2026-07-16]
proteus/experiments/runs/totalmix_cdb_isolation_v1_temp_2026_07_15/fresh_regeneration_01/SS_01_GENERATED_ALL49_BARE_FULL_CDB_CONTROL.png

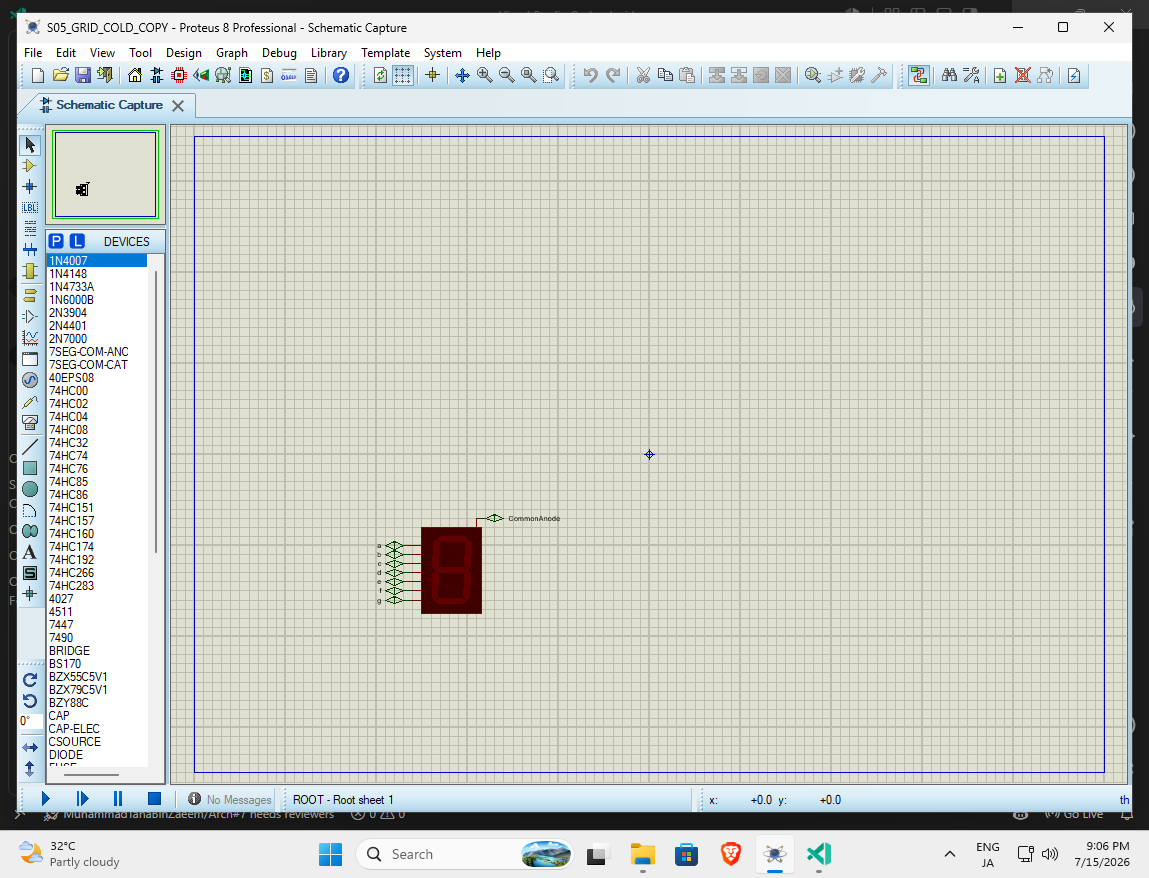
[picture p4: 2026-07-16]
proteus/experiments/runs/totalmix_38_growth_missing7_v1_temp_2026_07_15/06_display_anode_44f/00_solo_stages/01_grid_body_contact_trials/02_local_proteus_gate/S05_GRID_COLD.png

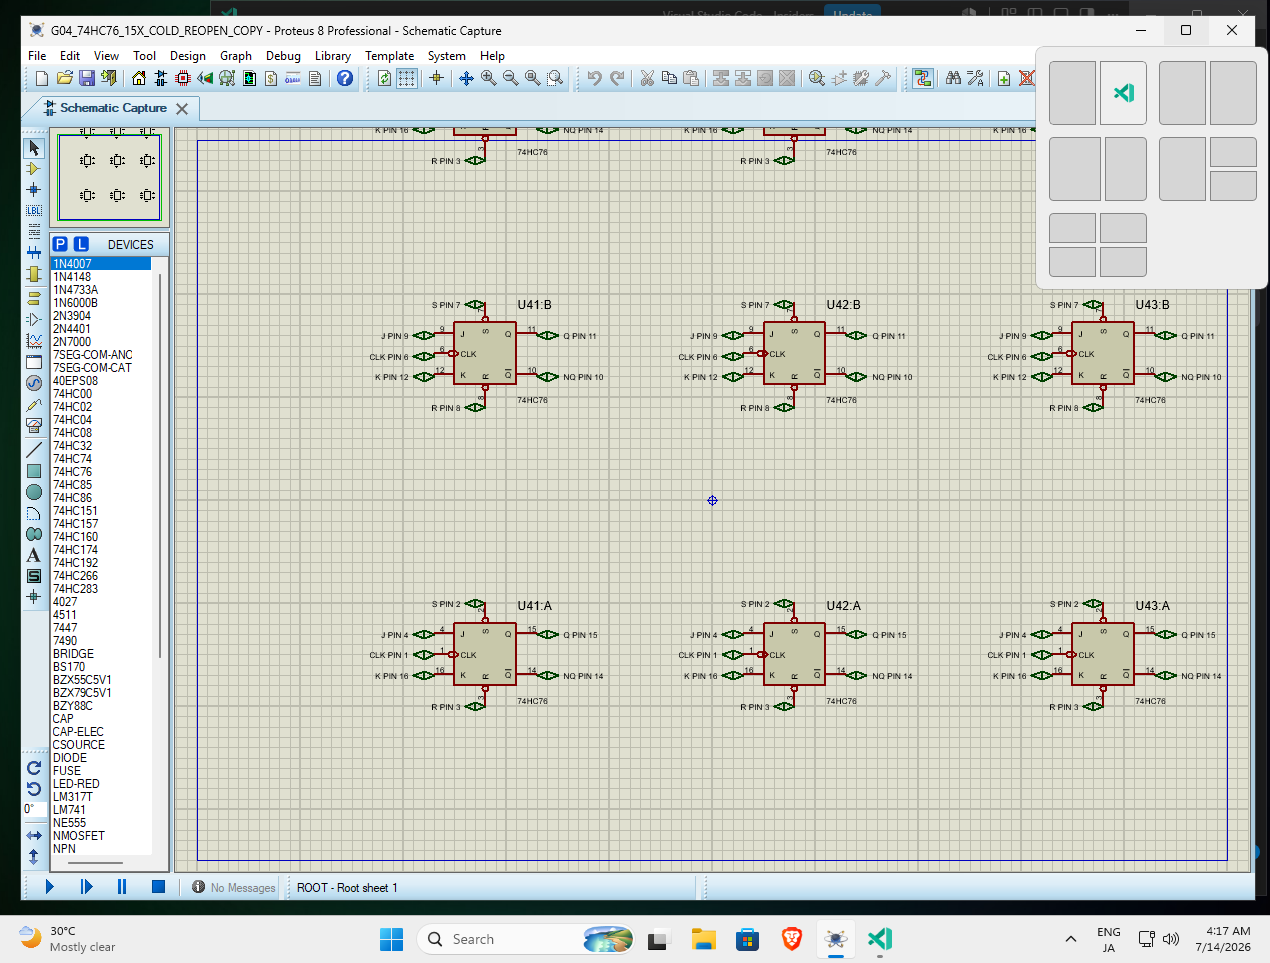
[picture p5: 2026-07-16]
proteus/experiments/runs/dil16_dual_jk_ff_74hc76_terminal_v3_temp_2026_07_14/04_local_proteus_gate/G04_74HC76_15X_cold_reopen_before_close.png

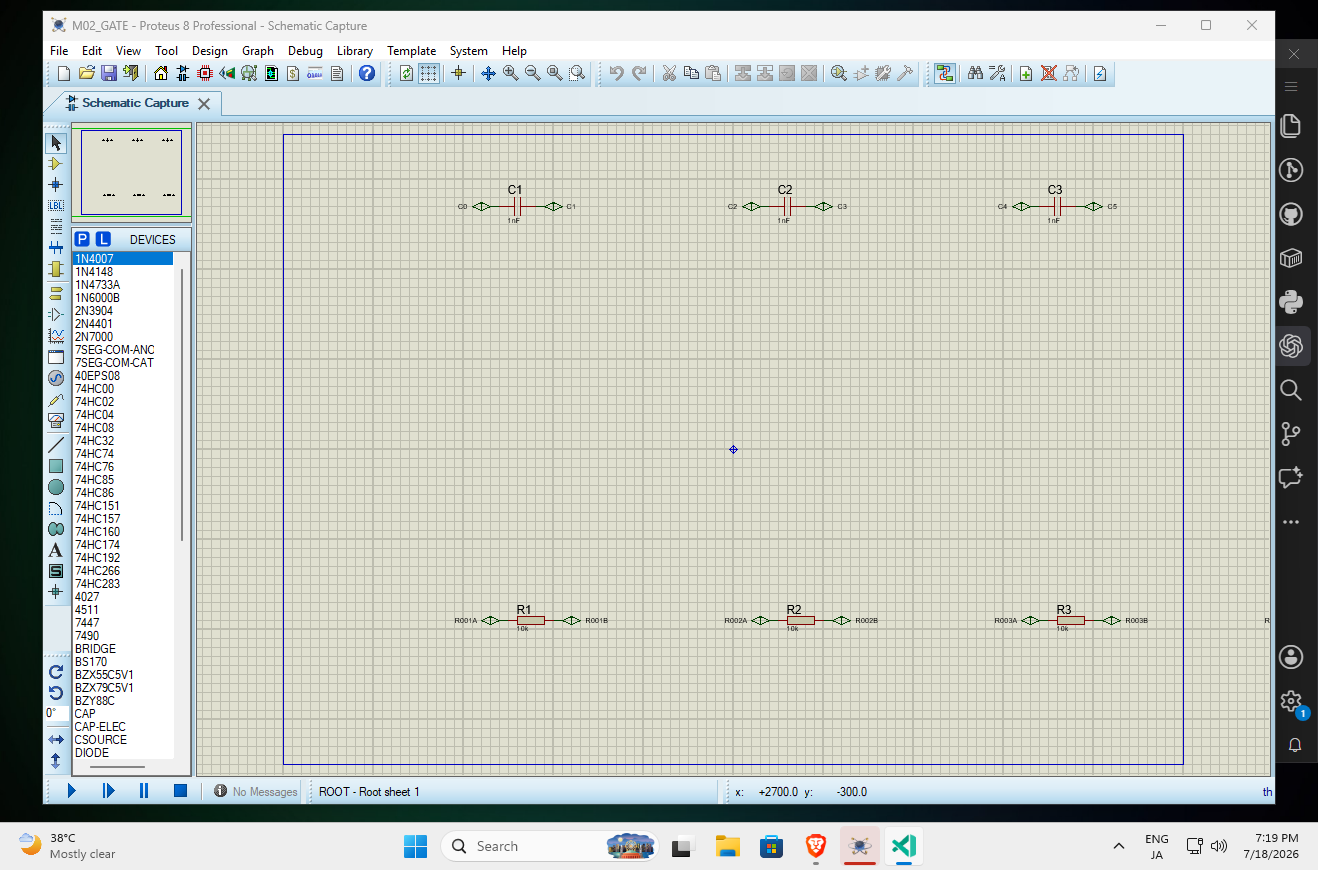
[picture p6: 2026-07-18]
proteus/experiments/runs/2026-07-18_2n4401_terminal_promotion_matrix/M02_heterogeneous_mix/screenshots/M02_GATE_cold_open_1.png

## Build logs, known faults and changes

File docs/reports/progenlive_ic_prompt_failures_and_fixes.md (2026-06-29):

# ProgenLive IC Prompt Failures and Fixes

This note records prompt/backend failures observed while testing large Proteus IC logic generation from ProgenLive, plus temporary fixes and permanent backend fixes to implement later.

## 1. Long prompt caused frontend type crash

Observed frontend error:

```text
r.toLowerCase is not a function
```

Cause:

```text
The prompt exceeded the backend validation limit. FastAPI/Pydantic returned an error detail object/list, but the frontend error categorizer expected a string and called toLowerCase() on it.
```

Temporary fix:

```text
Increase backend prompt length limits from 4000 to 20000.
```

Permanent fix:

```text
Normalize backend error detail to a string before passing it into generationErrorCategory(). Also make generationErrorCategory accept unknown and convert with String(message ?? "").
```

## 2. Pin-level IC prompt failed CircuitIR validation

Observed backend error:

```text
70b could not produce valid CircuitIR after 4 attempts
```

Cause:

```text
The current IC backend expects combinational gate-level CircuitIR, not explicit package-pin instructions such as U_AND1 pin 1, pin 2, pin 3.
```

Other schema conflicts:

```text
Long package refs such as U_AND1 do not fit the current U1..U9 package convention.
Long net names such as CLK_N and A0_CALC do not fit the current two-character net-label convention.
The prompt asked for pin 14/VCC and pin 7/GND, but current Proteus IC mode treats IC power pins as hidden.
```

Temporary fix:

```text
Use Boolean/gate equations instead of pin-by-pin IC package instructions.
Use short two-character node labels.
Split the design into smaller parts.
```

Permanent fix:

```text
Add a separate pin-level IC CircuitIR schema and compiler path if pin-level package generation is required.
```

## 3. Boolean prompt failed when router did not enter IC mode

Cause:

```text
A Boolean-looking prompt can fail if it does not include explicit IC/logic trigger wording.
```

Temporary fix:

```text
Start prompts with:
This is a Boolean logic circuit using 74HC00 NAND gates, 74HC04 NOT gates, 74HC08 AND gates, and 74HC86 XOR gates.
```

Permanent fix:

```text
Improve routing so equations containing operators like `not`, `and`, `xor`, and assignments are routed to IC/logic mode even without explicit trigger phrases.
```

## 4. Extra instruction text caused generation failure

Observed:

```text
The flip-flop prompt failed when it included the extra natural-language line:
Do not use V0, V1, V2, V3 as signal names. They are not internal logic nodes.

The same prompt worked after that line was removed.
```

Likely cause:

```text
The model or parser treated the extra instruction as non-circuit text inside an equation-heavy prompt and produced invalid CircuitIR.
```

Temporary fix:

```text
Avoid extra prose inside the equation block. Apply renames directly in the equations instead of telling the model what not to do.
```

Permanent fix:

```text
Preprocess prompts into sections: instructions, terminals, equations, outputs. Ignore or separately handle non-equation instruction lines.
```

## 5. V0 name conflict caused +5V logic contention

Observed Proteus simulation message:

```text
Logic contention(s) detected on net +5V.
```

Cause:

```text
V0 was auto-associated with a power/voltage-style net in the generator/Proteus convention, while the same name was also used as an internal NAND latch node. A gate output then effectively drove the power rail.
```

Temporary fix:

```text
Do not use V0, V1, V2, V3 or other V* names for internal logic nodes. Rename them directly in the equations, for example:
V0 -> S0
W0 -> T0
V1 -> S1
W1 -> T1
```

Permanent fix:

```text
Reserve power-like names such as VCC, +5V, V0, P9, G0, GND, 0. Reject or rename internal nets that collide with reserved supply conventions.
```

## 6. Yellow/unknown digital state in Proteus

Observed:

```text
Some gate outputs or latch nodes show yellow/unknown during simulation.
```

Cause:

```text
Digital inputs or latch feedback nodes are initially undefined. Sequential feedback circuits do not always resolve to a stable 0/1 state without an initialization path. If D inputs are not connected yet, or CK/RS are floating, the result propagates as unknown.
```

Temporary fixes:

```text
Connect all external inputs to defined logic sources before running simulation.
Tie unused inputs to GND or VCC using proper Proteus digital constants/logic state sources.
Use a reset/startup sequence that forces the flip-flops to a known state.
If reset only affects D inputs, keep reset active and apply at least one clock edge so the zeros are loaded.
```

Note:

```text
A simple analog pull-down resistor may help in some mixed simulations, but the safer Proteus digital solution is a digital logic state, digital constant, or a proper pull-up/pull-down primitive compatible with digital inputs. For 74HC logic, avoid leaving any inputs floating.
```

Permanent fix:

```text
The generator should automatically add initialization helpers for generated sequential circuits:
- explicit CK input source or prompt-visible CK terminal
- explicit RS/reset source or terminal
- optional startup reset pulse template
- tie-offs for unused/floating inputs
- validation that every gate input has a driver or intentional constant
```

## 7. Reset only in D path does not initialize NAND slave latch

Observed:

```text
The D equations used NR = not RS and D = M and NR, but the cross-coupled NAND outputs could still begin yellow/unknown.
```

Cause:

```text
Masking D to zero is not the same as asynchronously clearing the NAND latch. It only makes D become 0. The actual A/N output latch still needs a clock transfer or a direct reset path.
```

Circuit fix:

```text
For each flip-flop, feed reset into the slave latch path. Use active-high RS and NR = not RS.

Old slave stage:
Sx = not (Lx and CK)
Tx = not (Ux and CK)
Ax = not (Sx and Nx)
Nx = not (Tx and Ax)

Reset-safe slave stage:
Qx = Lx and CK
Sx = not (Qx and NR)
Rx = not (Ux and CK)
Tx = Rx and NR
Ax = not (Sx and Nx)
Nx = not (Tx and Ax)
```

Behavior:

```text
When RS = 1, NR = 0:
Sx = 1
Tx = 0
Nx = 1
Ax = 0

When RS = 0, NR = 1:
The circuit behaves like the normal master-slave NAND D flip-flop.
```

Prompt rule:

```text
Do not permanently connect RS to G0 while testing reset behavior. RS must be driven high at startup to clear the latch, then driven low for normal counting.
```

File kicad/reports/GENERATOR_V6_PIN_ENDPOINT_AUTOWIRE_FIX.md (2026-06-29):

# Generator V6 pin-endpoint autoroute fix

## Status

V5 opened in KiCad and embedded symbols loaded correctly, but the visible wires did not electrically connect to several symbol pins. This is now classified as a pin-coordinate bug, not a syntax or library-cache bug.

## Root cause

V5 routed to the visible end of the drawn pin line instead of the KiCad connection point. In KiCad schematic symbols, the connection point is the pin `(at x y)` coordinate inside the cached symbol definition.

Verified pin endpoint models used by V6:

```text
Device:R        pin 1 = (0,  3.81), pin 2 = (0, -3.81)
Device:L        pin 1 = (0,  3.81), pin 2 = (0, -3.81)
Simulation_SPICE:VDC   pin 1 = (0,  5.08), pin 2 = (0, -5.08)
Simulation_SPICE:VSIN  pin 1 = (0,  5.08), pin 2 = (0, -5.08)
power:GND       pin 1 = (0,  0)
```

Example failure:

A resistor centered at y=50 has real pin endpoints at:

```text
pin 2/top = 50 - 3.81 = 46.19
pin 1/bottom = 50 + 3.81 = 53.81
```

V5 was ending wires at values such as `43.65` and `56.35`, which are one pin-line length away from the actual connection points. KiCad therefore displayed open red/magenta terminals separated from the green wires.

## V6 implementation rule

V6 does not require manually supplied wire coordinates for simple circuits. It uses the component `pins` net map:

```json
{"ref": "R1", "kind": "R", "pins": {"2": "VIN", "1": "GND"}}
```

Then it:

1. Looks up the local KiCad pin endpoint for each component kind.
2. Applies component rotation.
3. Adds the component `(at x y)` position.
4. Groups pins by net.
5. Emits only two-point KiCad wire segments that terminate exactly on real pin endpoints.
6. For GND, connects each non-ground pin to the nearest `power:GND` symbol on that net instead of drawing a large ground bus.

## Generated test package

Local generated artifact:

```text
KICAD_GENERATED_OUTPUTS_V6_PIN_ENDPOINT_AUTOWIRE.zip
SHA256: 3cce6ef52686366f33143ee0f885721f95ccc8ed63f71e913ac2c98bf91dfd8f
```

Tests inside:

```text
vdc_resistor_op
vsin_rl_tran
```

Static checks passed:

```text
balanced schematic S-expression: yes
all wire objects have exactly two xy points: yes
all used lib_ids have embedded lib_symbols: yes
simulation directives detected: .op and .tran
```

## Next validation

Open the V6 project files in KiCad and verify visually that each green wire touches the symbol pin endpoint exactly. After that, run KiCad simulator and check whether `.op` / `.tran` jobs are recognized and produce a netlist/run.

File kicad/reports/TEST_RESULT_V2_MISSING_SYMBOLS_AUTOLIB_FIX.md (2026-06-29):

# KiCad V2 Test Result: Missing Symbols / Red Boxes

## User test result

The V2 wire-fixed schematic opened, but the schematic displayed red symbol boxes with question marks for generated parts such as the voltage source, resistor, diode, and GND.

This means the wire syntax problem was fixed, but KiCad could not resolve the stock symbol libraries from the generated schematic.

## Root cause

The current generator emits symbols with stock KiCad library IDs such as:

```text
Device:R
Device:D
power:GND
Simulation_SPICE:VDC
```

but the generated schematic currently has an empty symbol cache block:

```text
(lib_symbols
)
```

If the user's KiCad global library table does not resolve these library IDs, KiCad shows missing-symbol placeholders.

## Fix added

Added tool:

```text
kicad/tools/fix_project_symbols.py
```

The tool scans generated project folders, copies or downloads the required `.kicad_sym` libraries, and writes a project-local:

```text
sym-lib-table
```

using:

```text
${KIPRJMOD}/symbols/<Library>.kicad_sym
```

## Current local artifact

A new test ZIP was produced locally for the user:

```text
KICAD_GENERATED_OUTPUTS_V3_AUTOLIB_FIX.zip
```

It contains:

```text
fix_project_symbols.py
RUN_THIS_FIRST__download_kicad_symbols.bat
README_AUTOLIB_FIX.md
```

plus the V2 generated diode and RC project folders.

## Next generator decision

If this tool fixes the missing symbols, the next generator version should automatically include project-local symbol tables and optionally cache/download required symbol libraries.

If it does not, the next patch should embed the required `lib_symbols` cache blocks directly inside `.kicad_sch` after a KiCad roundtrip confirms the exact saved symbol-cache format.

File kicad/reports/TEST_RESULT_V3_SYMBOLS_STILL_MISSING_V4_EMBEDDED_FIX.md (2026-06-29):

# KiCad V3 Test Result: Symbols Still Missing

## User test result

The V3 auto-library package opened in KiCad, but the schematic still showed red placeholder boxes / question-mark symbols for the generated components.

Observed from screenshots:

```text
V1, R1, D1/C1 and GND objects are still unresolved placeholder symbols.
Wires and labels are visible.
SPICE directive text is visible in rc_lowpass.
Simulator reports: No job defined.
```

## Interpretation

The V2 wire syntax fix worked because the schematic now opens.

The V3 library-downloader/sym-lib-table fix did not solve symbol portability on the user's machine.

The next correct fix is to embed required `lib_symbols` cache blocks directly inside each `.kicad_sch` file. KiCad upstream example schematics include cached symbol blocks for stock components under `(lib_symbols ...)`, including `Device:R`, `Device:C`, `Device:D`, `Simulation_SPICE:VDC`, `Simulation_SPICE:VSIN`, and `power:GND` in schematic examples.

## V4 local artifact

Generated locally outside repo:

```text
KICAD_GENERATED_OUTPUTS_V4_EMBEDDED_SYMBOLS.zip
```

V4 changes:

```text
- no downloader required
- no reliance on global KiCad libraries
- embeds symbol cache blocks directly inside .kicad_sch
- uses pin-aware coordinates for the diode_iv and rc_lowpass examples
- keeps named Windows-friendly files
```

## Next validation

User should test V4. If red question marks disappear but simulator still says no job, the next issue is a simulator/netlist directive issue, separate from symbol resolution.

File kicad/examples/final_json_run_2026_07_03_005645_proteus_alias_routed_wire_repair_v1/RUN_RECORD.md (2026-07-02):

# Run Record: proteus_alias_routed_wire_repair_v1

## What This Tested

This immutable run generated the `proteus_alias_routed` final JSON suite from
the canonical deterministic builder:

```text
kicad.pipeline.final_circuit_builder
```

The suite contains three connected circuits (`R01`, `R02`, `R03`) mixing the
new Proteus-style aliases with the existing KiCad-supported components.

## Previous State

The previous mixed alias generated projects opened, but the wired output was
too label-heavy and the user reported visually bad placement, including
components appearing on top of each other.

## Outcome

- Final JSON validation: pass for all 3 circuits.
- Placement validation: pass for all 3 circuits.
- Post-beautifier catalog obstacle overlaps: 0.
- Components: 49 total.
- Nets: 55 total.

## Next

Use the matching wired run
`final_json_wired_project_run_2026_07_03_005706_proteus_alias_routed_wire_repair_wired_v1`
to inspect the actual KiCad symbol-body overlap report and real wire geometry.

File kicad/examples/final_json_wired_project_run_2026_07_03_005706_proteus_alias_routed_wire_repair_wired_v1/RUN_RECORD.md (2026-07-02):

# Run Record: proteus_alias_routed_wire_repair_wired_v1

## What This Tested

This immutable run generated openable KiCad wired projects from the canonical
final JSON run:

```text
final_json_run_2026_07_03_005645_proteus_alias_routed_wire_repair_v1
```

The active stages were:

```text
component placer -> arrangement decider -> beautifier -> actual KiCad symbol-body settle -> wire planner -> KiCad wire maker -> geometry validator
```

## Previous State

The earlier routed/mixed outputs were openable but visually unacceptable:
too many nets were converted to local labels and the user reported components
appearing stacked or on top of each other.

## Fixes Exercised

- Actual KiCad symbol body boxes are now checked after beautification.
- The wired run summary records component-body overlap status.
- Same-net collinear wire segments are merged before final validation.
- Geometry repair now downgrades the fewest nets needed to remove crossings,
  instead of converting every net involved in a violation.

## Outcome

- Projects generated: 3 (`R01`, `R02`, `R03`).
- Components: 49.
- KiCad symbol instances: 75.
- Real wire objects: 125.
- Local labels: 111.
- Unresolved pins: 0.
- Component body overlaps: 0.
- Wire geometry violations: 0.
- Static schematic checks: pass.

## KiCad CLI Follow-Up

After this record was written, `kicad.automation.quality_check` loaded all
three schematics and exported all three netlists, but R02 reported two blocking
`unconnected_wire_endpoint` ERC warnings. The root cause was endpoint-to-middle
wire contacts without explicit junction dots. This run is superseded by the
next wired run after fixing junction insertion.

## Known Limits

Some nets still fall back to local labels when the current pure math router
cannot find a clean route or when keeping both crossing nets as wires would
break the no-crossing rule.

## Next

Open the three `OPEN_THIS_PROJECT__*__WIRED.kicad_pro` files and visually check
whether the placement now matches the manifest evidence. If visual clutter is
still unacceptable, improve the wire planner's channel selection before adding
more component families.

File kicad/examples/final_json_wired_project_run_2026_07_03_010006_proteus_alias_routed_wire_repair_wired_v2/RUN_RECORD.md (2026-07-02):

# Run Record: proteus_alias_routed_wire_repair_wired_v2

## What This Tested

This immutable run regenerated the routed Proteus-alias KiCad projects after
fixing junction insertion for endpoint-to-middle wire contacts.

## Previous State

`final_json_wired_project_run_2026_07_03_005706_proteus_alias_routed_wire_repair_wired_v1`
had clean internal geometry, but KiCad CLI ERC reported two blocking
`unconnected_wire_endpoint` warnings in R02 because endpoint-to-middle wire
contacts had no explicit junction dots.

## Outcome

- Projects generated: 3 (`R01`, `R02`, `R03`).
- Components: 49.
- KiCad symbol instances: 75.
- Real wire objects: 125.
- Local labels: 111.
- Unresolved pins: 0.
- Component body overlaps: 0.
- Wire geometry violations: 0.
- Static schematic checks: pass.

## KiCad CLI Follow-Up

KiCad CLI quality loaded all three schematics and exported all three netlists,
but R02 still reported one blocking `unconnected_wire_endpoint` warning. The
remaining issue was a dangling same-net wire tail extending past a junction.
This run is superseded by the next wired run after adding dangling-tail trim.

## Next

Use the next wired run for visual inspection after KiCad CLI quality passes.

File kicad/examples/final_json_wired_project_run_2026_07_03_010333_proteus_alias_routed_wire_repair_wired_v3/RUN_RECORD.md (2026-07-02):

# Run Record: proteus_alias_routed_wire_repair_wired_v3

## What This Tested

This immutable run regenerated the routed Proteus-alias KiCad projects after
adding same-net dangling-tail trim on top of the v2 junction fix.

## Previous State

- v1 had two R02 `unconnected_wire_endpoint` ERC warnings.
- v2 reduced that to one R02 `unconnected_wire_endpoint` warning.

## Outcome

- Projects generated: 3 (`R01`, `R02`, `R03`).
- Components: 49.
- KiCad symbol instances: 75.
- Real wire objects: 125.
- Local labels: 111.
- Unresolved pins: 0.
- Component body overlaps: 0.
- Wire geometry violations: 0.
- Static schematic checks: pass.

## KiCad CLI Quality

Command:

```bash
python -m kicad.automation.quality_check kicad/examples/final_json_wired_project_run_2026_07_03_010333_proteus_alias_routed_wire_repair_wired_v3 --kicad-cli kicad/.local/bin/kicad-cli --export-netlist
```

Result:

- Schematics checked: 3.
- Quality failures: 0.
- ERC loaded: yes.
- Netlists exported: 3.
- Blocking ERC violations: 0.

Remaining ERC warnings are tolerated demo-stage warnings such as unconnected
unused pins, undriven power pins, and one source-library mismatch on R03.

## Next

Open this v3 run for visual inspection:

```text
projects/r01/OPEN_THIS_PROJECT__r01__WIRED.kicad_pro
projects/r02/OPEN_THIS_PROJECT__r02__WIRED.kicad_pro
projects/r03/OPEN_THIS_PROJECT__r03__WIRED.kicad_pro
```

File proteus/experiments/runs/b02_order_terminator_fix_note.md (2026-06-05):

# B02 Order Terminator Fix Note

## User result

The previous B02-order pack produced VGDVC.DLL errors for the terminal/resistor/wire files.

## Concrete bug found

The generated object chunk ended with byte `00`.

The valid B02 donor object chunk ends with byte `FF` on the final wire object.

For example, the valid four-resistor terminal/wire donor has:

```text
final right-wire object last byte = FF
```

The previous generated R1/R2/R21 chunks incorrectly had:

```text
final object last byte = 00
```

This means the final object in the first OBJECT DATA section was not being terminated the same way as the real donor stream. That can explain VGDVC.DLL errors during schematic rendering/loading.

## New local artifact

```text
R21_E001_B02_ORDER_TERMINATOR_FIXED_GENERATION.zip
```

## Fix

The generator now forces:

```text
object_chunk[-1] = 0xFF
```

for the B02-order generated object stream.

## Test order

```text
CONTROL_E001_EMPTY_BASE.pdsprj
TEST_B02_ORDER_R1_TERMINAL_RESISTOR_TERMINAL.pdsprj
TEST_B02_ORDER_R2_SERIES_TERMINALS.pdsprj
FINAL_B02_ORDER_R21_7PAR7_PLUS_7SERIES_TERMINALS.pdsprj
```

## Validation checks on generated files

```text
R1 object chunk final byte  = FF
R2 object chunk final byte  = FF
R21 object chunk final byte = FF
```

The project base remains E001. B02 is still only used as the record-layout/order reference.

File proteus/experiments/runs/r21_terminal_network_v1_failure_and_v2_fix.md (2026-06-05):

# R21 Terminal Network V1 Failure and V2 Fix

## User-observed V1 result

The user tested:

```text
R21_7PAR7_PLUS_7SERIES_TERMINAL_NETWORK.zip
```

Observed result:

```text
Bad object record - circuit data lost.
```

After loading, the schematic showed only the first two terminal labels/objects:

```text
N0
A1
```

The resistor records and remaining terminal/wire records were lost.

## Diagnosis

This is an important diagnostic result.

Because the first two terminal records decoded and displayed before the bad-object warning, the failure likely occurred at the first generated resistor visible record that followed those two terminal records.

V1 used an experimental 3-character visible-value resistor record extracted from an `E019` terminal/resistor/wire source. That extraction was unsafe:

```text
V1 attempted to use a variable-length 3-character resistor record.
The extraction likely started/cut at the wrong object boundary.
Proteus decoded two terminal records, then hit the malformed resistor record and discarded the remaining circuit data.
```

This means the V1 failure does not disprove:

```text
21-resistor CDB generation
terminal records
wire records
R21 topology
```

It mainly identifies the generated 3-character visible resistor object as the current weak point.

## V2 fix

Generated local artifact:

```text
R21_TERMINAL_NETWORK_V2_FIXED_RESISTOR_RECORD.zip
```

V2 changes the dangerous part only:

```text
Instead of the experimental 3-character visible resistor record,
V2 uses the already validated 2-character resistor visible-record schema from the working E001 R12 generator.
```

ROOT.CDB still stores real values:

```text
R1 = 1k
R2 = 2k
...
R9 = 9k
RA = 10k
RB = 11k
...
RL = 21k
```

Visible schematic value labels are temporarily fixed-width:

```text
1k, 2k, ..., 9k, Ak, Bk, ..., Lk
```

## V2 diagnostic tests

V2 includes three layers:

```text
TEST_R21_V2_RESISTORS_ONLY_E0_TAIL.pdsprj
TEST_R21_V2_TERMINALS_RESISTORS_NO_WIRES_E0_TAIL.pdsprj
TEST_R21_V2_TERMINALS_RESISTORS_WIRES_E019_ORDER_E0_TAIL.pdsprj
```

And matching R4-tail fallbacks:

```text
TEST_R21_V2_RESISTORS_ONLY_R4_TAIL.pdsprj
TEST_R21_V2_TERMINALS_RESISTORS_NO_WIRES_R4_TAIL.pdsprj
TEST_R21_V2_TERMINALS_RESISTORS_WIRES_E019_ORDER_R4_TAIL.pdsprj
```

## Test interpretation

```text
RESISTORS_ONLY opens/simulates:
  21-resistor CDB + safe resistor visible records still work.

TERMINALS_RESISTORS_NO_WIRES opens:
  terminal records are structurally okay with generated resistors.

TERMINALS_RESISTORS_WIRES_E019_ORDER opens:
  terminal + wire + resistor ordering is valid enough for the full R21 network.
```

If only the wire variant fails, the next target is wire record/endpoint semantics.

If the no-wire variant fails but resistors-only opens, the next target is terminal object generation.

If resistors-only fails, the next target is 21-count resistor scaling or fixed-width value/ref patching.

## Exact code/method availability

The local V2 pack includes:

```text
generation_code_used.py
manifest.json
topology_map.json
raw ROOT.CDB and ROOT.DSN debug binaries next to each generated project
```

The generator code is also preserved in the ChatGPT artifact but not directly uploaded as raw binary project files to GitHub.

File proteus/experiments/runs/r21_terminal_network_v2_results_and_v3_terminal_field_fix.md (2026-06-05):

# R21 Terminal Network V2 Results and V3 Terminal-Field Fix

## User-observed V2 results

The user tested:

```text
R21_TERMINAL_NETWORK_V2_FIXED_RESISTOR_RECORD.zip
```

Observed results:

```text
TEST_R21_V2_RESISTORS_ONLY_E0_TAIL opened and displayed all 21 resistors.
TEST_R21_V2_RESISTORS_ONLY_R4_TAIL opened and displayed all 21 resistors.

Any terminal-containing V2 variant crashed during loading with:
Internal Exception: access violation in module 'VGDVC.DLL' [000190DA]
```

## Interpretation

This is a clean diagnostic split:

```text
21 generated resistor CDB + 21 safe visible resistor records = works
adding generated terminal records = VGDVC crash
```

Therefore the weak point is no longer resistor CDB generation or 21-resistor scaling. The weak point is terminal visible-object generation.

## New root cause found

While comparing against the four-terminal donor file, the terminal records showed an important structure mistake.

In V2, the terminal writer did this:

```text
r[-1] = 0x00
```

That was wrong.

Real terminal records do not end in a generic record terminator byte. They end in a nonzero terminal/text suffix. Examples from the donor terminal records:

```text
input terminal suffixes:
59 01 01
17 03 01
d5 04 01
93 06 01

output terminal suffixes:
8b 01 01
49 03 01
07 05 01
c5 06 01
```

So the final byte `01` is part of the terminal record. It should not be overwritten.

## V3 fix

Generated local pack:

```text
R21_TERMINAL_NETWORK_V3_TERMINAL_FIELD_FIX.zip
```

V3 changes:

```text
- keeps the terminal final byte as 0x01
- patches the terminal suffix as a unique generated 16-bit sequence + 0x01
- cycles through the four known donor input/output terminal templates
- preserves the working 21-resistor CDB and visible resistor writer
```

## V3 files

```text
CONTROL_E001_EMPTY_BASE.pdsprj
TEST_R21_V3_RESISTORS_ONLY_E0_TAIL.pdsprj
TEST_R21_V3_TWO_TERMINALS_ONLY_THEN_RESISTORS_E0_TAIL.pdsprj
TEST_R21_V3_TERMINALS_RESISTORS_NO_WIRES_E0_TAIL.pdsprj
TEST_R21_V3_TERMINALS_RESISTORS_WIRES_E019_ORDER_E0_TAIL.pdsprj

and matching R4-tail fallback files
```

## V3 test order

```text
1. CONTROL_E001_EMPTY_BASE.pdsprj
2. TEST_R21_V3_RESISTORS_ONLY_E0_TAIL.pdsprj
3. TEST_R21_V3_TWO_TERMINALS_ONLY_THEN_RESISTORS_E0_TAIL.pdsprj
4. TEST_R21_V3_TERMINALS_RESISTORS_NO_WIRES_E0_TAIL.pdsprj
5. TEST_R21_V3_TERMINALS_RESISTORS_WIRES_E019_ORDER_E0_TAIL.pdsprj
```

If an E0-tail file fails, test the matching R4-tail fallback.

## Expected interpretation

```text
RESISTORS_ONLY works:
  confirms the known-good 21-resistor generation remains stable.

TWO_TERMINALS_ONLY_THEN_RESISTORS works:
  confirms corrected terminal record suffix is acceptable for a tiny terminal insertion.

TERMINALS_RESISTORS_NO_WIRES works:
  confirms large terminal count is structurally okay.

TERMINALS_RESISTORS_WIRES works:
  confirms wire records/order are now the next validated layer.
```

If the two-terminal test still crashes, terminal record structure still has another hidden field.

If two-terminal works but 42-terminal no-wire crashes, terminal count scaling/unique suffix generation is still incomplete.

If no-wire works but wire version crashes, the remaining issue is wire object records/endpoint semantics.

## Code/method preservation

The generated local zip includes:

```text
generation_code_used.py
manifest.json
topology_map.json
ROOT.CDB.bin and ROOT.DSN.bin debug dumps next to every generated project
```

A copy of the V3 generation code is stored in:

```text
experiments/generation_code/r21_terminal_network_v3_terminal_field_fix.py
```

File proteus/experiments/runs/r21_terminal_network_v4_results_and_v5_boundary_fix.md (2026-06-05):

# R21 Terminal Network V4 Results and V5 Object-Boundary Fix

## User-observed V4 result

The user tested:

```text
R21_TERMINAL_NETWORK_V4_ORDER_SUFFIX_DIAGNOSTICS.zip
```

Observed result:

```text
Only the resistor-only E0/R4 files opened.
All terminal-containing variants still gave the same VGDVC.DLL [000190DA] error.
```

This confirmed:

```text
21 generated resistors are stable.
The failure is triggered by generated terminal visible records.
```

## New concrete cause found

The VGDVC failure was not just suffix mutation or terminal order.

The real four-terminal donor object chunk begins like this after `OBJECT DATA`:

```text
00 10 f0 5a 97 ff ... $TERINPUT ...
```

The important discovery:

```text
The first byte after OBJECT DATA is a chunk/header byte.
The first terminal record starts at offset +1, not +0.
```

The previous terminal extractor incorrectly treated this header byte as part of the first terminal object record.

### Correct donor terminal layout

```text
OBJECT DATA
  1-byte object-region header: 00
  4 input terminal records, 103 bytes each
  4 output terminal records, 104 bytes each
  resistor/wire groups...
```

Correct offsets inside the donor visual chunk:

```text
input terminals:
  start = 1 + i*103
  length = 103

output terminals:
  start = 413 + i*104
  length = 104

first resistor/wire group:
  start = 829
  resistor length = 346
  wire left length = 50
  wire right length = 50
```

### What old V2/V3/V4 did wrong

Previous packs combined:

```text
resistor-style OBJECT DATA header length = 2 bytes
+
terminal template that already included the donor chunk header byte
```

So generated terminal-containing chunks began with:

```text
00 00 00 10 f0 ...
```

instead of the valid terminal donor style:

```text
00 10 f0 ...
```

That extra byte shifted the terminal record and made VGDVC crash while rendering/decoding the malformed terminal object.

## V5 fix

Generated local artifact:

```text
R21_TERMINAL_NETWORK_V5_CORRECT_OBJECT_BOUNDARIES.zip
```

V5 changes:

```text
- extracts terminal records from the correct offsets
- uses a 1-byte OBJECT DATA header when the object block starts with terminal records
- preserves the 2-byte resistor-style header only for resistor-only files
- keeps the working 21-resistor CDB and visible resistor writer
```

## V5 test order

```text
1. CONTROL_E001_EMPTY_BASE.pdsprj
2. TEST_R21_V5_RESISTORS_ONLY_CORRECT_BOUNDARY_E0_TAIL.pdsprj
3. TEST_R21_V5_TWO_TERMS_DONORBYTES_THEN_RESISTORS_E0_TAIL.pdsprj
4. TEST_R21_V5_TWO_TERMS_PATCHED_THEN_RESISTORS_E0_TAIL.pdsprj
5. TEST_R21_V5_ALL_TERMS_THEN_RESISTORS_E0_TAIL.pdsprj
6. TEST_R21_V5_ALL_TERMS_THEN_RESISTORS_WIRES_E0_TAIL.pdsprj
```

If E0-tail terminal files fail, test matching R4-tail fallbacks.

## Interpretation

```text
DONORBYTES two-terminal opens:
  corrected object boundary is the main fix.

DONORBYTES opens but PATCHED fails:
  coordinate/label patching is still wrong.

PATCHED two-terminal opens but ALL_TERMS fails:
  terminal count-scaling or suffix reuse is the issue.

ALL_TERMS opens but WIRES fails:
  wire object/endpoint semantics are the remaining issue.
```

## Code/method preservation

The complete executable V5 generation code is stored in:

```text
experiments/generation_code/r21_terminal_network_v5_correct_object_boundaries.py
```

The local zip also contains:

```text
generation_code_used.py
manifest.json
topology_map.json
ROOT.CDB.bin and ROOT.DSN.bin debug dumps for every generated project
```

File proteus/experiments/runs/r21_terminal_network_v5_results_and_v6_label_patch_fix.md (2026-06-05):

# R21 Terminal Network V5 Results and V6 Terminal Label-Patch Fix

## User-observed V5 result

The user tested:

```text
R21_TERMINAL_NETWORK_V5_CORRECT_OBJECT_BOUNDARIES.zip
```

Observed result:

```text
resistor-only files opened
TWO_TERMS_PATCHED ... SUFFIX_UNIQUE opened and displayed N0 / A1 terminals
the larger terminal-containing files still failed or produced bad object record / circuit data lost
```

The important split remains:

```text
21 generated resistors = stable
terminal generation works only at tiny scale
large terminal count corrupts object records
```

## Concrete V5 bug found

The V5 terminal patcher replaced the label, then searched for the new label bytes anywhere in the terminal record in order to patch label coordinates.

That is unsafe because labels like:

```text
B6
```

can also appear naturally inside binary coordinate bytes, for example in the generated x/y coordinate fields.

So for some terminal labels, the code found the wrong occurrence and patched coordinates into the wrong location. This corrupted the terminal record.

Evidence from generated ROOT.DSN inspection:

```text
input terminal record 14, label B6, no longer contained `$TERINPUT` at the expected record position
binary coordinate fields had been overwritten at the wrong place
```

This explains why small two-terminal tests with labels like `N0/A1` could open, while larger terminal sets failed once collision-prone labels appeared.

## V6 fix

Generated local artifact:

```text
R21_TERMINAL_NETWORK_V6_FIXED_TERMINAL_LABEL_PATCH.zip
```

V6 stops searching for the new label bytes. It patches fixed terminal label fields directly:

```text
input terminal:
  label length @ +30
  label bytes   @ +31..+32
  label x/y     @ +33..+40

output terminal:
  label length @ +31
  label bytes   @ +32..+33
  label x/y     @ +34..+41
```

The rest of the working 21-resistor CDB and visible resistor writer is preserved.

## V6 files

```text
CONTROL_E001_EMPTY_BASE.pdsprj
TEST_R21_V6_RESISTORS_ONLY_BASELINE_E0_TAIL.pdsprj
TEST_R21_V6_TWO_TERMS_N0_A1_FIXED_LABELPATCH_E0_TAIL.pdsprj
TEST_R21_V6_TWO_TERMS_B6_M0_FIXED_LABELPATCH_E0_TAIL.pdsprj
TEST_R21_V6_ALL_TERMS_FIXED_LABELPATCH_KEEP_NO_WIRES_E0_TAIL.pdsprj
TEST_R21_V6_ALL_TERMS_FIXED_LABELPATCH_UNIQUE_NO_WIRES_E0_TAIL.pdsprj
TEST_R21_V6_ALL_TERMS_FIXED_LABELPATCH_KEEP_WITH_WIRES_E0_TAIL.pdsprj
TEST_R21_V6_ALL_TERMS_FIXED_LABELPATCH_UNIQUE_WITH_WIRES_E0_TAIL.pdsprj
```

## V6 test order

```text
1. CONTROL_E001_EMPTY_BASE.pdsprj
2. TEST_R21_V6_RESISTORS_ONLY_BASELINE_E0_TAIL.pdsprj
3. TEST_R21_V6_TWO_TERMS_N0_A1_FIXED_LABELPATCH_E0_TAIL.pdsprj
4. TEST_R21_V6_TWO_TERMS_B6_M0_FIXED_LABELPATCH_E0_TAIL.pdsprj
5. TEST_R21_V6_ALL_TERMS_FIXED_LABELPATCH_KEEP_NO_WIRES_E0_TAIL.pdsprj
6. TEST_R21_V6_ALL_TERMS_FIXED_LABELPATCH_UNIQUE_NO_WIRES_E0_TAIL.pdsprj
7. TEST_R21_V6_ALL_TERMS_FIXED_LABELPATCH_KEEP_WITH_WIRES_E0_TAIL.pdsprj
8. TEST_R21_V6_ALL_TERMS_FIXED_LABELPATCH_UNIQUE_WITH_WIRES_E0_TAIL.pdsprj
```

## Interpretation

```text
B6 two-terminal test opens:
  the coordinate-collision bug is fixed.

ALL_TERMS no-wire opens:
  terminal count-scaling is now valid.

ALL_TERMS no-wire opens but wire version fails:
  terminal generation is solved enough; wire endpoint semantics are the next issue.

ALL_TERMS no-wire still fails:
  terminal record still has another count-scaling/identity field not handled yet.
```

## Code/method preservation

The generated local zip contains:

```text
generation_code_used.py
manifest.json
ROOT.CDB.bin and ROOT.DSN.bin debug dumps for every generated project
```

The full V6 generation code is also stored in:

```text
experiments/generation_code/r21_terminal_network_v6_fixed_terminal_label_patch.py
```

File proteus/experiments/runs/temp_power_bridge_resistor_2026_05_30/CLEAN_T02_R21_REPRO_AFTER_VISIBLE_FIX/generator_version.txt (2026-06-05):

proteusgen temporary resistor_v9 power-bridge method
base_fixture=e001_empty
donor_fixture=r21_v9_resistor_terminal_donor
power_bridge_donor=PROTEUS_AI_HANDOFF_ALL_LOCAL_ARTIFACTS_2026_05_30.zip:local_artifacts/New Project(1).pdsprj

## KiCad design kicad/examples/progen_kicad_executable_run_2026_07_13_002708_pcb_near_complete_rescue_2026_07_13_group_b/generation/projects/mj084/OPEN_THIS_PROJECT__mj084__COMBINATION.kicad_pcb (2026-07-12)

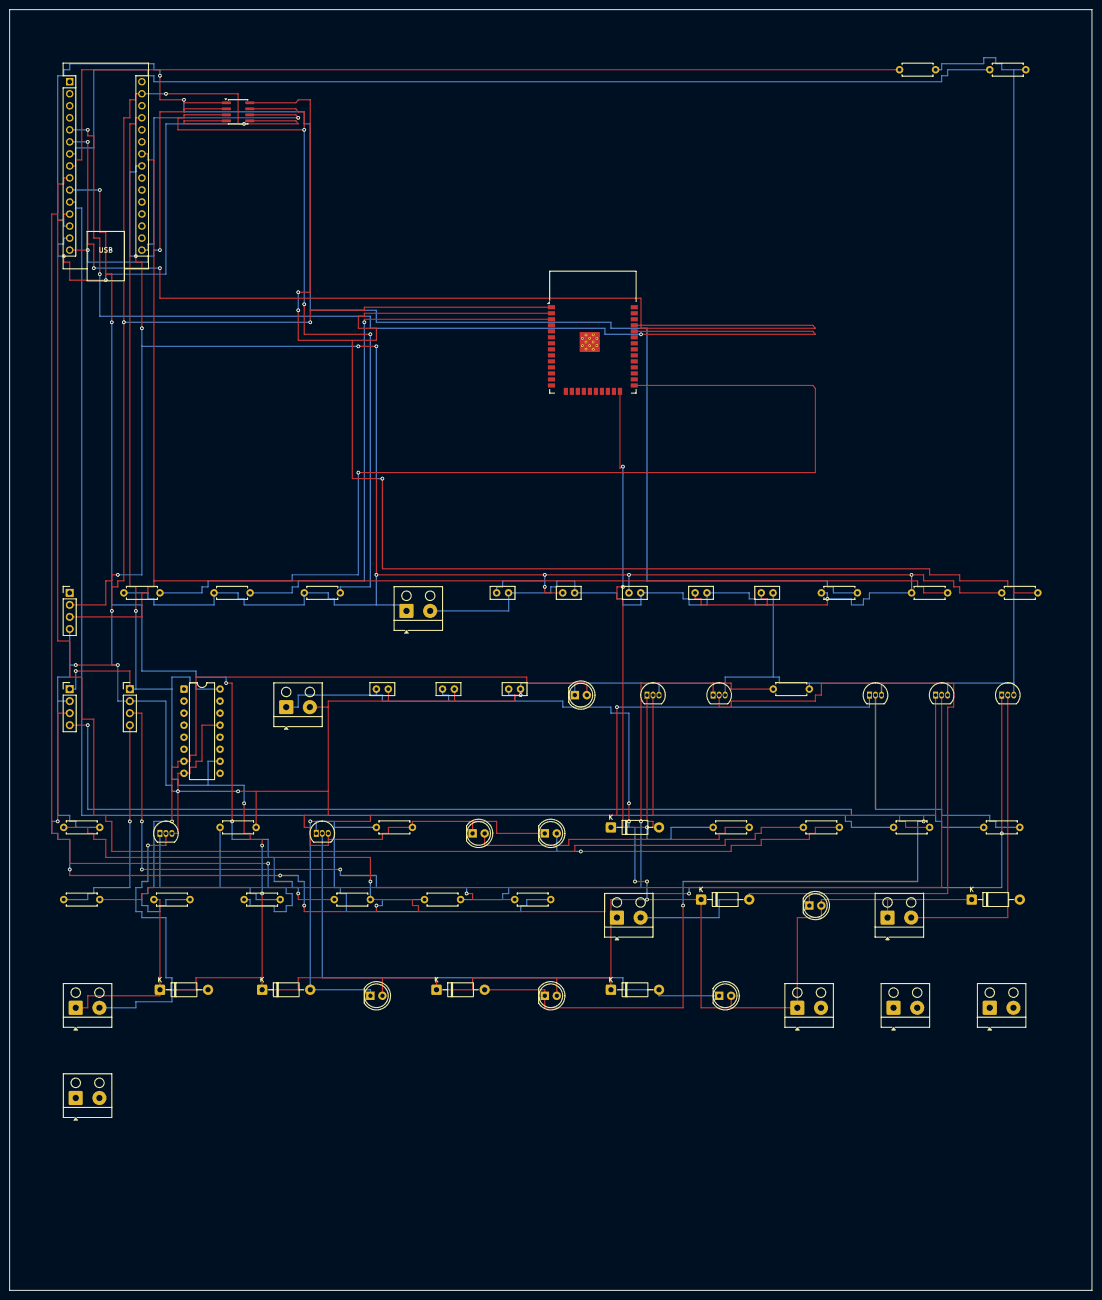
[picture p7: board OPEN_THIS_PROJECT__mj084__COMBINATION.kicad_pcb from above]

Board: 2 copper layers, 228.6 x 270.5 mm, 67 parts (0 on the bottom side), 42 nets.

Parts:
B1_D1, B1_D2, B2_D1, B2_D2, B2_D3: Flyback diode; D_DO-41_SOD81_P10.16mm_Horizontal
B1_D3, B1_D4: Relay flyback diode; D_DO-41_SOD81_P10.16mm_Horizontal
B1_D5, B1_D6, B1_D7, B1_D8: Indicator LED; LED_D5.0mm
B1_J1, B1_J2, B1_J3, B1_J4: Screw terminal 2-pin; Altech_AK100_1x02_P5.00mm
B1_J5, B1_J6: PWM/control header; PinHeader_1x04_P2.54mm_Vertical
B1_Q1, B1_Q2, B2_Q1, B2_Q2: IRLZ44N; TO-92_Inline
B1_Q3, B1_Q4, B2_Q3: BC547; TO-92_Inline
B1_R1, B1_R2, B1_R3, B1_R4, B1_R5, B1_R6: Driver resistor; R_Axial_DIN0207_L6.3mm_D2.5mm_P7.62mm_Horizontal
B2_C1, B2_C2, B2_C3, B2_C4, B2_C5, B2_C6, B2_C7, B2_C8: 100nF; C_Disc_D5.0mm_W2.5mm_P2.50mm
B2_D4, B2_D5: Status LED; LED_D5.0mm
B2_J_3V3: 3V3 header; Altech_AK100_1x02_P5.00mm
B2_J_I2C: I2C header; PinHeader_1x04_P2.54mm_Vertical
B2_J_LOAD1: Load 1; Altech_AK100_1x02_P5.00mm
B2_J_LOAD2: Load 2; Altech_AK100_1x02_P5.00mm
B2_J_POWER: Power header; Altech_AK100_1x02_P5.00mm
B2_J_RELAY: Relay contact; Altech_AK100_1x02_P5.00mm
B2_R1, B2_R2, B2_R3, B2_R4, B2_R5, B2_R6, B2_R7, B2_R8, B2_R9, B2_R10, B2_R11, B2_R12, B2_R13, B2_R14, B2_R15: Resistor; R_Axial_DIN0207_L6.3mm_D2.5mm_P7.62mm_Horizontal
B2_U1: Arduino Nano; Arduino_Nano
B2_U2: ESP32-WROOM; ESP32-WROOM-32
B2_U6: W25Q64; SOIC-8_3.9x4.9mm_P1.27mm
B3_LED1: Logic LED; LED_D5.0mm
B3_R1: 220 ohm; R_Axial_DIN0207_L6.3mm_D2.5mm_P7.62mm_Horizontal
B3_U595: 74HC595; DIP-16_W7.62mm

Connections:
+3V3: B2_C4.1, B2_C5.1, B2_C6.1, B2_C7.1, B2_C8.1, B2_J_3V3.1, B2_R1.1, B2_R2.1, B2_R3.1, B2_R4.1, B2_R5.1, B2_R6.1, B2_U2.2, B2_U6.8
B1_LOAD2_LOW: B1_D2.2, B1_D6.1, B1_J2.2, B1_Q2.2
B1_MOSFET1_GATE: B1_Q1.1, B1_R1.2, B1_R2.1
B1_MOSFET2_GATE: B1_Q2.1, B1_R3.2, B1_R4.1
B1_MOTOR_LOW: B1_D1.2, B1_D5.1, B1_Q1.2
B1_PWM_LOAD_2: B1_J6.3, B1_R3.1
B1_PWM_MOTOR_1: B1_J5.3, B1_R1.1
B1_RELAY1_BASE: B1_Q3.2, B1_R5.2
B1_RELAY1_COIL_LOW: B1_D3.2, B1_D7.1, B1_Q3.1
B1_RELAY1_CTRL: B1_J5.4, B1_R5.1
B1_RELAY2_BASE: B1_Q4.2, B1_R6.2
B1_RELAY2_COIL_LOW: B1_D4.2, B1_D8.1, B1_Q4.1
B1_RELAY2_CTRL: B1_J6.4, B1_R6.1
B2_ARDUINO_TO_ESP_RX: B2_U1.5, B2_U2.34
B2_ARDUINO_TO_ESP_TX: B2_U1.6, B2_U2.35
B2_BUTTON_1: B2_R7.1, B2_U1.7
B2_BUTTON_2: B2_R8.1, B2_U1.8
B2_ESP_BOOT: B2_R6.2, B2_U2.25
B2_ESP_EN: B2_R5.2, B2_U2.3
B2_FLASH_WP_HOLD: B2_R4.2, B2_U6.3, B2_U6.7
B2_I2C_SCL: B2_J_I2C.3, B2_R2.2, B2_U1.24
B2_I2C_SDA: B2_J_I2C.2, B2_R1.2, B2_U1.23
B2_LED_STATUS_1: B2_R14.1, B2_U1.12
B2_LED_STATUS_1_A: B2_D4.2, B2_R14.2
B2_LED_STATUS_2: B2_R15.1, B2_U2.24
B2_LED_STATUS_2_A: B2_D5.2, B2_R15.2
B2_MOSFET1_GATE: B2_R9.1, B2_U1.9
B2_MOSFET1_GATE_NODE: B2_Q1.1, B2_R9.2, B2_R10.1
B2_MOSFET1_LOAD_LOW: B2_D1.2, B2_J_LOAD1.2, B2_Q1.2
B2_MOSFET2_GATE: B2_R11.1, B2_U1.10
B2_MOSFET2_GATE_NODE: B2_Q2.1, B2_R11.2, B2_R12.1
B2_MOSFET2_LOAD_LOW: B2_D2.2, B2_J_LOAD2.2, B2_Q2.2
B2_RELAY_BASE: B2_Q3.2, B2_R13.2
B2_RELAY_COIL_LOW: B2_D3.2, B2_Q3.1
B2_RELAY_CTRL: B2_R13.1, B2_U1.11
B2_SPI_CS_FLASH: B2_R3.2, B2_U1.13, B2_U6.1
B2_SPI_MISO: B2_U1.15, B2_U6.2
B2_SPI_MOSI: B2_U1.14, B2_U6.5
B2_SPI_SCK: B2_U1.16, B2_U6.6
B3_LED_LOGIC_A: B3_LED1.2, B3_R1.2, B3_U595.7
GUESS_TERMINAL_5V: B1_D1.1, B1_D2.1, B1_D3.1, B1_D4.1, B1_D5.2, B1_D6.2, B1_D7.2, B1_D8.2, B1_J1.1, B1_J2.1, B1_J5.1, B1_J6.1, B2_C1.1, B2_C2.1, B2_C3.1, B2_D1.1, B2_D2.1, B2_D3.1, B2_J_LOAD1.1, B2_J_LOAD2.1, B2_J_POWER.1, B2_U1.27, B3_R1.1, B3_U595.10, B3_U595.16
GUESS_TERMINAL_GND: B1_J5.2, B1_J6.2, B1_Q1.3, B1_Q2.3, B1_Q3.3, B1_Q4.3, B1_R2.2, B1_R4.2, B2_C1.2, B2_C2.2, B2_C3.2, B2_C4.2, B2_C5.2, B2_C6.2, B2_C7.2, B2_C8.2, B2_D4.1, B2_D5.1, B2_J_3V3.2, B2_J_I2C.4, B2_J_POWER.2, B2_Q1.3, B2_Q2.3, B2_Q3.3, B2_R7.2, B2_R8.2, B2_R10.2, B2_R12.2, B2_U1.29, B2_U2.1, B2_U6.4, B3_LED1.1, B3_U595.8, B3_U595.13

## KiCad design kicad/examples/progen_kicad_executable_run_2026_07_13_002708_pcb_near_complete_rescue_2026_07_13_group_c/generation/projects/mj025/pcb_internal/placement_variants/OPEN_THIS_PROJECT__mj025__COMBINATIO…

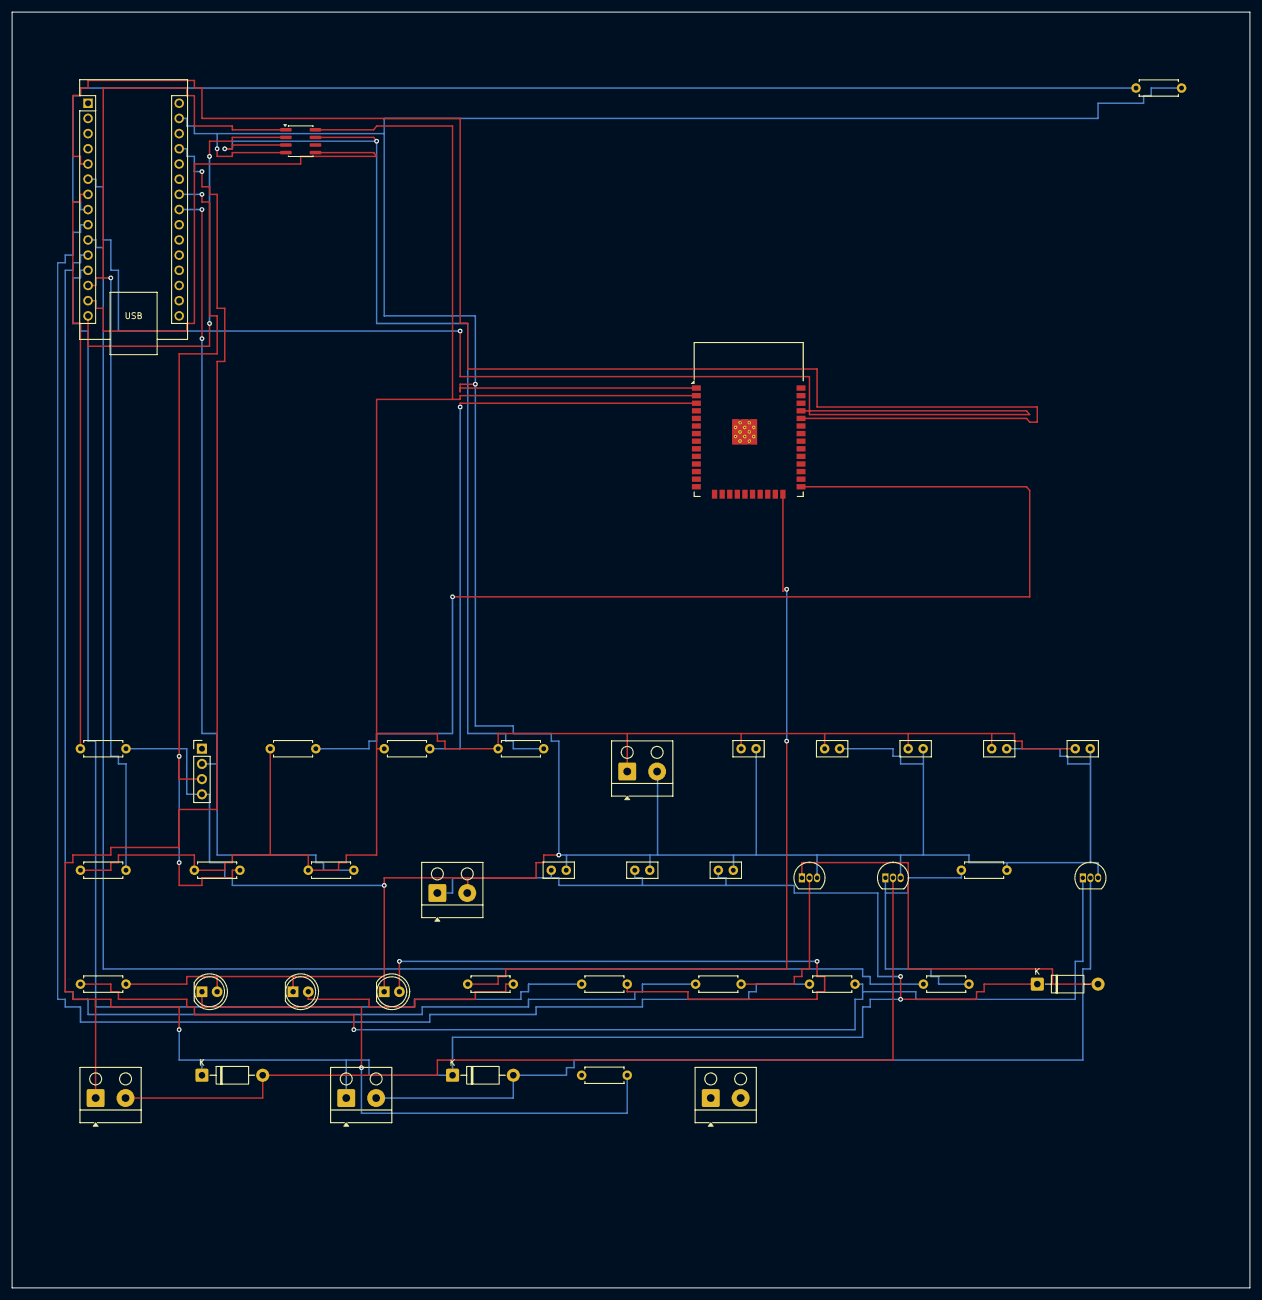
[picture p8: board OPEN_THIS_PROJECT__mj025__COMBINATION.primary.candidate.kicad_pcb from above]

Board: 2 copper layers, 207.0 x 213.4 mm, 42 parts (0 on the bottom side), 30 nets.

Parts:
B1_C1, B1_C2, B1_C3, B1_C4, B1_C5, B1_C6, B1_C7, B1_C8: 100nF; C_Disc_D5.0mm_W2.5mm_P2.50mm
B1_D1, B1_D2, B1_D3: Flyback diode; D_DO-41_SOD81_P10.16mm_Horizontal
B1_D4, B1_D5: Status LED; LED_D5.0mm
B1_J_3V3: 3V3 header; Altech_AK100_1x02_P5.00mm
B1_J_I2C: I2C header; PinHeader_1x04_P2.54mm_Vertical
B1_J_LOAD1: Load 1; Altech_AK100_1x02_P5.00mm
B1_J_LOAD2: Load 2; Altech_AK100_1x02_P5.00mm
B1_J_POWER: Power header; Altech_AK100_1x02_P5.00mm
B1_J_RELAY: Relay contact; Altech_AK100_1x02_P5.00mm
B1_Q1, B1_Q2: IRLZ44N; TO-92_Inline
B1_Q3: BC547; TO-92_Inline
B1_R1, B1_R2, B1_R3, B1_R4, B1_R5, B1_R6, B1_R7, B1_R8, B1_R9, B1_R10, B1_R11, B1_R12, B1_R13, B1_R14, B1_R15: Resistor; R_Axial_DIN0207_L6.3mm_D2.5mm_P7.62mm_Horizontal
B1_U1: Arduino Nano; Arduino_Nano
B1_U2: ESP32-WROOM; ESP32-WROOM-32
B1_U6: W25Q64; SOIC-8_3.9x4.9mm_P1.27mm
B2_LED1: Logic LED; LED_D5.0mm
B2_R1: 220 ohm; R_Axial_DIN0207_L6.3mm_D2.5mm_P7.62mm_Horizontal

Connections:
+3V3: B1_C4.1, B1_C5.1, B1_C6.1, B1_C7.1, B1_C8.1, B1_J_3V3.1, B1_R1.1, B1_R2.1, B1_R3.1, B1_R4.1, B1_R5.1, B1_R6.1, B1_U2.2, B1_U6.8
+5V: B1_C1.1, B1_C2.1, B1_C3.1, B1_D1.1, B1_D2.1, B1_D3.1, B1_J_LOAD1.1, B1_J_LOAD2.1, B1_J_POWER.1, B1_U1.27
B1_ARDUINO_TO_ESP_RX: B1_U1.5, B1_U2.34
B1_ARDUINO_TO_ESP_TX: B1_U1.6, B1_U2.35
B1_BUTTON_1: B1_R7.1, B1_U1.7
B1_BUTTON_2: B1_R8.1, B1_U1.8
B1_ESP_BOOT: B1_R6.2, B1_U2.25
B1_ESP_EN: B1_R5.2, B1_U2.3
B1_FLASH_WP_HOLD: B1_R4.2, B1_U6.3, B1_U6.7
B1_I2C_SCL: B1_J_I2C.3, B1_R2.2, B1_U1.24
B1_I2C_SDA: B1_J_I2C.2, B1_R1.2, B1_U1.23
B1_LED_STATUS_1: B1_R14.1, B1_U1.12
B1_LED_STATUS_1_A: B1_D4.2, B1_R14.2
B1_LED_STATUS_2: B1_R15.1, B1_U2.24
B1_LED_STATUS_2_A: B1_D5.2, B1_R15.2
B1_MOSFET1_GATE: B1_R9.1, B1_U1.9
B1_MOSFET1_GATE_NODE: B1_Q1.1, B1_R9.2, B1_R10.1
B1_MOSFET1_LOAD_LOW: B1_D1.2, B1_J_LOAD1.2, B1_Q1.2
B1_MOSFET2_GATE: B1_R11.1, B1_U1.10
B1_MOSFET2_GATE_NODE: B1_Q2.1, B1_R11.2, B1_R12.1
B1_MOSFET2_LOAD_LOW: B1_D2.2, B1_J_LOAD2.2, B1_Q2.2
B1_RELAY_BASE: B1_Q3.2, B1_R13.2
B1_RELAY_COIL_LOW: B1_D3.2, B1_Q3.1
B1_RELAY_CTRL: B1_R13.1, B1_U1.11
B1_SPI_CS_FLASH: B1_R3.2, B1_U1.13, B1_U6.1
B1_SPI_MISO: B1_U1.15, B1_U6.2
B1_SPI_MOSI: B1_U1.14, B1_U6.5
B1_SPI_SCK: B1_U1.16, B1_U6.6
B2_LED_A: B2_LED1.1, B2_R1.2
GND: B1_C1.2, B1_C2.2, B1_C3.2, B1_C4.2, B1_C5.2, B1_C6.2, B1_C7.2, B1_C8.2, B1_D4.1, B1_D5.1, B1_J_3V3.2, B1_J_I2C.4, B1_J_POWER.2, B1_Q1.3, B1_Q2.3, B1_Q3.3, B1_R7.2, B1_R8.2, B1_R10.2, B1_R12.2, B1_U1.29, B1_U2.1, B1_U6.4, B2_LED1.2

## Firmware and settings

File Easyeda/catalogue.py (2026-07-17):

"""Permanent, donor-only EasyEDA component catalogue.

This module deliberately contains selectors and logical facts only.  It never
contains copied EasyEDA symbol, device, footprint, or library payload data.
Those records stay in an authorized source pack and are copied at generation
time by :mod:`Easyeda.donor_source`.
"""

from __future__ import annotations

from dataclasses import dataclass
import re


CATALOGUE_VERSION = "progen-easyeda-donor-catalogue/v2"


@dataclass(frozen=True)
class DonorSelector:
    """Ordered exact source-title candidates for one logical component."""

    titles: tuple[str, ...]
    terminal: bool = False
    pcb_required: bool = True


@dataclass(frozen=True)
class CatalogueEntry:
    """A logical component only becomes usable after its donor resolves."""

    kind: str
    aliases: tuple[str, ...]
    reference_prefix: str
    selector: DonorSelector
    category: str
    value_rule: str
    default_value: str


def _entry(
    kind: str,
    aliases: tuple[str, ...],
    reference_prefix: str,
    *titles: str,
    category: str,
    terminal: bool = False,
    pcb_required: bool = True,
    value_rule: str = "display_text",
    default_value: str | None = None,
) -> CatalogueEntry:
    return CatalogueEntry(
        kind=kind,
        aliases=aliases,
        reference_prefix=reference_prefix,
        selector=DonorSelector(titles=titles, terminal=terminal, pcb_required=pcb_required),
        category=category,
        value_rule=value_rule,
        default_value=default_value or kind,
    )


# These are source selection keys, not visual definitions.  A selector may have
# more than one proven package alternative, but the resolved title and hashes
# are recorded per generated project and locked in the support report.
CATALOGUE: dict[str, CatalogueEntry] = {
    # Basic ten.
    "R": _entry(
        "R",
        ("RES", "RESISTOR", "R_220", "R_10K_PULLUP", "R_4K7_PULLUP", "R_120"),
        "R",
        "mfr-25jt-52-10k",
        category="basic",
        value_rule="positive_number",
        default_value="10k",
    ),
    "R_POT": _entry("R_POT", ("POT", "POTENTIOMETER", "TRIMMER"), "R", "3296w-1-103_c330432", "3296w-1-101lf", category="basic", value_rule="positive_number", default_value="10k"),
    "C": _entry(
        "C",
        ("CAP", "CAPACITOR", "C_100NF_CERAMIC", "DECOUPLING_CAPACITOR"),
        "C",
        "fn43n104j500egg",
        category="basic",
        value_rule="positive_number",
        default_value="100n",
    ),
    "CAP_ELEC": _entry(
        "CAP_ELEC",
        ("CP", "C_POL", "ELECTROLYTIC_CAPACITOR", "CP_100UF"),
        "C",
        "ca45a-b-6.3v-100uf-k",
        category="basic",
        value_rule="positive_number",
        default_value="100u",
    ),
    "L": _entry("L", ("IND", "INDUCTOR", "REALIND"), "L", "ckcs5040-47uh/m", category="basic", value_rule="positive_number", default_value="47u"),
    "DIODE": _entry("DIODE", ("D", "DIODE_GENERIC", "FLYBACK_DIODE", "TVS_DIODE"), "D", "d_1n4007", "1n4148tr", category="basic"),
    "1N4007": _entry("1N4007", ("D_1N4007", "1N4007_DIODE"), "D", "1n4007rlg", "1n4007w", "d_1n4007", category="basic"),
    "1N4148": _entry("1N4148", ("D_1N4148",), "D", "1n4148tr", "1n4148w-tp", "1n4148wt_c511874", category="basic"),
    "LED": _entry("LED", ("LED_GENERIC", "LED_INDICATOR", "POWER_LED"), "LED", "204-10sdrd/s530-a3-l", "led-th_bd4.2-p2.54-fd", category="basic"),
    "SPST_SWITCH": _entry(
        "SPST_SWITCH",
        ("SWITCH", "SPST", "SW", "PUSH_BUTTON"),
        "SW",
        "key_th_3.5x6x4.3",
        category="basic",
    ),
    # Lab and digital twenty.
    "NPN": _entry("NPN", ("2N3904", "Q_NPN"), "Q", "2n3904", "2n3904ta", category="lab_digital"),
    "PNP": _entry("PNP", ("2N3906", "Q_PNP"), "Q", "2n3906", category="lab_digital"),
    "NMOS": _entry("NMOS", ("2N7000", "MOSFET"), "Q", "2n7000", "2n7000_c232838", category="lab_digital"),
    "LM7805": _entry("LM7805", ("L7805", "7805"), "U", "lm7805s/tr", "lm7805l-ta3-t", category="lab_digital"),
    "LM317": _entry("LM317", (), "U", "lm317g-aa3-r", "lm317btg", category="lab_digital"),
    "BRIDGE_RECTIFIER": _entry("BRIDGE_RECTIFIER", ("BRIDGE",), "BR", "gbu406", category="lab_digital"),
    "TRANSFORMER": _entry("TRANSFORMER", ("XFMR",), "T", "hpt225a-g", "zmpt112", category="lab_digital"),
    "FUSE": _entry("FUSE", (), "F", "fuse-smd_5-20mm", "250v 20a 玻璃管保险丝", category="lab_digital"),
    "TERMINAL_BLOCK": _entry(
        "TERMINAL_BLOCK",
        ("TERMINAL", "SCREW_TERMINAL", "SCREW_TERMINAL_2"),
        "J",
        "wj2edgv-5.08-2p",
        category="lab_digital",
    ),
    "PIN_HEADER": _entry("PIN_HEADER", ("HEADER", "HEADER_CONNECTOR"), "J", "header-male-2.54_1x4", "2.54-1*2p母", category="lab_digital"),
    "GND": _entry("GND", ("GROUND",), "#PWR", "ground-gnd", category="lab_digital", terminal=True, pcb_required=False, value_rule="fixed_terminal", default_value="GND"),
    "VCC": _entry("VCC", ("+5V", "POWER", "POWER_VCC"), "#PWR", "power-vcc", category="lab_digital", terminal=True, pcb_required=False, value_rule="fixed_terminal", default_value="VCC"),
    "LM358": _entry("LM358", (), "U", "lm358adr", "lm358n_c434570", category="lab_digital"),
    "NE555": _entry("NE555", ("555",), "U", "ne555dr", "ne555l-d08-t", category="lab_digital"),
    "74HC00": _entry("74HC00", (), "U", "sn74hc00n", "74hc00d,653", category="lab_digital"),
    "74HC04": _entry("74HC04", (), "U", "sn74hc04n", "74hc04d,653", category="lab_digital"),
    "74HC08": _entry("74HC08", (), "U", "sn74hc08n", "74hc08d,653", category="lab_digital"),
    "74HC32": _entry("74HC32", (), "U", "74hc32d,653", category="lab_digital"),
    "74HC74": _entry("74HC74", (), "U", "sn74hc74n", "74hc74d,653", category="lab_digital"),
    "74HC595": _entry("74HC595", (), "U", "sn74hc595n", "74hc595pw,118", category="lab_digital"),
    # Embedded ten.
    "ESP32_WROOM": _entry("ESP32_WROOM", ("ESP32", "ESP32_WROOM_32"), "U", "esp32-wroom-32", category="embedded"),
    "ESP12F": _entry("ESP12F", ("ESP8266", "ESP_12F"), "U", "esp-12f(esp8266mod)", category="embedded"),
    "ATMEGA328P": _entry("ATMEGA328P", ("ATMEGA328",), "U", "atmega328p-au", "atmega328p-pu", category="embedded"),
    "STM32F103C8T6": _entry("STM32F103C8T6", ("STM32F103",), "U", "stm32f103c8t6", category="embedded"),
    "CP2102": _entry("CP2102", (), "U", "cp2102-gmr", category="embedded"),
    "CH340": _entry("CH340", (), "U", "ch340e", "ch340t", category="embedded"),
    "BME280": _entry("BME280", (), "U", "bme280", category="embedded"),
    "DS3231": _entry("DS3231", (), "U", "ds3231sn#t&r", "ds3231mz+trl", category="embedded"),
    "W25Q64": _entry("W25Q64", (), "U", "w25q64jvzeiq", "w25q64fwssiq", category="embedded"),
    "SSD1306": _entry("SSD1306", ("OLED", "OLED_SSD1306"), "DS", "0.96oled模块_4p", "0.96oled_4p", category="embedded"),
    # Audited physical expansion. Selectors are exact source-device titles;
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

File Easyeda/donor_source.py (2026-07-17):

"""Read-only access to an authorized EasyEDA Pro donor source pack.

No native payload is stored in this module.  The caller supplies an EasyEDA
desktop ZIP or an extracted source directory.  We materialize it in a private
cache, extract exact SQLite rows, and retain their hashes as generation
evidence.
"""

from __future__ import annotations

from contextlib import closing
from dataclasses import dataclass
import hashlib
from importlib import resources as importlib_resources
import json
from pathlib import Path
import shutil
import sqlite3
import tempfile
from typing import Any, Iterator
import zipfile

from .catalogue import CatalogueEntry, DonorSelector


SOURCE_SCHEMA = "progen-easyeda-donor-source/v1"
BUNDLED_SOURCE_FILES = (
    "easyeda-std.elib",
    "blank_template.eprj",
    "manifest.json",
)


class DonorSourceError(ValueError):
    """The supplied source pack cannot prove a requested native packet."""


def bundled_source_pack() -> Path:
    """Return a filesystem directory containing the locked runtime donor set."""

    direct = Path(__file__).resolve().parent / "donors" / "locked_catalogue_v2"
    if all((direct / name).is_file() for name in BUNDLED_SOURCE_FILES):
        return direct
    root = Path(tempfile.gettempdir()) / "progen_easyeda_locked_catalogue_v2"
    root.mkdir(parents=True, exist_ok=True)
    traversable = importlib_resources.files("Easyeda").joinpath(
        "donors",
        "locked_catalogue_v2",
    )
    for name in BUNDLED_SOURCE_FILES:
        destination = root / name
        data = traversable.joinpath(name).read_bytes()
        if not destination.is_file() or destination.read_bytes() != data:
            destination.write_bytes(data)
    return root


@dataclass(frozen=True)
class SourcePaths:
    source_pack: Path
    source_sha256: str
    library_path: Path
    supplemental_library_paths: tuple[Path, ...]
    template_path: Path
    source_version: str | None


@dataclass(frozen=True)
class PinDescriptor:
    number: str
    name: str
    pin_type: str
    x: float
    y: float


@dataclass(frozen=True)
class FootprintPadDescriptor:
    number: str
    identifier: str
    x: float
    y: float
    layer: int
    rotation: float
    shape: object
    hole: object
    through_hole: bool


@dataclass(frozen=True)
class DonorPacket:
    """Exact source rows plus parsed geometry needed by downstream stages."""

    kind: str
    resolved_title: str
    device: dict[str, Any]
    attributes: tuple[dict[str, Any], ...]
    symbol: dict[str, Any]
    footprint: dict[str, Any] | None
    resources: tuple[dict[str, Any], ...]
    pins: tuple[PinDescriptor, ...]
    body_bbox: tuple[float, float, float, float]
    part_name: str
    reference_prefix: str
    footprint_pads: dict[str, tuple[float, float]]
    footprint_pad_ids: dict[str, str]
    footprint_pad_details: dict[str, FootprintPadDescriptor]
    footprint_bbox: tuple[float, float, float, float] | None
    source_hashes: dict[str, str]

    @property
    def pcb_ready(self) -> bool:
        if self.footprint is None:
            return False
        if not self.pins:
            return True
        return all(pin.number in self.footprint_pads for pin in self.pins)


def sha256_file(path: Path) -> str:
    digest = hashlib.sha256()
    with path.open("rb") as handle:
        for chunk in iter(lambda: handle.read(1024 * 1024), b""):
            digest.update(chunk)
    return digest.hexdigest()


def _row_dict(cursor: sqlite3.Cursor, row: sqlite3.Row | tuple[Any, ...]) -> dict[str, Any]:
    return {description[0]: row[index] for index, description in enumerate(cursor.description or [])}


def _stable_json_hash(value: object) -> str:
    return hashlib.sha256(json.dumps(value, ensure_ascii=False, sort_keys=True, separators=(",", ":")).encode("utf-8")).hexdigest()


def _read_json_records(text: str) -> list[list[Any]]:
    records: list[list[Any]] = []
    for line in text.splitlines():
        if not line.strip():
            continue
        parsed = json.loads(line)
        if isinstance(parsed, list) and parsed:
            records.append(parsed)
    return records


def _symbol_geometry(data: str) -> tuple[tuple[PinDescriptor, ...], tuple[float, float, float, float], str, str]:
    records = _read_json_records(data)
    pin_rows: dict[str, list[Any]] = {}
    attributes: dict[str, dict[str, str]] = {}
    part_name = ""
    bbox: tuple[float, float, float, float] | None = None
    reference_prefix = "U"
    for row in records:
        if row[0] == "PART" and len(row) >= 3:
            part_name = str(row[1] or "")
            details = row[2] if isinstance(row[2], dict) else {}
            raw_bbox = details.get("BBOX")
            if isinstance(raw_bbox, list) and len(raw_bbox) == 4:
                bbox = tuple(float(value) for value in raw_bbox)
        elif row[0] == "PIN" and len(row) >= 8:
            pin_rows[str(row[1])] = row
        elif row[0] == "ATTR" and len(row) >= 5:
            parent = str(row[2] or "")
            key = str(row[3] or "")
            value = str(row[4] or "")
            attributes.setdefault(parent, {})[key] = value
            if parent == "" and key == "Designator" and value:
                reference_prefix = "".join(character for character in value if character.isalpha()) or reference_prefix
    pins: list[PinDescriptor] = []
    for identifier, row in pin_rows.items():
        pin_attrs = attributes.get(identifier, {})
        number = pin_attrs.get("NUMBER", identifier)
        name = pin_attrs.get("NAME", number)
        pin_type = pin_attrs.get("Pin Type", "")
        pins.append(PinDescriptor(number=str(number), name=str(name), pin_type=str(pin_type), x=float(row[4]), y=float(row[5])))
    if bbox is None:
        if pins:
            xs = [pin.x for pin in pins]
            ys = [pin.y for pin in pins]
            bbox = (min(xs) - 10, min(ys) - 10, max(xs) + 10, max(ys) + 10)
        else:
            bbox = (-10.0, -10.0, 10.0, 10.0)
    return tuple(pins), bbox, part_name, reference_prefix


def _shape_extents(value: object) -> tuple[float, float]:
    if not isinstance(value, list):
        return 0.0, 0.0
    numbers = [abs(float(item)) for item in value[1:] if isinstance(item, (int, float))]
    if not numbers:
        return 0.0, 0.0
    return numbers[0] / 2.0, (numbers[1] if len(numbers) > 1 else numbers[0]) / 2.0
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

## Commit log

2026-05-30 Record cap3 capacitor diagnostics
2026-05-30 Record capacitor V6 terminal diagnostics
2026-05-30 Record capacitor V7 terminal isolation
2026-05-30 Record capacitor V8 terminal ordering diagnostics
2026-05-30 Record capacitor V9 unique index diagnostics
2026-05-30 Record capacitor V10 manual donor diagnostics
2026-05-30 Record capacitor V11 network diagnostics
2026-05-31 Record capacitor V12 requested network tests
2026-05-31 Record capacitor V13 power ground spacing tests
2026-05-31 Record mixed resistor capacitor V1 tests
2026-05-31 Record inductor V3 acceptance and add V4 power tests
2026-06-01 Add requested inductor power-ground pack
2026-06-01 Add mixed RCL V4 resistor-boundary pack
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2026-06-02 Add mixed RCL V16 wire offset fix
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2026-06-05 Add fixed V3-order DCV2 passive probes
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2026-06-05 Add source passive V9 fixed wire probes
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2026-06-06 Refocus PSpice track on visual OrCAD project generation
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2026-06-08 Restore legacy ground for compact T29 IC test
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2026-06-09 Probe full skeleton CDB replacement
2026-06-10 Add focused IC pairwise error sample
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2026-06-11 Import manual Proteus donor projects
    [import_manifest.csv, squence_import_manifest.csv]
2026-06-11 Add KiCad generator workspace and source scan targets
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2026-06-11 Fix KiCad wire generation and clearer output names
2026-06-11 Add KiCad project symbol fixer and downloader
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2026-06-11 Record KiCad V2 missing symbols and autolib fix
2026-06-11 Record KiCad V3 missing symbols and V4 embedded-symbol fix
2026-06-11 Record KiCad V4 parse failure and manual donor request
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2026-06-11 Add KiCad source parser writer deep dive report
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2026-06-11 Update KiCad generator README for V7 component catalog
2026-06-11 Add KiCad V8 true 50 component zoo generator
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2026-06-28 Fix value mutation and expand terminal probes
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2026-07-01 Fix mixed terminal short-wire records
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2026-07-01 Add immutable KiCad placer stress runs
    [C04_mosfet_motor_driver.json, OPEN_THIS_PROJECT__c01_arduino_led_blink__PLACER.kicad_sch, OPEN_THIS_PROJECT__c02_5v_power_supply__PLACER.kicad_sch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]
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2026-07-02 Add KiCad wire maker
    [OPEN_THIS_PROJECT__t01__PLACER.kicad_sch, OPEN_THIS_PROJECT__t01__WIRED.kicad_sch, OPEN_THIS_PROJECT__t02__PLACER.kicad_sch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]
2026-07-02 Add strict wire geometry validation
    [OPEN_THIS_PROJECT__t01__WIRED.kicad_sch, OPEN_THIS_PROJECT__t02__WIRED.kicad_sch, OPEN_THIS_PROJECT__t03__WIRED.kicad_sch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]
2026-07-02 Snap Proteus terminals to schematic grid
2026-07-02 Tighten KiCad wire planner geometry
    [OPEN_THIS_PROJECT__t01__WIRED.kicad_sch, OPEN_THIS_PROJECT__t02__WIRED.kicad_sch, OPEN_THIS_PROJECT__t03__WIRED.kicad_sch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]
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2026-07-02 Add Proteus-style KiCad aliases
    [OPEN_THIS_PROJECT__proteus_style_component_kind_smoke__PLACER.kicad_sch]
2026-07-02 Add mixed KiCad wiring geometry suite
    [OPEN_THIS_PROJECT__m01__WIRED.kicad_sch, OPEN_THIS_PROJECT__m02__WIRED.kicad_sch, OPEN_THIS_PROJECT__m03__WIRED.kicad_sch]
2026-07-02 Improve KiCad routed placement validation
    [OPEN_THIS_PROJECT__r01__WIRED.kicad_sch, OPEN_THIS_PROJECT__r02__WIRED.kicad_sch, OPEN_THIS_PROJECT__r03__WIRED.kicad_sch]
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2026-07-03 Fix exact KiCad strict wire routing
    [OPEN_THIS_PROJECT__t10__WIRED.kicad_sch]
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2026-07-03 Fix catalogue terminal coordinate frame
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2026-07-03 Fix multi-pin marker anchor placement
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2026-07-04 Fix multi-pin subpart terminal anchors
2026-07-04 Add hosted KiCad netlist validator
    [OPEN_THIS_PROJECT__t10__WIRED.kicad_sch]
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2026-07-05 Add node spec KiCad generation pack
    [N02_arduino_nano_can_bus_motor_relay_current_sensor_controller.json, N02_arduino_nano_can_bus_motor_relay_current_sensor_controller_placement_input.json, N02_a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]
2026-07-05 Fix KiCad wire planner unrouted nets
    [N02_arduino_nano_can_bus_motor_relay_current_sensor_controller.json, N02_arduino_nano_can_bus_motor_relay_current_sensor_controller_placement_input.json, N02_a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]
2026-07-05 Add terminal-only KiCad netlist pass
    [N02_arduino_nano_can_bus_motor_relay_current_sensor_controller.json, N02_arduino_nano_can_bus_motor_relay_current_sensor_controller_placement_input.json, N02_a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]
2026-07-05 Lock KiCad main JSON catalog
    [OPEN_THIS_PROJECT__mj001__COMBINATION.kicad_sch, OPEN_THIS_PROJECT__mj001__TERMINAL.kicad_sch, OPEN_THIS_PROJECT__mj002__COMBINATION.kicad_sch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]
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2026-07-09 Add mixed two pin LM OP terminal pack
2026-07-09 Fix mixed LM OP wire boundary
2026-07-10 Add KiCad executable input fixer and variation runs
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2026-07-10 Finalize KiCad schematic records and terminal spacing
    [OPEN_THIS_PROJECT__t01__WIRED.kicad_sch]
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2026-07-10 Harden KiCad input JSON fixer
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2026-07-11 Add source-backed KiCad PCB pipeline
    [OPEN_THIS_PROJECT__mj001__COMBINATION-B_Cu.gbl, OPEN_THIS_PROJECT__mj001__COMBINATION-B_Mask.gbs, OPEN_THIS_PROJECT__mj001__COMBINATION-B_Silkscreen.gbo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]
2026-07-12 Harden KiCad schematic terminal layout
    [OPEN_THIS_PROJECT__mj003__TERMINAL.kicad_sch, OPEN_THIS_PROJECT__mj004__TERMINAL.kicad_sch, OPEN_THIS_PROJECT__mj008__TERMINAL.kicad_sch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]
2026-07-12 Freeze accepted diode route and add manual donor
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2026-07-12 Harden KiCad PCB release evidence
    [OPEN_THIS_PROJECT__mj003__COMBINATION.kicad_sch, OPEN_THIS_PROJECT__mj003__COMBINATION.primary.candidate.kicad_pcb, OPEN_THIS_PROJECT__mj004__COMBINATION.kicad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]
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2026-07-12 Ship KiCad PCB portable release
    [portable_smoke.kicad_pcb]
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2026-07-13 Add 4027 grid short-wire route
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2026-07-15 Add Altium and PSpice donor fixtures
    [Charging_and_Discharging_Capacitors.SchDoc, RC_CIRCUIT.DSN]
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2026-07-15 Build LTspice common circuit corpus and native validation
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2026-07-16 Reorganize Proteus runtime and evidence
    [extraction_manifest.csv, import_manifest.csv, squence_import_manifest.csv]
2026-07-16 Document and inventory Proteus consolidation
    [02_cdbcore_function_inventory_key.csv, ignored_local_items.csv]
2026-07-16 Rebase relocated Proteus runners and validate
    [ignored_local_items.csv]
2026-07-17 Add verified Proteus 200-circuit corpus
    [circuit_026_capacitor_reservoir_filter.json]
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2026-07-17 Harden EasyEDA native generation and wire readability
    [q19_pwm_servo_module_automation_v08.json, q19_pwm_servo_module_compact_v04.json, q19_pwm_servo_module_development_v09.json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]
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2026-07-17 Add semantic terminal labels to Proteus route
    [circuit_026_capacitor_reservoir_filter.json]
2026-07-17 Add KiCad 400-circuit qualification
    [kq04_motor_relay_driver_automation_v08.json, kq04_motor_relay_driver_compact_v04.json, kq04_motor_relay_driver_development_v09.json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]
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2026-07-22 Add direct Altium schematic generator
    [logic_trainer_ascii_seed.SchDoc]
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2026-07-22 Harden direct Altium pipeline
    [nodemcu_project_seed.PrjPcb]
